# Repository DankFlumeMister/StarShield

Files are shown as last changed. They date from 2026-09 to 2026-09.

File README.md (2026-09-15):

# StarShield



**一个开源、全自定义、面向新手教程的无线机械键盘。**

目标是一把 **95 键紧凑全尺寸**单体键盘：键盘本体经 **BLE** 连接一个 USB Dongle，
Dongle 插在主机上，从而获得接近 2.4GHz 的无线体验。硬件设计、固件与教程全部开放。

> ⚠️ **项目仍在设计阶段，尚无硬件实物。** 本 README 如实标注每一项的完成度，
> 未验证的内容不会写成已完成。

---

## 目标

- **95 键紧凑全尺寸**单体键盘（含独立小键盘与导航键簇）
- **无线优先**：Body（键盘本体）作为 BLE peripheral，Dongle 作为 BLE central
- **USB-C 有线备用**：充电 + 有线模式
- **ZMK Studio** 浏览器实时改键
- **Per-key RGB**：95 颗独立发光，组合键控制开关/亮度/颜色/灯效
- **硬件开源**，新手可复刻
- 控制器模块同时兼容 **nice!nano v2** 与 **SuperMini nRF52840**（低成本路线）

## 系统架构

```text
┌─────────────────────────────┐        ┌──────────────────┐      ┌────────┐
│        键盘 Body             │        │      Dongle      │      │  主机   │
│                             │        │                  │      │        │
│  nice!nano v2 (peripheral)  │──BLE──▶│ XIAO nRF52840    │─USB─▶│  PC    │
│   ├─ 95 键矩阵 6 行 × 18 列   │        │   (central)      │      │        │
│   │    ├─ 6 行直连 MCU       │        └──────────────────┘      └────────┘
│   │    └─ 18 列由 2×74HC595  │
│   ├─ BQ24072 充电 + 电源路径管理 │
│   ├─ 3000mAh LiPo（无断电开关）  │
│   └─ 95 颗 SK6812MINI-E + 门控   │
└─────────────────────────────┘
```

**关键技术选择**（完整理由见 `docs/adr/`）：

| 主题 | 选择 |
| --- | --- |
| 固件 | ZMK（基于 Zephyr RTOS） |
| 无线方案 | BLE Dongle（**非**原生 2.4GHz，见 [ADR-0001](docs/adr/0001-zmk-ble-dongle-over-native-2.4ghz.md)） |
| 矩阵驱动 | **2 颗 74HC595 级联**驱动 18 列（见 [ADR-0008](docs/adr/0008-matrix-via-74hc595-shift-register.md)） |
| 充电 | BQ24072，线性充电 + 电源路径管理，做在主 PCB |
| RGB 供电 | **电池直供**，不加 5V 升压（见 [ADR-0007](docs/adr/0007-rgb-powered-directly-from-battery.md)） |
| 许可 | CERN-OHL-S-2.0 |

---

## 当前状态

| 模块 | 状态 | 说明 |
| --- | --- | --- |
| 产品与硬件设计决策 | ✅ 已完成 | 11 条 ADR + 完整决策日志 |
| 键位几何 | ✅ 已核验 | 95 键、19.50u × 6.25u（371.5 × 119.1 mm） |
| 95 键矩阵分配 | ✅ 已完成 | 6 行 × 18 列，18 列达数学下界 |
| PCB 原理图（矩阵部分） | ✅ 已完成 | **网表校验 10 项全通过、ERC 0 error** |
| PCB 原理图（电源/RGB/控制板） | 🔴 未完成 | 拓扑与元件取值已定，待画图 |
| 固件配置 | 🟡 已写出 | shield 全套 + 95 键映射，**静态校验通过** |
| 固件编译验证 | ✅ **已通过** | GitHub Actions 用 ZMK v0.3.0 实跑 `west build`，产出可烧录的 `.uf2` |
| PCB 布局 / 外壳 / BOM / 教程 | 🔴 未开始 | |

### 已产出的设计文档

| 文档 | 内容 |
| --- | --- |
| [`docs/decisions.md`](docs/decisions.md) | 完整决策日志 |
| [`docs/adr/`](docs/adr/) | 架构决策记录 0001–0011 |
| [`docs/hardware-geometry.md`](docs/hardware-geometry.md) | 键位几何基准（含一次错误测量的教训） |
| [`docs/matrix-assignment.md`](docs/matrix-assignment.md) | 95 键矩阵行列分配 + 网表校验 |
| [`docs/matrix-folding-analysis.md`](docs/matrix-folding-analysis.md) | 为什么必须用移位寄存器（含引脚预算推导） |
| [`docs/zmk-kscan-alternatives.md`](docs/zmk-kscan-alternatives.md) | ZMK 全部 6 个 keyscan 驱动排查 |
| [`docs/power-architecture.md`](docs/power-architecture.md) | 电源树、电流预算、选型 |
| [`docs/bq24072-pinout.md`](docs/bq24072-pinout.md) | 充电 IC 引脚与元件取值 |
| [`docs/controller-and-battery-facts.md`](docs/controller-and-battery-facts.md) | 控制器/电池/JST 已核实事实 |
| [`firmware/README.md`](firmware/README.md) | 固件引脚分配权威表 + 踩坑记录 |

---

## 仓库结构

```text
.
├── docs/                     设计文档、决策记录、生成/校验脚本
│   ├── adr/                  架构决策记录 0001–0011
│   ├── _tools/               可复现的生成与校验脚本
│   └── _generated/           脚本产物
├── firmware/                 ZMK 固件配置
│   ├── build.yaml            构建矩阵
│   └── boards/shields/starshield/
├── hardware/
│   ├── pcb/
│   │   ├── StarShield/       KiCad 工程（95 键矩阵原理图）
│   │   └── TEST1/            练习工程
│   └── case/                 3D 打印外壳（待开始）
├── research/                 调研报告（结论性，逐条带来源）
├── sketch/                   键盘布局图（KLE 格式，几何唯一权威）
└── tutorials/                新手教程（待开始）
```

---

## 自己跑一遍

本项目全部设计产物由脚本生成，且**可复现**（重跑不会产生差异）。

```bash
# 需要：Node.js、Python 3、KiCad（命令行工具 kicad-cli）
node docs/_tools/matrix-assign.mjs      # 矩阵分配
node docs/_tools/gen_transform.mjs      # 键盘映射表 + 物理布局
node docs/_tools/gen_keymap.mjs         # 键位映射
python docs/_tools/gen_matrix_sch.py    # 生成 KiCad 原理图

# 校验
python docs/_tools/verify_netlist.py    # 网表电气校验（10 项）
python docs/_tools/verify_firmware.py   # 固件静态校验
```

> 若 `kicad-cli` 不在 PATH 上，可用环境变量指定：
> `export KICAD_CLI=/path/to/kicad-cli`

KiCad 工程：用 KiCad 打开 `hardware/pcb/StarShield/Starshield.kicad_pro`。

### 构建固件

固件由 CI 自动构建（ZMK 版本钉在 `firmware/west.yml` 的 `v0.3.0`，上游变更新不会悄悄破坏构建）。
**已实测通过**，产物为两个可烧录的 UF2：

| 文件 | 用途 |
| --- | --- |
| `starshield-body.uf2` | 键盘本体固件 |
| `starshield-settings-reset.uf2` | 清空设置（刷完再刷本体固件，用于恢复出厂状态） |

获取方式：进入 [Actions](https://github.com/DankFlumeMister/StarShield/actions/workflows/build.yml)
→ 选最新一次成功的 run → 页面底部 **Artifacts** → 下载 `starshield-firmware`。

> ⚠️ 这些 UF2 **尚未在真实硬件上烧录验证过** —— 能编译不等于能用。
> 等 PCB 打样后会补上实测记录。

自己触发一次构建：Actions 页面 → **Run workflow**（工作流带 `workflow_dispatch`）。

---

## 已知限制（重要，请勿误读完成度）

- **没有任何硬件实物。** 所有结论均基于设计推导、厂商 datasheet 与仿真级校验。
- **固件已能编译出 `.uf2`，但从未烧进真板子跑过。** 编译通过只说明配置自洽，
  不代表按键定义、RGB 时序、电源门控在实物上正确 —— 这些都必须等 PCB 打样后实测。
- **原理图只画了矩阵部分**，电源与 RGB 子图尚未绘制。
- **引脚分配的机械尺寸未用实物核对。** nice!nano 排针的 pitch 与每边引脚数
  来自 ZMK 官方设备树定义与 Pro Micro 标准旁证，**投板前必须用实物卡尺复核**。
- 外壳必须分件打印：键区宽 **371.5 mm**，超过常见 256 mm 打印床。
- 以下三项**已有推荐方案但尚未确认**（详见 [ADR-0009](docs/adr/0009-three-position-mode-switch.md)、[ADR-0010](docs/adr/0010-battery-cutoff-strategy.md)）：
  - **连接模式开关**：三档拨片（2.4G / 蓝牙 / 有线），单刀 `SP3T`。
    方案用 ZMK 上游原生机制（`toggle-mode` + sideband behaviors），**键盘侧零自定义固件**；
    但 Dongle 必须是「BLE HID 主机」形态，**其固件不是 ZMK，是一块独立的开发量**。
  - **不设电池断电开关**：电池始终接通，「关机」= 拨到有线档 + 拔掉 USB 线，
    再由 ZMK 深睡接手；长期存放拔电池插头。
    这是跟随成熟三模产品（Keychron 等）的做法，也回避了「小开关要扛 2.4 A」的难题。
  - **RGB 门控关断拓扑**：电池满电时 3.3 V GPIO 无法保证关断源极在 4.2 V 轨的高边 PMOS，
    需加一级 NMOS 反相（`GPIO_ACTIVE_HIGH`）。⚠️ 该失效的量级未经实测，标记为未核实。

---

## 参与

项目仍在早期。如果你对以下方向感兴趣，欢迎开 issue 讨论：

- 95 键布局的定位板/外壳设计
- 电源子图（BQ24072 充电 + 电源路径）复核
- 实物打样后的固件实测（矩阵扫描、RGB、电源门控、休眠电流）

## 许可证

本项目采用 **CERN-OHL-S-2.0**（强互惠开源硬件许可证），全文见 [LICENSE](LICENSE)。

任何人可商业使用、修改和分发本设计，但**衍生产品必须同样以 CERN-OHL-S-2.0 开源，
并公开完整设计文件**。

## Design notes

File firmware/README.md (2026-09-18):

# StarShield 固件配置（ZMK）

状态：🟡 **设计稿 + 静态校验通过**（⚠️ **尚未实跑 `west build`** —— 本机缺 Zephyr SDK）

目标板：**nice!nano v2**
⚠️ **ZMK board id 随分支不同**（已核实）：
- `v0.3` release 分支 → **`nice_nano_v2`**（本仓库当前采用）
- `main` 分支 → **`nice_nano//zmk`**（main 上**没有** `nice_nano_v2`）

---

## 1. 目录结构

```text
firmware/
├── build.yaml                          构建矩阵
├── README.md                           本文件
└── boards/shields/starshield/
    ├── starshield.zmk.yml              shield 元数据（供 ZMK 识别）
    ├── Kconfig.shield                  SHIELD_STARSHIELD 注册
    ├── Kconfig.defconfig               键盘名等默认项
    ├── starshield.overlay              kscan / 595 / WS2812 / ext-power
    ├── starshield_transform.dtsi       ← 生成：物理布局 + 95 键映射表
    ├── starshield.keymap               ← 生成：Base / FN 两层，各 95 条绑定
    └── starshield.conf                 Kconfig
.github/workflows/build.yml             构建工作流（读取 firmware/build.yaml）
```

重新生成（幂等，重跑后 git 无差异）：

```powershell
cd <仓库根目录>
$env:PYTHONIOENCODING='utf-8'
node docs\_tools\matrix-assign.mjs     # 矩阵分配 -> docs/_generated/matrix.json
node docs\_tools\gen_transform.mjs     # -> starshield_transform.dtsi（物理布局 + 映射表）
node docs\_tools\gen_keymap.mjs        # -> starshield.keymap
python docs\_tools\verify_firmware.py  # 静态校验（本机可跑，替代实机构建）
```

---

## 2. 引脚分配（权威表）

依据：`docs/adr/0008-matrix-via-74hc595-shift-register.md`。
来源：ZMK 官方 `arduino_pro_micro_pins.dtsi` 与 `nice_nano-pinctrl.dtsi`。

| 用途 | Pro Micro 脚 | GPIO | 备注 |
| --- | --- | --- | --- |
| 矩阵行 R0 | D4/A6 | P0.22 | 直连 MCU（官方要求输入直连） |
| 矩阵行 R1 | D5 | P0.24 | |
| 矩阵行 R2 | D6/A7 | P1.00 | |
| 矩阵行 R3 | D7 | P0.11 | |
| 矩阵行 R4 | D9/A9 | P1.06 | |
| 矩阵行 R5 | D8/A8 | P1.04 | |
| 595 MOSI | D16 | P0.10 | `&spi1` |
| 595 SCK | D15 | P1.13 | `&spi1` |
| 595 片选（RCLK） | D19/A1 | P0.02 | `cs-gpios` |
| WS2812 数据 | D1 | P0.06 | `&spi3` MOSI |
| RGB 电源门控 | D10/A10 | P0.09 | `EXT_POWER` → NMOS 反相级 |
| 模式开关档 0（有线） | **D2** | **P0.17** | C1：`kscan_sp3t_toggle` MODE0（ADR-0009） |
| 模式开关档 1（蓝牙） | **D14** | **P1.11** | C1：MODE1 ⚠️ 已把 `&spi1` 的 MISO 覆盖掉（板级默认占 P1.11，595 只写不需要） |
| 模式开关档 2（2.4G） | **D18/A0** | **P1.15** | C1：MODE2 |
| **合计占用** | **14 / 18** | | **余量 4** |

**空闲引脚**：D0 (P0.8)、D3 (P0.20)、D20/A2 (P0.29)、D21/A3 (P0.31)

⚠️ 注意事项：
- **P0.13 是 nice!nano 的 VCC 门控脚**，本设计未占用（改用 P0.09 驱动外部门控电路）
- **P0.15 是蓝灯**，不要占用
- **595 与 WS2812 必须用不同的 SPI 外设**（两者都是 SPI 从设备）
- 原厂 UART 在 P0.08 / P0.06 —— **P0.06 已被 WS2812 占用**，故不启用串口日志
- 🔴 **`&spi1` 的 pinctrl 在本 shield 覆盖掉了 MISO**：nice!nano 板级 `spi1_default` 含
  `SPIM_MISO = P1.11`，而 C1 把 D14(P1.11) 定为模式开关 MODE1 ⇒ 冲突。595 是**只写**器件，
  MISO 不接，故 shield 里显式只保留 SCK + MOSI（`starshield.overlay` 的 `&pinctrl` 覆盖块）。
  换板（非 nice!nano）时需重新核对该覆盖。

---

## 3. 关键配置项与依据

| 项 | 值 | 依据 |
| --- | --- | --- |
| `ngpios` | **24** | 绑定限定只能 8/16/24/32；18 列需 **3 颗**级联（⚠️ 2026-09-18 修订：原「2 颗」电气不成立 —— 2 颗仅 16 输出位，bit16/17 会被推出链尾丢失；原理图见 `control/control.kicad_sch`） |
| `diode-direction` | **`col2row`** | 与 `docs/matrix-assignment.md` 的二极管方向一致 |
| `EXT_POWER` 节点名 | **必须叫 `EXT_POWER`** | 官方文档：否则用户已保存的设置会丢失 |
| `control-gpios` 极性 | **`GPIO_ACTIVE_HIGH`** | 经 NMOS 反相级后逻辑非反相（见 `power-architecture.md` §5.4） |
| `chain-length` | **95** | 95 颗 per-key LED |
| `color-mapping` | **GRB** | SK6812MINI-E 为 GRB 顺序 |
| `CONFIG_ZMK_RGB_UNDERGLOW_BRT_MAX` | **30** | ⚠️ 硬件电流护栏：30% × 95 颗 ≈ 1.0 A（见 `power-architecture.md` §5.2） |

⚠️ **ZMK 已迁移到 physical-layout 模型**（官方 `docs/hardware-integration/physical-layouts.md`）：
旧的 `chosen { zmk,matrix-transform = ... }` 已不再使用，改为
`chosen { zmk,physical-layout = &physical_layout0; }`，
由 `physical_layout0` 聚合 **kscan + matrix transform + 按键物理位置（`keys`）**。
本项目的 `keys` 属性由 KLE 坐标 ×100（centi-keyunit）自动生成，**同时为 ZMK Studio 铺路**。

---

## 4. 已完成 / 未完成

**已完成（静态校验通过，见 `docs/_tools/verify_firmware.py`）**
- ✅ shield 文件齐套（7 个）
- ✅ `.conf` 中每个 `CONFIG_` 符号均对照 ZMK 官方 Kconfig 核实存在
- ✅ Zephyr 侧「必须手写」的驱动开关无遗漏（3b 检查，防 Bug 5 复发）
- ✅ keymap 两层各 95 条绑定，位置号 0..94 连续
- ✅ transform 95 条、矩阵格唯一（无冲突）
- ✅ DTS 括号/注释配平
- ✅ overlay 引用的 phandle 全部有定义
- ✅ 595 与 WS2812 用不同 SPI 外设
- ✅ 未占用 P0.13 / P0.15

**已完成（真机外验证）**
- ✅ **GitHub Actions 实跑 `west build` 成功**（ZMK v0.3.0），产出
  `starshield-body.uf2`（379,392 B / 741 个 UF2 块）与
  `starshield-settings-reset.uf2`（92,672 B / 181 块），
  两块均已校验 UF2 魔数、familyID = `0xADA52840`（nRF52840）、
  写入地址落在 nRF52 应用区 `0x00026000` 起。
  工作流：`.github/workflows/build.yml`

**未完成**
| 编号 | 待办 |
| --- | --- |
| F1 | ✅ ~~实跑一次 `west build`~~ → **已完成，见上** |
| F2 | 🔴 投板前用实物核对 nice!nano 排针的 pitch 与每边脚数 |
| F3 | 🔴 USB Dongle（BLE central）的 shield 配置尚未设计（`build.yaml` 中已注释掉） |
| F4 | 🟡 决定 ZMK config 是否独立成仓库 |
| F5 | 🟡 是否启用 ZMK Studio（physical layout 已就绪，需再加 RPC 配置） |
| F6 | 🔴 **烧进真板子实测**（编译通过 ≠ 能用；按键映射、RGB、电源门控都要实测） |

---

## 5. 踩坑记录（生成脚本）

| # | 现象 | 根因 | 修复 |
| --- | --- | --- | --- |
| 1 | keymap 整张键位错位 | **DTS 里 bindings 的书写顺序就是位置号顺序**；我按「小键盘/主键区」分组输出，打乱了顺序 | 改为严格按位置号 0..94 顺序输出，另加断言校验连续性 |
| 2 | `starshield_transform.dtsi` DTS 语法崩坏 | 键帽标签 `*`（小键盘乘号）与 `/`（除号）在注释里拼成 **`*/`，提前闭合注释**，`8 \| (/9 */` 变成代码 | 生成器加注释消毒函数 `c()`：`*/`→`* /`、`/*`→`/ *` |
| 3 | transform 节点标签未生效 | 用了 `&default_transform { ... }` —— 那是 **fragment 覆写**，对**尚未定义的新标签无效** | 改为节点定义形式 `default_transform: keymap_transform_0 { ... }` |
| 4 | overlay 用了过时的 chosen 属性 | ZMK 已迁移到 **physical-layout** 模型 | 改为 `zmk,physical-layout = &physical_layout0` |
| 5 | Actions 链接期报 `undefined reference to '__device_dts_ord_129'`，指向 rgb_underglow.c | devicetree 完全正确，但 **Zephyr 的 `menuconfig WS2812_STRIP` 没有 `default y`、也不看 compatible**，必须手写 `CONFIG_WS2812_STRIP=y`。不开 → `ws2812_spi.c` 不参与编译 → `drivers__led_strip` 库没有源文件 → 设备结构体从未生成 | `.conf` 加 `CONFIG_WS2812_STRIP=y`；并把这类「Zephyr 侧必须手写」的开关做进 `verify_firmware.py` 的 3b 检查 |

> ⚠️ 第 2 条与之前 KiCad 生成器踩过的「键位标签以反斜杠结尾导致语法非法」是**同一类坑**：
> **把自由文本嵌进代码或注释时必须消毒。** 键盘键帽标签天然含 `*` `/` `\` `"` 等符号，
> 任何生成器都要处理。

> ⚠️ 第 5 条的教训是**别把「编译通过」当成「配置正确」**：
> 缺一个 Kconfig 开关不会在编译期报错，只在链接期以一个 `__device_dts_ord_N` 数字的形式爆出来。
> 对比 ZMK 自己的 595 驱动 —— `Kconfig.595` 写了 `default $(dt_compat_enabled,...)` 所以自动开；
> 而 Zephyr 的 WS2812 驱动不会自动开。**同仓同类的两个驱动，行为可以完全不同，必须逐个查源码。**

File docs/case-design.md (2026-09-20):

# 外壳建模（底壳）— 参数、脚本与运行方式

**日期**：2026-09-21
**工具**：Fusion 360（本机已装，用户级 webdeploy 安装）；脚本语言 = Fusion 内嵌 Python（`adsk.*`）

> **一句话状态**：**底壳 v1 几何跑通、朝向已核对**（2026-09-21 02:31，Fusion 2705.1.15）；
> 随后 §6 的 6 项待定值**改用对标调研定值**（`docs/case-benchmark.md`），参数已改到脚本与预检里（预检全绿）——
> ⚠️ 但 `hardware/case/out/` 里的 STEP/STL **还是旧参数（自攻柱 φ5.0）**，需要**再跑一次**才与本文一致。
> 剩余的是 v2 尚未建几何的件（倾角/脚垫/缝销/过线缺口/上盖）。

### 1.1 运行结果（实测，可复跑）

| 步骤 | 结果 |
| --- | --- |
| ① 外形实体 | 1393.5 cm³ |
| ② 挖内腔 | 192.4 cm³ |
| ③ 三处开孔 + **③b 方向自检** | ✅ 通过（开孔模型 Y 128.3–154.4、x −3.3–37.0；安装孔模型 Y 2.0–91.1） |
| ④ 8 个 M2 柱 + 底孔 | **+1.76 cm³**（自检区间 0.5–5.0 ✅） |
| ⑤ 两处电池压边（环形唇边） | **+12.80 cm³**（自检区间 5–25 ✅） |
| ⑥ 剖成两件 | 104.4 / 102.6 cm³；包围盒 **192.0 / 187.3 × 155.7 × 23.6 mm** |
| ⑦⑧ 导出 | `StarShield-case.step`（105 KB）、`-A.stl`（50 KB）、`-B.stl`（48 KB）、`preview-iso.png`（166 KB）、`preview-top.png`（36 KB） |

产物在 `hardware/case/out/`（**已 gitignore**：STEP 带时间戳、非确定性）。
发布给复刻者时把 STL/STEP 挂 Release 附件。

**朝向核对（02:31 那次，逐点比对通过）**：字符俯视图里 `O`（开孔）在上边与左端、
`H`（安装孔）在下边与左右两端、`b`（电池仓）左右各一、`|`（分件缝）居中；
俯视图断言与 §1.2 的坐标表**完全一致**。

> ⚠️ 02:13 那次运行**朝向是错的**（漏 y 取反、模型整体镜像，见 §1.2）：体积/包围盒/分件长度
> 全都正常但 STEP/STL 不可装配。**以 02:31 这版为准**，旧产物已被覆盖。

### 1.2 坐标系（板 → 模型）—— ⚠️ 少转一处就是整片镜像

| | 方向约定 |
| --- | --- |
| KiCad 板坐标 | x **向右**、y **向下**（所以板 y=0 那条边画在屏幕**上边**） |
| Fusion 模型 | x 向右、**+Y 向上**（本脚本约定 +Y = 键盘**后侧**、远离用户那一边） |

装配关系：PCB 就是上盖、**F.Cu 朝上**；而 **KiCad 的 F.Cu 视图 = 从上往下看装好的键盘**，
KiCad 屏幕「向下」这个方向在模型里就是 −Y ⇒ **板 y 必须取反、x 不动**：

```
X_model = x_board                     （板 x 小的一侧 = 键盘左侧；模块 USB-C 从板 x=0 那面壁伸出）
Y_model = (by0 + by1) − y_board       （by0/by1 = 板框 y 的最小/最大值 = 0 / 151.0625）
```

换算**只有这一处**：脚本里 `YF()` / `YR()` / `rectY()`（模块级）。
凡是用到「板的 y」的几何（板框外扩、安装孔、侧壁开孔、电池仓压边）都必须走它们，禁止直接写裸 y。

**数值自查（板布局事实，不是假设）**

| | 板坐标 | 模型坐标 | 应落在 |
| --- | --- | --- | --- |
| 三处开孔 | y = 0 / 17.8（x = 15 / 33 / 0） | Y = 151.1 / 128.3…138.3；x = −3.3…37.0 | **上边 + 左端** |
| 8 个安装孔 | y = 60 / 110 / 149.06（x = 2 / 124.9 / 249.8 / 372.7） | Y = 91.1 / 41.1 / 2.0 | 下边与左右两端 |

⇒ 判据：`min(开孔 Y) > max(安装孔 Y)` 且 `max(开孔 x) < 板宽/2`。脚本里做成 **③b 方向自检**，不满足直接抛错。

**❌ 首版错在哪**：漏了 y 取反 ⇒ 模型在 Y 上镜像，三处开孔跑到键盘「前下边」、螺丝柱跟着镜像，
与 PCB 布局左右上下全对不上（用户一眼看出「开口应该在左上角」）。

**为什么这类错必须靠数值判据**：镜像后的几何在 DRC、在等轴截图里**都看不出对错**
（图里只是一个浅盘换个角）。所以本项目加了**两道**朝向判据，且都不依赖看图：

1. **脚本内 ③b 自检**（上面两条不等式，几何画完立刻判）；
2. **日志里的「字符俯视图」**（`draw_plan()` 用真实坐标画 ASCII：上 = +Y、左 = −X，
   `H` 安装孔 / `O` 开口 / `b` 电池仓 / `|` 分件缝）—— 不用开图就能核对；
3. 另有**离线预检** `.workbuddy/scratch/check_plan.py`：给 `adsk` 打桩，**不开 Fusion**
   就能跑通换算并打印同一张字符图（改坐标转换前先跑它，省一次 Fusion 往返）。

运行后还会多出一张 **`preview-top.png`**：相机放正上方、up = +Y ⇒ **屏幕右 = +X、屏幕上 = +Y**，
可与 KiCad 的 F.Cu 视图逐点对照（等轴图做不到这点 —— 它没有明确的正方向）。

**✅ 2026-09-21 02:31 复跑：修好并核对通过** —— ③b 方向自检 ✅，日志字符俯视图里
开口在上边 + 左端、安装孔在下边与左右两端，与上表逐点一致；体积自检 +1.76 / +12.80 cm³ 不变
（印证「镜像不改变这些量、只能靠朝向判据发现」）。

**✅ 一个前提假设已由用户确认（2026-09-21）**：上表把「板 x=0 那面壁 = 键盘左侧」当作事实，依据是
`sketch/keyboard-layout.json`（KLE）里键位 x 向右递增、板坐标与 KLE 同向。
**用户明确：「开口就在键盘左侧就行」** ⇒ x 不取反，现方案成立。
（若哪天要「整板在壳内转 180°」，改动仍只有一处：`rectY` 里对 x 做 `bx0 + bx1 − x`。）

---

## 1. 设计输入（全部来自工程，不手抄数字）

| 输入 | 值 | 来源 |
| --- | --- | --- |
| 板框 | **374.7125 × 151.0625 mm**（纯矩形，4 段直线、无圆弧） | 板文件 Edge.Cuts（实测） |
| 板厚 | 1.6 mm | 板文件 |
| 安装孔 | **8 个 NPTH φ2.20**（H1–H8；x=2 / x=372.71 / y=149.06 三边分布，上方无孔） | 板文件（**按位号 H 开头**识别，不能按孔径筛 —— 轴体定位孔 φ1.70/3.05 有 313 个） |
| 定位板 | 374.7125 × 127.0625（y 24..151.06），95 个开孔（**以封装 P1..P95 形式存在**，不在 Edge.Cuts 上） | `Starshield-plate.kicad_pcb` |
| 三处开孔 | 充电口 前壁 x=15（11×4.5）· 模块口 左壁 y=17.8（10×5）· 开关 前壁 x=33（8×4） | `nice-nano-physical-verification.md` §6.7 |
| 电池仓 | 左右各 10.5 × 56 × 68 mm、机壳深 ≥11 mm | `power-architecture.md` §3.6（G5） |
| 分件 | 底壳约等分两件（缝落在键位列边界）；PCB 作为整块上盖跨越接缝 | `hardware-geometry.md` §3.1（G4） |
| 侧壁/柱 | 侧壁 2 mm、M2 自攻柱 φ4–5 | `decision-package-2026-09-18.md` §3 |

提取脚本：`docs/_tools/extract_case_inputs.py` → `hardware/case/case_inputs.json`（可重跑，确定性）。

## 2. 参数（脚本里叫 `P`，改这里即可）

> 2026-09-21：除尺寸链本身外，结构取值改由**对标调研**定（`docs/case-benchmark.md`，含来源等级与诚实边界）。

| 参数 | 取值 | 说明 / 依据 |
| --- | --- | --- |
| `wall` | 2.0 | 侧壁厚（G2 下限；0.4 喷嘴 = 5 条壁线） |
| `floor` | 2.5 | 底板厚 |
| `clearance` | 0.3 | 内腔相对板边单边间隙 |
| `depth` | **15.0** | 板下净空 = 插拔座 **1.8**（Kailh 图纸）+ 压边 2.0 + 电池 10.5 + 余量 0.7 ⇒ benchmark §3.1 |
| `lip` | 4.5 | 侧壁高出 PCB 上表面（低-profile：恰在板面下 0.5；高-profile 则 9.5–11.0） |
| `boss_od` / `boss_pilot` / `boss_pilot_depth` | **6.4 / 3.0 / 5.0** | M2 **热熔螺母**柱（2× 规则；旧「φ5.0 / 底孔 1.7 深 8」为自攻，不适于反复拆装）⇒ benchmark §2.3 |
| `bat_inset` | **8.5** | 电池仓相对内腔边的内缩（避开 φ6.4 柱，留 1.0 mm 净距） |
| `seam_x` | **189.70** | 分件缝 = 第 10 列键边界 `x = 4 + (10−0.25) × 19.05` |

**已定值、v2 才建几何的参数**（脚本里已声明，见 `P`）：倾角 `tilt_deg` = **5.5°**、脚垫 `foot_dia/foot_h` = **Ø8×3**、
缝销 `seam_pin_*` = **Ø4×8 / 单边 0.2**、压边过线缺口 `clip_notch_w` = **3.0**。

⇒ **外形 379.31 × 155.66 mm、总高 23.60 mm**；两件跨度 A 192.0 / B 187.3 mm（打印床 256 ✓）。
（加 5.5° 倾角后后缘 ≈ 38.6 mm，见 benchmark §2.4）

预检：`python docs/_tools/preflight_case.py` —— A 尺寸自洽 / B 板下净空（**含压边**）/ C 柱位 / D 电池仓与压边 /
E 开孔 / F 分件缝 / G **M2 热熔螺母合规（2× 规则 + 柱壁 + 孔深 + 与压边净距）**；另有 ③b 方向自检在建模脚本里。
**当前全绿。**

## 3. 脚本能建出什么（v1 范围）

底壳（两件）+ 内腔 + **三处侧壁开孔**（做成**顶部开口的槽**：打印机友好，且不必赌连接器精确高度）
+ **8 个 M2 自攻柱与底孔** + **左右两个电池仓压边**（每条边两条压臂，压边高出电池 2 mm）。
导出：`StarShield-case.step`（整件）、`StarShield-case-A/B.stl`（分件）、
`preview-iso.png`（等轴截图）、`preview-top.png`（**俯视截图**，屏幕右 = +X、屏幕上 = +Y）。

**v1 刻意不做**（都需要先定案，见 §6）：定位板的承托与压边、上盖/边框、脚垫与倾角、
电池引线走线槽、外壳与 PCB 的防呆。

## 4. 怎么运行（**手动一步**）

Fusion 没有进程外 API —— 脚本必须在 Fusion 进程内跑，因此**只能**通过它的入口触发。

**⚠️ 两个先决条件（2026-09-21 实测踩过）**
1. **「实用程序」标签只在打开了一个设计文档时才出现** —— 停在**主页（Home）**是找不到它的。
   ⇒ 先在主页点「新建... → 零件设计 → 新建」，进入工作区后工具栏最右侧就有「实用程序」。
2. **脚本必须放在 `%APPDATA%\Autodesk\Autodesk Fusion 360\API\Scripts\<名>\`**。
   放到同级的 `MyScripts\` 里，**「脚本和加载项」对话框里看不到它**（首版就放错了）。

**步骤**
1. 打开 Fusion 360，进入任一设计（或按上面第 1 条新建一个零件设计）。
2. 工具栏最右 **实用程序（Utilities）→ 脚本和加载项（Scripts and Add-Ins）**；
   快捷键 **`Shift+S`** 更快（实测有效）。
3. 对话框里：若「搜索」框有残留文字先清掉（点 ×）；在**脚本**列表里找到 **StarShieldCase**
   → 点它那一行的 **▶（运行）**。
4. 完成后看 `hardware/case/out/build.log`（逐步日志 + 每步体积自检）与 `out/` 下的 STEP/STL/预览图。

部署/更新脚本：`python docs/_tools/deploy_fusion_addin.py`（装到 `API\Scripts\` 与 `MyScripts\` 两处；
`--remove` 卸载）。

## 5. ⚠️ 踩过的坑（Fusion 自动化事实，供后续复用）

1. **Fusion 没有进程外 API**，也没有命令行执行脚本的开关 ⇒ 想自动化只能在启动时挂钩子，
   或者模拟输入点击。**不存在** headless/batch 模式。
2. **`runOnStartup: true` 的 add-in 机制是真的**（依据：安装目录里多个内置 add-in 清单都用它，
   路径 `%APPDATA%\Autodesk\Autodesk Fusion 360\API\AddIns\<名>\<名>.manifest`）。
   实测**确实自动跑起来了**（重启后 45 秒写出日志）。
   ❗ **但不要在启动阶段做重活**：Fusion 启动初始化尚未完成时建模，会把 Fusion 跑崩
   （崩溃报告落在 `%LOCALAPPDATA%\Autodesk\CER\`）。
3. **首版脚本自身也不稳**：每个小体都新建「构造平面 + 草图 + 拉伸」，8 柱 + 8 底孔 + 24 个压边
   ⇒ 40+ 特征；且沿用了特征重建后**已失效的 body 代理**（SWIG 代理问题）。
   ⇒ 现版本改为**一次草图装多个轮廓、一个特征干一批**（总特征 ~7）+ **每步重新获取 body**。
4. **别用 `taskkill /F` 强杀 Fusion**：本机两次强杀之后，Fusion 变成**每次启动 4 秒内崩溃**
   （`SafeModeCounter.json` 记到 1，即它已记录一次启动失败）⇒ 需要用户自己启动、按提示进安全模式/清缓存恢复。
5. 本机杂项（都有证据，不是猜）：Fusion 界面截图只能用 **Pillow**（`ImageGrab`）——
   PowerShell 的 `Add-Type` 被安全策略拦；`sleep` / `tee` 等 coreutils 在 Bash 工具里不可用；
   Windows 里的 `timeout.exe` 不是 GNU timeout。
6. 🔴 **拉伸「草图里所有轮廓」会把「环内区」一起填实 —— 环形件必须按 `profileLoops` 选轮廓。**
   而且**轮廓怎么画决定 loop 数**：
   - ✅ 每个环用**两个同心矩形** ⇒ 「环带」是一个**带孔轮廓（2 个 loop）**，
     内框区域是 1 个 loop ⇒ 传 `min_loops=2` 精确取到环带。
   - ❌ 用**4 个互相重叠的矩形**拼环 ⇒ 会被切成若干**单环区域**，连「环内区」也是 1 环
     ⇒ 按 loop 数无法区分，一起拉伸就把电池仓填成实心块
     （实测体积 +108 而非 +13 cm³，`min_loops=2` 时则一个轮廓都选不到）。
7. ⚠️ **Fusion 几个「不能做 / 已废弃但可用」**（省一轮试错，均在 `API/Python/packages/adsk/fusion.py`
   这份**本机 API 存根**里核对过）：`root.name = "..."` 会抛
   `RuntimeError: 3 : root component name cannot be changed`（根组件不能改名，首次运行就崩在这行）；
   `setDistanceExtent` 官方标注已废弃但**明确说明继续兼容**（换新 API 风险更大，保持不动）；
   `participantBodies` 要的是 **`list[BRepBody]`**。**不确定签名就直接读存根，比试错快。**
8. 💡 **每步都要有数值自检。** 上面第 6 条的缺陷 **DRC 查不到、等轴视图里也看不出对错**
   （就是两块方块），是脚本自己的体积增量自检抓到的 ⇒ 生成几何的脚本务必逐步输出可判读的量。
9. 🔴 **KiCad 板坐标 → 模型坐标必须做 y 取反**（`Y_model = (by0+by1) − y_board`），
   这是本项目最容易犯、也最难靠看图发现的错（首版就漏了，见 §1.2）。
   两条纪律：① 换算**只有一处**（`YF/YR/rectY`），不得散落；
   ② 加**朝向自检** + 日志里的**字符俯视图**——等轴截图判不出正方向。

## 6. 原「待定项」—— 2026-09-21 已按对标调研定值

**依据全文**：`docs/case-benchmark.md`（商业键盘规格书 + 社区方案 + 器件原厂图纸；含来源等级与诚实边界）。
下面每项都写「定值 / 依据 / 还剩什么要实测」。

| # | 定值 | 依据（等级） | 仍需实测/拍板 |
| --- | --- | --- | --- |
| H1 座占高 | **1.8 mm**（板下） | Kailh 图纸 `1.80±0.05` **[DOC]**；社区约 2 mm [REPORTED] | 实物复测一次（±0.1–0.2 已在余量内）；⇒ 列 **B6** |
| H2 定位板间距 | 板面 = PCB **+5.0**、板厚 **1.5**、开孔 **14×14** | Cherry MX 图纸 **[DOC]**；社区一致 [REPORTED] | 无（板的高度由轴体锁定，外壳只需让开） |
| H3 上盖/边框 | **不加边框**（低-profile，`lip`=4.5 ⇒ 板面下 0.5）；若要高-profile ⇒ `lip` 9.5–11.0 | 商业高-profile 围边在板面之上 4.5–6.0 [REPORTED] | 你的口味（一行参数） |
| H3b 紧固 | **M2 热熔螺母**（柱 φ6.4 / 孔 3.0×5.0，嵌件 OD3.2×L4） | 2× 规则 + 「反复拆装用螺母」[REPORTED] | 买件后按厂家图纸复核孔径 ⇒ **B6** |
| H4 电池引线 | 压边开 **3.0 宽全高缺口** + 底槽 **2.0 × 1.5** | JST-PH 壳体 4.5 宽、线 φ0.8–1.5 **[DOC]** | v2 建几何 |
| H5 脚垫/倾角 | **5.5°** + **Ø8×3 硅胶自粘脚垫** ×4 | Q1 官方 5.2° **[DOC]**；社区 5–7° [REPORTED] | 你的口味（后缘 ≈38.6 mm） |
| H6 接缝 | **Ø4×8 定位销 ×3，单边 0.2 mm**（沿 y 布置） | 缝 155.7 ≫ 80 mm 判据 [REPORTED] | v2 建几何 |

**另外两个「不顺延、必须处理」的项**（不在外壳里，但调研发现）：见 `docs/case-benchmark.md` §4 ——
① Kailh 官方推荐 PCB 布局的轴孔是 **φ3.00**，我们自画封装仍 1.27 PTH ⇒「直焊/热插拔二选一」在 1.27 孔上不成立；
② 电池座 JST-PH 额定 **2 A**，而 RGB 峰值 2.4 A。

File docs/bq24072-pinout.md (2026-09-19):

# BQ24072 引脚定义与元件取值（已核实）

本文件记录 BQ24072（VQFN-16，封装 RGT）的**确切引脚定义与外部元件取值**，作为电源子图原理图的依据。

**来源等级：高（双重核实）**
- **引脚表**：TI SLUS810N 表 7-1 **与** KiCad 10.0.6 官方符号库 `Battery_Management.kicad_sym`
  中的 `BQ24072RGT` 符号，两处独立一致。
- **元件取值与公式**：**TI SLUS810N 正文**（53 页）全文。
- 逐条来源 URL 见 `research/bq24072-power-path-verified-facts.md`。

状态：✅ **参数已全部核实，电源子图不再被阻塞**（原第 3 节的「硬阻塞」已解除）

> 💡 **取数方法（供后续核对者复用）**：TI 的 PDF 数据手册无法用普通网页抓取工具读取
> （`raw.githubusercontent.com` 与多家镜像站返回 403）。可行路径：
> **用 Node 的 `fetch()` 直接下载厂商 PDF，再用 `pdf-parse` 本地抽取文本**。
> 需要 datasheet 里的数据时不要凭记忆填数——走这条路拿到原文。

---

## 1. 引脚表（VQFN-16 + 散热焊盘）

| Pin | 名称 | 电气类型 | 符号库中的说明 | 本项目用途 |
| --- | --- | --- | --- | --- |
| **1** | `TS` | passive | 温度监测输入 | ⚠️ 见第 3 节（硬阻塞） |
| **2** | `BAT` | power_out | 电池连接 | 接电池（经 SPDT 开关与 JST 座） |
| **3** | `BAT` | passive | 电池连接（同电位） | 同 pin 2（双焊盘设计） |
| **4** | `~{CE}` | input | **芯片使能，低有效** | ⚠️ 接 VSS 以常开（见 §2.1） |
| **5** | `EN2` | input | 模式选择 | ⚠️ 见 §2.1 |
| **6** | `EN1` | input | 模式选择 | ⚠️ 见 §2.1 |
| **7** | `~{PGOOD}` | open_collector | 电源正常指示，**开漏** | 可悬空，或接 LED/上拉 |
| **8** | `VSS` | power_in | 地 | 接 GND |
| **9** | `~{CHG}` | open_collector | 充电状态指示，**开漏** | 接充电 LED + 限流电阻到 VIN |
| **10** | `OUT` | power_out | **系统输出** | ⭐ **接系统负载（主控、RGB 门控）** |
| **11** | `OUT` | passive | 系统输出（同电位） | 同 pin 10 |
| **12** | `ILIM` | passive | 输入电流限制设定 | 接电阻到 GND |
| **13** | `IN` | power_in | 输入电源 | 接 USB-C VBUS |
| **14** | `TMR` | input | 安全定时器设定 | 接电阻到 GND |
| **15** | `TD` | input | 温度检测使能/模式 | ⚠️ 与 TS 配合，见 §3 |
| **16** | `ISET` | passive | 快速充电电流设定 | 接电阻到 GND |
| **17** | `VSS` | passive | **散热焊盘（EP）**，同电位 | ⭐ **必须焊到接地铜皮**（见 §2.2） |

封装（符号库指定）：`Package_DFN_QFN:VQFN-16-1EP_3x3mm_P0.5mm_EP1.6x1.6mm`
→ 本体 3×3 mm、引脚间距 0.5 mm、**散热焊盘 1.6×1.6 mm**。

---

## 2. 需要特别小心的三点

### 2.1 ⚠️ 引脚 4/5/6 的含义与同族其它型号不同

BQ24072 属于 BQ24072/73/74/75 同一族。**同一引脚号在不同型号上功能不同**，这是最容易接错的地方：

- 本符号的 **pin 4 = `~{CE}`（低有效芯片使能）**，并有 pin 5 `EN2`、pin 6 `EN1` 两个模式选择脚。
- 而族内某些型号（如 BQ24074）**没有 `~{CE}`**，其 pin 4 等位置的功能不同，且另有 `SYSOFF` 等引脚。
- **BQ24072 的符号中不存在 `SYSOFF` 引脚。**

→ 必须按 `BQ24072RGT` 这一具体型号接线，不可参考 BQ24073/74 的典型电路。

**待核实的具体接法**（属第 3 节阻塞项）：
`~{CE}`、`EN1`、`EN2` 三脚的**正确电平组合**（尤其是「常开工作」与「仅充电/系统关断」两种状态如何设置），
以及 `EN1/EN2` 是否用于设定输入电流限制档位。**未取得 datasheet 前不得臆断。**

### 2.2 ⚠️ 散热焊盘（pin 17 / EP）必须焊接

BQ24072 是线性充电器，**1.5 A 时耗散约 (5 − 3.7) × 1.5 ≈ 2 W**（见 facts 2.3）。
这个热量几乎全靠 **1.6×1.6 mm 的散热焊盘**导出。

→ **PCB 布局时 EP 必须焊接到接地铜皮，并配足够的热过孔阵列。**
不允许「不焊 EP」或「EP 只靠阻焊下的铜皮」的做法。
→ 本项目实际充电电流建议降到 0.5–1.0 A 也正是为了减少发热（facts 2.3）。

### 2.3 负载必须接 `OUT`，不能接 `BAT`

> ⚠️ **2026-09-19 修订（方案①）**：本规则对**重载**（`VLED` 灯轨等）仍然成立；
> **唯一例外 = nice!nano 模块的 `B+/RAW` 改接 `VBAT`**（模块自带充电器要能给电池充电，
> 见 `power-architecture.md` §1 与 `nice-nano-physical-verification.md` §6.6）。
> 模块电流很小（20 µA 级休眠），不影响本节的结论。

这是 ADR-0002 电源路径管理的核心，重复强调：
- `BAT`（pin 2/3）**只接电池**；
- `OUT`（pin 10/11）**接系统负载**，由 IN 或 BAT 中较高者供电。

详细理由见 `docs/power-architecture.md` 第 1 节。

---

## 3. ✅ 元件取值（已从 TI SLUS810N 本体核实，硬阻塞已解除）

**来源**：TI `bq24072.pdf`（SLUS810N，53 页）正文，由该 PDF 本地抽取文本获得，
非网页二手转述。逐条来源见 `research/bq24072-power-path-verified-facts.md`。

### 3.1 典型应用电路取值（SLUS810N 图 10-1 + 引脚表）

| 位号 | 值 | 说明 |
| --- | --- | --- |
| `C_IN` | **1 µF**（允许 1–10 µF） | ⚠️ **硬上限 < 10 µF**（USB-IF 浪涌要求） |
| `C_OUT` | **4.7 µF**（4.7–47 µF） | |
| `C_BAT` | **4.7 µF**（4.7–47 µF） | |
| `R_ISET` | **1.13 kΩ 1%**（示例值） | 公式见 3.2 |
| `R_ILIM` | **1.18 kΩ**（示例） | 公式见 3.3 |
| `R_TMR` | **46.4 kΩ** | 对应约 6.25 h 安全定时 |
| `TS` | **10 kΩ NTC**（103AT-2）或 **10 kΩ 固定电阻** | 见 3.4 |
| `~{CHG}` 指示 | **1.5 kΩ + LED 接 OUT**，或 1 k–100 kΩ 上拉 | 开漏输出 |
| `~{PGOOD}` | 可悬空，或 1 k–100 kΩ 上拉 | 开漏输出 |
| 电感 | **无** | 线性充电器，无电感 |

⚠️ **`EN1` / `EN2` / `~{CE}` / `TD` 绝不可悬空**（内部约 285 kΩ 下拉，但设计上必须明确给定电平）。

### 3.2 `ISET` → 充电电流

```text
ICHG = K_ISET / R_ISET        K_ISET = 890 AΩ (典型, 范围 797–975)
R_ISET 允许范围: 590 Ω – 8.9 kΩ, 精度 1%
```

| 目标充电电流 | `R_ISET` |
| --- | --- |
| 0.5 A | **1.78 kΩ** |
| 1.0 A | **887 Ω**（E96）或 910 Ω |
| 1.5 A | **590 Ω** ← 这**正是 datasheet 允许的最小值**，实际得 1.508 A |

- 预充电流 `IPRECHG = K_PRECHG / R_ISET`，`K_PRECHG = 88 AΩ`（约为 `ICHG` 的 10%）。
  **不可编程** —— 这正是本芯片**没有 `PRETERM` 引脚**的原因。
- ⚠️ **`ISET` 悬空 = 关闭充电。**

### 3.3 `ILIM` → 输入电流限制

```text
I_IN-MAX = K_ILIM / R_ILIM
K_ILIM = 1610 AΩ (典型, 1500–1720)   适用于 0.5–1.5 A 档
       = 1525 AΩ (典型)              适用于 0.2–0.5 A 档
R_ILIM 允许范围: 1100 Ω – 8 kΩ
```

**`EN1` / `EN2` 模式表**（这两个脚设定输入电流限制档位）：

| EN2 | EN1 | 模式 | 说明 |
| --- | --- | --- | --- |
| 0 | 0 | **USB100** | 限制 100 mA |
| 0 | 1 | **USB500** | 限制 500 mA（USB 标准档） |
| 1 | 0 | **ILIM 电阻** | 由 `R_ILIM` 决定 |
| 1 | 1 | standby | 待机 |

⚠️ **重要**：datasheet 引脚表明确写着「**`ILIM` 悬空会关闭所有充电**」，
且启动时有 `ILIM`/`ISET` 短路检测 → **即使选 USB500 档也必须装一颗 `R_ILIM`**
（示例：1.6 kΩ ≈ 1 A，在 USB500 模式下同样可以留着）。

### 3.4 `TS` 温度监测 —— 两种接法都确定了

```text
TS 内部偏置电流 INTC = 75 µA (典型, 72–78)
阈值是【绝对电压】，不是 VIN 的百分比：
  V_HOT  = 300 mV (典型, 270–330, VTS 下降沿, 迟滞 30 mV)
  V_COLD = 2100 mV (典型, 2000–2200, VTS 上升沿, 迟滞 300 mV)
浮空视为「不使用温度监测」：V_DIS(TS) = VIN − 200 mV
```

| 方案 | 接法 | 代价 |
| --- | --- | --- |
| **A. 禁用温度监测（最简）** | **`TS` 到 `VSS` 接一颗 10 kΩ 电阻**（**不是分压器**） | 75 µA × 10 kΩ = 0.75 V，正好落在窗口内。datasheet 在三处明确写出此法 |
| **B. 正常温度监测** | `TS` 接 **10 kΩ NTC**（103AT-2）贴电池表面 | 更安全，但电池需带 NTC（Adafruit 大容量电池**不带**） |

- 可用 R_S / R_P 配分压**放宽**（只能放宽、不能收紧）温度窗口（SLUS810N 公式 8/9 与表 9-3 预设值）。
- ✅ **结论：`TS` 不是硬阻塞了，两条路都有明确接法。**
  第一版建议 **方案 A**（最简、对新手友好），但需在文档中说明「已放弃温度保护」这一取舍。
- ⚠️ **2026-09 补充：不要走「板上焊一颗 0603 NTC」这条看似折中的路** ——
  它测的是**板温**（= 环境温度 + 充电器自热，BQ24072 在 0.5 A 时就给板子加约 +29 °C），
  极易越过 50 °C 的「热」阈值造成**间歇性停充**。完整论证与四个方案对比见
  `docs/power-architecture.md` **§3.3**。

### 3.5 `TMR` 安全定时器

```text
t_PRECHG = K_TMR × R_TMR
t_MAXCHG = 10 × K_TMR × R_TMR        K_TMR = 48 s/kΩ (范围 36–60)
R_TMR 允许范围: 18 kΩ – 72 kΩ
```

| 接法 | 效果 |
| --- | --- |
| **`TMR` 悬空** | 用内部默认值：预充 **1800 s（30 min）**、快充 **18000 s（5 h）** |
| **`TMR` 接 `VSS`** | **禁用所有安全定时器** —— ✅ **本设计采用**（2026-09-17） |
| 46.4 kΩ | 约 6.25 h |
| 72 kΩ（**编程上限**） | **7.2 h(min) / 9.6 h(typ) / 12 h(max)** —— 设计应取最坏情况 **7.2 h** |
| **本设计建议** | 🔴 **`TMR` 直接接 `VSS`，禁用所有安全定时器。** 理由：容量 10000 mAh、ICHG **1.0 A**（2026-09-18 定稿）充满仍需约 **10 h**，而定时器**编程上限仅 7.2–12 h（typ 9.6 h）** ⇒ 恰好压在边缘、要赌芯片的个体差异；旧 0.5 A 档下更需 20.6 h，任何 `R_TMR` 都不够。论证见 `docs/power-architecture.md` **§3.5 / §3.7** |

- 定时器在 DPPM / 热调节期间会按比例变慢；超时后 `~{CHG}` 以约 2 Hz 闪烁。
- 上电时 CHG 引脚会闪一下，属正常（battery detection）。

### 3.6 终止电流：`BQ24072` 不可调

- **`BQ24072` 没有 `ITERM` 引脚**，终止电流内部固定为 **0.1 × ICHG（典型 0.09–0.11）**；
  USB100 模式下为 0.033 × ICHG。
- **要禁用终止**：把 **`TD`（pin 15）拉高**（仅启动时检测一次）→ 永远停在 CV 阶段，
  但同时**没有电池检测、安全定时器与温度监测也会被禁用**。⚠️ 不建议。
- 若将来需要可调终止电流 → 那是 **`BQ24074`**（`ITERM = 0.03 × R_ITERM / R_ISET`，`R_ITERM` 0–15 kΩ）。
  ⚠️ **注意 pin 15 在族内是三个不同功能**：`TD`（'72/'73）/ `ITERM`（'74）/ `SYSOFF`（'75/'79）。

### 3.7 电源路径与 DPPM（已确认）

- ✅ **`OUT` 给系统供电，`BAT` 同时充电** —— ADR-0002 的电源路径管理成立。
- DPPM：`V_DPPM = V_O(REG) − 100 mV`，低于此值开始**降低充电电流**；再低则进入**电池补充模式**。
- ⚠️ **`OUT` 稳压到 `VBAT + 225 mV`**，**不是固定 4.4 V**。设计 `OUT` 下游电路时须注意。
- ⚠️ **DPPM / 电池补充 / VIN-DPM / 热调节期间，终止功能被禁用。**
- ❌ **`BQ24072` 没有 `SYSOFF`，无法把电池从系统断开**（那是 `BQ24075/79`）。
  ⇒ **物理断电只能靠外部开关**，这提高了对开关额定电流的要求（见 `docs/power-architecture.md` §5）。

### 3.8 散热

- datasheet 称其为「thermally enhanced MLP package」；**SLUS810N 全文没有出现 "PowerPAD" 一词**。
- 散热焊盘**必须焊接**（原文：must be soldered to the printed circuit board for thermal and mechanical
  performance），且接到 `VSS` 电位，但**不应作为主要接地路径**。
- `RθJA = 44.5 °C/W`；`TJ(REG) = 125 °C`、`TJ(OFF) = 155 °C`。
- ⚠️ **1.5 A 时结温寿命降到 20,000 h @125 °C，且热环路会限流** ——
  散热设计不到位就**达不到编程的充电电流**。
  估算：5 V 输入 / 3.7 V 电池 / 1.5 A → 耗散 1.95 W → 温升约 +87 °C → 必然限流。
  **⇒ 印证 `docs/controller-and-battery-facts.md` 2.3 的建议：编程 0.5–1.0 A，不要跑满 1.5 A。**

### 3.9 仍存疑（明确标注 UNVERIFIED）

- datasheet 自身不一致：引脚图标注 `RGT0016B`，表 6-1 标注 `RGT0016C`。
- 图 10-1 的位号对应关系。
- `ILIM` 悬空行为的表述存在歧义（引脚表说会关闭充电）。
- HRO 原厂图纸不可读（403 / 纯图片 PDF）。
- `KH-TYPE-C-16P` 无官方 KiCad 封装。

---

## 4. 已可直接使用的部分

以下内容**已足够确定**，可以在原理图中定稿：

- 上述 17 个引脚的**编号与名称**
- 封装：`Package_DFN_QFN:VQFN-16-1EP_3x3mm_P0.5mm_EP1.6x1.6mm`
- `IN` 接 USB-C VBUS；`VSS` + EP 接地
- `BAT` 接电池（经开关）；**`OUT` 接系统负载**
- `~{CHG}`（开漏）→ 充电指示 LED + 限流电阻到 VIN
- `~{PGOOD}`（开漏）→ 可留测试点或悬空
- 充电电流目标区间 0.5–1.0 A（决定 ISET 后在原理图填具体值）

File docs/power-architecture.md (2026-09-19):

# 电源架构设计

本文件记录 StarShield 的**电源树与充电/供电拓扑**，作为电源子图原理图的依据。

状态：✅ **原理图已生成并通过校验**（2026-09）
- 产物：`hardware/pcb/StarShield/power/power.kicad_sch`（由 `docs/_tools/gen_power_sch.py` 生成，
  电路数据在 `docs/_tools/power_design.py`）
- 校验：`python docs/_tools/verify_power.py` ⇒ 网表逐节点断言全过、**ERC 0 error / 2 warning**
  （2 条 warning 均为跨子图全局标签 `VLED` / `RGB_PWR_EN` 只出现一次，B2 控制板子图落地后自动消失）
- 定稿取值与理由见 §3.1
- 🔋 **电池容量 = 2×5000 mAh 并联（10000 mAh，1S2P）**（用户 2026-09-17 决定）。
  由此 `TMR` 改为接 VSS **禁用安全定时器**、`R_TMR` 移除
- ⚡ **2026-09-18：充电档位切到 ILIM 档**（输入 ≈1.0 A / 充电 ≈1.0 A）—— 用户决策 P13。
  `EN2=OUT`、`EN1=GND`、`R_ILIM` **1.6 kΩ**、`R_ISET` **887 Ω**、
  **`F1` = 2 A hold 自恢复保险丝（1812，`MF-MSMF200`）**（P15 定案，见 §6）。
  **这是本项目唯一主动超出 USB-C 声明之处**，依据是商用同容量产品的实测充电区间，见 **§3.7**
  论证见 §3.5，采购要求见 §3.6

> ⚠️ **本文件不写未核实的引脚号与参数值。** BQ24072 的引脚分配与 TS/ISET/ILIM/TMR
> 取值均已核实（来源 TI SLUS810N 正文，见 `docs/bq24072-pinout.md` §3）。
> 其余一手事实见 `docs/controller-and-battery-facts.md` §2。

---

## 1. 关键设计决定：利用 BQ24072 的电源路径管理（Power Path）

ADR-0002 选择 BQ24072 而非 TP4056，核心理由就是**电源路径管理**。ADR 里写的是
「插 USB 时不消耗电池」——但这条特性还带来一个**未被记录的重要设计后果**：

> **负载（主控、RGB）必须接 `OUT`，不能接 `BAT`。**
>
> ⚠️ **2026-09-19 修订（方案①）**：这条规则对**重载**（VLED 灯轨、BQ24072 的其它负载）仍然成立，
> 但有**一处刻意例外**：**nice!nano 模块的 `B+/RAW` 改接 `VBAT`（电池节点）**。
> 理由：模块自带充电器（BQ24072 同族的 BQ24075，带电源路径）的输出就在 `B+/RAW` 上；
> 只有把这两孔接在电池侧，**插模块那个 USB-C（有线模式/刷固件）时才能同时给电池充电**
> （社区与官方标准接法）。模块自身电流很小（休眠 20 µA 级、工作几十 mA 级），
> 接在电池侧不影响电源路径对重载的意义。代价与边缘情况见
> `docs/nice-nano-physical-verification.md` §6.6。
> 电池只与 BQ24072 的 `BAT` 引脚相连。

原因：BQ24072 的内部结构是 `IN → OUT`（系统供电）与 `BAT`（充电）两条支路。
- 电池接 `BAT`，只负责充放电；
- 系统负载接 `OUT`，由 **IN 或 BAT 中电压较高者**供电，并受 DPPM（动态电源路径管理）调节。

如果错误地把负载也挂在 `BAT` 上，就等于绕过了电源路径管理，退化成 TP4056 那种
「边充边放」的行为——这正是 ADR-0002 要避免的。

### 1.1 由此得到的两个收益

| 收益 | 说明 |
| --- | --- |
| 插 USB 时由 USB 供电 | `OUT` 直接由 `IN` 供电，电池不放电（对应验收标准「插 USB 时由 USB 供电」） |
| 充电电流不被负载抢占 | 负载电流走 `OUT`，不占用 `BAT` 的充电电流，充电时间可预测 |

---

## 2. 电源树

```text
USB-C 母座 (J1)
  ├─ VBUS ──────────────► BQ24072 IN ──┬──► OUT ──► +3V3 稳压（控制器模块内部）
  │                                    │              └─► 主控 / RGB 门控 PMOS
  ├─ CC1 ──[5.1k]──┐                   │
  ├─ CC2 ──[5.1k]──┴──► GND            └──► BAT ──► J2 ──► 电池(含保护板)
  ├─ D+ / D- ──► （第一版仅充电，可不接；见 §4）
  └─ GND ──► GND

电池 (10000mAh = 2×5000mAh 并联，1S2P 一体化包，共用一块 PCM)
  └─ JST-PH 2.0 (J2) ──► BQ24072 BAT
                          ✅ 已决定：不设断电开关（ADR-0010）
```

### 2.1 ⚠️ 本节已作废：原计划在 BAT 与 J2 之间串一个断电开关

**决定：不设电池断电开关**（用户，走成熟路线；见 **ADR-0010**）。
下面保留原推导作为记录 —— 它解释了为什么「随便挑个小开关串进去」不可行。

- 电池自带保护板，其输出**始终带电**；若放开关，需放在保护板之后、充电器之前，
  才能真正切断整机电流（充电器与负载都在开关的另一侧）。
- ⚠️ **`BQ24072` 没有 `SYSOFF` 引脚，无法用芯片把电池从系统断开**（那是 `BQ24075/79`）。
  ⇒ **物理断电只能靠这颗外部开关，没有软件退路。**
- ⚠️ 因此**开关必须真的扛得住电流**。经核实，常见的微型贴片滑动开关
  （`MSK12C02` 仅 50 mA、`OS102011MS2QN1` 仅 0.1 A）**全部不达标**。
  详见 §5.3，这是一个尚未决策的阻塞项。

### 2.2 目标：单层板可走通

电源区域的布置目标是**不依赖过孔**（单层即可布线）：
- USB-C 与 BQ24072 相邻放置；
- 电池座与开关放在板边，靠近 BQ24072 的 `BAT` 引脚一侧；
- `OUT` 到控制器模块的走线尽量短且粗；
- ✅ **不装任何断电开关**（ADR-0010）⇒ 电源区域只需 USB-C、BQ24072、电池座三块，
  原先为 C&K `1101M2S3CQE2`（12.70×6.60×6.35 mm）预留的空间**不需要了**。

---

## 3. 元件清单（已核实取值，可直接用于原理图）

来源：`docs/bq24072-pinout.md` §3（TI SLUS810N 正文）、`research/usbc-receptacle-verified-facts.md`、
`research/pmos-ext-power-facts.md`。

| 位号 | 元件 / 值 | 作用 | 状态 |
| --- | --- | --- | --- |
| J1 | USB-C 母座 16P（`TYPE-C-31-M-12`，LCSC C165948） | 充电 + 数据 | ✅ 已定；**SMD 卧式正贴（非 mid-mount）**；KiCad 符号 `Connector:USB_C_Receptacle_USB2.0_16P`、封装 `Connector_USB:USB_C_Receptacle_HRO_TYPE-C-31-M-12` |
| R1, R2 | **5.1 kΩ**（CC1=A5、CC2=B5 各一颗到 GND） | 声明为 UFP 设备 | ✅ 已定；⚠️ **绝不可把 CC1 与 CC2 短接** |
| U1 | **BQ24072**（VQFN-16 RGT） | 线性充电 + 电源路径管理 | ✅ ADR-0002；引脚见 `docs/bq24072-pinout.md` |
| C_IN | **1 µF** | VBUS 去耦 | ✅ ⚠️ **硬上限 < 10 µF**（USB-IF 浪涌要求） |
| C_OUT | **4.7 µF** | `OUT` 稳定 | ✅ |
| C_BAT | **4.7 µF** | `BAT` 稳定 | ✅ |
| R_ILIM | **1.6 kΩ（⇒ 输入限流 ≈1.0 A）** | 输入限流 | 📌 **2026-09-18 由 1.5 kΩ 改为 1.6 kΩ**（进入 ILIM 档后它真正参与限流）。⚠️ 即使不用 ILIM 档也必须装（悬空会关闭充电，且数据手册措辞有冲突）；数据手册 §10.2 示例的 `1.18 kΩ` 是 1.3 A 场景 |
| R_ISET | **887 Ω（⇒ ICHG ≈ 1.0 A）** | 充电电流 | 📌 **2026-09-18 由 1.78 kΩ 改为 887 Ω**（P13 决策，论证见 §3.7）。范围 590 Ω–8.9 kΩ；`K_ISET = 890 AΩ` |
| R_TMR | **不装**：`TMR` 直接接 VSS | 安全定时器 | 🔴 **禁用**。定时器上限仅 **7.2–12 h**（typ 9.6 h），而 1.0 A 充满 10000 mAh 仍需约 **10 h** ⇒ 落在 9.6–12 h 之间、要赌芯片个体差异 ⇒ 干脆完全禁用。见 §3.1 与 §3.7 |
| 终止电流 | **不可编程**（无 `ITERM` 脚，内部固定 0.1×ICHG） | 充满判据 | ✅ 无需外围元件 |
| TS 网络 | **10 kΩ 到 VSS**（禁用温测）；或 10 kΩ NTC（103AT-2） | 温度监测 | ✅ 已解除阻塞；第一版建议**禁用**（见 `bq24072-pinout.md` §3.4） |
| `EN1`/`EN2` | 📌 **EN2=OUT, EN1=GND → ILIM 档**（输入限流由 R_ILIM 定，≈1.0 A） | 输入限流档 | **2026-09-18 切换**（P13）。⚠️ **超出 5.1 kΩ CC 声明 2 倍** —— 有意取舍，见 §3.7 |
| `~{CE}` | 接 VSS（常开） | 芯片使能（低有效） | 🟡 待与「仅充电」需求一起确认 |
| LED_CHG + R | **1.5 kΩ + LED 接 `OUT`** | 充电指示 | ✅ 开漏输出 |
| SW1 | 🟡 **待决策**，见 §5.3 | 物理断电 | ⚠️ **候选料号全部不达标**，见下 |
| J2 | JST-PH 2.0 针座 **`B2B-PH-K-S(LF)(SN)`** | 电池接口 | ✅ 见 facts 2.5；⚠️ 电池须为 **1S2P 单 PCM 包**（过流阈值 >2 A），见 §3.6 |
| Q1 | **AO3401A**（SOT-23） | RGB 供电门控 PMOS | 🟡 料号已定，但**关断电路需改**，见 §5.4 |

### 3.1 ✅ 定稿（2026-09，已落进原理图）

下表是**实际画进 `power/power.kicad_sch`** 的取值。凡与 §3 不同的地方都给了理由。

| 位号 | 定稿值 | 理由 |
| --- | --- | --- |
| U1 | `BQ24072RGT` | ADR-0002 |
| `R_ISET` = R4 | **887 Ω ⇒ ICHG ≈ 1.0 A（= 0.10C @10000mAh）** | 📌 **2026-09-18 由 1.78 kΩ（0.5 A）改为 887 Ω**（P13 决策）。理由：商用同容量（≥5000 mAh）键盘的充电区间是 **0.035–0.163C**，0.5 A 只有 0.049C（下三分之一）；**1.0 A = 0.10C 落在区间中部**，与 EPOMAKER TH87 一致。耗散 (5−3.7)×1.0 = **1.3 W** ⇒ `Tj` ≈ 83 °C < 125 °C 门限 ✅。**这是本项目唯一主动超出 USB 声明之处**，论证见 §3.7 |
| `R_ILIM` = R3 | **1.6 kΩ ⇒ 输入限流 = 1610 / 1600 ≈ 1.0 A** | 📌 **2026-09-18 由 1.5 kΩ 改为 1.6 kΩ**：现在 `EN2=1/EN1=0` **进入 ILIM 档，此电阻真正参与限流**。⚠️ 即使不用 ILIM 档也必须装 —— 数据手册明写「ILIM 悬空会关闭所有充电」，且启动时要过 ILIM 短路检测 |
| `EN2` / `EN1` | 📌 **EN2 = OUT、EN1 = GND** ⇒ **ILIM 档**（输入限流由 `R_ILIM` 定，当前 ≈1.0 A） | **2026-09-18 由 USB500 档切过来**（P13）。⚠️ **这是本项目唯一主动超出 USB-C 声明之处**：5.1 kΩ CC 下拉只声明 500 mA，取 1.0 A 超 2 倍 —— 但**商用同容量产品普遍如此**（AULA 1.3 A / Kzzi 1.4 A / EPOMAKER ≤1 A），代价是手册必须写「勿用快充充电器」。⚠️ EN2 接 `OUT` 而**不是** `VBUS`：EN2/EN1 绝对最大额定只有 **7 V**，而 `IN` 可耐 26 V ⇒ 接 VBUS 遇到超压适配器会被打坏。接 `OUT`（恒 3.0–4.5 V）时 `VIH(min) = 1.4 V` 始终满足 |
| `~{CE}`（pin 4） | **接 VSS（常开）** | SLUS810N 表 7-1 原文：CE 低 = 使能充电，CE 高 = 禁充；内部 285 kΩ 下拉，但**不可悬空**。**P9 由此关闭** |
| `TD`（pin 15） | **接 VSS** | 数据手册：TD 接 VSS = 使能充电终止；TD 拉高 = 关闭终止（同时会关掉电池检测／安全定时器／温测）。内部 285 kΩ 下拉，不可悬空 |
| `TMR`（pin 14） | 🔴 **直接接 VSS ⇒ 禁用所有安全定时器**（不装 `R_TMR`） | 定时器**最长**只能编到 `10 × R_TMR(72 kΩ 上限) × K_TMR` = **7.2 h(min) / 9.6 h(typ) / 12 h(max)**（`K_TMR` = 36/48/60 s/kΩ）。📌 **2026-09-18 充电电流升到 1.0 A 后**充满仍需约 **10 h** —— **仍落在 9.6–12 h 之间**（typ 口径会掐断、只有 max 口径才勉强够）⇒ **继续禁用**，不去赌芯片的个体差异。（若维持旧 0.5 A 则需 20.6 h，更不可能用单个定时器覆盖。）数据手册明确支持：*"Connect TMR to VSS to disable all safety timers."*<br>⚠️ 这**不是**「拆掉保护」：定时器是 TI 的额外特性，消费级充电 IC 普遍没有它 —— **已有拆解实证**（商用键盘用 `TP4056`、ZMK 官方推荐板 nRFMicro 用 `MCP73832`，两者均无定时器）。真正的保命线是**电芯自带保护板 + 4.2 V 恒压 + 终止电流检测**，三者本项目都有。<br>📌 本条**推翻了 2026-09 上旬「必须装 47 kΩ」的结论**。详见 §3.5 / §3.7 |
| `F1` | ✅ **2 A hold 自恢复保险丝（PTC，1812，`MF-MSMF200`），装在 VBUS 侧**：`VBUS` → `F1` → `VCHG_IN` → `U1.IN` | 位置照抄 **nightliner**（⚠️ **不能照抄 Conejo** —— 它那颗串在**电池路径**上，而 RGB 全部放电电流走那条路 ⇒ 必然误断）。📌 **取值变更史**：500 mA（配 USB500 档）→ 1.5 A（输入切 1.0 A 后 500 mA 必然熔断）→ **2 A（hold）**。⚠️ **1.5 A 档不可用**：Bourns MF-MSMF 系列降额表显示 `MF-MSMF150/24X` 在 **60 °C 环境下降额后 Ihold 仅 1.00 A**，恰好等于工作电流 ⇒ 零余量；70 °C 时 0.88 A ⇒ **会误断**。密闭 3D 打印壳 + BQ24072 1.3 W 自热 ⇒ 板内 50–60 °C 完全可能。`MF-MSMF200` 在 60 °C 降额后仍 **1.50 A**（余量 50%）、85 °C 时 1.25 A（余量 25%）。压降：Rmin 20 mΩ × 1.0 A = 20 mV，即便 R1max 80 mΩ 也仅 80 mV ⇒ 输入仍剩 ≥4.92 V >> VIN-DPM 上限 4.63 V ✅。<br>⚠️ **类型选 PTC 而非一次性熔断丝**：新手不会换件，故障后冷却自愈；它只挡输入硬故障，**限流由 BQ24072 的 ILIM 档负责**。⚠️ 封装 0603 → **1812**（KiCad `Fuse:Fuse_1812_4532Metric` 已核实存在）；体积更大但更好手焊，不违背「被动件统一 0603」的本意（那条针对 R/C）。<br>🟡 LCSC 料号待 BOM 阶段补；若要求 ≥16 V 额定电压则改用 2 A/16 V 的 1812 PTC（需另行确认料号） |
| `U1` 封装 | `Package_DFN_QFN:VQFN-16-1EP_3x3mm_P0.5mm_EP1.6x1.6mm_**ThermalVias**` | 用带热过孔的变体（nightliner 同做法），把 `docs/bq24072-pinout.md` §2.2 的「EP 必须焊 + 配热过孔阵列」直接落到封装上 |
| `TS`（pin 1） | **R5 = 10 kΩ 到 VSS** ⇒ 禁用温度监测 | 数据手册三处明确写出此做法；`V_TS = 75 µA × 10 kΩ = 0.75 V`，落在 `V_HOT(300 mV)`~`V_COLD(2100 mV)` 窗口内。**代价：放弃电池温度保护**（推荐电芯不带 NTC，见 facts 2.2） |
| 充电指示 | **R6 = 1.5 kΩ + D96（红光）接 `OUT`**，阴极接 `~{CHG}`（位号 D96：矩阵二极管占 D1..D95，顺延；⚠️ 原 D1 与矩阵二极管位号冲突，2026-09-18 改） | `~{CHG}` 开漏、充电时拉到 VSS。**选红光而不是绿/蓝**：电池低压端 3.0 V 时绿/蓝的正向压降已吃掉几乎全部余量；红光在整段电压区间都可见 |
| 电池 | **10000 mAh = 2×5000 mAh 并联（1S2P）**，共用**一块** PCM | 用户 2026-09-17 决定。单体 10000 mAh 软包厚度普遍 >10 mm、更难布置；两块可分置键盘左右两侧**平衡配重**（行业标准做法，AULA F87S 官方确认）。⚠️ **不可**用两块各自带保护板的电芯直接并联（互充 + 阈值失配）。采购要求见 §3.6、规格见 §3.5 |
| SW1（断电开关） | **不装** | ADR-0010（P7） |
| J1 | USB-C 16P；**D+/D-/SBU1/SBU2 全部 no_connect**；SHIELD 直接接 GND | P2/P10 未决；第一版 USB-C 仅充电（数据走 nice!nano 自带的 USB-C），见 §4 |
| Q1 / Q2 / R7 / R8 / R9 | `AO3401A` / `2N7002` / 10 kΩ / 100 Ω / 10 kΩ | ADR-0005 拓扑 C，照抄 Conejo。**Q1 的 S 接电源轨、D 接负载轨**；R7 把栅极上拉到源极；R9 在 MCU 未初始化时保证 LED 轨关断 |
| 被动件封装 | 统一 **0603（1608 metric）** | ✅ **已定（用户 2026-09-17）**。手焊友好（与矩阵二极管选 SOD-123 同一考虑）；0402 对新手不友好，0805 会挤占板上空间 |

#### ⚠️ 两条新发现的硬约束（已作为图面文字写进原理图）

1. **`VLED` 的真实来源是 `OUT`，不是裸电池。** `OUT` 稳压到 `VBAT + 225 mV`（满电约 4.4 V），
   仍属「电池直供」而非升压（ADR-0007 成立），且插 USB 时由 USB 供电。
   这也澄清了 §5.4 里「源极接电池轨」的措辞 —— 指的就是这条电池电平的**系统轨**
   （与参考实现 Conejo 的 `VDDH = BQ24075 OUT` 一致）。
2. 🔴 **`OUT` 的短路保护阈值 `VO(SC2) = 250 mV`（典型）**：`VBAT − VOUT` 超过该值并持续
   `tDGL(SC2) = 250 µs` ⇒ 切断 `OUT`，`60 ms` 后重试。也就是说 **RGB 的峰值电流必须让
   `VBAT − VOUT` 保持在 250 mV 以内**。数据手册**没有**给出内部 Q2 FET 的 `Rds(on)`；
   按 `IOUT` 推荐值 4.5 A 反推约 55 mΩ ⇒ 2.4 A 时约 130 mV，仍有余量 —— 但这**是推断**。
   ⇒ 与「固件把 RGB 峰值限到约 1 A」互为印证（§5.2 结论 4）。

#### 新增 UNVERIFIED（投板后必须实测）

| 项 | 说明 |
| --- | --- |
| 内部 Q2 FET 的 `Rds(on)`；`OUT` 在实际 RGB 峰值电流下的压降 | 数据手册无此参数。若压降超过 250 mV，会被当成短路而反复切断 `OUT` |
| `EN1` 接 `OUT` 时**无电池**台架测试的行为 | 无电池时 `OUT` 可能先从 0 起 ⇒ 启动瞬间可能被读成 USB100 档；数据手册称正常工作中会持续监测 EN1/EN2，故应自愈，但**未实测** |
| `AO3401A` 在 `Vgs ≈ −0.9 V` 的关断漏电 | §5.4 已记，仍未实测 |
| ~~`F1` 的额定值~~ | ✅ **已定案（2026-09-18，P15）**：**2 A hold 的 1812 自恢复保险丝**。复核结论：① 1.5 A 档在 60 °C 降额后 hold = 1.00 A（零余量）⇒ **否决**；2 A 档在 60 °C 仍 1.50 A（余量 50%）、85 °C 1.25 A（余量 25%）⇒ **通过**。② 压降最大 80 mV（R1max）⇒ 输入 ≥4.92 V，远高于 VIN-DPM 上限 4.63 V ⇒ **不影响充电**。⚠️ 保留说明：**hold ≠ trip** —— 2 A 额定在 1.0 A 下**永远不会动作**，它的作用是挡输入**短路/过流故障**，不是限流（限流由 BQ24072 的 ILIM 档负责） |

---

### 3.2 充电电流档位：四个可选方案（当前选方案 1）

**先澄清一个易混点**：数据手册里「1.5 A」是**芯片的编程上限**，不是本板能稳定拿到的电流。
真正决定充电快慢的是**输入限流档**，而 `ICHG` 只有在输入电流有余量时才起作用 ——
数据手册 §7 原文：*"The input current includes the system load and the battery charge current."*

**数据手册原文数字**（SLUS810N §8.3 / §8.5，均为 min/typ/max）：

| 参数 | 值 |
| --- | --- |
| `I_INmax`，EN1=LO 且 EN2=LO（USB100） | 90 / 95 / 100 mA |
| `I_INmax`，EN1=HI 且 EN2=LO（USB500） | 450 / 475 / **500** mA |
| `I_INmax`，EN2=HI 且 EN1=LO（ILIM 档） | `K_ILIM / R_ILIM` |
| `K_ILIM`（ILIM = 500 mA…1.5 A） | 1500 / **1610** / 1720 AΩ |
| 可编程输入限流范围 | `R_ILIM` = 8 kΩ…1.1 kΩ ⇒ **200…1500 mA** |
| `R_ISET` 范围 / `K_ISET` | 590 Ω…8.9 kΩ / 890 AΩ ⇒ 充电电流上限 **1.5 A** |
| `IN` 引脚推荐最大输入电流 | **1.5 A** |
| `RθJA` / 热调节门限 | 44.5 °C/W / `TJ(REG)` = 125 °C |
| 数据手册脚注 | 「1.5 A 且 125 °C 时芯片工作寿命降到 **20,000 h**；散热设计不到位就达不到编程电流」 |
| 数据手册 §10.2 **官方典型应用**取值 | `I_IN(MAX)` = **1.3 A**、`I_FASTCHG` = **800 mA**、TS 0–50 °C、6.25 h 定时器 |

**四个方案对比**（**10000 mAh** 电芯；充电时间按 ICHG 估算，未计 CV 段。
⚠️ 最后一列「定时器」是容量改成 10000 mAh 后新增的**决定性判据**）

| # | EN2/EN1 | `R_ILIM` | `R_ISET` | 输入上限 | 实际充电 | 充满约 | 定时器（min 7.2 / typ 9.6 / max 12 h） | 判定 |
| --- | --- | --- | --- | --- | --- | --- | --- | --- |
| 1 | 0 / 1 | 1.5 kΩ | 1.78 kΩ | 500 mA | ≈485 mA | ≈20.6 h | ❌ 远超 | 唯一完全符合 USB-C 声明的档位（**已于 2026-09-18 弃用**） |
| **2（✅ 2026-09-18 采用）** | 1 / 0 | **1.6 kΩ** | **887 Ω** | 1.0 A | ≈1.0 A | ≈10 h | ⚠️ 落在 9.6–12 h 之间 ⇒ **仍禁用定时器** | ✅ **已采用**：0.10C 落在商用区间中部，对标 EPOMAKER TH87；发热 1.3 W（+58 °C，`Tj`≈83 °C）。代价：超 USB 声明 2 倍（§3.7） |
| 3 | 1 / 0 | 1.24 kΩ | 1.11 kΩ | 1.3 A | ≈0.8 A | ≈12.5 h | ❌ 连 max 12 h 都不够 | 🟡 数据手册 §10.2 官方取值（但官方典型应用针对的是**更小**的电芯） |
| 4 | 1 / 0 | 1.1 kΩ | 590 Ω | 1.46 A | ≈1.5 A（标称） | ≈6.7 h | ✅ 唯一能在**最坏 7.2 h** 内完成 | ⚠️ 满功率：耗散 ≈2 W ⇒ **+87 °C，必然触发热调节而自动降流**，实际拿不到 1.5 A ⇒ **仍可能超时** |

**为什么当前选方案 1**（不是「1.5 A 做不到」，而是「按规范不该盲目设 1.5 A」）：

1. **USB-C 规范**：本板用 5.1 kΩ `Rd` 只声明「默认 USB 供电」（≤500 mA）。
   端口实际能给多少写在 CC 的电压上（Rp 档位），而 **BQ24072 没有 CC 检测能力**。
   直接设 ILIM 档 = 假设所有端口都能给 1.5 A。
2. **兜底机制确实有**：`VIN-DPM` 阈值 4.35 / 4.5 / 4.63 V —— 输入电压掉下来就自动降流，
   所以**不会烧东西**。但带过流保护的 USB HUB 可能直接断电/报过流，表现为「插上不充电」，
   对新手教程是灾难性的不确定性。
3. **热**：0.5 A → 0.65 W（+29 °C）；1.0 A → 1.3 W（+58 °C）；1.5 A → 1.95 W（+87 °C）。
   3×3 mm 的 QFN 在密闭 3D 打印壳里，1.5 A 基本等于「标称 1.5 A、实际被热调节压回来」。
4. 电芯侧 1.5 A = 0.15C（对 10000 mAh）远在标称区间下边界之内，对电芯完全不超限
   —— 卡点在 USB 声明、散热与**定时器**，都不在电芯。
5. ★ **容量改到 10000 mAh 后多出一条决定性判据：安全定时器。**
   看上表最后一列 —— 方案 1（20.6 h）与方案 3（12.5 h）都**超出**定时器上限；
   **方案 2（10 h）刚好落在 9.6–12 h 之间**（要赌芯片的个体差异）；只有方案 4 能确定覆盖，
   但它又因过热不可靠。⇒ 本版**仍把 `TMR` 接 VSS 禁用定时器**（§3.5），把这个问题彻底消除。
   📌 **2026-09-18 更新：用户采用方案 2（1.0 A）**，理由与代价见 §3.7。

**数据手册自己给出的正解（方案 5，本项目不采用）**：*"The BQ2407x is configurable to be
host controlled for selecting different input current limits based on the input source connected."*
即 **用 MCU 读 CC 电压再动态切 EN1/EN2**。代价：要给 CC1/CC2 加 ADC/比较器 + 2 个 GPIO，
而本项目 GPIO 余量只剩 4 个（ADR-0009 的引脚预算表）⇒ 不划算。

#### ⚠️ 社区对照带来的关键修正：`R_ISET` 要按 **C 倍率**换算，不能照抄绝对电流

社区里能拿到的最成熟样本（osprey / designguide / nightliner）**统一用 `R_ISET` = 3.9 kΩ
⇒ ICHG ≈ 0.23 A**。看起来比我们保守，**但那是假象** —— 它们的电池小得多：

| 项目 | ICHG | 电池容量 | **C 倍率** |
| --- | --- | --- | --- |
| osprey | 0.23 A | **250 mAh** | **0.91C**（几乎 1C 快充） |
| designguide | 0.23 A | readme 以 **500 mAh** 举例 | 0.46C |
| Conejo | 未填值 | **300 mAh** | — |
| **本项目** | 0.50 A | **10000 mAh** | **0.05C** |

⇒ **社区根本不保守，它们按 0.5–1C 在充**；
**我们的 0.5 A 是这套样本里 C 倍率最低的，而且容量翻到 10000 mAh 后差距进一步拉大。**

⇒ 所以「按社区方案来」在 `R_ISET` 上的正确写法**不是抄 3.9 kΩ**，而是按 C 倍率换算：

- 社区意图 **0.5–1C** ⇒ 10000 mAh 需要 **5–10 A**
- 三堵墙挡住：芯片充电上限 **1.5 A** + USB 输入能力 + 定时器
- 📌 **2026-09-18 更新**：最终取 **`R_ISET` = 887 Ω（1.0 A = 0.10C）** —— 即「超出 USB 规范、
  但落在商用同容量产品区间中部」的值。完整论证见 **§3.7**。
  本节此前写的「维持 1.78 kΩ / 0.5 A」**已被该决策取代**。

> **改法（若决定提速）**：只改 `docs/_tools/power_design.py` 四处 ——
> `"U1.5": "GND"` → `"OUT"`（EN2=1）、`"U1.6": "OUT"` → `"GND"`（EN1=0），
> 以及 R3 / R4 的 `value`；再跑 `gen_power_sch.py` 与 `verify_power.py`（后者的具名断言会跟着提示改）。

### 3.3 TS 温度监测：四个方案，以及「板上 NTC」这个坑

| 方案 | 接法 | 能测到什么 | 代价 / 风险 |
| --- | --- | --- | --- |
| **A（当前）禁用温测** | `TS` → 10 kΩ 固定电阻 → VSS | 无温度保护 | 零成本。数据手册三处认可此法 |
| **B 真·电芯温测** | `TS` → 10 kΩ NTC（**粘/贴在电芯表面**）→ VSS | 电芯温度，实现数据手册的 **0–50 °C** 充电窗口 | 需自购带引线 NTC + 一道装配工序；推荐电芯**不带** NTC 引线 |
| C 板上 NTC | `TS` → 0603 NTC（焊在 PCB 上）→ VSS | **板温**，不是电芯温度 | ⚠️ **不推荐**，理由见下 |
| D 靠电芯保护板 | — | ❌ **不等价**：保护板只做**过充 / 过放 / 过流**，电芯 45 °C 它不会停充 | 不能当作温度保护 |
| E 固件兜底 | — | ❌ 拿不到电芯温度（nRF52840 内部温感测的是芯片自身，ZMK 也不把它交给电池逻辑） | — |

**⚠️ 为什么「板上 NTC」是个坑（本会话新发现）**

- `TS` 的判据是绝对电压：`V_HOT ≈ 300 mV`、`V_COLD ≈ 2100 mV`（内部 75 µA 偏置），
  配 10 kΩ NTC 恰好对应 **0–50 °C**。
- 但 **BQ24072 自己就是热源**：0.5 A 时耗散 0.65 W，`RθJA = 44.5 °C/W` ⇒ 芯片附近板温升约 **+29 °C**；
  若按 §3.2 提速到 1.0 A 则约 **+58 °C**。
- 板上 NTC 读到的是「环境温度 + 充电器自热」。室温 25 °C + 0.5 A 自热 ≈ 54 °C
  ⇒ **已经越过 50 °C 的「热」阈值，充电会被暂停**；密闭 3D 打印壳里更早触发。
- ⇒ 结论：**要么按数据手册做真正的电芯温测（B），要么明说没有温度保护（A）。
  折中的「板上 NTC」会得到一个会误报的高温保护 —— 比没有更糟**，因为故障表现为
  「有时充、有时不充」，极难排查（这类「静默/间歇故障」正是本项目最想避免的）。
- 若坚持要板上 NTC：必须**远离 U1** 且远离电芯自热路径，并在文档里写明它测的不是电芯温度。

> ✅ **第一版维持方案 A（禁用温测）** —— **用户 2026-09-17 决定**。
> `R5` = 10 kΩ 到 VSS；`R5` 与一个 0603 NTC 同封装，所以若日后改走 B，
> 硬件上无需改板，但**必须把 NTC 从板上移到电芯表面** —— 这属于装配问题，不是原理图问题。
>
> **旁证（2026-09-17 补）**：ZMK 官方推荐的开源板 **nRFMicro 也不用温度监测**
> —— 它的电池座 `J3` 就是 2 脚（无 NTC 引脚），其充电 IC `MCP73832` 的官方规格亦明列
> `Temperature Monitor: No`。⇒ **本项目的选择与生态主流一致**，见
> `research/zmk-ecosystem-charging-precedent.md`。

### 3.4 社区对照：已按社区成熟方案落地五处改动

完整对照见 **`research/battery-charging-community-precedent.md`**
（对本机 31 个克隆仓库做两级扫描，用 `research/kicadnet.py` 做引脚级网表还原）。

**先说样本边界**：31 个仓库里只有 **5 个**画了独立充电 IC（4 个是 BQ2407x）——
**社区主流是「不画充电电路」，直接用控制器模块自带的充电器**
（nice!nano 自带 BQ24075）。所以本项目把 `BQ24072` 做在主 PCB 上**本身是少数派做法**
（理由见 ADR-0002）—— 这也意味着可比的样本天然有限。

| 项 | 社区做法 | 本项目 | 判定 |
| --- | --- | --- | --- |
| 输入限流档 | **4/4 全部 USB500**，无一例走 ILIM 档换速度 | USB500 | ✅ 一致 |
| `EN1` 接哪条轨 | **4/4 全部接 `OUT` 轨，无一例接 `VBUS`** | 接 `OUT` | ✅ 一致（§3.1 的安全理由被印证） |
| `R_ILIM` | osprey / designguide 用 **1.5 kΩ** | **已改为 1.5 kΩ** | ✅ 已对齐 |
| `R_TMR` | osprey / designguide 装 **47 kΩ（≈6.25 h）** —— 因为它们的电芯只有 250–500 mAh，0.23 A 也要充 2–4 h | **不装：`TMR` 接 VSS 禁用定时器** | ❌ **已反向**：10000 mAh 需 20.6 h，超出定时器 7.2–12 h 上限，见 §3.5 |
| USB 输入保险丝 | nightliner 在 **VBUS 侧**装 500 mA（照抄其**位置**）；Conejo 那颗在**电池路径**上（不可照抄） | **已加 `F1`（VBUS 侧）**，额定值 **2 A hold**（输入档已切 1.0 A，500 mA 会熔断；1.5 A 档降额后零余量） | ✅ 位置已对齐；**额定值不照抄**（社区那颗是配 USB500 档的） |
| `U1` 封装 | nightliner 用带**热过孔**的 EP 变体 | **已改为 ThermalVias 变体** | ✅ 已对齐 |
| `R_ISET` | 三家统一 3.9 kΩ ⇒ 0.23 A，**但其电池只有 200–500 mAh** | **保持 1.78 kΩ ⇒ 0.5 A** | ⚠️ **不照抄**，理由见 §3.2 |
| 温度监测 | **3/4 禁用**（10 kΩ 到 GND）；1 个（nightliner）用 **3 脚电池座中间脚接 `TS`** 做真·电芯温测 | 禁用 | ✅ 一致；且**无任何样本**用「板上 NTC」 |

**结论要点：**

1. **被印证的（输入侧与温度）**：USB500 档 **4/4**、`EN1` 接 `OUT` 轨 **4/4**、禁用温测 **3/4**。
   这三条本项目的独立推导与社区实践一致，不再需要额外论证。
2. **本次实际改掉的五处**：VBUS 侧 500 mA 保险丝、`R_ILIM` → 1.5 kΩ、`U1` 改 ThermalVias 封装、
   （`R_ISET` 保持不动）、`R_TMR` 47 kΩ。
   ⚠️ 其中 **`R_TMR` 一条已被随后的容量变更推翻**：容量改为 10000 mAh 后，
   定时器**上限 7.2–12 h** 远小于充满所需的 20.6 h ⇒ 改为 `TMR` 接 VSS 禁用定时器，见 §3.5。
3. **两处不能照抄的**：
   - **`R_ISET` 要按 C 倍率换算，不能抄绝对电流** —— 社区 0.23 A 对它们相当于 0.46–0.91C，
     照抄到 10000 mAh 会变成 0.023C（约 43 h）。详见 §3.2。
   - **Conejo 的 `F1` 位置不能照抄** —— 它串在**电池路径**上，而 RGB 的全部放电电流都走那条路
     （本项目峰值可达 A 级）⇒ 必然误断。要照抄就照 nightliner 的 **VBUS 侧**位置。

**社区做了、我们还没做的候选（备查，未决）**：

| 候选 | 证据 | 备注 |
| --- | --- | --- |
| 铁氧体磁珠 `FB1`（USB 输入） | nightliner `FB1`（串在 `F1` 之后） | 需先选型阻抗 / 额定电流 |
| 输入 **TVS** | nightliner `U2 = TVS2200DRV`（22 V 档器件） | 用于 5 V 输入需重新选型 |
| **电量计 `MAX17048`** | Conejo `U2`、osprey `U3`、designguide `U9` 三家不约而同 | 比 nice!nano 的 ADC 估电量准；代价是 I²C + 1 器件，且需先核实 ZMK 侧驱动 |
| 电池分压到 MCU ADC | nightliner `R6=806k` / `R7=2M` → MCU `P0.31` | nice!nano 已有内部方案 |
| **固件控制充电开关** | nightliner 把 `R_ISET` 下端接 MCU `P1.13`（网络 `CHARGE_CTRL_2`） | ⭐ §3.2 没列到的第三条杠杆；但会让 ISET 的「实际电流监测」失效，且 `[DS]` 要求上电做 ISET 短路检测 ⇒ 有未知风险 |
| 物理电源开关 | nightliner `SW21 = ON_OFF` | 与 ADR-0010（不设断电开关）相反 —— 它是分体，不改我们的决策 |

---

### 3.5 容量变更为 10000 mAh：商用键盘对标与三条路线

**决定（用户，2026-09-17）：电池改为 2×5000 mAh 并联 = 10000 mAh。**

#### 3.5.1 先说一条电气硬约束：只能并联，不能串联

- 数据手册 §8.1 绝对最大额定：`BAT (with respect to VSS) = −0.3 … 5 V`。
- BQ24072 是**单节（1S）**充电器，`VBAT(REG) = 4.2 V`（器件对照表）。
- 2S 串联满电 8.4 V ⇒ 使 BAT 脚超限 **68%**，会永久损坏芯片。
  ⇒ **串联方案不可行，并联是唯一解（1S2P）。**

#### 3.5.2 商用键盘怎么做（调研结论）

完整数据与来源等级见 **`research/keyboard-battery-capacity-precedent.md`**。

| 产品 | 电池 | 充电电流 | 充满约 | 来源等级 |
| --- | --- | --- | --- | --- |
| **AULA F87S** | **10000 mAh = 2×5000 并联** | 未列 | — | [REPORTED] 官方承认，TechPowerUp 报道 |
| **Kzzi Leop K98PRO** | 10000 mAh | **DC 5V / 1.4 A** | ≈7.1 h | [DOC] 官方手册产品参数页 |
| **Hola87** | 10000 mAh | **DC 5V / 350 mA** | **≈28.6 h** | [DOC] 商品页规格表 |
| **Keychron K10 v2** | 4000 mAh | 5V / 1 A | ≈5 h（手册口径） | [DOC] 官方手册 |
| Keychron K8（老版） | 4000 mAh | 5V / **2 A** | ≈3 h | [DOC] 官方手册 |
| AULA F87 / Ajazz AK870 / EPOMAKER F65 | 4000 mAh | — | — | [REPORTED] |

**读出来的四件事：**

1. **「2×5000 并联」是行业标准做法，理由与我们一致。**
   AULA 官方承认 F87S **不是**单体 10000 mAh，因为单体「厚度通常 10 mm 以上，很难塞进键盘扁平的机身」。
   ⇒ 我们的推理被印证。**额外收益**：两块可分置键盘**左右两侧** —— AULA 明确说这样做
   「可以更灵活地在有限空间里布局…更好地平衡整把键盘的重量分布，不会一边重一边轻」。
   这是「一块 200 g」做不到的；本项目 95 键、外宽 379 mm，左右分置空间充足。

2. ★ **消费级充电 IC 普遍没有「最长充电时间」这种限制** —— 本轮最重要的发现。
   ✅ **证据已从「推断」升级为「直接读取」**（2026-09-17 二轮调研）：
   - **ZMK 官方推荐的开源板 nRFMicro**（nice!nano 官方 FAQ 亦推荐它）的**完整 KiCad 原理图**
     （本机 `research/repos/joric__nrfmicro/hardware/nrfmicro.kicad_sch`）用的是
     **`MCP73832` 符号 / 实贴 `TP4054`**（两者 pin-to-pin 兼容）；
   - **Microchip 官方规格页对 MCP73832 明列**：`Charge Safety Timers: **No**`、
     `Temperature Monitor: **No**`；
   - **`TP4054` / `LTC4054` 同族同样无定时器**，其终止机制是 **C/10 电流判据**（不是时间上限）。
   ⇒ 另有旁证：商用 Hola87 用 **350 mA** 充 **10000 mAh**（理论 **28.6 h**），
   若其 IC 有 9.6 h 硬定时器则只能充到 1/3。
   ⇒ 完整调研见 **`research/zmk-ecosystem-charging-precedent.md`**。
   **结论**：BQ24072 的 `tMAXCHG` 是 TI 的**额外高级特性**，不是行业必需项 ——
   nRFMicro 与商用产品**都没有它**，而本项目把 `TMR` 接 VSS 与它们的做法**一致**。
   **真正的保命线**是：电芯自带保护板（过充/过放/过流）+ 4.2 V 恒压限制 + 终止电流检测 ——
   这三层商用键盘有，本项目**也都有**。
   ⇒ 因此 §3.1 把 `TMR` 接 VSS（禁用定时器）**是退回到全行业常规水平，不是拆掉防线**。

3. **充电电流没有统一答案**（350 mA … 2 A），但**普遍大于按 USB 规范可得的电流**。
   Kzzi 10000 mAh 用 1.4 A，Keychron 甚至写「支持最高 5V 2A」。
   ⚠️ **措辞更正**：它们**并非「不做 CC 声明」** —— 用 Type-C 从充电器取电必须做 CC 下拉，
   否则端口不会给电。准确说法是：它们**按超出 5.1 kΩ 下拉所声明的 500 mA 的电流去设计**
   （即超出规范；实际能否取到取决于充电器是否严格限流）。
   代价就是手册里必须写「请勿使用快充充电器」「勿用劣质适配器」这类免责声明 ——
   这正是「依赖充电器行为、而非规范保证」的证据。
   ⇒ 本项目**继续选择 USB 合规路线**（5.1 kΩ 下拉 + USB500 档），代价是 0.5 A。

4. **续航量级参考**：Kzzi K98PRO（97 键）10000 mAh ⇒ 默认灯效 55 h、关背光 666 h
   （其额定电流 ≤180 mA / ≤15 mA，与容量自洽）。本项目 95 键 + ZMK 的读数见 §5.2。

#### 3.5.3 三条路线与最终选择

| 路线 | 做法 | 优点 | 代价 |
| --- | --- | --- | --- |
| A（2026-09-17 曾采用，**已被 B′ 取代**） | `TMR` 接 VSS **禁用定时器**，保持 USB500 档 0.5 A | USB 规范合规；发热最低 | 充满需 **20.6 h** |
| **B′（✅ 2026-09-18 采用）** | `TMR` 接 VSS（**仍禁用定时器**）+ **切 ILIM 档到 1.0 A** | 充电 **≈10 h**（0.10C，落在商用区间中部） | 超 USB 声明 2 倍；发热 1.3 W（`Tj` ≈ 83 °C，**安全**） |
| C | 保持 0.5 A + 保留 47 kΩ 定时器 | 不动硬件 | ❌ **不可接受**：9.6 h 掐断 ⇒ 永远只用到 4800/10000 mAh，且 `~CHG` 2 Hz 闪烁 |

**⇒ 2026-09-18 最终采用 B′**（用户决策）：定时器**仍禁用**（因为 1.0 A 的 10 h 也压在
9.6–12 h 的边缘，要赌芯片个体差异），同时把充电电流提到 1.0 A。
完整论证（含商用同容量产品的实测区间）见 **§3.7**。

> **日常使用实际感受**：键盘是「插一夜」的使用模式。**1.0 A 下插一夜（约 8 h）可充入约 8000 mAh**，
> 按 §5.2 的关灯电流估算可用**数月**（而 0.5 A 档下同样的夜晚只能充 4000 mAh）
> ⇒ **这是选 1.0 A 的实际收益**。

> **改法（若日后决定提速）**：改 `docs/_tools/power_design.py` 四处 ——
> `"U1.5": "GND"` → `"OUT"`、`"U1.6": "OUT"` → `"GND"`，以及 R3 / R4 的 `value`
> （方案 4 = R3 1.1 kΩ / R4 590 Ω）。同时**应把 `TMR` 改回装 72 kΩ 并重新评估热调节风险**。
> `verify_power.py` 的具名断言会跟着提示改。

### 3.6 电池采购要求（10000 mAh 1S2P）

⚠️ **必须按本节下单**，否则会买到不能用的电池。

| # | 要求 | 原因 |
| --- | --- | --- |
| 1 | **必须是一体化 1S2P 电池包**（两块 5000 mAh 电芯**共用一块** PCM） | ❌ 两块「各自带保护板」的电芯**不可直接并联**：① 电压差会造成大电流互充；② 两块 PCM 的过流/过压阈值失配 ⇒ 一块先切断、另一块独自承担全部负载 |
| 2 | **PCM 过流保护阈值 > 2 A** | RGB 全亮峰值约 1.9 A（§5.2）；若 PCM 限流设在 2 A 附近会**触发保护断电** |
| 3 | 引出线**指定 AWG #24**，接头 **JST-PH 2.0（`PHR-2`）** | 与 `J2`（`B2B-PH-K-S`）匹配；JST-PH 的 2 A 额定条件是 AWG #24（facts §2.5） |
| 4 | 容量 2×5000 mAh，**标称 3.7 V、满充 4.2 V** | 与 BQ24072 的 `VBAT(REG) = 4.2 V` 匹配。**不可买 3.8 V / 4.35 V 高压电芯**（会充不满） |
| 5 | 电芯厚度 ≤ **10 mm**，单块占位约 **9.5 × 54 × 66 mm** | 参考电芯 `LP955465`（9.5×54×66 mm，100 g，18.5 Wh）。⚠️ **它是 1S1P 单节、自带 PCM** ⇒ 属**电芯级**参考规格，**不是可直购的成品包**；要买的是厂商按 **1S2P 配置**（两块该电芯 + **一块** PCM、单一 JST-PHR2 出线）做出的包 |
| 6 | 🔴 **电芯持续放电能力：单块 ≥ 1.5 A（两块并联后 ≥ 3 A）** | ⚠️ **这条与「PCM 过流阈值」是两件事，都要满足。** 不同来源对 5000 mAh 电芯的持续放电标称**差异极大**：同为 `LP955465`，三个来源分别标 **1.0–3.0 A** / **2–3 A** / **1C = 5 A**。若买到只标 1.0 A 的版本，两块并联上限仅 2 A，而 RGB 全亮峰值 **2.4 A** ⇒ **会掉电或触发保护**。必须按具体料号书面确认 |
| 7 | 温度保护：**不要求**带 NTC | 本项目 `TS` 已用 10 kΩ 禁用温测（§3.3）。若日后改走真·电芯温测（方案 B），需换成 **3 脚座**并单独要求 NTC 引线 |
| 8 | 必须有 **UN38.3 + IEC62133** 认证 | 软包电芯的安全底线；`LP955465` 等常见型号均具备 |

> ⚠️ **JST-PH 的 2 A 额定与固件限流是配套约束**：整个放电路径（电池包引出线 → `J2` → PCB 走线）
> 的能力上限是 **2 A**，而 RGB 未限流时峰值 **2.4 A**（§5.2）。
> ⇒ **必须与第一版的固件限流（约 1 A）配套使用**；若日后放开固件限流，连接器要一起换。

**对机壳的影响（设计输入，交 G5）：**

✅ **已决策（用户 2026-09-17）：采用 B —— 两块分置键盘左右两侧。**

| 布置 | 占位 | 机壳深度 | 判定 |
| --- | --- | --- | --- |
| A. 相邻并排（两块贴在一起） | 单处仓约 **10.5 × 110 × 68 mm** | ≥11 mm | 未采用（重量集中在一侧） |
| **B. 分置左右两侧（已定）** | **两处**各约 **10.5 × 56 × 68 mm** | **≥11 mm** | ✅ 配重更均衡（AULA 同做法）；本项目 95 键、外宽 379 mm，空间充足 |

- **10.5 mm** = 电芯 9.5 mm + 公差；**≥11 mm 机壳深度** = 电芯 9.5 + 上下间隙 + 走线空间
- 原设计（6 mm 电芯）的「电池仓 6.5 × 51 × 84 mm、机壳深 ≥8.5–9 mm」**已作废**
- ⚠️ 两处内腔都需避开定位板 / PCB 与螺丝柱（G3 未定）；**两条引出线需汇合到 `J2`**
  （或分别在两处就近并入，需在 B4 布局时定走线路径）
- 具体分区在 **G5「电池仓尺寸」**一并定

### 3.7 充电电流的行业对标（2026-09-18）—— ✅ **已决策：采用方案 2（1.0 A）**

**决策（用户 2026-09-18）：充电档位切到 ILIM 档 —— `EN2=OUT` / `EN1=GND`、
`R_ILIM` = 1.6 kΩ、`R_ISET` = 887 Ω、`F1` = 2 A hold ⇒ 输入 ≈1.0 A、充电 ≈1.0 A（0.10C），
充满约 10 h。**

⚠️ **代价必须写明：这是本项目唯一主动超出 USB-C 声明之处** —— 5.1 kΩ CC 下拉只声明
500 mA，取 1.0 A 等于超 2 倍。**依据是商用同容量产品的实测区间**，见下。

⚠️ **本节同时修正了 §3.5 里「建议维持 0.5 A」的结论** —— 那个结论有**样本偏差**：
当时引用的 ZMK 开源板
（nRFMicro / mikoto 等）全是 **90–500 mAh 的小电池设备**，它们的 350 mA 相当于 **0.7–1C**，
**不能用来论证 10000 mAh 该用多大电流**。补齐**同容量段（≥5000 mAh）**证据后的图景如下
（完整数据、来源等级与诚实边界见 **`research/large-battery-keyboard-charging-current.md`**）：

| 产品 | 电池 | 充电电流 | ⇒ C 率 | 来源 |
| --- | --- | --- | --- | --- |
| AULA L99 | 8000 mAh | **1300 mA** | 0.163C | [DOC] 官方手册 |
| Kzzi K98PRO | 10000 mAh | **1400 mA** | 0.140C | [DOC] 官方手册 |
| EPOMAKER TH87 | 10000 mAh | **≤1000 mA** | ≤0.10C | [DOC] 商品页 |
| **本项目（当前）** | 10000 mAh | 485 mA | **0.049C** | — |
| Hola87 | 10000 mAh | 350 mA | 0.035C | [DOC] 商品页 |

**⇒ 行业区间 0.035–0.163C，本项目在**下三分之一**。**

**另有两条来自整机拆解的直接证据：**

1. 商用无线键盘用的是 **`TP4056`（线性充电，最大 1 A）**；
2. ⭐ **即使 TP4056 第 1 脚本身就支持 TEMP 温测，厂商仍用 2 线电池包** ⇒
   **「不用电池温度监测」确属商用常态**，与本项目 §3.3 的选择同向。

⚠️ **它们普遍超出 USB 规范**：AULA / Kzzi / EPOMAKER 三家都必须在手册里写
「仅使用电脑 USB 口充电」「请勿使用快充手机充电器」—— 因为实际取 1–1.4 A，
远超 5.1 kΩ CC 下拉所声明的 500 mA。**合规不是行业惯例，「免责声明」才是。**

**⇒ 因此 P13 是一次明确的取舍，两条路都有依据：**

| 路线 | 配置 | 充满 | 对标 | 代价 |
| --- | --- | --- | --- | --- |
| **维持 0.5 A** | 现状（`EN2=0/EN1=1`、R_ILIM 1.5 kΩ、R_ISET 1.78 kΩ） | 20.6 h | Hola87 | 无；**唯一完全合规** |
| **切 1.0 A** | `EN2=1/EN1=0`、R_ILIM **1.6 kΩ**、R_ISET **887 Ω** | ≈10 h | **EPOMAKER TH87** | 超 USB 声明 2 倍；耗散 1.3 W ⇒ `Tj` ≈ 83 °C，**低于 125 °C 热调节门限 ✅** |

⚠️ **不建议 1.3 A 及以上**：输入侧 1.3 A 只增大**系统负载余量**，
**充电电流仍由 `R_ISET` 决定**，不会更快 —— 却要付出更大的合规代价。
另注：本表温升按数据手册 `RθJA = 44.5 °C/W`（JEDEC 标准板）估算是**保守上界**；
键盘 PCB 铺铜面积大，实际会更低（但未实测，见 §3.1 UNVERIFIED 列表）。

---

## 4. USB-C 数据线（D+/D-）如何处理

### ✅ 技术定论（2026-09-17 核实）：键盘的 USB-C 只能充电

原表格里的「做法 A（D+/D- 接到主控）」**电气上不可行**，原因是硬件的：

- nRF52840 的 **USB D+/D- 是独立专用引脚**（Nordic 官方引脚表：`AD4 = D-`、`AD6 = D+`），
  **不属于 GPIO 编号体系**。`P0.18` / `P0.19` 是普通 GPIO（P0.18 还可配成 `nRESET`），**与 USB 无关**。
- ⇒ **nice!nano 的 2×12 排针上不存在 USB 数据脚** —— 它板载 USB-C 已直接占用这两根专用引脚。
- ⇒ 键盘的 `J1`（我们自己的 USB-C）**没有任何地方可接 D+/D-**。

**因此：**

- `J1` = **纯充电口**（`VBUS` / `GND` / `CC1` / `CC2`），D+ / D- / SBU1 / SBU2 保持 NC
  —— 这在 B1 里已经就是这样画的 ✅
- **「有线模式」与「刷固件」只能走 nice!nano 自带的 USB-C**

| 做法 | 判定 |
| --- | --- |
| A. D+/D- 接到主控 USB 引脚 | ❌ **不可行**（排针无 USB 数据脚，见上） |
| B. 只接 VBUS/GND/CC，D+/D- 悬空 | ✅ **唯一可行**，B1 已落地 |

### ✅ 已决策（用户 2026-09-17）：**底壳侧壁开孔**

**外壳必须为 nice!nano 板载的 USB-C 留出可访问方式**，否则**无法刷固件**
（ZMK 的 UF2 bootloader 也必须先插 USB 才能写入）。

**决定：在底壳侧壁对准 nice!nano USB-C 的位置开孔。** 理由：插线即用，刷固件最方便。

⚠️ **开孔位置依赖一个尚待量测的尺寸**：nice!nano 插在插座上时，其 USB-C 座相对 PCB 边缘的
**位置与朝向** ⇒ **并入 B6 采购实物核对时一并量测**（拿到实物前无法定孔位）。

> 备选方案（已考虑未采用）：底壳做可拆盖（外观更完整，但每次刷固件要拆壳）、
> 后沿开槽（开孔更大）、不开孔走 SWD 飞线（对新手不友好）。
> ⚠️ ADR-0003 已定「第一版按 nice!nano v2 设计并保证」，所以本条是**确定约束**，不是可选项。

---

## 5. 电流预算（用于选开关与走线宽度）

### 5.1 LED 供电电压：一个必须正视的边界问题

参考基线 Apollo87H 的实测拓扑（解析其 `.kicad_pcb` 得到）：

| 实测事实 | 值 |
| --- | --- |
| RGB LED 数量 | 87 颗 `SK6812MINI` |
| LED 供电引脚（pad 3）所接网络 | **`5V`**（87/87 全部接 5V） |
| `5V` 网络上的焊盘总数 | 99 个 |
| 5V 的来源 | USB-C VBUS（该板为**纯 USB 供电**，不是电池供电） |
| 其他相关网络 | `RGB_5V`、`RGB_OUT`（数据）、`5V` 上有 1812 保险丝 |

⚠️ **这不能直接照搬**：Apollo87H 是 USB 供电，5V 唾手可得；**StarShield 是电池供电（3.0–4.2V）**。

**本设计选用的 LED（`SK6812MINI-E`，LCSC C5149201）实测规格**（来源：立创商城商品参数表）：

| 参数 | 值 |
| --- | --- |
| **工作电压** | **3.7 V ~ 5.5 V** ⭐ 关键 |
| 静态电流 | 0.6 mA（**单颗**，×95 ≈ 57 mA —— 印证 ADR-0005 的待机漏电判断） |
| 单通道电流 | **12 mA**（该 SKU 为 12mA 版本） |
| 尺寸 | 3.2 × 1.78 × 2.8 mm |
| 数据传输 | 800 kbit/s，单线级联 |
| 厂家使用注意 | 12mA 版本：单色可 100% 灰阶；**三色同时点亮请用 70% 灰阶** |

✅ **结论一**：**工作电压下限恰好是 3.7 V**，因此 **电池直供（3.7–4.2 V）在范围内，第一版不需要 5V 升压电路。**
这避免了为无线键盘增加一颗升压 IC（其静态电流会直接吃掉续航）。

⚠️ **结论二（风险）**：下限 3.7 V 意味着**电池放电到 3.7 V 以下时，LED 已低于标称工作电压**，
会出现亮度下降/偏色。LiPo 放电曲线在 3.7 V 以下仍有可观容量（约 3.4–3.7 V 区间），
所以**电量较低时 RGB 会变暗或颜色偏移，属于预期内的取舍**。
替代方案（均未决策）：
- A. 接受亮度衰减（最简，推荐第一版）；
- B. 固件在低电量时降低 RGB 亮度上限（无额外硬件成本，推荐配合 A）；
- C. 加 5V 升压 IC（全电压区间亮度稳定，但增成本 + 静态电流，**与无线续航目标冲突**）。

⚠️ 数据来源说明：以上来自分销商（立创商城）参数表，**非原厂 datasheet PDF**（本环境不可抓取 PDF）。
关键设计若依赖此值，建议后续用原厂 datasheet 复核。

### 5.2 电流预算

| 负载 | 估算电流 | 依据 |
| --- | --- | --- |
| 主控（nice!nano v2，无线工作） | 约 5–15 mA | 连接待机 0.05–0.48 mA；峰值发射更高 |
| 95 颗 SK6812MINI，**每颗 12 mA × 3 通道** | **95 × 36 mA ≈ 3.4 A** | ⚠️ 理论最大值（全白 100% 灰阶） |
| 95 颗 SK6812MINI，按厂家建议 70% 灰阶 | **约 2.4 A** | 厂家明确要求三色同亮用 70% 灰阶 |
| 静态（RGB 门控关闭，LED 仅静态电流） | 95 × 0.6 mA ≈ **57 mA** → 门控后 ≈0 | ✅ 印证 ADR-0005 必须做门控 |
| 待机（整机，RGB 供电切断） | 约 20 µA | nice!nano v2 18 µA + 漏电 |
| 充电 | **≈1.0 A**（ILIM 档：`R_ILIM` 1.6 kΩ ⇒ 输入限流 1.0 A；`R_ISET` 887 Ω ⇒ ICHG 1.0 A） | 见 §3.7。⚠️ 超出 5.1 kΩ CC 声明的 500 mA，是**有意取舍** |

**容量与续航（10000 mAh，2026-09-17 起）**

| 场景 | 电流 | 续航（10000 mAh） |
| --- | --- | --- |
| 深睡待机 | 约 20 µA | 数十年（实际由自放电与保护板漏电支配） |
| 无线打字、RGB 关闭 | 约 5–15 mA | **约 660–2000 h（27–83 天）** |
| RGB 限到 1 A（第一版目标） | 约 1 A | 约 10 h |
| RGB 70% 灰阶全亮 | 约 2.4 A | 约 4.2 h |

对照商用机型：Kzzi K98PRO（97 键，同为 10000 mAh）官方口径为默认灯效 55 h、关背光 666 h
—— 本表的关灯估算（27–83 天）与之同量级，数据自洽（§3.5）。

**结论与约束：**
1. **RGB 峰值电流（约 2.4 A @70% 灰阶）超过了 JST-PH 2.0 的 2 A 额定**
   （原厂额定条件还是 AWG #24）。→ ⚠️ **不能靠接插件承载全亮电流**，需在 PCB 阶段复核：
   限制固件最大亮度、或改用更大电流的连接器/直接焊线。
2. **RGB 供电路径（VLED）走线需按 2–3 A 设计**（宽度待 PCB 阶段按铜厚计算）。
3. ⚠️ **实测静态电流 0.6 mA/颗 × 95 ≈ 57 mA** 是 ADR-0005 中「约 95 mA 待机漏电」的
   真实依据来源；实测值比 ADR 里的估计值略低，但结论（必须门控）不变。
   **建议后续据此修正 ADR-0005 中的数字。**
4. ⚠️ **第一版必须限制 RGB 最大亮度。** 理由见 §5.3 / §5.4 两条：全亮电流会同时
   打穿开关与 PMOS 的选型空间。建议固件把整机峰值电流限制在 **约 1 A 以内**。

### 5.3 🔴 物理断电开关：候选料号**全部不达标**（重大发现）

原计划用 `MSK12C02` 这类常见微型贴片滑动开关做物理断电。**经原厂 datasheet 与真实键盘网表双重核实，全部不可用：**

| 候选料号 | 实际额定 | 来源 | 结论 |
| --- | --- | --- | --- |
| **`MSK12C02`**（SHOU HAN） | **DC 12 V, 50 mA** | 原厂规格书 §2.5 原文「DC 12V，50mA（有效值）」 | ❌ **比需求小 48 倍**（2.4 A 时） |
| `OS102011MS2QN1`（C&K） | **0.1 A @ 12 V DC** | C&K 原厂 | ❌ 小 24 倍 |
| `SS12D00G3` | 声称 3 A @ 28 VDC | 仅单个小厂商页面，**低可信** | 🟡 不可用（无官方封装） |
| **`1101M2S3CQE2`（C&K）** | **6 A @ 28 V DC**，THT，12.70×6.60×6.35 mm | C&K 原厂 | ✅ 达标，但**无官方 KiCad 封装**（需自制，端子间距 4.70 mm） |

⚠️ **`BQ24072` 没有 `SYSOFF`，无法用芯片断开电池**（那是 `BQ24075/79`）。
⇒ **物理断电只能靠外部开关，因此开关必须真的扛得住电流，没有软件退路。**

⚠️ **「限制 RGB 亮度」也救不活小开关**：50 mA 与 1 A 差 20 倍、与 2.4 A 差 48 倍。

#### ✅ 真实工程的两条可行路线（均有实证）

**路线 A：换成 `BQ24075` + 小开关切 `SYSOFF`（推荐）**

真实先例：ZMK 官方社区设计指南（[`ebastler/zmk-designguide`](https://github.com/ebastler/zmk-designguide)，网表已核验）——
`MSK12C02` 公共端接 `BQ24075` 的 `SYSOFF`，一端经 100 kΩ 上拉到 `+BATT`（关断），另一端接 GND（开机）；
另有 `2N7002` 在插入 USB 时把 `SYSOFF` 拉低，保证插电仍能充电。
作者原话：*"can be used to switch the battery off **without the whole battery current passing through
the microswitch** … this switch does not have any significant current flowing through it"*。

| 项 | 值 |
| --- | --- |
| 开关实际电流 | ≈ 4.2 V / 100 kΩ ≈ **42 µA** → 对 50 mA 额定有 **约 1000 倍余量** |
| 料号 | 仍可用 `MSK12C02`（便宜、SMD、有官方 KiCad 封装） |
| **关键可行性** | ✅ 已核验：**`BQ24075RGT` 与 `BQ24072RGT` 封装完全相同**（`VQFN-16-1EP_3x3mm_P0.5mm_EP1.6x1.6mm`），pin 15 即 `SYSOFF` → **可视为 drop-in 替换** |
| **先例数量** | ✅ **3 个独立实现**（不只设计指南）：**ZMK 硬件设计指南**、**kurtis-lew/Conejo**、**ebastler/osprey**，接线一致，均网表级核实 |
| ⚠️ **残留漏电** | **`IBAT(PDWN)` = 4.3 µA 典型 / 6.5 µA 最大**（TI SLUS810N）。**数据手册中不存在「SYSOFF 断开后 BAT 漏电」的专门指标**；§9.4.1 的「10 µA」是举例叙述，**不是规格**。⇒ **这是低漏电态，不是电气隔离**（实用上 10000 mAh ÷ 4.3 µA ≈ 26 万年，对存放目的等同于断开） |
| ⚠️ **反向发现** | **nice!nano v2 用 BQ24075，却把 SYSOFF 硬接 GND**，断电改走门控 LDO 的 `CE` —— 旗舰商业 ZMK 控制器主动放弃了 SYSOFF 路线 |
| 副作用 | `SYSOFF` 拉高会同时禁用充电（串联接法固有），需一颗 `2N7002` 在插 USB 时拉低 |
| 待复核 | `BQ24075` 的 `EN1/EN2` 输入限流取值需与本项目一致 |

**路线 B：保留 `BQ24072` + 大电流机械开关**

用 C&K `1101M2S3CQE2`（6 A @ 28 VDC）。真断电、余量充足，但需自制封装且体积大。

**路线 C：自建 P-FET 负载开关串电池路径（有实证但无键盘先例）**

P-FET `S = 电池+`、`D = 系统`，栅极 100 kΩ 上拉到 S（默认 `Vgs=0` 可靠关断），
`MSK12C02` 公共端接栅极、一档接 GND（导通）、另一档接 S（关断），开关只走约 42 µA。
⚠️ 调研结论：**没有任何键盘项目这么做**（电池侧 FET 只用于 power path 或保护）。
可行但缺乏先例。

> 📌 **决定（用户）：不设电池断电开关 —— 本节的三条路线全部不采用。**
> 见 **ADR-0010**。理由：电池在**有线档也保持接通**（与 Keychron 等成熟三模产品一致），
> 「关机」= 拨到有线档 + 拔线，再由 ZMK 深睡接手（约 20 µA）；
> 存放则拔 JST。**充电 IC 保持 `BQ24072` 不变**，也不需要那颗 `2N7002`。
> 本节内容保留作为决策依据（它解释了为什么「随便挑个小开关串电池」不可行）。
>
> ⚠️ **另有一条「不加电池开关」的选项**：ZMK 官方把 `&soft_off` 定义为
> *"an alternative to using a hardware switch to physically cut power"*，
> 但同一份文档也说明 *"Power is **not** technically removed from the entire system"*。
> 若第一版想省掉这颗开关，这是零硬件的替代（长期存放仍需拔 JST 插头）。
> 取舍见 **ADR-0010** 方案甲。

### 5.4 🔴 RGB 门控 PMOS：**关断在满电时不可靠**（同样重大）

选定的 `AO3401A`（Vgs(th) 最大 −1.3 V，最小 −0.5 V）在**电池满电 4.2 V** 时：

```text
PMOS 源极接电池（4.2 V），栅极由 3.3 V GPIO 驱动：
  导通：Vgs = 3.3 − 4.2 = −0.9 V   → 部分导通 ✅（但 Rds(on) 要按 85 mΩ 算，不是 60 mΩ）
  关断：Vgs = 0 − 4.2  = −4.2 V    → 完全关断 ✅

⚠️ 真正的问题在「栅极拉高到 3.3 V 想关断」这个动作本身不成立：
   GPIO 只能输出 3.3 V，而源极是 4.2 V ⇒ Vgs = −0.9 V，
   这已经【超过】AO3401A 的最小阈值 0.5 V（绝对值）⇒ 低阈值批次会持续导通。
```

**关键**：**加一颗栅源上拉电阻并不能解决**——上拉只能把栅极拉到源极电位，
但 GPIO 输出高电平时会把栅极钳在 3.3 V，上拉无法把栅极拉到 4.2 V。

**必须改为以下之一：**

| 方案 | 做法 | 评价 |
| --- | --- | --- |
| **A. 加 NMOS 反相级** ✅ **推荐** | `2N7002`（S=GND，G 经 100 Ω 接 GPIO + 10 k 下拉）+ `AO3401A`（**S=电池轨、D=LED 轨**，栅极经 10 k 上拉到 S） | ✅ **有真实先例**；4.2 V 下 `Vgs(off) = 0`（保证关断）、`Vgs(on) ≈ −4.2 V`（充分导通）；ZMK 侧用 `GPIO_ACTIVE_HIGH` |
| B. 门控 LDO 使能脚 | 不去切 LED 电源，改切 3.3V LDO 的 `EN` | ✅ nice!nano v2 官方做法；但 **3.3 V 低于 LED 标称下限 3.7 V**，与 ADR-0007 冲突 |
| C. PMOS 源极改接 3.3 V 轨 | 源极 3.3 V，`Vgs` 干净（0 / −3.3 V） | ❌ 同上，本项目的 LED 需要电池轨电压 |

> ⚠️ **诚实性说明（勿把推断当结论）**：上面「`Vgs = −0.9 V` 会导致关不断」的**阈值侧有数据手册支撑**
> （`AO3401A` 的 `VGS(th)` 为 −0.5 ~ −1.3 V，而 `RDS(ON)` **仅在 `VGS ≤ −2.5 V` 下规定**），
> 但**功能性失效的量级未经实测，也没有任何项目如此记载** ⇒ 标记 `❓ UNVERIFIED`。
> 更准确的表述是：**−0.9 V 落在亚阈值区，数据手册未规定该点行为，因此不能保证关断。**
> 投板后**必须实测**该引脚的关断漏电。

> ✅ **照抄哪一个：选 `kurtis-lew/Conejo`，不要照抄 ZMK 硬件设计指南。**
> ⚠️ **归属更正**：该指南原作者是 **`ebastler`**（[`ebastler/zmk-designguide`](https://github.com/ebastler/zmk-designguide)，★494）；
> 本项目早期网表还原用的是它一份 **2022 年 fork 快照**（`Croktopus/...`，★2），
> 两者原理图内容不同。该指南**没有模式开关**，不是「一开关管模式+电源」的先例。
> 体二极管分析见下一节；Conejo 是**同拓扑但方向正确**的实现（`S=VDDH` 电源、`D=EXT_PWR` 负载）。
> ⚠️ **30+ 仓库核实结论：没有任何键盘项目把 P-FET 源极放在 4.2 V 电池轨、栅极直接由 3.3 V GPIO 驱动。**
> 凡是 GPIO 直驱 P-FET 的项目（nRFMicro、nice!nano v1）**全部**把源极放在 **3.3 V 稳压轨** ——
> 这正是它们规避 `Vgs(off) = −0.9 V` 的方式。

⚠️ **照抄设计指南时必须翻正 S/D**：该参考设计把 P-FET 的 **S/D 画反了**
（S 在负载侧、D 在电源侧）——P-MOSFET 体二极管 anode = drain，
接反后**关断时体二极管正偏**，LED 轨仍被抬到 `VSW − 0.7 V`，门控失效。
**正确接法：`S` 接电源轨（电池）、`D` 接负载轨（LED）**，
与 nice!nano v1 的 Q1、nRFMicro 的 Q2 一致。

### 5.5 ✅ 数据线电平：**不需要 level shifter**（核实后推翻了一条警告）

调研曾提示「3.3 V GPIO 驱动 LED 数据线电平不足，可能需 TXB0108」。
下载 **`SK6812MINI-E` 原厂规格书**核实后，结论是**本设计不需要**：

```text
VDD = +3.7 ~ +5.5 V
VIH = 0.65 × VDD      ← 是比例，不是固定的 3.4 V
VIL = 0.30 × VDD
```

设计指南说的「3.4 V」是按 **VDD = 5 V** 反推的（0.65 × 5 = 3.25），**不适用于电池直供的本设计**。

| VDD（电池电压） | `VIH = 0.65 × VDD` | 3.3 V GPIO 余量 | 结论 |
| --- | --- | --- | --- |
| 5.0 V | 3.250 V | +0.050 V | ⚠️ 边缘（这正是指南针对的情形） |
| 4.2 V（满电） | 2.730 V | **+0.570 V** | ✅ |
| 3.7 V（标称最低） | 2.405 V | **+0.895 V** | ✅ |

⇒ **电池直供反而让电平问题消失。** 但 ⚠️ **不能给 LED 加 5 V 升压**，
否则余量掉到 50 mV（这与 ADR-0007 的结论一致，是又一重理由）。

**✅ 参考已验证的现成解（来自 nice!nano 官方原理图，见 `research/pmos-ext-power-facts.md` §S14/S15）**

| 板 | 做法 | 关键点 |
| --- | --- | --- |
| **nice!nano v1** | PMOS 源极接 `VBAT`、漏极接 LDO 输入；**栅极由 `VBUS`（5 V）驱动** | 因为栅极是 5 V，`Vgs(off) = +0.8 V`（硬关断）、`Vgs(on) = −VBAT`（完全导通）—— **它根本不面对「3.3 V GPIO vs 4.2 V 电池」这个问题** |
| **nice!nano v2** | **省掉串联 PMOS，改为门控 LDO 的使能脚** | 得到真正的**高阻关断态** |

⚠️ **兼容性提醒**：ZMK 的 `ext-power` 极性可配置，且**同一个 GPIO 在两代 nice!nano 上极性相反**：
**v1 用 `GPIO_ACTIVE_LOW`（PMOS/开关），v2 用 `GPIO_ACTIVE_HIGH`（LDO 使能脚）**。
本项目若加反相级 → 用 `GPIO_ACTIVE_HIGH`；若直接驱动 PMOS/LDO 使能（带上拉）→ 用 `GPIO_ACTIVE_LOW`。
**双控制器兼容设计必须注意这一点**（与 ADR-0003 相关）。

⚠️ **另外必须注意体二极管方向**：`AO3401A` 体二极管为 **`VBAT` → 源极，负载 → 漏极**。
若把负载接在源极，**电源会经体二极管永久直通**，门控彻底失效。
**接线：源极接电池，漏极接 LED 供电。**

---

## 6. 待办

| 编号 | 待办 | 阻塞原因 |
| --- | --- | --- |
| ~~P1~~ | ~~核实 BQ24072 引脚表与 TS/ISET/ILIM/TMR 取值~~ | ✅ **已完成**，全部取值见 `docs/bq24072-pinout.md` §3 |
| ~~P2~~ | ~~外壳如何让 nice!nano 的板载 USB-C 可访问~~ | ✅ **已定（用户 2026-09-17）：底壳侧壁开孔**。⚠️ 孔位需先量测 nice!nano 的 USB-C 座位置与朝向（并入 B6），见 §4 |
| ~~P3~~ | ~~核实 SK6812MINI 单颗最大电流~~ | ✅ **已完成**：工作电压 3.7–5.5V、12mA/通道、静态 0.6mA（见 §5.1） |
| ~~P4~~ | ~~选 USB-C 母座、SPDT 开关、PMOS 料号~~ | ✅ **已完成**（USB-C 与 PMOS 料号已定；开关见 P7） |
| ~~P5~~ | ~~生成电源子图原理图并通过 ERC~~ | ✅ **已完成（2026-09）**：`hardware/pcb/StarShield/power/power.kicad_sch`，ERC **0 error / 2 warning**（warning 为待 B2 接线的跨图标签）；定稿见 §3.1 |
| P6 | 决定 RGB 峰值电流的处置（限亮度 / 换连接方式） | 🔴 已升格为**硬约束**：`OUT` 的短路保护阈值 250 mV，见 §3.1 第 2 条；结论仍是「固件把峰值限到约 1 A」+「pigtail 指定 AWG #24」 |
| **P7** | ✅ **已决定：不设电池断电开关**（用户，走成熟路线）。电池在**有线档也接通**；「关机」= 有线档 + 拔线 + ZMK 深睡；存放拔 JST。充电 IC 保持 `BQ24072` | 见 **ADR-0010** |
| ~~P8~~ | ~~决定 RGB 门控关断方案~~ | ✅ **已定并落地**：拓扑 C（`2N7002` + `AO3401A` 反相级，`GPIO_ACTIVE_HIGH`），实现在 Q1/Q2/R7/R8/R9，见 §3.1 与 ADR-0005 |
| ~~P11~~ | ~~判断是否需要 LED 数据线 level shifter~~ | ✅ **已核实：不需要**（VIH = 0.65×VDD，电池直供余量 ≥0.57 V），见 §5.5 |
| ~~P9~~ | ~~确认 `~{CE}` 接法~~ | ✅ **已按数据手册定**：`~{CE}` 接 VSS（常开）；同时定了 `EN1/EN2` = USB500 档与 `TD` 接 VSS，见 §3.1 |
| ~~P10~~ | ~~确认 USB-C 的 D+/D- 是否接入~~ | ✅ **已定（2026-09-17 核实）**：**不接入**。nRF52840 的 USB D+/D- 是独立专用引脚（`AD4`/`AD6`），不在 GPIO 编号体系内，排针上不存在 ⇒ 键盘 `J1` 只能充电。见 §4 |
| P12 | 决定 `ZMK_RGB_UNDERGLOW_EXT_POWER` 是否开启 | ZMK 提供该 Kconfig（RGB 开关联动 ext-power），建议开启 |
| ~~P13~~ | ~~充电电流档位~~ | ✅ **已定（用户 2026-09-18）：采用方案 2 —— ILIM 档、输入 ≈1.0 A、充电 ≈1.0 A（0.10C）、充满约 10 h**。`EN2=OUT` / `EN1=GND`、`R_ILIM` 1.6 kΩ、`R_ISET` 887 Ω、`F1` **2 A hold**（⚠️ 初稿的 1.5 A 已被 P15 降额复核否决，见 §6）。⚠️ **唯一主动超出 USB-C 声明之处**，论证见 §3.7 |
| ~~P14~~ | ~~是否启用电池温度保护~~ | ✅ **已定（用户 2026-09-17）：维持方案 A 禁用**（`R5` = 10 kΩ）。旁证：nRFMicro 的电池座也是 2 脚、其 IC 官方规格亦 `Temperature Monitor: No`，见 §3.3 |
| ~~**P15**~~ | ✅ **已定案（2026-09-18）：`F1` = 2 A hold 的 1812 自恢复保险丝（`MF-MSMF200`）**，原理图与封装已改（0603 → 1812）。复核判据两条均通过：① **hold 电流**——1.5 A 档在 60 °C 降额后仅 1.00 A（= 工作电流，零余量）⇒ 否决；2 A 档 60 °C 仍 1.50 A（余量 50%）、85 °C 1.25 A（余量 25%）⇒ 通过；② **压降**——R1max 80 mΩ ⇒ 最大 80 mV，输入仍 ≥4.92 V，远高于 VIN-DPM 上限 4.63 V ⇒ 通过。<br>🟡 **残留**：LCSC 料号待 BOM 阶段补；若要求 ≥16 V 额定电压（现选型为 8 V）需另选 2 A/16 V 的 1812 PTC | 仅剩 BOM 料号 |
| ~~P16~~ | ✅ **电池容量定为 2×5000 mAh 并联（10000 mAh）**；`TMR` 接 VSS 禁用安全定时器，`R_TMR` 已移除 | **已完成（2026-09-17，用户决策）**；论证见 §3.5 |
| **P17** | 🔴 **电池包采购落地**：必须买**一体化 1S2P 单 PCM 包**；PCM 过流阈值 **>2 A**，**且**电芯持续放电能力 **单块 ≥1.5 A**（两块 ≥3 A）；引出线 AWG #24、接头 JST-PH（详见 §3.6） | 需采购；⚠️ 买两块独立带保护板的电芯直接并联**会出问题** |
| **P18** | 🟡 **电池仓尺寸重定**：**已定分置左右两侧** ⇒ **两处各约 10.5 × 56 × 68 mm**；机壳深度 ≥ **11 mm**（原 6.5×51×84 / ≥8.5–9 mm 作废） | ✅ 布置已定（用户 2026-09-17）；待更新 `docs/hardware-geometry.md` 的 G5 与 `docs/decisions.md` |

## 7. 相关决策记录

- **ADR-0007**：RGB LED 由电池直供，不加 5V 升压电路（本文件 §5.1 的结论）
- **ADR-0002**：BQ24072 充电做在主 PCB（本文件 §1 的电源路径管理依据）
- **ADR-0005**：Per-key RGB + PMOS 电源门控（⚠️ §5.4 发现其关断电路需要修正，见 P8）

**待新增 ADR**：✅ 两项均已落地，无遗留
- ~~物理断电方案（P7）~~ ⇒ **ADR-0010**
- ~~RGB 门控关断拓扑（P8）~~ ⇒ **ADR-0005**（拓扑 C），实现见 §3.1

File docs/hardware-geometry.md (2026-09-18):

# 键盘几何基准（已核验）

本文件记录 StarShield 的**物理几何事实**，作为 PCB 板框、定位板与 3D 打印外壳的共同基准。
所有数字均来自本仓库内文件的实际测量，标注了来源与核验方法。**未核验的内容写「❓ 待确认」，不猜测。**

状态：🟡 部分完成（布局几何已核验；PCB 板框、定位板与外框尺寸待定稿）

> ⚠️ **数据来源优先级**：以 `sketch/keyboard-layout.json`（KLE 源文件）为**唯一权威**。
> 渲染出的 `keyboard-layout.svg` / `.png` 仅用于视觉参考，**其像素尺寸不可用于反推键位宽度**
> （见第 1.5 节「一次错误测量的记录」）。

---

## 1. 键位布局（来自 `sketch/keyboard-layout.json`，KLE 格式）

- 键数：**95**（正确实现 KLE 坐标累积规则后解析得出；渲染 SVG 中 keycap 组亦为 95，两法一致）
- 键帽单位：**19.05 mm = 1u**（MX 标准，与 Apollo87H 参考板实测行距交叉验证一致）
- 旋转键位：**无**
- 键宽分布：1u ×83、1.25u ×3、1.5u ×4、1.75u ×2、2u ×1、2.25u ×1、**6.25u ×1（空格）**

### 1.1 总尺寸（键区）

| 项目 | 数值 |
| --- | --- |
| 总宽 | **19.25u = 366.71 mm**（KLE x 跨度 0.25 – 19.50）<br>⚠️ **2026-09-18 修正**：本表旧值「19.50u = 371.5 mm」是**错的** —— 把 x 起点 0.25u 当成了 0，虚增 **4.76 mm**。B4 按 `matrix.json` 实测重算并已用于 PCB/定位板 |
| 总深 | **6.25u = 119.1 mm** |
| 纵向特征 | F 行与第二行之间有 **0.25u 间隙**（对应参考板实测 23.81 mm = 1.25u 行距） |
| PCB 板框 | **374.71 × 151.06 mm** = 键区四周各 4 mm 边 + 顶部 **24 mm 控制肩**（放 nice!nano / 595 / 充电 IC，键区铺满放不下，见 §4 G2） |

### 1.2 逐行构成（x 坐标单位 u，KLE 原始坐标）

| 行 (Y) | 内容 | 键数 | x 范围 | 跨度 |
| --- | --- | --- | --- | --- |
| 0 | Esc, FN, NumLock, F1–F12, Delete | 16 | 0.25 – 19.50 | 19.25u |
| 1.25 | 小键盘 `/ * - +`, 主键区数字行（`` ` ``–`=`）, Backspace(2u) | 18 | 0.25 – 19.50 | 19.25u |
| 2.25 | 小键盘 `7 8 9`＋Delete(2u高), Tab(1.5u), QWERTY 行, Enter(1.5u×2u) | 18 | 0.25 – 19.50 | 19.25u |
| 3.25 | 小键盘 `4 5 6`, CapsLock(1.75u), ASDF 行 | 15 | 1.25 – 17.25 | 16.00u |
| 4.25 | 小键盘 Enter(2u高) `1 2 3`, Shift(2.25u), ZXCV 行, ↑, Shift(1.75u) | 17 | 0.25 – 19.50 | 19.25u |
| 5.25 | 小键盘 `0`(1.5u) `.`(1.5u), Ctrl/Win/Alt(各1.25u), **空格(6.25u)**, `\`, ←↓→, Ctrl | 11 | 1.25 – 19.50 | 18.25u |

⚠️ 第 3.25 行与第 5.25 行**左端起点不是 0.25u**（分别为 1.25u、1.25u），
即这两行在小键盘区域**没有键位**。这是小键盘 2u 高键造成的正常结果，规划 PCB 时须注意。

### 1.3 分区统计

| 分区 | 键数 | 组成 |
| --- | --- | --- |
| 主键区 | 52 | 数字行 13 + QWERTY 13 + ASDF 11 + ZXCV 10 + 底行（不含小键盘）5 ❓ |
| F 行 | 8 | Esc, FN, NumLock, Delete（F1–F12 属"功能区"，非主键区） |
| 小键盘 + 导航簇 | 35 | 见下 |
| **合计** | **95** | |

> 说明：本布局是「主键区 60 + 小键盘/导航 35」的组合，**不是**经典 104 键全尺寸
> （后者主键区为 61 键、小键盘为 17 键）。规划矩阵时须按本布局实际键数，不可套用 104 键方案。

### 1.4 大键位尺寸（KLE 权威值）

| 键 | 宽度 | 备注 |
| --- | --- | --- |
| 空格 | **6.25u** | ✅ 标准尺寸，市售键帽与标准卫星轴通用 |
| Backspace | 2u | |
| 左 Shift / 右 Shift | 2.25u / 1.75u | |
| Caps Lock | 1.75u | |
| Tab | 1.5u | |
| Enter（主键区） | **异形阶梯键**：上半 1.5u，下半 **2.25u** | ⚠️ **不是完整矩形**，见 §1.4.1 |
| 小键盘 `0` / `.` | 各 **1.5u** | |
| 小键盘 `/` `*` `-` `+` | 各 **1u** | ⚠️ **修正**：`+` 不是 2u —— KLE 里这四颗都**没有 `w` 属性**，均为 1u × 1u |
| 小键盘 Enter | **1u 宽 × 2u 高** | 竖跨 y=4.25–5.25，位于 x=0.25（小键盘**最左列**）|
| 小键盘 Delete | **1u 宽 × 2u 高** | 竖跨 y=2.25–4.25，位于 x=0.25 |
| 底行 Ctrl / Win / Alt | 各 1.25u | |

> 📌 **修正记录（2026-09-18）**：本表此前写了**两行**「小键盘 Enter」（1.5u × 2u 与 1u × 2u）。
> 已对照 KLE 权威源核实：**小键盘里只有一个 Enter，尺寸是 1u × 2u**
> （KLE 写法 `{"x":0.25,"h":2}`，无 `w` ⇒ 宽度取默认 1u）。
> 「1.5u 宽」那行是把主键区 Enter 的**上半段宽度**误套到了小键盘 Enter 上；
> 「Enter(左侧)」则是对同一个键的重复计数（小键盘本来就在板的左侧）。
> 同批修正：小键盘 `+` 由 2u 改为 1u。
> 交叉印证：`docs/matrix-assignment.md` §「2u 高键」一直写的就是
> 「小键盘 `Delete`、小键盘 `Enter`、主键区 `Enter`」三颗，与本表旧版不一致。

**结论：除主键区 Enter 外，全部键位均为标准矩形尺寸，无定制键帽需求。**

### 1.4.1 主键区 Enter 是异形阶梯键（定位板必须按此开孔）

KLE 源文件中该键带第二轮廓，写法为 `{"w":1.5,"h":2,"h2":1,"x2":-0.75,"y2":1}`：

| 部位 | x 范围 | 宽度 | y 范围 |
| --- | --- | --- | --- |
| 上半（第 2.25 行） | 18.00 – 19.50 | **1.5u** | 2.25 – 3.25 |
| 下半（第 3.25 行） | **17.25** – 19.50 | **2.25u** | 3.25 – 4.25 |

- 即第 3.25 行末键 `"` 右沿（x=17.25）到 x=18.00 之间那块 **0.75u 的空缺属于 Enter 本体**，不是空白区。
- 轴体/卫星轴铆点与开关**位于主矩形中心 x=18.75u**（未取合并区中心，理由见 `docs/_tools/matrix-assign.mjs` 注释：列分配按此中心排序，改动会重排整条矩阵）。
- ⚠️ **定位板开孔必须用合并后的轮廓**，不能按 `w_u=1.5` 画矩形——否则左侧 0.75u 实体会被当成废料挖掉。
- 机器可读值：`docs/_generated/matrix.json` 中 `index=52` 的 `stepped` / `x2_u` / `y2_u` / `w2_u` / `h2_u` / `unionX_u` / `unionW_u` 字段。
  ⚠️ **编号口径不同，别混用**：`matrix.json` 的 `index` 是 **1 起**（Enter = 52，共 95 个），
  而 keymap / transform 里的**位置号是 0 起**（Enter = 51）——
  两条链一致，但混用会差一位。核对时用「标签 + 行列」对，不要只对编号。

> 📌 教训（2）：生成器一度**静默丢弃** KLE 的 `x2/y2/w2/h2`，导致派生数据把它当成完整矩形。
> 现已修正并在遇到阶梯键时必须显式报出。异形轮廓属于 KLE 权威信息，下游不可假设「键都是矩形」。

**其余 5 个非标准键均为规则矩形**：Backspace 2u、左 Shift 2.25u、右 Shift 1.75u、Caps Lock 1.75u、空格 6.25u；
三颗「2u 高」的键是：**主键区 Enter（异形阶梯）**、**小键盘 Delete（1u × 2u）**、**小键盘 Enter（1u × 2u）**
—— 后两颗是**规则矩形**，非阶梯。
（⚠️ 本句旧版把「小键盘 Enter」数成了两颗 —— 「底行左侧 Enter」与「小键盘 Enter」是同一个键，见上表修正记录。）

### 1.5 一次错误测量的记录（教训，务必保留）

本文件初版曾记录「空格 = 6.33u，属非常规尺寸，需定制」。**该结论是错的**，成因有两处叠加：

1. **错误一**：用 SVF 渲染图的像素尺寸除以「键距」反推键宽。
   渲染图中 1u 键帽外框为 52px、键距为 53px。用 53px 作除数，得到 335.5/53 = 6.33u。
   正确做法：键帽宽度应除以**键帽宽 52px**，且渲染图本身存在非整数像素舍入，**根本不宜用于反推**。
2. **错误二（更严重）**：解析 KLE JSON 时未实现 KLE 的坐标累积规则。
   KLE 中 `x` / `y` 是**相对偏移，作用于其后的键位并持续累加**；错误实现导致
   总宽度算出 17.01u 而非 19.50u，并连带得出错误的分区与行结构。

**正确值（以 KLE 源文件解析为准）**：空格 = **6.25u**，键区 = **19.50u × 6.25u**。

> 📌 教训：**KLE JSON 是唯一权威，渲染图不可用于定量测量。** 解析 KLE 必须正确实现坐标累积。

---

## 2. 与 Apollo87H 参考基线的对比

参考工程：`hardware/pcb/reference/Apollo87H/`（无许可证，已在 `.gitignore` 中排除，仅本地学习）

### 2.1 参考板实测事实

核验方法：解析 `kicad_files/apollo87h.kicad_pcb` 中全部 501 个 footprint 的坐标。

| 项目 | 实测值 |
| --- | --- |
| 全部 footprint 外接矩形 | **341.30 mm × 114.05 mm** |
| 轴体 footprint 数（MX 系列） | **87** |
| 开关行 Y 坐标 | 79.02 / 102.83 / 121.88 / 140.93 / 159.98 / 179.03 mm |
| 行间距 | F 行→数字行 **23.81 mm**，其余各行为 **19.05 mm** |
| 安装孔 | 8 个，footprint `acheron_Hardware:9774035243R`（❓ 具体规格待查） |
| 安装孔坐标 (X, Y) | (31.598, 150.456) (38.598, 90.924) (164.948, 85.018) (180.729, 178.396) (250.673, 85.018) (294.805, 178.396) (343.548, 84.911) (363.211, 130.831) |
| 二极管 | 89 个 `D_SOD-123` |
| RGB LED | **87 个 `SK6812MINI_3535_6028_3.2x2.8mm_Round`**（per-key） |
| 热插拔座 | `MX100H` ×72、`MX125H` ×7、`MX150H` ×2、`MX200H` ×1、`MX225H` ×1、`MX275H` ×1 |
| USB 接口 | `TYPE-C-31-M-12` ×1 |
| 板载排针 | `PinHeader_1x16_P2.54mm_Vertical` ×1（控制器模块位） |

**关键交叉验证 ✅**：参考板 F 行→数字行间距 = 23.81 mm = 19.05 × 1.25，
与 StarShield KLE 中 F 行与第二行的 0.25u 间隙偏移**完全吻合**。
这独立确认了 1u = 19.05 mm 以及本布局的纵向几何模型。

### 2.2 差异

| | StarShield 95 键 | Apollo87H（87 键 TKL） | 差异 |
| --- | --- | --- | --- |
| 键区宽 | **366.71 mm**（19.25u） | — | — |
| PCB footprint 宽 | **374.71 mm** ✅ B4 定稿 | 341.30 mm | StarShield 约 **+33 mm** |
| PCB footprint 深 | **151.06 mm**（含顶部 24 mm 控制肩）✅ B4 定稿 | 114.05 mm | StarShield 约 **+37 mm** |
| 灯珠数 | 95 | 87 | +8 |
| 小键盘 | 有 | 无 | 需自行设计矩阵与走线 |

### 2.3 可借鉴 / 不可直接套用的部分

- ✅ 可借鉴：轴体与热插拔座 footprint、二极管 + SOD-123 的 1u 单元布局、SK6812MINI 灯珠摆位、安装孔规格与间距思路、Type-C 连接器选型。
- ❌ 不可直接套用：整体板框（宽约差 30 mm）、矩阵行列分配（参考板无小键盘）、控制器模块位置。
- ⚠️ 参考工程有 7 个 git submodule（第三方库）**未拉取**，因 SSH URL 未配置密钥。
  本项目几何研究因此改为**直接解析 `.kicad_pcb` 内嵌的 footprint 定义**取数（即本文所有数据的来源）。

---

## 3. 打印床约束

| 项目 | 数值 |
| --- | --- |
| 打印床 | 256 mm × 256 mm |
| 键盘键区 | **366.71 mm × 119.1 mm**（2026-09-18 修正，原记 371.5 mm 有误，见 §1.1） |
| PCB 外廓 | **374.71 × 151.06 mm**（含顶部 24 mm 控制肩） |
| 结论 | 🔴 **超出打印床长度，必须分件打印** |

### 3.1 🔴 修正：原倾向的「主键区一体 + 小键盘一体」两件式**几何上不成立**

本节此前倾向的方案是「主键区一体 + 小键盘一体」两件式。**该方案不可行**：

| 部件 | 跨度 | 毫米 | 加上两边留边（各 4 mm） | 能否放进 256 mm 床 |
| --- | --- | --- | --- | --- |
| 小键盘 + 导航簇（在**左侧**，x ≈ 0.25–4.25u） | 约 4u | 76.2 mm | 约 84 mm | ✅ |
| **主键区（x ≈ 4.5–19.5u）** | **15u** | **285.75 mm** | **约 294 mm** | ❌ **超床 38 mm** |
| 整体键区 | 19.25u | 371.5 mm | 约 379 mm | ❌ |

- ⚠️ **旋转摆放也救不回来**：294 × 130 mm 的件旋转 45° 后外接盒约
  `(294 + 130) / √2 ≈ 300 mm`，仍大于 256 mm ⇒ **必须再切一刀**。
- ⇒ 任何两件式方案都会把主键区拦腰截断一次；**想让主键区不被切断就必须三件以上**。

**⇒ 修正后的结论**：既然主键区无论如何都躲不过一道缝，就不必为它多切一刀 ——
**底壳按约等分两件（各约 190 × 127 mm）**，缝落在键位列边界上，
整体刚度由**整块 PCB** 桥接（PCB 是上盖，本身一整块，天然跨越接缝）。
这正好化解了本节原先「避免拦腰截断」的顾虑 —— 那个顾虑建立在「没有整块刚性件」的前提上。

> 📌 教训（3）：**分件方案要先算「每件的实际跨度」，不能只看总长。**
> 「主键区 + 小键盘」听起来是天然的分割，但主轴区本身（15u = 285.75 mm）就已超过打印床。
> 本修正已并入待定项 **G4**，完整取舍见 `docs/decision-package-2026-09-18.md`。

---

## 4. 待确定项（影响 PCB 板框与外壳）

| 编号 | 待定项 | 影响 | 状态 |
| --- | --- | --- | --- |
| G1 | ~~空格键最终宽度~~ | — | ✅ **已定：6.25u 标准尺寸** |
| G2 | PCB 板框相对键区的外扩量（每边留边） | 外壳内腔、螺丝柱位置 | ✅ **已定（用户 2026-09-18）：4 mm/边**；**2026-09-18 B4 定稿板框 = 374.71 × 151.06 mm**（键区 366.71 × 119.06 + 每边 4 mm + **顶部 24 mm 控制肩**）<br>⚠️ 控制肩的由来：键区**铺满无空位**，而 nice!nano 两条 1×12 排针需 31.5 × 18.8 mm 净空；放 PCB 背面也不可行（行距 19.05 mm 扣掉热插拔座后净空仅约 11 mm）。详见 `docs/_tools/pcb_design.py` |
| G3 | 安装孔数量与位置 | 定位板、外壳柱位 | ✅ **已定（2026-09-18 B4）：8 个 / M2 自攻 / NPTH 2.2 mm**，坐标在 `docs/_tools/pcb_design.py` 的 `HOLES` —— 全部落在键区块四周 2 mm 处（孔边离键区 ≥0.9 mm），且**都在定位板轮廓内 ⇒ PCB 与定位板共用同一组孔位** |
| G4 | 外壳分件方案（左右等分 / 主键区 + 小键盘） | 打印与组装 | 🟡 **用户 2026-09-18 定调：外壳分件 / 打印由用户自理，本项目只产出 3D 模型文件**。但几何事实仍需他知道：**主键区 15u = 285.75 mm > 打印床 256 mm** ⇒ 无论怎么分件，主键区至少要被切一刀（见 §3.1） |
| G5 | 电池仓尺寸 | 由电池型号决定 | ✅ **布置已定（用户 2026-09-17）：两块分置键盘左右两侧** ⇒ **两处各约 10.5 × 56 × 68 mm**、**机壳深 ≥11 mm**（原 6.5×51×84 / ≥8.5–9 mm 作废）；见 `docs/power-architecture.md` §3.6 |
| G6 | 定位板（plate）是否纳入第一版 | 成本、手感、加工方式 | ✅ **已定（用户 2026-09-18）：纳入第一版**。依据：已决定用热插拔座，热插拔座的常规用法配套定位板（插拔力与侧向力由定位板承担）；且能保证键帽高低一致。⚠️ 定位板开孔必须与 PCB 同源生成，异形 Enter 用 `unionX_u / unionW_u` |
| **G7** | **外壳为 nice!nano 板载 USB-C 开孔**（**刷固件的唯一通道**） | 底壳侧壁开孔位置 | ✅ **已定开孔（用户 2026-09-17）**；⚠️ **孔位待量测** —— nice!nano 插在插座上时其 USB-C 座相对 PCB 边缘的位置与朝向，**并入 B6 采购实物核对**（拿到实物前无法定孔位）。见 `docs/power-architecture.md` §4 |

---

## 5. 核验记录

| 日期 | 核验内容 | 方法 | 结果 |
| --- | --- | --- | --- |
| 2026-09-15 | 键数 = 95 | KLE JSON 解析 + 渲染 SVG keycap 组计数 | ✅ 两法均为 95 |
| 2026-09-15 | 总尺寸 19.50u × 6.25u | 正确实现 KLE 坐标累积规则后解析 | ✅ 右端 19.50u、底端 6.25u 自洽 |
| 2026-09-15 | 空格 = 6.25u | KLE 权威值；与「底行 Win 键右沿 +1.25u = 空格左沿」几何自洽校验 | ✅ 标准尺寸 |
| 2026-09-15 | 1u = 19.05 mm | 与 Apollo87H 实测行距 19.05 mm 交叉验证 | ✅ |
| 2026-09-15 | F 行 0.25u 间隙模型正确 | 参考板 F 行→数字行 = 23.81 mm = 1.25u | ✅ |
| 2026-09-15 | ~~空格 = 6.33u~~ | ~~SVG 像素 ÷ 53px~~ | ❌ **已推翻**，见第 1.5 节 |
| 2026-09-15 | ~~总尺寸 19.21u × 6.33u~~ | ~~SVG 像素测量~~ | ❌ **已推翻**，见第 1.5 节 |
| 2026-09-17 | 主键区 Enter 为异形阶梯键 | 读 KLE 的第二轮廓 `x2/y2/w2/h2`；对比第 3.25 行末键右沿 | ✅ 上半 1.5u@x=18、下半 2.25u@x=17.25；已同步进生成器与 `matrix.json` |
| 2026-09-18 | 键区 = **366.71 × 119.06 mm**（不是 371.5 mm） | `matrix.json` 的 x_u/y_u 极值 × 19.05 | ✅ B4 已按此生成 PCB 与定位板 |
| 2026-09-18 | 灯珠偏移 = 轴心 + (0, +5.08)；二极管 = 轴心 + (−8.33, +1.19) 旋 90° | 解析参考板 `apollo87h.kicad_pcb`，87 颗灯珠偏移 100% 一致 | ✅ 已用于 B4（二极管 x 取 −8.50 以加大余量） |
| 2026-09-18 | 自画 MX 封装原点 = 轴心 + (2.54, −5.08) | 8 档封装的 bbox 中心相对原点，8/8 一致 | ✅ 与官方 `SW_Cherry_MX_*_PCB` 的 pad1 位置交叉验证一致 |
| 2026-09-15 | 参考板尺寸 341.30 × 114.05 mm | 解析 501 个 footprint 坐标求外接矩形 | ✅ |
| 2026-09-15 | 参考板 8 个安装孔坐标 | 解析 `9774035243R` footprint 坐标 | ✅ |

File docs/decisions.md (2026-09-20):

# 设计决策日志

记录项目设计过程中所有已敲定的决策。格式为「主题 → 决策」。

## 产品定位

- **自定义维度**：布局 + 固件 + 硬件 + 开放平台（愿景）。第一版聚焦布局与固件。
- **受众**：开源给同好复刻，面向新手教程，未来可小批量售卖。
- **形态**：95 键紧凑全尺寸单体键盘（含独立小键盘与导航键簇）。（演变：分体 34 键 → 87 键 TKL → 95 键，见 ADR-0006。）
- **连接**：无线优先（BLE），USB-C 有线备用。

## 无线架构

- **固件**：ZMK。
- **无线方式**：第一版走 BLE Dongle 路线——Body 作为 BLE peripheral，经独立 Dongle 连接主机。
  **Dongle 形态已收紧为「BLE HID 主机」**（不是 ZMK 官方的分体 central）——后者会让键盘
  离开 Dongle 即变砖，且失去蓝牙/有线两个模式。见 **ADR-0001 修订**。
  ✅ 该架构**已有先例**（`roba-ble-hid-bridge` 等，键盘侧保持原版 ZMK），
  且已验证其低延迟机制（central 把连接间隔钉在 7.5 ms + 2M PHY）。
  ⚠️ **但这些项目的代码一律不可抄**：roBa 的 bridge 固件是
  `LicenseRef-Nordic-5-Clause`（且该许可**限制芯片**），其余项目**未声明许可证**。
  ⇒ **Dongle 固件必须自研**；倾向 **ESP32-S3 + ESP-IDF `esp_hidh`**（Apache-2.0）
  以避开 Nordic 许可证，代价是工作量。
  ⚠️ 通用「蓝牙转 USB」适配器**不存在** BLE HOGP 键盘版，无捷径可走。
  配对走 Just Works + LESC，**不要开启** `CONFIG_ZMK_BLE_PASSKEY_ENTRY`。
- **放弃真三模**：ZMK 不支持原生 2.4GHz 专有射频。⚠️ 本轮调研**加强了**这个决定：
  Keychron 的 2.4G 实现依赖**闭源二进制**（Nordic ESB 标注 `LicenseRef-Nordic-5-Clause`、
  Realtek 预编译库），ZMK 官方 FAQ 亦以**许可证**理由明确拒绝。
  ⇒ **障碍是法律而非技术**，本项目不应为此 fork ZMK。真 2.4GHz 推迟到后续版本。
  ⚠️ **末句已两次修正（2026-09-18）**：① 用户指出「键盘本来就是 nRF52840，Dongle 若也用 nRF52840，
  两端同芯片」⇒ **Nordic-5-Clause 允许用于 Nordic 芯片，法律障碍对本组合不成立**；
  ② **「ZMK 做不了 ESB / 零先例」也是错的** —— **Keychron 的官方 ZMK fork（`keychron_bpro` 分支）
  已商用化实现了第三条 ESB 输出**（nRF52840 自身射频、Zephyr 开源控制器 + RADIO 分时复用、
  扩展 outputs 行为、`&out OUT_24G`，单镜像免重刷；详见 `zmk-tri-mode-community-precedent.md` §4c
  与 **ADR-0001 修订段末的复核小节**）。
  ⇒ **结论不变**（第一版不做原生 2.4G），但理由改为「代价结构」而非「做不到/违法」：
  需 fork ZMK + 改 Zephyr + 自写传输/配对/跳频/省电 + 自写 Dongle 端（Keychron 的接收器疑似 Realtek），
  打破「新手用原版 ZMK 构建」的教程前提；触发条件 = v1 实测延迟不达标
- **「2.4G」的含义**：本项目所说的「2.4G」= **经 BLE Dongle 连接**（BLE 本身工作在 2.4GHz），
  **不是**原生 2.4GHz 专有射频。

## 硬件

- **控制器模块**：Body 用 nice!nano v2（SMT 版或通孔版均可）。
  **Dongle 用 ESP32-S3**（ESP-IDF 官方示例 `esp_hid_host` + `tusb_hid` 拼装，见 **ADR-0011**）。
  ⚠️ 本行旧值「Dongle 用 Seeed XIAO nRF52840」是 ADR-0011 之前的旧方案，**已废弃**
  —— 旧方案走 ZMK 分体 central 路线，会让键盘离开 Dongle 变砖且失去蓝牙/有线两档。
- **兼容性**：PCB footprint 同时兼容 nice!nano v2 与 SuperMini nRF52840。
- **焊接**：PCB 设计通孔焊盘 + Mill-Max 插座，模块可插拔。
- **轴体**：MX 轴 + 热插拔座。
- **充电**：BQ24072 做在主 PCB 上（线性充电 + 电源路径管理），不使用控制器模块板载充电。
  ⚠️ 本行旧值「1.5A 充电」指的是**芯片编程上限**；**实际已定 ≈1.0 A（ICHG）**，见下「充电电流」。
- **电池**：**10000mAh（2×5000mAh 并联，1S2P）** 3.7V LiPo，一体化包共用**一块**保护板。接口 JST-PH 2.0。
- **连接模式开关**：三档拨片开关（SP3T）选择 **2.4G（Dongle）/ 蓝牙 / 有线**。
  用 ZMK 上游原生机制读取（`zmk,kscan-gpio-direct` + `toggle-mode` + `zmk,kscan-sideband-behaviors`），
  键盘侧零自定义固件。见 **ADR-0009**（🟡 提议，待确认）。
- **电源开关**：⚠️ 原计划「SPDT 滑动开关物理切断电池」**已被推翻**。
  **用户决定：走成熟路线，不设任何电池断电开关。**
  - 电池在**有线档也保持接通**（与 Keychron K8 Max 等成熟三模产品一致）
  - **「关机」= 拨到有线档 + 拔掉 USB 线**，再由 ZMK 电源管理接手
    （空闲 30 s → idle；15 min → 深睡，深睡时尽可能关闭 external power）
  - 长期存放：**拔 JST 插头**
  - ⇒ 充电 IC **保持 `BQ24072` 不变**（不需要 `SYSOFF`，也不需要 `2N7002`）
  - ⇒ 模式开关**回到单刀 `SP3T`**（不需要双刀 `DP3T`）
  - 依据：P7 的全部难点来自「开关要扛 2.4 A」，**不设开关则问题不存在**；
    深睡待机约 20 µA，断电开关对续航无实质贡献
  - 记录见 **ADR-0010**（已决定；曾考虑的「模式档兼作断电」作为研究记录保留）
- **矩阵**：Apollo87H 仅覆盖主键区（其为 87 键 TKL，无小键盘）；95 键矩阵含小键盘与导航区，需自行规划。

## RGB 灯效

- **类型**：Per-key RGB（每键独立发光），95 颗可寻址 LED（选用 SK6812MINI-E，LCSC C5149201）。
- **供电**：**由电池直接供电，不加 5V 升压电路**（见 ADR-0007）。所选灯珠工作电压 3.7–5.5V，
  电池区间 3.7–4.2V 落在范围内；代价是电池低于 3.7V 后亮度/颜色略衰减。
- **控制方式**：组合键控制开关/亮度/色相/饱和度/灯效/速度，对齐商业键盘体验。
- **省电设计（必须）**：RGB 供电回路上串联 PMOS 晶体管，由主控 GPIO 控制（ZMK 外部电源控制 / ext-power）。
  RGB 关闭或深度睡眠时物理切断供电。⚠️ 实测灯珠**静态电流 0.6mA/颗 × 95 ≈ 57mA**
  （原估「约 95mA」偏高，但结论不变：必须门控）。
- **峰值电流**：12mA/通道 × 3 × 95 ≈ **3.4A**（100% 灰阶）；按厂家建议 70% 灰阶约 **2.4A**。
  ⚠️ 这**超过 JST-PH 2.0 的 2A 额定**，需在 PCB 阶段处置（限亮度或改连接方式）。
- **固件**：ZMK RGB underglow + per-key 扩展；启用闲置自动关闭；建议低电量时下调亮度上限。
- **功耗权衡**：RGB 全开时续航以小时计；关闭时以月计。大容量电池（**10000mAh**）缓解但不可消除。

## 电源

- **充电器**：BQ24072（TI），线性充电 + **电源路径管理**。见 ADR-0002。
- **拓扑要点**：电池只接 `BAT` 引脚；**系统负载必须接 `OUT`**，由 IN/BAT 中较高者供电。
  若把负载挂到 `BAT` 上会绕过电源路径管理，退化回 ADR-0002 要避免的「边充边放」。
  详见 `docs/power-architecture.md`。
  - ⚠️ **2026-09-19 修正（方案①）**：**唯一例外 = nice!nano 模块的 `B+/RAW` 改接 `VBAT`**。
    原因是「有线模式下要能充电」：模块自带充电器的输出在 `B+/RAW`，接 `OUT` 时其电流进不了电池。
    模块电流极小（休眠 20 µA 级），不违背本节对**重载**的限制（VLED 等仍接 `OUT`）。
    代价：「不装电池、只插充电口」时模块不上电（须插模块口）。
    依据：`docs/nice-nano-physical-verification.md` §6.6。
- **充电电流**：⚠️ 本节旧值「1.5A ÷ 3.0Ah = 0.5C」建立在 **3000 mAh** 电池上，**已被推翻**。
  现况：电池 **10000 mAh（2×5000 并联）** ⇒ **ICHG ≈ 1.0 A = 0.10C**（`R_ISET` = **887 Ω**，
  输入走 ILIM 档 ≈1.0 A），充满约 **10 h**；**1.5 A 只是芯片编程上限**，不是本板能拿到的电流
  （线性充电 1.0 A 时耗散约 1.3 W，`Tj` ≈ 83 °C）。
  论证与商用对标见 `docs/power-architecture.md` §3.1 / §3.7。
- **物理断电**：⚠️ 原「SPDT 串在电池→BAT 之间，额定 ≥2A」的方案**已推翻**。
  **现方案：不设电池断电开关**（用户决定，走成熟路线）。充电 IC 保持 `BQ24072`，
  电池始终接通；关机 = 有线档 + 拔线 + ZMK 深睡；存放 = 拔 JST。见 **ADR-0010**（已决定）。
- **USB-C**：5.1k CC1/CC2 下拉（UFP 设备）。D+/D- 是否接入待定（见 `docs/power-architecture.md` §4）。

## 结构件

- **外壳**：纯 3D 打印。PCB 当上盖，3D 打印底壳容纳电池与电路。
- **打印床**：256mm × 256mm，外壳需分件。
- **Dongle 外壳**：极简 3D 打印，预留复位按钮开孔。
- **屏幕**：第一版不装。
- **RGB**：第一版包含 per-key RGB（见「RGB 灯效」）。
- **外壳结构取值（2026-09-21，改为「对标调研」定值，依据 `docs/case-benchmark.md`）**：
  - **开口朝向**：三处开孔在**键盘左侧（后上）**——用户 2026-09-21 明确「开口就在键盘左侧就行」；
    模型坐标因此 = `X=x_board`、`Y=(by0+by1)−y_board`（**y 取反、x 不取反**）。
  - **板下净空 15.0** = 插拔座 **1.8**（Kailh 原厂图纸 1.80±0.05，非假设）+ 压边 2.0 + 电池 10.5 + 余量 0.7。
  - **定位板**：板面 = PCB **+5.0**、板厚 **1.5**、开孔 **14×14**（Cherry MX 图纸）；板的高度由轴体锁定，外壳只需让开。
  - **紧固**：**M2 热熔螺母**（柱 φ6.4 / 孔 3.0×5.0 / 嵌件 OD3.2×L4）——判据是「反复拆装用螺母」，本项目要反复开壳。
  - **倾角 5.5°**（商业/社区 5–7°，Keychron Q1 官方 5.2°）；**脚垫 Ø8×3 硅胶自粘**。
  - **分件缝**：加 **Ø4×8 定位销 ×3、单边 0.2 mm**（缝长 155.7 mm ≫ 手工对齐判据 80 mm）。
  - **不上边框**（低-profile；`lip`=4.5 ⇒ 恰在板面下 0.5）；若要高-profile 则 `lip` 9.5–11.0。

## 工具与流程

- **PCB 设计**：KiCad。
- **外壳设计**：Fusion 360（参数化建模，便于与 PCB 安装孔/开孔精确对齐）。
- **参考基线**：Apollo87H（主键区物理布局）；VoidPointer / Keeb68（电气与矩阵参考）。小键盘区无现成参考，需自行设计。
- **固件构建**：GitHub Actions build matrix，分别编译 Body 与 Dongle。

## 许可

- **开源许可证**：CERN-OHL-S-2.0（强互惠开源硬件许可证）。衍生产品必须同样开源并公开完整设计文件。

## 固件

- **三档模式开关读取**：用 ZMK 上游原生机制 —— `zmk,kscan-gpio-direct` 的 `toggle-mode`
  + `zmk,kscan-sideband-behaviors`（`auto-enable`），**键盘侧零自定义固件**。见 ADR-0009。
- **`CONFIG_ZMK_USB_BOOT=y` 开启**：让有线模式支持 BIOS/Boot Protocol。零成本，
  顺带消除「必须靠 Dongle 才能进 BIOS」这一伪需求。
- **加 `&soft_off` 绑定**：提供「立刻关机」而不必等 15 分钟空闲深睡。ZMK 原生、零硬件成本。
- **Dongle 固件**：**ESP32-S3 + ESP-IDF 官方示例**（`esp_hid_host` + `tusb_hid`，均 Apache-2.0）。
  ⚠️ **不移植任何第三方 Dongle 工程** —— 小尺寸的几个实现全部无许可证或 Nordic-5-Clause 限制，
  抄了会破坏 CERN-OHL-S 许可链。见 **ADR-0011**。
- **Dongle 侧注意事项**：`CONFIG_BT_GATTC_NOTIF_REG_MAX` 必须调大（默认 5 会静默丢弃
  键盘的 INPUT report 订阅）；配对走 Just Works，**不要开** `CONFIG_ZMK_BLE_PASSKEY_ENTRY`。

## 已决定的其他事项（2026-09）

- **RGB 门控拓扑**：`2N7002` + `AO3401A` 反相级、`GPIO_ACTIVE_HIGH`，**照抄 `kurtis-lew/Conejo`**
  （不要照抄 ZMK 硬件设计指南的 Q3，它 S/D 画反了）。见 ADR-0005。
- **模式开关料号**：**`C&K PCM13`**（KiCad 官方封装 `SW_SP3T_PCM13` 现成）。
  ⚠️ 禁用 E-Switch `EG1312AR`（第三档是瞬时的）。见 ADR-0009。
- **充电 IC 保持 `BQ24072`**（不换 `BQ24075`，不需要 `2N7002`）。见 ADR-0002 修订。
- **SuperMini 降级为「焊盘兼容、不保证」**：电池 ADC 脚冲突且不被 ZMK 官方支持，
  第一版只保证 nice!nano v2。见 ADR-0003 修订。

## 待定

### 🔴 仍需用户决策

- 🆕 **B6a：热插拔座封装与轴孔直径（2026-09-21 调研发现，影响投板，优先级最高）**：
  Kailh 官方规格书第 9 节「Recommended PCB Layout」给的是 **φ3.00 孔 @ 6.35 间距 + 4 个 2.55×2.5 侧焊盘**，
  社区文档亦明说「轴引脚原本的孔**要更大**，座体填满两个大孔」；
  而我们的自画封装（`docs/_tools/gen_footprints.py`）保留 **1.27 PTH 轴孔** + B.Cu 侧焊盘，并标了 UNVERIFIED。
  ⇒ **「直焊 PTH / 热插拔 SMD 二选一」在 1.27 mm 孔上不成立**。三条路（需拍板，建议 ③）：
  ① 只做热插拔（φ3.0 孔，放弃直焊兜底）；② 改 **Mill-Max 直插座**（保留 1.27 孔，但需另买件、且要手焊）；
  ③ **先买一粒座 + 一小块测试板实测**再定（最省事、风险最低）。依据见 `docs/case-benchmark.md` §4.1
- 🆕 **电池座额定电流 2 A vs RGB 峰值 2.4 A**：JST PH 官方额定 **2 A (AWG#24)**
  （`docs/power-architecture.md` 记的 RGB 全亮峰值 2.4 A）。属「惯例允许但需自担」的边界：
  接受（峰值瞬时、非持续满载）／换 XH 2.5 等更大连接器／给 RGB 限亮。依据见 `docs/case-benchmark.md` §4.2
- ~~**P15 `F1` 保险丝额定值**~~ ⇒ ✅ **已定案（2026-09-18）：2 A hold 的 1812 自恢复保险丝（`MF-MSMF200`）**。
  取值史 500 mA → 1.5 A → **2 A**。⚠️ **1.5 A 被否决**：Bourns MF-MSMF 降额表显示 `MF-MSMF150/24X`
  在 **60 °C 环境下降额后 Ihold 仅 1.00 A**，恰好等于工作电流 ⇒ 零余量；70 °C 时 0.88 A ⇒ 会误断。
  2 A 档 60 °C 仍 1.50 A（余量 50%）、85 °C 1.25 A（余量 25%）。压降最大 80 mV ⇒ 输入 ≥4.92 V，
  远高于 VIN-DPM 上限 4.63 V。封装 0603 → **1812**（`Fuse:Fuse_1812_4532Metric` 已核实存在）。
  🟡 残留：LCSC 料号待 BOM 补；若要求 ≥16 V 需另选 2 A/16 V 的 1812 PTC
- **几何项**：🟡 **G2 / G6 已定（2026-09-18）**（见下「已决策」）；**G3** 只定数量与规格
  （8 个 / M2），坐标留 B4；**G4** 改为「用户自理分件 / 打印，本项目只产出 3D 模型文件」。
  逐项分析（含 **G4 原倾向「主键区 + 小键盘」在几何上不成立** 的论证）见
  **`docs/decision-package-2026-09-18.md`**
- **固件侧**：~~`C6` 是否并行用树莓派 MIT 方案先验证 Dongle 链路~~ ⇒ **已定（2026-09-18）：不做**
  （用户：树莓派成本太高）。该风险改由「C5 实现后直接实测」承接 —— 详见下「已决策」
- **Dongle 架构（方案 A：ESP32-S3 BLE vs 方案 B：nRF52 ESB）** ⇒ 🟡 **已定（2026-09-18）：先验证再定**
  —— 用户拍板按 **C7** 验证 `efogdev/zmk-esb-endpoint` 的 nRF52840 移植
  （计划见 `docs/esb-endpoint-validation.md`），通过走 B、失败走 A；B2 不受影响

### ✅ 已决策（已关闭，勿再当待定）

- 🆕 ~~外壳开口朝向（x 是否取反）~~ ⇒ ✅ **已定（用户 2026-09-21）：「开口就在键盘左侧就行」**
  ⇒ 模型 = `X=x_board`、`Y=(by0+by1)−y_board`（y 取反、x 不取反），与 02:31 那次修好的朝向一致。
- 🆕 ~~外壳结构 6 项待定值（座高/板距/边框/引线/脚垫/接缝）~~ ⇒ ✅ **已定（2026-09-21）：按对标调研定值** ——
  全部依据与来源等级见 **`docs/case-benchmark.md`**，参数落表见其 §7；要点：
  座占高 **1.8**（Kailh 图纸）、板面 **+5.0**/板厚 **1.5**/孔 **14×14**（Cherry 图纸）、**M2 热熔螺母**柱、
  倾角 **5.5°** + 脚垫 **Ø8×3**、缝销 **Ø4×8 @0.2 单边**、压边过线缺口 **3.0**、**不上边框**（低-profile）。
  ⚠️ 遗留两项待实测（已在 `docs/case-benchmark.md` §6 写明）：**实物座高**复核、**USB-C 线缆外壳宽度**。

- ~~`C6` 是否并行用树莓派 MIT 方案先验证 Dongle 链路~~ ⇒ ✅ **已定（用户 2026-09-18）：不做**
  —— 树莓派 Zero 2 W + 配件成本太高，不值得为一项「架构验证」专门采购。
  ⚠️ 代价要记清：ADR-0011 最大的未验证项（`esp_hidh` 能否正确解析 **真实 ZMK 键盘** 的
  HID 报告描述符）**失去了一个低成本提前验证的机会**，只能等 C5 写完 Dongle 固件后直接实测。
  ⇒ 若届时实测失败，备选仍回到 ADR-0011 附录 B 盘点的几条路线（nRF52840 / ESP32-C3+CH9329，
  均有许可证障碍）⇒ **建议 C5 一开始就买一颗 ESP32-S3 最小系统板**，把验证提前到「能用 devkit 跑通」
  的最早时刻，而不是等到 B2/B4 全部完成之后
- **Dongle 芯片盘点（2026-09-18 调研，佐证 ADR-0011）**：量产键盘的 2.4G 接收器几乎全是
  **专有协议 + 同厂商配套 SoC**（Telink TLSR8208/8355/8373/8666 为主、Nordic nRF52 次之、
  TI CC254x/CC264x 较老）；**「BLE HID 主机式 Dongle」在量产界没有先例** —— 我们走这条路
  是 ZMK 生态约束（ADR-0001）下的必然，与「大电池无开源先例」同类。
  Telink 官方 Dongle 模式电流 **27 mA**，佐证 USB 供电 dongle 耗 20–30 mA 属行业常态
  （我们 ESP32-S3 估 15–25 mA 不异常）。完整盘点见 **`docs/adr/0011` 附录 B**

- ~~`C4` 是否引入 ZMK Studio~~ ⇒ ✅ **已定（用户 2026-09-18）：暂不启用**。
  理由：① 启用机制在 ZMK v0.3.0 与 main 之间不一致（文档写 `studio-rpc-usb-uart` snippet，
  本地 main 克隆里无该目录，而是 Kconfig `ZMK_STUDIO_TRANSPORT_UART`）⇒ 需先按 v0.3.0 实测；
  ② Studio 构建强制 `ZMK_BEHAVIORS_KEEP_ALL` ⇒ 固件变大；③ 走 USB，而 USB 通道依赖
  **未量测**的 G7 开孔。**前提已备好**：95 键 physical layout（`physical_layout0` 的 `keys` 属性）
  已由 `gen_transform.mjs` 派生 ⇒ 将来启用只差两行配置，届时单独评估。
  改键位不受影响：改 `starshield.keymap` → 推 CI → 下载新固件

- ~~`G2` PCB 板框外扩量~~ ⇒ ✅ **已定（2026-09-18）：4 mm/边** ⇒ PCB 约 **379 × 127 mm**。
  ⚠️ 仍可能与 G7（nice!nano USB-C 开孔）联动微调
- ~~`G6` 定位板是否纳入第一版~~ ⇒ ✅ **已定（2026-09-18）：纳入**。
  依据：已决定用热插拔座，其常规用法配套定位板（插拔力/侧向力由定位板承担），
  且能保证键帽高低一致。开孔必须与 PCB 同源生成，异形 Enter 用 `unionX_u / unionW_u`
- ~~`ZMK config` 是否独立仓库~~ ⇒ ✅ **已定（2026-09-18）：不拆**，维持单仓库。
  理由：CI 已跑通不动不冒风险；新手教程只需一次 `git clone`；许可证链与「一块板一个仓库」直觉一致。
  ⚠️ 「补 `zephyr/module.yml` 支持以 module 方式被别人引入」存在结构冲突未解决
  （module 根目前是 `firmware/`，而 `west.yml` 写的是 `self: path: config`），暂不做
- **`G4` 外壳分件 / 打印** ⇒ **用户 2026-09-18 定调：由用户自理，本项目只产出 3D 模型文件**。
  需要他知道的事实：**主键区 15u = 285.75 mm > 打印床 256 mm** ⇒ 主键区至少要被切一刀
  （论证见 `docs/hardware-geometry.md` §3.1）

- ~~`P12` 是否开启 `ZMK_RGB_UNDERGLOW_EXT_POWER`~~ ⇒ ✅ **已开启且早已落地**
  （`firmware/boards/shields/starshield/starshield.conf` 第 31 行
  `CONFIG_ZMK_RGB_UNDERGLOW_EXT_POWER=y`）。**此前挂在待定清单里是文档滞后，不是没做。**
  语义：RGB 开关联动 `ext-power`，关灯时物理切断 LED 供电（ADR-0005）。
  ⚠️ 前置依赖 `CONFIG_ZMK_EXT_POWER=y` 亦已开启。

- ~~充电电流档位（P13）~~ ⇒ **已定（2026-09-18）：切到 ILIM 档 —— 输入 ≈1.0 A、充电 ≈1.0 A
  （0.10C）、充满约 10 h**。`EN2=OUT`/`EN1=GND`、`R_ILIM` 1.6 kΩ、`R_ISET` 887 Ω、
  `F1` **2 A hold**（P13 定案时的 1.5 A 已被 P15 降额复核否决，见下）。
  ⚠️ **这是本项目唯一主动超出 USB-C 声明之处**（5.1 kΩ 只声明 500 mA）—— 依据是商用同容量
  产品的实测充电区间 **0.035–0.163C**，而 0.5 A 只有 0.049C（下三分之一）。
  见 `docs/power-architecture.md` §3.7 与 `research/large-battery-keyboard-charging-current.md`
- ~~外壳如何让 nice!nano 的 USB-C 可访问~~ ⇒ **已定（2026-09-17）：底壳侧壁开孔**。
  刷固件的唯一通道；孔位待量测 nice!nano 实物（并入 B6）。见 `docs/power-architecture.md` §4
- ~~是否启用电池温度保护~~ ⇒ **已定（2026-09-17）：维持禁用**（`R5` = 10 kΩ）。
  旁证：ZMK 参考板 nRFMicro 亦无温测（2 脚电池座 + 官方规格 `Temperature Monitor: No`）。见 §3.3
- ~~电池仓布置方式~~ ⇒ **已定（2026-09-17）：分置键盘左右两侧**，两处各约 10.5×56×68mm、
  机壳深 ≥11mm（配重更均衡，AULA 同做法）。见 §3.6
- ~~是否保留 SuperMini 兼容路线~~ ⇒ **已决（ADR-0003 修订 + 决策章节）**：
  第一版按 nice!nano v2 设计并保证；SuperMini 仅「焊盘兼容、不保证」，其电池 ADC 脚不布线
- ~~USB-C 的 D+/D- 是否接入~~ ⇒ **已决（2026-09-17 核实）**：**不接入**，`J1` 只做充电
  （nRF52840 的 USB D+/D- 是独立专用引脚，排针上不存在）
- ~~BQ24072 的 TS 引脚处置~~ ⇒ **已决**：`R5` = 10 kΩ 到 VSS 禁用温测（数据手册认可），见 §3.3
- ~~电池型号与尺寸（容量部分）~~ ⇒ **已决（2026-09-17）**：2×5000 mAh 并联 = 10000 mAh；
  采购要求见 `docs/power-architecture.md` §3.6（⚠️ **采购落地仍待做**，见 P17）

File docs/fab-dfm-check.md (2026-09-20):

# 投板前工艺核对（DFM）+ 下单规格

**日期**：2026-09-20
**触发**：DRC 里 4 条 `drill_out_of_range` 的豁免理由写着「投板前按厂家最小孔径确认」——
本文就是那次确认。**DRC 查的是「我们的设计规则」，DFM 查的是「厂家能不能做」，两回事。**

**判据来源（一手）**

| 来源 | 用途 | 等级 |
| --- | --- | --- |
| 《嘉立创制造工艺要求》`https://www.jlc.com/portal/1/serviceGuide`（2026-09-20 取用） | 孔径 / 线路 / 阻焊 / 字符 / 外形全部限值 | **[DOC]** 厂家官方 |
| 嘉立创官方博客《PCB Design Verification Guide》《PCB Layout Process Guide 2026》 | 交叉印证：4 层最小线宽线隙 0.09、最小过孔外径 0.45、丝印自动裁剪口径 | **[DOC]** |
| 本板实测（`docs/_tools/dfm_check.py`，可重跑） | 我们的实际值 | **[SRC]** |

---

## 1. 结论速览

1. ✅ **无「不通过」项，可以投板。** 10 项量测里 6 项直接通过、3 项需确认、1 项非阻塞。
2. ⚠️ **需确认项 1+2 是同一个根因**：`U1`（BQ24072，VQFN 带散热焊盘）用的是 KiCad 官方
   `VQFN-16-1EP_..._ThermalVias` 封装，它把散热焊盘里的 **4 个散热过孔建模为 PTH 焊盘**
   （0.20 钻孔 / 0.50 焊盘），于是撞上「**除过孔外的插件孔最小 0.5 mm**」与「**插件孔焊环极限 0.18**」。
   就几何而言它们是散热过孔（周围全是同网络铜，没有元件引脚穿过）⇒ **按过孔判全部达标**
   （内径 0.20 = 下限、外径 0.50 ≥ 0.45、焊环 0.15 ≥ 0.0762）。
   - **答复话术（若下单被 EQ 询问）**：*「U1 的 4 个 0.2 mm 孔是散热焊盘内的散热过孔（thermal via），
     不是元件引脚孔；该封装为 KiCad 官方库标准封装，请按过孔工艺处理。」*
   - ⛔ **不建议**把它改成 0.3 mm 钻孔：该封装刻意用 0.20 小孔**抑制焊接时锡膏从孔下漏**，
     改大会让新手手焊更难（EP 是必须焊的散热焊盘）。
3. ⚠️ **需确认项 3：内层过孔到铜面间隙。** 厂家要求「内层过孔边到线路铜面/导线间隙 0.3 mm 以上」。
   本板按**过孔环边**量有 **499 处落在 0.201–0.283 mm**（主要来自键区灯珠焊盘 ↔ 平面过孔的密集处：
   GND 238 / VLED 209，配对类型 457 处为「焊盘↔过孔」）。
   但若厂家指的是**钻孔边**，则实际是 0.30 + 0.15(环宽) = **0.35–0.43 mm ⇒ 达标**。
   两种解读结论相反 ⇒ 下单时如被询问，按上一条同样口径答复；**不建议为此重布**（见 §4）。
4. ℹ️ **非阻塞项：丝印最小字符高 0.800 mm**（厂家 ≥1.0）。厂家口径是「字粗不够的加宽、
   压在焊盘上的掏掉，其它不特别处理」⇒ 偏小的字可能印不清。**键盘丝印被定位板与键帽遮挡**，
   收益极低，不改。
5. ℹ️ **丝印压焊盘 111 处 / 丝印重叠 199 处**：厂家 CAM **会自动掏空压在焊盘上的字符** ⇒
   不影响投板（这也是我们 DRC 里把 `silk_*` 整类豁免的理由，现由厂家官方口径佐证）。
6. ℹ️ **阻焊开窗**：本板 `pad_to_mask_clearance = 0`（KiCad 惯例），厂家**自动单边扩 0.05 mm** ⇒
   不需要我们改；`pad_to_mask_clearance` 保持 0 是对的。

---

## 2. 核对表（本板 vs 厂家限值）

| 项目 | 本板 | 厂家限值 | 判定 |
| --- | --- | --- | --- |
| 最小线宽 | **0.150** | 0.09（4/6 层） | ✅ |
| 最小线隙 | （DRC clearance 0.2，无违规） | 0.09 | ✅ |
| 过孔内径 | **0.300**（散热过孔 0.20） | 0.20 | ✅ |
| 过孔外径 | 0.600（散热过孔 0.50） | 0.45（极限 0.40） | ✅ |
| 过孔焊环 | **0.150** | 0.0762 | ✅ |
| 插件孔最小孔径 | 0.200（= U1 散热过孔） | 0.50（元件引脚孔） | ⚠️ 需确认（归类） |
| 插件孔最小焊环 | 0.150（= U1 散热过孔） | 建议 0.25 / 极限 0.18 | ⚠️ 需确认（归类） |
| NPTH 最小孔径 | 0.650 | 0.50 | ✅ |
| 焊盘到板边 | **1.120** | 0.30 | ✅ |
| 孔到孔 | DRC `hole_to_hole` 0 违规 | 0.254（过孔）/0.45（插件孔） | ✅ |
| 丝印最小线宽 | 0.150 | 0.15 | ✅ |
| 丝印最小字符高 | 0.800 | 1.0 | ℹ️ 非阻塞 |
| 内层过孔到铜面 | 0.201–0.283（环边）/ 0.35–0.43（钻孔边） | 0.30 | ⚠️ 需确认（解读） |
| 板尺寸 | 374.81 × 151.16 mm | ≥5 mm | ✅ |

复跑：`cd /d/Kicad/bin && ./python.exe D:/StarShield/docs/_tools/dfm_check.py`

---

## 3. 下单规格（建议，依据 = 板文件里的 `(stackup)` 与既有设计决定）

| 项 | 取值 | 依据 |
| --- | --- | --- |
| 层数 / 板厚 | **4 层 / 1.6 mm** | `(general (thickness 1.6))` + `(stackup)` |
| 铜厚 | **外层 1 oz（0.035）、内层 0.5 oz（0.0152）** | 板文件 `(stackup)`；内层 0.5 oz 经瓶颈分析证明足够（见 `research/power-trace-width-precedent.md` §0.5） |
| 过孔 | 盖油（`(tenting front back)`）；主用 0.60/0.30 | 板文件 |
| 阻焊开窗 | 由厂家自动单边扩 0.05 | 厂家口径 |
| 阻抗控制 | **不需要**（无高速差分对） | 设计内无 USB 差分（USB 只在模块与外壳口之间，且模块自带座） |
| 拼板 | 单板交货（374.8 × 151.2 mm） | 板尺寸；如需拼板由厂家工程处理 |
| 表面处理 | **未在板文件固化**（`copper_finish "None"`）⇒ 建议**沉金（ENIG）**：细间距 QFN 与手焊润湿性更好；预算紧可用喷锡 | 建议项，非实测结论 |

---

## 4. 投板文件包：已可一键生成 ✅

```bash
python docs/_tools/export_fab.py          # 输出到 hardware/pcb/StarShield/fab/
```

产物（实测，2026-09-20）：

| 文件 | 说明 |
| --- | --- |
| `gerbers/Starshield-*.gbr` ×11 | 4 铜层 + 2 阻焊 + 2 丝印 + 2 钢网 + 外形（厂家要求 ≥7 个） |
| `gerbers/Starshield-PTH.drl` / `-NPTH.drl` | Excellon，**PTH / NPTH 分开**、mm、小数点格式 |
| `gerbers/Starshield-job.gbrjob` | Gerber Job 元数据（层叠/材料，X2 规范） |
| `StarShield-gerbers.zip` | **可直接上传代工厂**（1.75 MB，含上述 14 个文件） |
| `BOM-Starshield.csv` | 313 个元件的分组 BOM（`kicad-cli sch export bom`，从根图导出含全部子图） |
| `CPL-Starshield.csv` | 贴片坐标（手焊不需要，留给日后 PCBA；按社区惯例命名） |
| `ORDER_SPEC.md` | 下单规格 + 被 EQ 询问时的答复话术（即本文 §3 与 §1 的摘录） |

### ⚠️ 为什么不把投板产物入库

**实测：同一块板连导两次，14/14 个文件逐字节都不同** —— gerber 头部（X2 属性）与 `.gbrjob`
里带创建时间戳。入库会让本项目的硬判据「重跑生成器后 `git status` 对 tracked 文件无差异」
永远失败。因此 `.gitignore` 里忽略了 `hardware/pcb/StarShield/fab/`。

> 社区常见做法是把 gerber 一并提交（本机样本里有 235 个 zip/仓库），那是**拿确定性换便利**；
> 本仓库选确定性。要把成品给复刻者时，**把 zip 挂到 GitHub Release 附件**（不占仓库历史）。

### 复核与踩坑

- **第三方 gerber 复核**（成熟做法）：用独立查看器（KiCad Gerber Viewer / `gerbv` / 在线）
  确认外形层、槽孔、自定义焊盘渲染无误，再提交订单。
- ⚠️ **kicad-cli 用 Windows 版时不要喂 MSYS 风格路径**（`/d/StarShield/...`）——
  会报「原理图文件不存在或无法访问 / 加载原理图失败」，看着像文件坏了，其实是路径方言问题。
  脚本内部已统一用绝对 Windows 路径。
- ⚠️ 导 BOM 时 kicad-cli 会提示「原理图存在批注错误」。已逐项排查：**全工程 0 个未批注位号**
  （`Reference` 无 `?`）、BOM 共 313 件与 321 个封装（含 8 个安装孔）自洽 ⇒ **属提示误报**。

### 顺带修掉的一个可复刻性缺口

本工程原先**没有 `fp-lib-table`** ⇒ 任何人克隆后打开工程，ERC 都会报 95 条
`footprint_link_issues`（「当前配置中不包含封装库 'StarShield'」），因为自画的
MX 热插拔座封装库没有被映射。已按社区成熟写法（参考 Apollo87H 的同名文件）补上
`hardware/pcb/StarShield/fp-lib-table`，指向 `${KIPRJMOD}/footprints/StarShield.pretty`。
**复核结果：ER-C 里 `footprint_link_issues` 95 → 0。**
（符号侧用的是 KiCad 官方库 —— 74xx / Battery_Management / Connector / Device / LED /
Switch / Transistor_FET / power ⇒ 不需要 `sym-lib-table`。）

**为什么不为「内层过孔 0.3 mm」重布**（成本对照）：

| 方案 | 代价 | 收益 |
| --- | --- | --- |
| 接受现状（推荐） | 0 | 若厂家按钻孔边判 ⇒ 已达标；若按环边判 ⇒ 属其**建议值**而非绝对能力（其绝对下限 0.09），仍有 2.2× 余量 |
| 把内层 clearance 提到 0.3 并重布 | 全板重布 + 再验证（键区高密度处可能无法收敛）；此前 B4/B6-2 两轮布线成果大部分作废 | 消除该「需确认」项 |
| 只有确实被厂家退回时才做 | — | — |

---

## 5. 诚实边界

- 本文的厂家限值取自**嘉立创官网单一页面**（另有其官方博客交叉印证），**换厂家必须重新取值**；
  多数限值同时给出了「标准值」与「极限值」，本文对**需确认项**给出了两种解读而不是挑一个报。
- 「丝印自动掏空」「阻焊自动扩 0.05」是厂家**书面口径**，不是我们在本厂的实测；
  首次投板后应以实际成品核对。
- 「社区此封装大量投产未见退回」属**[INFERENCE]**（基于封装来源与其通用性），非统计结论。
- 表面处理建议（沉金）是**性价比判断**，不是实测数据；板文件目前未固化该项。
- 内层过孔间隙的 499 处是**用自定义 DRC 规则量出来的**（规则语法见
  `hardware/pcb/StarShield/Starshield.kicad_dru` 与 handoff §10.2 第 48 条），
  量的是过孔**环边**到其它网络铜面的距离；这是 KiCad 的 clearance 口径。

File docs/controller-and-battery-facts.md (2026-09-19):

# 控制器与电池事实（已核实）

本文件汇总影响硬件决策的**已核实事实**，来源为一手资料（厂商官方页、官方仓库、JST/TI 文档）。
**未核实项一律标注 `❓ UNVERIFIED`，不得当作数据使用。**

状态：🟡 部分完成（关键项已核实；TS 引脚参数等硬阻塞项待人工查 TI 文档）

> 完整调研过程与逐条来源见 `research/starshield-hardware-facts.md` 与
> `research/lipo-3000mah-dimensions-report.md`（含全部候选清单与 UNVERIFIED 清单）。

---

## 1. 控制器 GPIO 预算 —— 本项目的硬约束

### 1.1 实测/官方数据

| 项目 | nice!nano v2 | SuperMini nRF52840 |
| --- | --- | --- |
| **GPIO 总数** | **21 个** ✅ 官方措辞：「3 extra GPIO pins offering a total of 21 GPIO pins」（另 3 个不占 2×12 主排针） | ❓ UNVERIFIED（无官方 datasheet） |
| 主排针布局 | **2×13 @ 2.54mm（26 孔）**——✅ 官方 pinout 图 + 实物清点双重确认（2026-09-19，B6 到货量测）；比 Pro Micro（2×12）每排多 1 孔、多在 USB 端（左排多 GND、右排多 B+）；主板长度 34.0 mm。早期「2×12」记载系旁证误导，已证伪；逐孔映射见 `nice-nano-physical-verification.md` §6.2 | 同为 2×13 的是 SuperMini 逆向件旁证（1×13 两条）；仍以实物为准 |
| 板厚 | **3.2 mm**（mid-mount USB-C） | ❓ UNVERIFIED |
| 电池电压 ADC | **P0.04 (AIN2)**，官方明确「不能作其他用途」 | **P0.24**（原理图错标为 P0.04） |
| VCC 门控 | **P0.13 置高可切断 VCC**（官方说明用于省掉 LED 静态功耗） | 存在 NPQ2/NBD1/NPR7 电源路径电路 |
| 休眠电流 | **18 µA**（quiescent 15 µA + 3 µA，ZMK 官方用 Nordic Power Profiler Kit 实测） | 批次差异极大：好板 **4 µA**，差板 **60 µA** |
| 板载充电 | 有，两档：约 100 mA / 约 500 mA（焊 boost 跳线）。官方建议电池 ≤2000mAh | 有，充电电流 ❓ UNVERIFIED |
| ZMK 官方支持 | ✅ 支持。**board id 随分支不同**：`main` 用 `nice_nano//zmk`；`v0.3` 用 `nice_nano_v2` | ❌ **ZMK 官方零支持**（穷举 `app/boards/` 无 ebyte/supermini/e73） |

### 1.2 ⚠️ 结论：矩阵无法直连，且**折叠矩阵也救不回来**

矩阵需要 **24 个 GPIO**（见 `docs/matrix-assignment.md`）。

**关键修正**：nice!nano v2 官方口径的 21 GPIO 里，**实际引出到 2×12 排针的只有 18 个**。
从 **ZMK 官方 v0.3 分支** `app/boards/arm/nice_nano/arduino_pro_micro_pins.dtsi`
解析 `pro_micro` 连接器的 gpio-map 并去重，得到排针引脚（Pro Micro 标号 → GPIO）：

`D0→P0.8  D1→P0.6  D2→P0.17  D3→P0.20  D4→P0.22  D5→P0.24  D6→P1.0  D7→P0.11
 D8→P1.4  D9→P1.6  D10→P0.9  D14→P1.11  D15→P1.13  D16→P0.10  D18→P1.15  D19→P0.2
 D20→P0.29  D21→P0.31`
（编号 D11/D12/D13/D17 空缺）

**⇒ 排针 18 个 GPIO**；扣掉 RGB 数据线与 RGB 电源门控后，**可用于矩阵的约 16 个**。

**并且已专门验证「折叠矩阵」这条退路**（完整分析见 `docs/matrix-folding-analysis.md`）：

| 方案 | 引脚 | 结果 |
| --- | --- | --- |
| 当前 6 行 × 18 列 | 24 | 已实现、网表已校验 |
| 折叠到 8 行 × 12 列（数学最优） | **20** | ✅ 电气可行，但 |
| 可用引脚（18 排针 − RGB 2 个） | 约 16 | ❌ **20 > 16，仍不足** |

**⇒ 移位寄存器（74HC595 等）是本项目的必要方案，不是过度设计。**

### 1.3 SuperMini 的双重问题（不只是引脚）

1. **ZMK 官方不支持** → 需自行维护 board 定义（`zmk keyboard new` 或 zmk module），
   与「新手可复刻」「上游 ZMK」的目标冲突。
2. **ZMK 官方支持的 nRFMicro（joric/nrfmicro）是正规替代品** —— 它在 ZMK 官方仓库内有第一方
   board 定义（`app/boards/joric/nrfmicro/`），nice!nano 官方 FAQ 亦推荐它。
   ⚠️ 「能刷 nice!nano 固件」≠「被 ZMK 支持」：克隆板实测待机 1.40–1.90 mA。
3. **共享 footprint 的三个真实差异**：
   - ① 引脚数 21 vs 18，额外脚不占主排针；
   - ② **电池 ADC 脚不同**（P0.04 vs P0.24）→ 同一根走线无法同时正确读取两者电量，需 **0Ω 跳线**二选一；
   - ③ 板厚/外形差异未验证，共享插座有机械干涉风险。
   （此差异需更新 ADR-0003。）

---

## 2. 电池

### 2.1 关键结论：3000mAh 的厚度与占位面积可互换

> 🔴 **2026-09-17 更新：容量已改为 2×5000 mAh 并联（10000 mAh）。**
> 本节关于「3000 mAh」的厚度谱**保留作历史记录**；下方「推荐 605080 路线 / 电池仓
> 6.5 × 51 × 84 mm / 机壳深度 ≥8.5–9 mm」**已作废**。新规格与采购要求见
> `docs/power-architecture.md` **§3.5 / §3.6**，要点：
> - 单块 5000 mAh 参考规格 **`LP955465` = 9.5 × 54 × 66 mm、100 g、18.5 Wh**，自带 PCM + JST PHR-2
> - 两块**并排**总占位约 **10.5 × 110 × 68 mm** ⇒ **机壳深度由 ≥8.5–9 mm 改为 ≥11 mm**
> - ⚠️ 必须买**一体化 1S2P 单 PCM 包**；两块各自带保护板的电芯直接并联会出问题（互充 + 阈值失配）
> - ⚠️ nice!nano 官方「建议电池 ≤2000mAh」**不适用于本设计** —— 那是针对它**板载**充电器
>   （100 / 500 mA）的建议；本项目用自画的 BQ24072，该限制不成立

任务假设「3000mAh 有一个典型厚度」是**不成立**的。实测/官方数据显示：

| 厚度路线 | 占位面积 | 实例 |
| --- | --- | --- |
| **6.0 mm** | 约 4100 mm²（50.5 × 82.5） | VCELL `VP605080`（含保护板，6.2 × 50.5 × 82.5） |
| **8.5–9.8 mm** | 2400–3900 mm² | Blumoti `BMP` 系列约 15 个型号；**9 mm 是紧凑外形下的众数** |
| **10 mm** | 约 2340 mm²（36 × 65） | Tcbest / AFTERTECH `103665` |
| 13 mm ❌ | — | 2 × 1500mAh 叠层，不建议 |

- **任何路线都做不到 5 mm。**
- **推荐 605080 路线**（键盘横向空间比深度好找）：电池仓开槽约 **6.5 × 51 × 84 mm**，
  **机壳深度 ≥ 8.5–9 mm**。若用 40 × 65 紧凑电芯则深度需 ≥ 11 mm。
- ⚠️ **型号数字是标称最小值，实物更大**：Jauch `LP103450JH` 型号写 10、实测 **10.8 mm**；
  保护板使总长 **+1~2 mm**。**所有厚度均为厂商标称，无第三方实测 → 必须实物卡尺复测。**

### 2.2 采购现实

- **Adafruit 不卖 3000mAh 单节软包**，上限 2500 mAh（#328，50 × 60 × 7.3 mm，$14.95，JST-PH，含保护）。
- **SparkFun 上限 2 Ah**（PRT-13855，60 × 54 × 5.8 mm，$19.41，JST-PH）。
- **要 3000mAh 只能走中国原厂或 BatterySpace**；且中国 3000mAh 软包**普遍不预装 JST-PH**
  → 采购需指定压接，或自购 `PHR-2` + `SPH-002T-P0.5S`。

### 2.3 BQ24072 充电电流核算（ADR-0002 相关）

- 容量 **10 Ah** 下，芯片可编程上限 **1.5 A ÷ 10 Ah = 0.15C**，远在 LiPo 理想区间
  （厂商标称标准充电 0.5C–1C）之内 ⇒ **电芯侧完全不构成限制**。
- ✅ **2026-09-18 定稿：`R_ISET` = 887 Ω ⇒ ICHG ≈ 1.0 A（0.10C）**。
  依据是**商用同容量（≥5000 mAh）键盘的实测充电区间 0.035–0.163C**（见
  `research/large-battery-keyboard-charging-current.md` 与 `power-architecture.md` §3.7）。
  耗散 (5−3.7)×1.0 = **1.3 W**；按 JEDEC 板 `RθJA` = 44.5 °C/W 估 `Tj` ≈ 83 °C，低于 125 °C 门限。
- `K_ISET = 890`（TI SLUA947A）→ R_ISET：1.5 A = 593 Ω / 1.0 A = **887 Ω** / 0.5 A = 1.78 kΩ。
- 🔴 **安全定时器仍是硬约束**：`tMAXCHG` 最长 = **7.2 / 9.6 / 12 h**（min/typ/max），
  而 1.0 A 充满 10 Ah 仍需约 **10 h** ⇒ 落在 9.6–12 h 边缘 ⇒ **`TMR` 接 VSS 禁用定时器**。
  详见 `docs/power-architecture.md` §3.5 / §3.7。

### 2.4 TS 温度检测引脚 —— ✅ 已解决（2026-09-17）

> **下方内容为当时的阻塞记录。** 现已解除：TS 阈值与「禁用温测」的合法接法都从
> TI SLUS810N 正文取得了（`V_HOT` ≈ 300 mV / `V_COLD` ≈ 2100 mV，内部 75 µA 偏置，
> 配 10 kΩ 恰对应 0–50 °C）。本项目取 **`R5` = 10 kΩ 到 VSS 禁用温测**。
> 四个方案的完整对比见 `docs/bq24072-pinout.md` §3.4 与 `docs/power-architecture.md` §3.3。

- ✅ 已确认：BQ24072 有 **NTC thermistor input**，特性为「BAT temp thermistor monitoring
  (hot/cold profile)」；TI 有应用笔记 **SPVA059**；**10k NTC 可用**（需配 R_S / R_P）。
- ❌ **未取得**：TS 的 `V_HOT`/`V_COLD` 阈值、`I_BIAS`、以及「用固定电阻禁用温度监测的具体阻值」。
- **根因**：PDF 无法通过网页抓取读取，命令行网络访问受限，各 datasheet 站点 403。
- **必须人工做**：浏览器打开 TI `SPVA059` 与 `bq24072.pdf` (SLUS810N) §7 `TS` 行 + §9.3.6。
- **保守做法**：按 SPVA059 配一颗真 10k NTC 贴电池表面。
  ⚠️ Adafruit 大容量电池**明确不带 NTC**，热敏必须自己加。
- 另：TI 官方措辞是「hot/cold profile」，**未使用「JEITA」一词** —— 文档中应改写。

### 2.5 JST-PH 2.0 连接器（✅ JST 原厂页确认）

| 项目 | JST 官方值 |
| --- | --- |
| Pitch | **2 mm** |
| 额定电流 | **2 A AC/DC（AWG #24 条件）** |
| 额定电压 | 100 V AC/DC |
| 温度范围 | **−40 ℃ ~ +105 ℃**（⚠️ 与分销商冲突，见下） |
| 适用线规 | **AWG #32–#24**（0.032–0.22 mm²），绝缘外径 φ0.5–1.5 mm |
| 认证 / 锁扣 | **TÜV、UL** / friction lock |
| 插合总高 | **8.0 mm**（原厂原文 mounting height of 8 mm；top-entry 宽 4.5 mm） |

**料号（均已从 JST 原厂数据表确认）：**

| 用途 | 料号 | 分销商号 |
| --- | --- | --- |
| 板端针座（直插立式） | **`B2B-PH-K-S(LF)(SN)`** | LCSC `C131337` |
| 板端针座（**侧插/直角**，省高度） | **`S2B-PH-K-S(LF)(SN)`** | LCSC `C173752`（2A Right Angle, THT, 5.9×7.6mm, 高 4.8mm） |
| 板端针座（**SMT 立式**） | **`B2B-PH-SM4-TB(LF)(SN)`** | LCSC `C160352`（SMD Vertical, 7.95×5.0mm, 高 6.6mm） |
| 线端胶壳 | **`PHR-2`** | LCSC `C157955`；Digi-Key `455-1165-ND` |
| 压接端子（**推荐**） | **`SPH-002T-P0.5S`** | LCSC `C111515` — **AWG #30–#24** |
| 压接端子（窄线规） | `SPH-002T-P0.5L` | LCSC `C265456` — AWG #28–#24 |

- ✅ **`B2B-PH-K-S` 与 `B2B-PH-K-S(LF)(SN)` 是同一颗料**（原厂备注：*This product displays "(LF)(SN)" on the label.*），两种写法都能订。
- ✅ **`(LF)(SN)` 后缀 = 符合 RoHS**（JST 官方环境调查页原文：「indicate RoHS-compliant products」）。
  原厂**未**展开字母含义；「无铅/纯锡」的解释来自第三方转述，仅有立创「Contact Plating: Tin」佐证 → 定性为**良好佐证，非原厂原文**。
- ⚠️ **2 A 额定条件是 AWG #24** → pigtail 请指定 **AWG #24**；用 #26/#28 会降低实际载流。
- ⚠️ **温度范围存在未解决矛盾**：JST 原厂 **−40~+105 ℃** vs **所有**分销商一致 **−25~+85 ℃**。
  推测分销商为带载/UL 式额定，**未证实**。引用时写原厂值并注明差异。
- ⚠️ **高度 8 mm vs 6.00 mm**：原厂写 8 mm，分销商写裸针座 6.00 mm。
  推断 8 mm = **插合总高**（针座 + PHR-2 就位），**无页面如此说明**。
  → **机壳按 8 mm 保守留高，并以 JST 官方 STEP 模型确认。**
- ❌ **插拔寿命（mating cycles）：任何来源均未给出 → 文档中不得出现此数字。**

**PCB 焊盘/孔径/针脚尺寸 = ❓ UNVERIFIED**，只存在于 JST 的 PDF 图纸里。
⚠️ **踩坑记录**：JST 的 datasheet PDF（`ePH.pdf` / `ePH-H.pdf`）**内容流是纯图像矢量图、无文字绘制算子**，
任何 PDF 文本抽取都取不到尺寸；且 PDF 无法通过网页抓取读取。
→ **正确做法：导入 JST 官方 STEP 模型到 CAD 量测**
`https://www.jst-mfg.com/product/index.php?type=10&series=199&doc=2&filename=B2B-PH-K-S.zip`

**采购动作**：① pigtail 指定 **AWG #24**；② **直接买预压接好的 `PHR-2` + `SPH-002T-P0.5S` 成品**，不要手工压接。

---

## 3. 对既有决策的影响（需要更新 ADR）

| ADR | 影响 | 处置 |
| --- | --- | --- |
| ADR-0002（BQ24072） | 充电电流建议与 `R_ISET` 取值；TS 引脚方案 | ✅ **已补充**（ADR-0002 已加勘误；取值见 `docs/power-architecture.md` §3.1） |
| ADR-0003（双控制器兼容 footprint） | nice!nano v2 = 21 GPIO；SuperMini **ZMK 官方不支持**；电池 ADC 脚冲突需 0Ω 跳线 | ✅ **已修订并决策**：第一版按 nice!nano v2 设计并保证；SuperMini 降级为「焊盘兼容、不保证」 |
| ADR-0005（RGB 门控） | ✅ 得到强支撑：nice!nano 官方说明 **P0.13 置高可切断 VCC**，正是为省 LED 静态功耗 | ✅ 已印证 |
| ~~新增 ADR（待写）~~ | ~~矩阵引脚方案：直连 vs 74HC595 移位寄存器~~ | ✅ **已落地：ADR-0008（74HC595）** |

---

## 4. 待办

| 编号 | 待办 | 性质 |
| --- | --- | --- |
| C1 | 人工查 TI SPVA059 + SLUS810N 补 TS 引脚参数 | 需人工（PDF 不可达） |
| C2 | ~~决策矩阵引脚方案~~ ✅ **已定**：74HC595 移位寄存器，见 **ADR-0008** | 已完成 |
| ~~C3~~ | ~~修订 ADR-0003（SuperMini 不支持 ZMK / ADC 脚冲突）~~ | ✅ **已完成**（ADR-0003 已加「修订」+「决策」两节） |
| C4 | 采购实物：1× nice!nano v2 + 2–3 个不同货源 SuperMini + 1× Adafruit #328 作对照，卡尺 + 万用表实测 | 需采购 |
| C5 | 索要 605080 完整规格书与实物卡尺厚度，确认能否出厂压接 JST-PH 2.0 | 需与供应商沟通 |
| C6 | 定稿电池型号与电池仓尺寸（解除外壳阻塞） | 🟡 **容量已定（2×5000 mAh 并联，2026-09-17）**；剩采购落地与电池仓尺寸重定 ⇒ `power-architecture.md` P17 / P18 |

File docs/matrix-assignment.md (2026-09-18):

# 95 键矩阵行列分配

本文件记录 StarShield 的**矩阵电气设计**：行/列划分、引脚预算、二极管方向，以及与 KiCad 工程的一致性。
几何基准见 `docs/hardware-geometry.md`；本文件的表格由脚本生成，不手工维护。

状态：🟡 部分完成（矩阵已定稿并通过网表校验；控制板引脚分配待定，见第 5 节）

> **数据来源**：`sketch/keyboard-layout.json`（KLE，唯一权威）
> **生成脚本**：`docs/_tools/matrix-assign.mjs` → `docs/_generated/matrix.json`
> **校验脚本**：`docs/_tools/verify_netlist.py`（对 KiCad 导出的网表做 10 项电气检查）

---

## 1. 矩阵规格

| 项目 | 数值 |
| --- | --- |
| 键数 | **95** |
| 矩阵行数 | **6**（R0–R5，对应 6 个物理行） |
| 矩阵列数 | **18**（C0–C17） |
| 所需 GPIO | **24**（6 行 + 18 列） |
| 二极管 | **95** 颗（每键一颗，`1N4148W` / `SOD-123` 贴片） |
| 矩阵格利用率 | 95 / (6 × 18) = **88.0%** |

### 1.1 为什么是 18 列（下界证明）

单行最多键数出现在 R1（数字行）与 R2（Q 行），均为 **18 键**。
同一行内的 18 个键**必然分属 18 个不同的矩阵列**（同一列在同一行只能有一个键，否则短路）。
因此 **列数 ≥ 18**，这是理论下界。

本设计的 18 列分配**恰好达到该下界**，即在"6 行"前提下列数已不可能更少。

### 1.2 为什么是 6 行（能否减到 5 行？）

曾评估把行数压到 5 以省引脚。结论：**做不到**。

- 主键区（不含 F 行与小键盘）本身占 5 个物理行（数字行 / Q / A / Z / 底行）。
- 2u 高键（小键盘 `Delete`、小键盘 `Enter`、主键区 `Enter`）跨越两个物理行，
  其开关中心落在两行之间；若强行压行会与同列其他键冲突。
- 因此 6 行是满足「不合并物理行」的最小行数。

### 1.3 二极管方向

- **扫描方式**：ROW2COL（ZMK 的 `matrix-transform` 常规接法）。
- **电流路径**：`列驱动 → 二极管 → 开关 → 行`。
- **接法**：开关的 `pin1` 接行网络；开关 `pin2` 接二极管**阳极**；二极管**阴极**接列网络。
- KiCad 的 `Device:D` 符号中 **pin1 = K（阴极）、pin2 = A（阳极）**，切勿接反。
- 二极管作用：防止同一行多个按键同时按下时产生**鬼影（ghosting）**，并允许全键无冲（NKRO）。

---

## 2. 完整分配表

（由 `docs/_tools/gen_matrix_doc.py` 生成，见文末附录）

<!-- BEGIN GENERATED TABLES -->
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

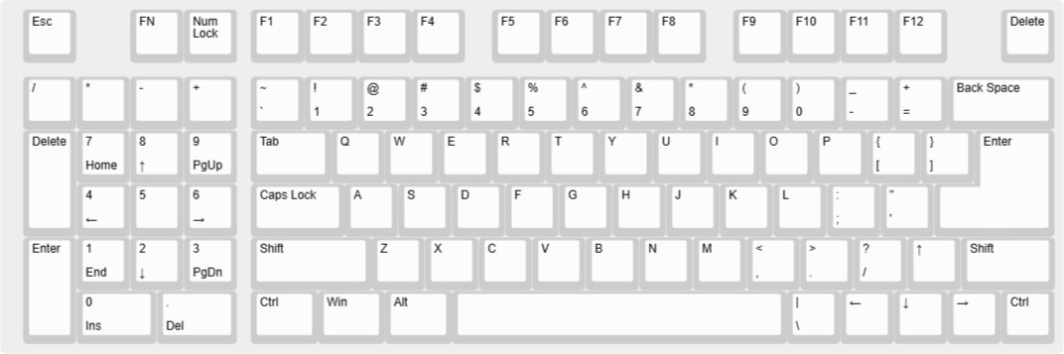
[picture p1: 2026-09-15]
sketch/keyboard-layout.jpg

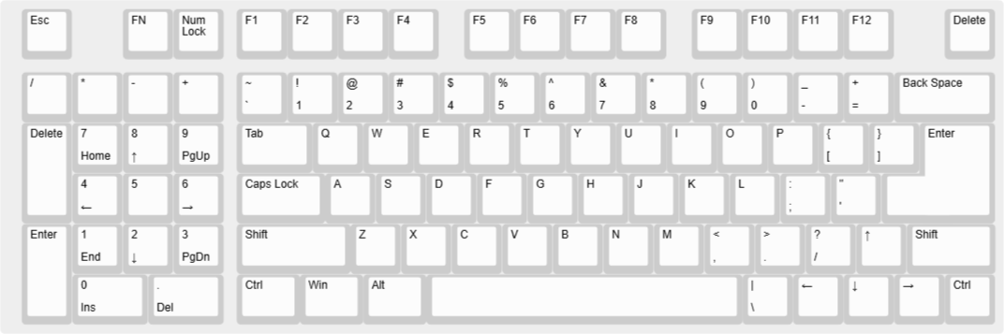
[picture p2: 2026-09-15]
sketch/keyboard-layout.png

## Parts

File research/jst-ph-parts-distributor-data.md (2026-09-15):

# JST PH-series 2.0 mm parts — verbatim distributor attributes

Research date: 2026-09 (StarShield PCB component fact-gathering).
Rule followed: every value below was read off a page actually fetched; values are quoted verbatim.
PDFs are cited by URL only (the PDFs themselves were fetched and text-extracted locally).

## Source keys

| Key | Source | URL |
|---|---|---|
| **JST-PH** | JST official PH connector series page (product profile + specification + product list) | https://www.jst-mfg.com/product/detail_e.php?series=199 → resolves to https://www.jst-mfg.com/product/index.php?series=199&lang=2 |
| **JST-PDF** | JST official PH catalogue (PDF, not machine-readable here) | https://www.jst-mfg.com/product/pdf/eng/ePH.pdf |
| **JST-ENV** | JST official Environmental Survey page (part-number identification symbols) | https://www.jst-mfg.com/env/?lang=2 |
| **HQ** | HQ Online (NextPCB) product page — full attribute table | see per-part rows |
| **LCSC** | LCSC product data (JSON service that backs the LCSC product page) | see per-part rows |
| **DKF** | DigiKey TechForum — **NOT PRIMARY** (distributor forum, statement attributed to JST) | https://forum.digikey.com/t/jst-suffixes-lf-sn-au-s-n-m-prefixes-g-w-c-q-d/605 |
| **DKF2** | DigiKey TechForum, 2nd thread — **NOT PRIMARY** | https://forum.digikey.com/t/why-does-my-part-have-an-lf-sn-suffix-but-it-does-not-show-this-as-the-ordering-part/60889 |
| **ICZ** | ICZOOM product page for the **base** PN `B2B-PH-K-S` (legacy, stale data — see caveat) | https://en.iczoom.com/product/k07-23573041-B2B-PH-K-S.html |

LCSC page ⇄ JSON pairs used (the JSON is the data behind the page; the rendered LCSC HTML body returns
mostly site navigation, so values were taken from the JSON service and cross-checked against the parent's
cached LCSC HTML JSON-LD):

| Part | LCSC page | JSON used |
|---|---|---|
| B2B-PH-K-S(LF)(SN) | https://www.lcsc.com/product-detail/C131337.html | https://wmsc.lcsc.com/ftps/wm/product/detail?productCode=C131337 |
| PHR-2 | https://www.lcsc.com/product-detail/C157955.html | https://wmsc.lcsc.com/ftps/wm/product/detail?productCode=C157955 |
| SPH-002T-P0.5S | https://www.lcsc.com/product-detail/C111515.html | https://wmsc.lcsc.com/ftps/wm/product/detail?productCode=C111515 |
| SPH-002T-P0.5L | https://www.lcsc.com/product-detail/C265456.html | https://wmsc.lcsc.com/ftps/wm/product/detail?productCode=C265456 |
| S2B-PH-K-S(LF)(SN) | https://www.lcsc.com/product-detail/C173752.html | https://wmsc.lcsc.com/ftps/wm/product/detail?productCode=C173752 |
| B2B-PH-SM4-TB(LF)(SN) | https://www.lcsc.com/product-detail/C160352.html | https://wmsc.lcsc.com/ftps/wm/product/detail?productCode=C160352 |

---

## 1. B2B-PH-K-S(LF)(SN) — top-entry through-hole header, 2 circuits

### 1a. Series-level specification stated by JST (JST-PH)
Applies to the PH series; JST's own note on that page says to use the representative specification
for the same circuit count with a different part-number suffix.

| Attribute | Verbatim value | Source |
|---|---|---|
| Series | `PH connector` | JST-PH |
| Category | `Crimp Style Connectors (Wire-to-Board type)` | JST-PH |
| PC board mounting | `Through-hole, SMT` | JST-PH |
| Mating direction | `Side entry, Top entry` | JST-PH |
| Array (Insertion part) | `Single-row` | JST-PH |
| Lock | `Friction lock` | JST-PH |
| Standard | `TÜV, UL` | JST-PH |
| Intro text | `With a mounting height of 8 mm and a width of only 4.5 mm in the top-entry version, this low-profile wire-to board connector features a pitch of 2.0 mm.` | JST-PH |
| Pitch | `2 mm` | JST-PH |
| Circuit | `2, 3, 4, 5, 6, 7, 8, 9, 10, 11, 12, 13, 14, 15, 16` | JST-PH |
| Current rating | `2 A AC/DC (AWG #24)` | JST-PH |
| Voltage rating | `100 V AC/DC` | JST-PH |
| Temperature range | `-40 ℃ to +105 ℃` | JST-PH |
| Insulation resistance | `1,000 MΩ min.` | JST-PH |
| Withstanding voltage | `There shall be no breakdown or flashover while applying 800 VAC for one minute.` | JST-PH |
| Conductor size | `AWG # 32 , # 30 , # 28 , # 26 , # 24  0.032 mm2 to 0.22 mm2` | JST-PH |
| Insulation O.D. | `φ 0.5 mm to φ 1.5 mm` | JST-PH |
| Product list entry | item 19 = `B2B-PH-K-S` (representative PN; 2D-PDF `B2B-PH-K-S.pdf`) | JST-PH |

### 1b. Distributor attribute table (HQ)
Source: https://www.hqonline.com/product-detail/wire-to-board-connectors-jst-b2b-ph-k-s-lf--sn--2500219066

| Attribute | Verbatim value |
|---|---|
| Mfr Part # | `B2B-PH-K-S(LF)(SN)` |
| Description | `Wire to Board Connectors 1x2P Direct Insertion P:2mm` |
| Product Type | `Connectors / Wire to Board Connectors` |
| Insulation Height | `0.236"（6.00mm）` |
| Height | `6.00mm` |
| Size | `5.90 x 4.50mm` |
| Spacing | `2.00mm` |
| Rated Voltage | `100V` |
| Rated Current | `2A` |
| Contact Material | `Brass` |
| Contact Coating | `Tin` |
| Operating Temperature | `-25℃~+85℃` |
| Storage Temperature | `-25~+85℃` |
| Flammability Grade Of Materials | `UL94V-0` |
| Number of Positions | `2Pin` |
| Number of Rows | `Single row` |
| Number Of Pins Per Row | `2` |
| Pin Structure | `1x2P` |
| Male And Female | `Male` |
| Connector Type | `Joint` |
| Fastening Type | `Latch Lock` |
| Installation Type | `Direct Insertion` |
| Package / Case | `DIP,P=2mm` |
| Series | `PH` |
| Colour | `White` |
| Moisture Sensitivity Level (MSL) | `1 (Unlimited)` |
| Application Level | `Consumer` |

### 1c. Distributor attribute table (LCSC, C131337)
Source: https://www.lcsc.com/product-detail/C131337.html (data: `.../productCode=C131337`)

| Attribute | Verbatim value |
|---|---|
| Title / MPN | `JST B2B-PH-K-S(LF)(SN)` |
| productNameEn | `CONN HEADER TH 2POS 2mm` |
| Description / Intro | `Connector Header 2 position 2mm Pitch 2A Through Hole -25℃~+85℃` |
| Connector Type | `Through Hole` |
| Package standard | `Through Hole,P=2mm` |
| Reference Series | `PH` |
| Pitch | `2mm` |
| Number of PINs | `2P` |
| Number of PINs Per Row | `2` |
| Number of Rows | `1` |
| Pin Structure | `1x2P` |
| Voltage Rating (Max) | `100V` |
| Current Rating | `2A` |
| Contact Material | `Brass` |
| Contact Plating | `Tin` |
| Plastic Material | `PA66` |
| Flame Retardant Rating | `UL94V-0` |
| Colour | `White` |
| Operating Temperature | `-25℃~+85℃` |
| Supplementary Features | `K Pin` |
| X-Length of Bottom Edge on Board (Spacing Line) | `5.9mm` |
| RoHS fields (`authenticationList` / `isRohsCert`) | `null` — this SKU carries no RoHS badge on LCSC |

### 1d. Legacy/stale third-party table for the base PN (ICZ) — use with care
The ICZOOM page is for `B2B-PH-K-S` (no suffix) and its own data says `Part Status: Obsolete` and
`Lead Free Status / RoHS Status: Contains lead / RoHS non-compliant`, `Contact Finish: Tin-Lead`.
It is useful **only** for the geometry rows, and it does **not** describe the `(LF)(SN)` ordering PN:

| Attribute | Verbatim value | Source |
|---|---|---|
| Insulation Height | `0.236 (6.00mm)` | ICZ |
| Contact Length - Post | `0.134 (3.40mm)` | ICZ |
| Overall Contact Length | `0.333 (8.45mm)` | ICZ |
| Contact Mating Length | `0.130" (3.30mm)` | ICZ |
| Mated Stacking Heights | `8mm` | ICZ |
| Insulation Material | `Polyamide (PA66), Nylon 6/6` | ICZ |
| Contact Finish / Material | `Tin-Lead` / `Brass` | ICZ |
| Mounting Type / Termination | `Through Hole` / `Press-Fit, Solder` | ICZ |
| Pitch - Mating | `0.079 (2.00mm)` | ICZ |
| Shrouding | `Shrouded - 4 Wall` | ICZ |
| Fastening Type | `Detent Lock` | ICZ |
| Current Rating (Amps) / Voltage Rating | `2A` / `100V` | ICZ |
| Operating Temperature | `-25°C ~ 85°C` | ICZ |
| Material Flammability Rating | `UL94 V-0` | ICZ |
| Part Status | `Obsolete` | ICZ |

### 1e. Direct answers for part 1
| Asked | Answer | Source |
|---|---|---|
| (a) description/title | HQ: `Wire to Board Connectors 1x2P Direct Insertion P:2mm`; LCSC: `CONN HEADER TH 2POS 2mm` / `Connector Header 2 position 2mm Pitch 2A Through Hole -25℃~+85℃` | HQ, LCSC |
| (b) positions | `2Pin` / `2P` / JST series `Circuit 2…16` | HQ, LCSC, JST-PH |
| (c) pitch | `2.00mm` / `2mm` / JST `2 mm` | HQ, LCSC, JST-PH |
| (d) mounting type | `Direct Insertion`, `DIP,P=2mm` / `Through Hole`, `Through Hole,P=2mm` | HQ, LCSC |
| (e) contact material | `Brass` | HQ, LCSC |
| (f) contact finish | `Tin` | HQ, LCSC |
| (g) dimensions | HQ `Size 5.90 x 4.50mm`, `Height 6.00mm`, `Insulation Height 0.236"（6.00mm）`; LCSC `X-Length of Bottom Edge on Board (Spacing Line) 5.9mm`; JST `mounting height of 8 mm … width of only 4.5 mm in the top-entry version` | HQ, LCSC, JST-PH |
| (h) current / voltage | `2A` / `100V` (distributors); JST `2 A AC/DC (AWG #24)` / `100 V AC/DC` | HQ, LCSC, JST-PH |
| (i) operating temperature | `-25℃~+85℃` (both distributors) **vs** JST series `-40 ℃ to +105 ℃` — CONFLICT | HQ, LCSC, JST-PH |
| (j) lead free / RoHS / tin | `Contact Coating: Tin` (HQ), `Contact Plating: Tin` (LCSC); **no fetched page spells out "lead free" or "RoHS" for this PN**; LCSC RoHS fields are `null` | HQ, LCSC |

---

## 2. PHR-2 — 2-circuit wire housing (mates the header)

| Attribute | Verbatim value | Source |
|---|---|---|
| Mfr Part # | `PHR-2` | HQ, LCSC |
| Description (HQ) | `Rubber shell spacing P=2.00mm 2Pin (1x2)` | https://www.hqonline.com/product-detail/rubber-shells-and-accessories-jst-phr-2-2500219074 |
| Description (LCSC) | `CONN HOUSING 2POS 2mm SINGLE ROW PH` / `Connector Housing 2 Position 2mm Pitch Single Row PH Series PA66 -25℃~+85℃` | https://www.lcsc.com/product-detail/C157955.html |
| Spacing / Pitch | `2.00mm` / `2mm` | HQ, LCSC |
| Number of Positions | `2Pin` (`Number of PINs Per Row: 2`, `Holes Structure: 1x2P`, `Pin Structure: 1x2P`) | HQ, LCSC |
| Number of Rows | `Single row` / `1` | HQ, LCSC |
| Connector Type | `Socket` | HQ |
| Installation Type | `Free Hanging` | HQ |
| Housing / Plastic Material | `PA66` | HQ, LCSC |
| Rated Voltage | `100V` | HQ |
| Rated Current | `2A` | HQ |
| Operating Temperature | `-25℃~+85℃` | HQ, LCSC |
| Storage Temperature | `-25~+85℃` | HQ |
| Size | `5.80 x 4.50mm` | HQ |
| Height | `6.40mm` | HQ |
| Colour | `White` | HQ, LCSC |
| Certification | `RoHS` | HQ |
| Lead Free Or Not | `Yes` | HQ |
| Country of Origin | `Japan` | HQ |
| Part Status | `Active` | HQ |
| With Locker / With Wings / Row Spacing (LCSC) | `Non-Latching` / `Without Fins` / `-` | LCSC |
| Flammability (LCSC) | `UL94V-0` | LCSC |
| LCSC certification | `ROHS3 认证` (`isRohsCert: true`, `rohsCertType: ROHS3`) | LCSC |
| JST official listing | `PHR-2` is product #4 of the PH series 3D/2D data list | JST-PH |

---

## 3. SPH-002T-P0.5S — crimp contact

| Attribute | Verbatim value | Source |
|---|---|---|
| Mfr Part # | `SPH-002T-P0.5S` | HQ, LCSC |
| Description (HQ) | `Rubber shell terminal 24-30AWG` | https://www.hqonline.com/product-detail/housing-contact-jst-sph-002t-p0-5s-2500219104 |
| Description (LCSC) | `CONN TERM 24~30AWG CRIMP TIN` / `Connector Terminal PH Tin 24~30 AWG Crimp` | https://www.lcsc.com/product-detail/C111515.html |
| Wire Gauge - AWG | `24-30AWG` / `24~30` | HQ, LCSC |
| Wire Gauge - mm² | `0.05~0.22mm²` / `0.05~0.22` | HQ, LCSC |
| Insulation OD | `0.8mm~1.5mm` (LCSC only) | LCSC |
| Contact Material | `Phosphor Bronze` / `Phosphor bronze` | HQ, LCSC |
| Contact Coating / Plating | `Tin` | HQ, LCSC |
| Rated Voltage / Current | `100V` / `2A` | HQ |
| Operating Temperature | `-25℃~+85℃` | HQ |
| Installation Type | `Free Hanging` | HQ |
| Size / Height | `5.70 x 1.50mm` / `2.08mm` | HQ |
| Series | `PH` | HQ, LCSC |
| Packaging (LCSC) | `Tape & Reel (TR)`, min. packet 8000 | LCSC |
| LCSC certification | `ROHS3 认证` | LCSC |
| JST official listing | `SPH-002T-P0.5S` is product #2 of the PH series list (2D-PDF drawing available) | JST-PH |
| JST series-level wire data | `AWG # 32 , # 30 , # 28 , # 26 , # 24  0.032 mm2 to 0.22 mm2`; `Insulation O.D. φ 0.5 mm to φ 1.5 mm` | JST-PH |
| Farnell page (body NOT retrieved, 403) | slug states `contact-socket-30-24awg-crimp` — UNVERIFIED | https://uk.farnell.com/jst-japan-solderless-terminals/sph-002t-p0-5s/contact-socket-30-24awg-crimp/dp/2524012 |

---

## 4. SPH-002T-P0.5L — crimp contact (other variant)

| Attribute | Verbatim value | Source |
|---|---|---|
| Mfr Part # | `SPH-002T-P0.5L` | HQ, LCSC |
| Description (HQ) | `Rubber shell terminal 24-28AWG` | https://www.hqonline.com/product-detail/housing-contact-jst-sph-002t-p0-5l-2500269116 |
| Description (LCSC) | `CONN TERM 24~28AWG CRIMP TIN` / `Connector Terminal PH PAD Tin 24~28 AWG Crimp` | https://www.lcsc.com/product-detail/C265456.html |
| Wire Gauge - AWG | `24-28AWG` / `24~28` | HQ, LCSC |
| Wire Gauge - mm² | `0.08~0.22mm²` / `0.08~0.22` | HQ, LCSC |
| Insulation OD | `0.8mm~1.5mm` (LCSC only) | LCSC |
| Contact Material | `Phosphor Bronze` / `Phosphor bronze` | HQ, LCSC |
| Contact Coating / Plating | `Tin` | HQ, LCSC |
| Rated Voltage / Current | `100V` / `2A` | HQ |
| Operating Temperature | `-25℃~+85℃` | HQ |
| Size / Height | `5.70 x 1.50mm` / `2.08mm` | HQ |
| Series | `PH` (LCSC Reference Series field: `PH;PAD`) | HQ, LCSC |
| LCSC certification | `ROHS3 认证` | LCSC |
| JST official listing | `SPH-002T-P0.5L` is product #3 of the PH series list | JST-PH |
| Farnell page (body NOT retrieved, 403) | slug states `contact-socket-28-24awg-crimp` — UNVERIFIED | https://uk.farnell.com/jst-japan-solderless-terminals/sph-002t-p0-5l/contact-socket-28-24awg-crimp/dp/2399572 |

### What makes .5L different from .5S — as stated on fetched pages
The **only** difference any fetched page states is the applicable wire range:

| | SPH-002T-P0.5S | SPH-002T-P0.5L |
|---|---|---|
| HQ Online description | `Rubber shell terminal 24-30AWG` | `Rubber shell terminal 24-28AWG` |
| HQ wire range | `24-30AWG`, `0.05~0.22mm²` | `24-28AWG`, `0.08~0.22mm²` |
| LCSC wire range | `24~30`, `0.05~0.22` | `24~28`, `0.08~0.22` |
| LCSC Reference Series | `PH` | `PH;PAD` |

Everything else that both pages list (contact material `Phosphor Bronze`, coating `Tin`, `100V`, `2A`,
`-25℃~+85℃`, size `5.70 x 1.50mm`, height `2.08mm`, series `PH`, MSL 1) is **identical**.
No fetched page states a plating, geometry, insulation-OD, or packaging difference →
any other claimed difference is **UNVERIFIED**.

---

## 5. S2B-PH-K-S(LF)(SN) — side-entry (right-angle) through-hole header

Exists: confirmed on JST's own PH series product list (item 34, `S2B-PH-K-S`) and on two distributors.

| Attribute | Verbatim value | Source |
|---|---|---|
| Mfr Part # | `S2B-PH-K-S(LF)(SN)` | HQ, LCSC |
| Description (HQ) | `Wire to Board Connectors 1x2P Bending Insert P:2mm` | https://www.hqonline.com/product-detail/wire-to-board-connectors-jst-s2b-ph-k-s-lf--sn--2500219095 |
| Description (LCSC) | `CONN HEADER TH R/A 2POS 2mm` / `Connector Header 2 position 2mm Pitch 2A Right Angle -25℃~+85℃` | https://www.lcsc.com/product-detail/C173752.html |
| Connector Type | `Bending Insert` / `Right Angle`; package `Through Hole,Right Angle,P=2mm` | HQ, LCSC |
| Insulation Height | `0.189"（4.80mm）` | HQ |
| Height | `4.80mm` | HQ |
| Size | `5.90 x 7.60mm` | HQ |
| Spacing / Pitch | `2.00mm` / `2mm` | HQ, LCSC |
| Rated Voltage / Current | `100V` / `2A` | HQ, LCSC |
| Contact Material | `Brass` | HQ, LCSC |
| Contact Coating / Plating | `Tin` | HQ, LCSC |
| Operating Temperature | `-25℃~+85℃` | HQ, LCSC |
| Flammability | `UL94V-0` | HQ, LCSC |
| Positions / Rows / Pin Structure | `2Pin` / `Single row` / `1x2P` | HQ, LCSC |
| Fastening Type | `Latch Lock` | HQ |
| Colour | `White`; LCSC plastic `PA66` | HQ, LCSC |
| LCSC extras | `Supplementary Features: K Pin`; `X-Length of Bottom Edge on Board (Spacing Line): 5.9mm`; `ROHS3 认证` | LCSC |
| JST official listing | item 34 = `S2B-PH-K-S` | JST-PH |

---

## 6. B2B-PH-SM4-TB(LF)(SN) — surface-mount header

Exists: confirmed on JST's own PH series product list (item 49, `B2B-PH-SM4-TB`) and on two distributors.

| Attribute | Verbatim value | Source |
|---|---|---|
| Mfr Part # | `B2B-PH-SM4-TB(LF)(SN)` | HQ, LCSC |
| Description (HQ) | `Wire to Board Connectors 1x2P Stand Mounting P:2mm` | https://www.hqonline.com/product-detail/wire-to-board-connectors-jst-b2b-ph-sm4-tb-lf--sn--2500219068 |
| Description (LCSC) | `CONN HEADER SMD 2POS 2mm` / `Connector Header 2 position 2mm Pitch 2A Surface Mount,Vertical -25℃~+85℃` | https://www.lcsc.com/product-detail/C160352.html |
| Installation Type / Package | `Stand Mounting`, `SMD,P=2mm` / `Surface Mount,Vertical` | HQ, LCSC |
| Insulation Height | `0.260"（6.60mm）` | HQ |
| Height | `6.60mm` | HQ |
| Size | `7.95 x 5.00mm` | HQ |
| Spacing / Pitch | `2.00mm` / `2mm` | HQ, LCSC |
| Rated Voltage / Current | `100V` / `2A` | HQ, LCSC |
| Contact Material | `Copper Alloy` / `Copper alloy` | HQ, LCSC |
| Contact Coating / Plating | `Tin` | HQ, LCSC |
| Operating Temperature | `-25℃~+85℃` | HQ, LCSC |
| Flammability | `UL94V-0` | HQ, LCSC |
| Positions / Rows / Pin Structure | `2Pin` / `Single row` / `1x2P` | HQ, LCSC |
| Fastening Type | `Latch Lock` | HQ |
| Characteristic (HQ) | `Fixed welding tail`; LCSC: `Supplementary Features: Auxiliary Solder Pin` | HQ, LCSC |
| Colour | `Ivory` / LCSC `Color: Beige`, plastic `PA` | HQ, LCSC |
| LCSC extras | `X-Length of Bottom Edge on Board (Spacing Line): 7.95mm`; `ROHS 认证` | LCSC |
| JST official listing | item 49 = `B2B-PH-SM4-TB` | JST-PH |

---

## 7. What "(LF)(SN)" means on a JST part number

**Primary source (JST itself), verbatim — JST-ENV (https://www.jst-mfg.com/env/?lang=2):**
> `2. Product Part Numbers`
> `The identification symbols at the end of the part numbers below indicate RoHS-compliant products.`
> `Examples of identification symbols include (LF), (SN), (LF)(SN), (LF)(SN)A, (LF)(SN)B, (LF)(AU), K, (LF)K, (PF), (PF)(CLEAR), etc.`

⇒ Officially confirmed by JST: a trailing `(LF)(SN)` marks a **RoHS-compliant product**.
⇒ That JST page does **not** expand `LF` = lead-free or `SN` = tin. No other JST page I could fetch does.

**Distributor forum statement attributed to JST — NOT PRIMARY (DKF):**
Source: https://forum.digikey.com/t/jst-suffixes-lf-sn-au-s-n-m-prefixes-g-w-c-q-d/605
> `JST has offered the following information regarding these suffixes.`
> `Prefixed characters indicate the factory of origin while suffixed characters may indicate RoHS compliance and/or internal JST changes …`
> `(LF) = Lead-free. The finish would be 98% tin and 2% copper.`
> `(LF)(SN) = Lead-free with a 100% pure tin finish [SN is the Periodic Table of Elements symbol for tin]. This was an orderable part number, but as of this document … all versions are RoHs compliant and it is no longer needed, the base part number is sufficient.`
> `(LF)(AU) = Lead-free with a 100% gold finish [AU is the Periodic Table of Elements symbol for gold]. The gold finish would have a nickel underplate.`
> `(G) = Shanghai, China   (W) = Indonesia   (C) = Waukegan, Illinois, USA   (Q) = Korea   (D) = Malaysia` … `If there is no character prefixed to the part number, the country of origin is Japan`

**Second, more recent DigiKey forum thread — NOT PRIMARY (DKF2):**
Source: https://forum.digikey.com/t/why-does-my-part-have-an-lf-sn-suffix-but-it-does-not-show-this-as-the-ordering-part/60889
> `(LF)(SN) = Lead-free with a 100% pure tin finish [SN is the Periodic Table of Elements symbol for tin]. This was an orderable part number, but as of this document all versions are RoHs compliant and it is no longer needed, the base part number is sufficient to order but the (LF)(Sn) will still show on the label.`
> `See also the datasheet, page 3, note 1 which states: Note: 1. This product displays (LF)(SN) on a label.`

⚠️ That quoted "page 3, note 1" is on the JST datasheet **JST-PDF**
(https://www.jst-mfg.com/product/pdf/eng/ePH.pdf), which is the primary source for the note — but
I could **not** open the PDF to read it myself (PDFs are not readable by ordinary page fetching), so the note text
is a distributor's quotation, not a value I verified first-hand.

---

## COULD NOT VERIFY

1. **Digi-Key product pages — never retrieved.** `digikey.com` (product 926701) returned HTTP 403
   `Just a moment...` (Cloudflare) on three separate attempts; `digikey.in` also 403.
   No Digi-Key attribute value is quoted anywhere above.
2. **Mouser — never retrieved.** `mouser.com`, `mouser.in`, `mouser.de`, `eu.mouser.com` all failed
   (fetch error / `Access Denied` page).
3. **Farnell / element14 / Newark / CPC — never retrieved.** HTTP 403 Akamai `Access Denied` on
   `uk.`, `fi.`, `ch.`, `at.`, `in.element14.com`, `cpc.farnell.com`; `newark.com` fetch failed.
   Only URL **slugs** were observed (e.g. `header-top-entry-2way-2mm` for B2B-PH-K-S(LF)(SN),
   `connector-header-tht-r-a-2mm-2way` for S2B, `connector-header-smt-2mm-2way` for B2B-PH-SM4-TB);
   these are search-result URL text, **not** verified page content.
4. **RS Online / Distrelec / Elfa / TME / Arrow / TTI / OnlineComponents / trustedparts — all blocked**
   (403 or cross-origin redirect to rs-online.com).
5. **A single manufacturer-stated 3-axis body envelope (L × W × D)** was not found on any fetched HTML
   page. What is available is a composite: distributors give footprint+height (`5.90 x 4.50mm`,
   `Height 6.00mm` for the top-entry header), while JST's page gives `mounting height of 8 mm and a
   width of only 4.5 mm`. **The 8 mm figure conflicts with the distributors' 6.00 mm**; 8 mm matches
   ICZOOM's `Mated Stacking Heights: 8mm`, i.e. it is probably the mated height, not the bare header
   height — but no fetched page states this explicitly. UNRESOLVED.
6. **PCB hole / pin dimensions (drill diameter, pin cross-section).** Not stated on any fetched HTML
   page; they live only in JST drawings (PDFs, e.g. `B2B-PH-K-S.pdf`) which I cannot read.
7. **Contact finish thickness** (µin/µm): ICZOOM lists `Contact Finish Thickness: -` and no other fetched
   page states a value. UNVERIFIED.
8. **Per-contact insulation O.D. for SPH-002T-P0.5S / .5L.** LCSC states `0.8mm~1.5mm`; JST's page states
   the series-level `φ 0.5 mm to φ 1.5 mm`. Which range applies to the `-002T-` contact specifically is
   UNVERIFIED.
9. **"Lead free" / "RoHS" in words for the header part numbers.** HQ Online prints `Certification: RoHS`
   and `Lead Free Or Not: Yes` only on its **PHR-2** page; its header pages (B2B-PH-K-S(LF)(SN),
   S2B, B2B-PH-SM4-TB) carry no such row. LCSC marks PHR-2/SPH-002T-P0.5S/SPH-002T-P0.5L/S2B-PH-K-S(LF)(SN)
   as ROHS3 and B2B-PH-SM4-TB(LF)(SN) as ROHS, but the **B2B-PH-K-S(LF)(SN)** SKU's RoHS fields are `null`.
   The only authoritative "RoHS" statement for these suffixes is JST-ENV, which identifies the suffix
   symbols as RoHS-compliant markers (§7).
10. **SPH-002T-P0.5S vs SPH-002T-P0.5L differences other than wire range** — see §4. UNVERIFIED.
11. **The JST `ePH.pdf` note text** quoted in §7 — PDF not readable; quoted from a distributor forum.

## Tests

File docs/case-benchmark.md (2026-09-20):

# 外壳参数对标调研（商业键盘 + 社区方案）

**日期**：2026-09-21
**目的**：`docs/case-design.md` §6 那 6 个待定项（座高 / 定位板间距 / 上盖边框 / 电池引线 / 脚垫倾角 / 接缝）
不再靠假设，改用**商业键盘规格书 + 社区方案 + 器件原厂图纸**定值。
**方法**：先定「可比指标」，再查样本是否同构，再定值（守则见 `comparative-research-rigor`）。

---

## 0. 先定可比指标（否则会得出方向相反的结论）

| 待定项 | ❌ 不能直接抄的绝对值 | ✅ 归一化后的可比指标 | 样本必须满足 |
| --- | --- | --- | --- |
| 热插拔座占高 | 「某个键盘的板下净空 5 mm」 | **座体在 PCB 下方的单件尺寸**（mm） | **同一器件族**：Kailh MX 座（Mill-Max/Choc 的几何完全不同，不可混用） |
| 定位板间距 | 「某外壳总高」 | **板面相对 PCB 顶面**的高度（mm） | 同轴体系：MX（Choc 是 3.0–3.5 mm，不可比） |
| 螺丝柱 | 「柱粗 5 mm」 | **柱外径 ÷ 孔径**（倍数） | 同工艺：FDM 打印件（注塑/CNC 的壁厚规则不同） |
| 倾角 | 「脚垫高 2.4 mm」 | **角度（°）** + 样本深度量级 | 深度同量级（我们 155.7 mm ≈ Keychron Q1 的 145 mm；笔记本键盘不可比） |
| 接缝 | 「用几个销」 | **缝长 vs 能否手工对齐**（mm 判据） | 同为 FDM 分件 |
| 电池引线 | 「开 5 mm 孔」 | **通道尺寸 ÷ 线径** | 同一连接器族（JST-PH 2.0） |

---

## 1. 结论速览

1. **热插拔座在 PCB 下方只占 1.8 mm**（Kailh 原厂图纸明写 `1.80±0.05`）。我们此前假设的 **3.5 mm 高估了 1.7 mm**，
   而且与已有 15 mm 净空的构成**自相矛盾**：若真是 3.5 mm，电池压边顶面（z=15.0）会撞上座底面（z=15.5⁻）。
   ⇒ **`depth` 仍取 15.0，但理由必须改成**：座 1.8 + 压边 2.0 + 电池 10.5 + 余量 0.7 = 15.0。
2. **定位板三项参数可以定死，不必再等实物**：板面 = **PCB 顶面 + 5.0 mm**、板厚 **1.52 mm**、开孔 **14.0 × 14.0**（R ≤ 0.3）。
   三处都来自 Cherry MX 原厂图纸，且与社区惯例（5 mm / 1.5 mm / 14 mm）**一致**。定位板的高度由**轴体自身**锁定，
   外壳只需要「让开」而不是「托住」。
3. **M2 自攻柱要换成 M2 热熔螺母**：数据判据是「要反复拆装就用螺母、只装一次才用自攻」，
   而我们的壳**必须反复打开**（换电池、刷固件、调三档开关）。M2 螺母 → 孔径 3.0–3.2、柱外径 ≥ 5.5–6.0（**2× 规则**）。
4. **倾角取 5.5°**：商业/社区集中在 **5–7°**（Keychron Q1 官方 5.2°、社区共识「多数板 6–7°」）；
   脚垫用 **Ø8 × 3 mm 硅胶自粘**（社区与 3M Bumpon 主流规格 Ø8/Ø10 × 3–4 mm）。
5. **分件缝必须加定位结构**：我们缝长 **155.7 mm**，远超「纯对接手工能对齐」的 ~80 mm 判据
   ⇒ 加 **Ø4 × 8 mm 定位销 ×3，单边间隙 0.2 mm**（社区 FDM 分件标准做法）。

> ⚠️ 调研顺带查出**两个不属于外壳、但必须先处理的问题**（见 §4）：Kailh 官方推荐布局的轴孔是 **φ3.00**，
> 而我们自画封装仍是 1.27 PTH；电池座 JST-PH 额定 **2 A**，而 RGB 全亮峰值 2.4 A。

---

## 2. 样本表（含归一化列与来源等级）

**来源等级**：[DOC] 一手原厂规格书 / 官方规格页；[SRC] 源文件、源码；[REPORTED] 二手转述；[INFERENCE] 我的推断。

### 2.1 热插拔座占高（板下）

| 样本 | 原始值 | 归一化（板下占高） | 等级 | 来源 |
| --- | --- | --- | --- | --- |
| **Kailh CPG151101S11 原厂规格书**（KH-PS1607-10 Rev.B，2016-11）第 5 节外形尺寸 | **1.80 ± 0.05**（总高 3.05 ± 0.05） | **1.80 mm** | **[DOC]** | `datasheets/Kailh/CPG151101S11_MX_Socket.pdf`（本机已存 `.workbuddy/scratch/ds/`） |
| PCB 厂工艺指南（同一张规格表，EN/CN 两版同源） | 「1.8 mm Height Below PCB」 | 1.8 mm | [REPORTED] | hilpcb.com keyboard-pcb-layout |
| 社区 DIY 笔记（作者称读的是 Kailh 规格书） | 「sockets are 2 mm thick」 | ≈2 mm | [REPORTED] | dotat.at/cgi/git/kbd.git README |
| 二手教程 | 「高度约 2 mm；座体部分嵌在 PCB 里」 | ≈2 mm | [REPORTED] | splitkb.com 商品页、keeb.supply 文档 |
| MX 轴体塑料定位脚（反证） | 脚长 3.3 mm（Cherry 图）⇒ 穿过 1.6 mm 板后**露出 1.7 mm** | 1.7 mm | **[DOC]** | Cherry MX 规格书 p.1 |

⇒ **定值 1.8 mm（取原厂图纸，不用二手 2 mm；两者差 0.2 mm 已在余量里）**。

### 2.2 定位板 / 轴体高度

| 样本 | 原始值 | 归一化 | 等级 | 来源 |
| --- | --- | --- | --- | --- |
| **Cherry MX 原厂图纸** | 板面 = PCB 顶面 **+5.0**；板厚 **1.52**（0.06″）；开孔 **14.0 × 14.0**，R0.3 max | 板面 +5.0 / 板 1.52 | **[DOC]** | Cherry `mx_series.pdf` p.1/p.3 |
| 板厂（有 61 个键盘订单的生产数据） | 板厚「约 1.5 mm」；开孔标准 14 × 14；更厚轴卡不进、更薄轴会晃 | 1.5 / 14 | [REPORTED] | formulor.de 键盘板知识页 |
| 社区板测试件仓库（含 MX 实测公差表） | MX：标准 14×14、厚 1.5；公差窗 13.65–14.05 | 1.5 / 14 | [SRC] | github.com/krikun98/plate_testers |
| 社区 DIY 笔记 | 「板顶必须比 PCB 高 5 mm；板须 1.5 mm 厚」 | 5.0 / 1.5 | [REPORTED] | dotat.at 同上 |
| 高-profile 外壳围边高度 | 「围边应在板面之上 4.5 mm 或 6 mm（对齐键帽下沿）」 | +4.5~6.0 | [REPORTED]（引用 Cherry 规格书） | dotat.at 同上 |

⇒ **板面 +5.0、板厚 1.5（我们已有 374.71 × 127.06 定位板）、开孔 14×14** ✓

### 2.3 螺丝柱 / 紧固（FDM）

| 样本 | 归一化指标 | 值 | 等级 | 来源 |
| --- | --- | --- | --- | --- |
| 螺纹嵌件设计计算器（含环向应力推导） | **柱外径 ÷ 嵌件外径** | **2.0×**（膝点，低于 1.5× 应力涨 56%） | [REPORTED] | absurdtools.com 计算器 |
| 同上（M2 行） | 孔径 / 最小柱径 | M2 嵌件 OD≈3.2–3.6 → **孔 3.0–3.2、柱 ≥ 5.5** | [REPORTED] | printforgehq.com、meshra.ai |
| 电子外壳设计指南 | 自攻螺纹区壁厚 | **≥ 3 mm**；自攻孔 = 名义 **85%**（M2 → 1.7） | [REPORTED] | zbotic.in 外壳设计指南 |
| 同一指南（立柱反面） | 「高径比大的柱像棒棒糖」 | 需**加强筋 / 与墙相融** | [REPORTED] | absurdtools |
| 选型判据 | 拆装次数 | **要反复拆 ⇒ 热熔螺母**；只装一次 ⇒ 自攻即可 | [REPORTED] | meshra.ai、x3dstudios |

⇒ **改热熔螺母**：孔径 3.1、柱外径 6.0、孔深 = 螺母长 4 + 1 余量 = 5.0；
 **现有自攻参数（φ5.0 / 1.7 底孔）本身没错，但不符合「反复拆装」这条判据。**

### 2.4 倾角 / 脚垫

| 样本 | 原始值 | 归一化（角度 / 深度） | 等级 | 来源 |
| --- | --- | --- | --- | --- |
| **Keychron Q1 官方规格页** | 前高 21.6、后高 34.8、脚垫 2.4、**角 5.2°**（深 145） | 5.2° | **[DOC]** | keychron.com Q1 规格 |
| 社区综述（引 r/mk） | 「0–10°，**5–7° 是最常见出货角**」 | 5–7° | [REPORTED] | 0ldmate.com 外壳综述 |
| GeekHack 讨论 | 「多数板在 **6–7°**」 | 6–7° | [REPORTED] | geekhack.org 114324 |
| 高/低-profile 对比（2026） | 高-profile 铝壳 6–8°；低-profile 塑料 0–3° | 6–8 / 0–3 | [REPORTED] | attackshark.kr 知识页 |
| 脚垫（社区/电商主流） | Ø8 或 Ø10、厚 3–4 mm、3M 自粘 | Ø8–10 × 3–4 | [REPORTED] | keyhub、Adafruit 等 |

⇒ **取 5.5°**（落在 5–7° 簇内、贴近 Q1 的 5.2°）；脚垫 **Ø8 × 3 mm ×4**。
 几何后果 [INFERENCE]：155.66 × tan5.5° = **+15.0 mm** 后缘抬升 ⇒ 后高 ≈ 38.6 mm（Q1 为 34.8，量级一致 ✓）。

### 2.5 分件接缝

| 样本 | 归一化指标 | 值 | 等级 | 来源 |
| --- | --- | --- | --- | --- |
| FDM 分件指南 | **缝长 vs 能否手工对齐** | > **80 mm** 手工对不齐（0.5 mm 错位肉眼可见）⇒ 加定位销 | [REPORTED] | x3dstudios.com 分件指南 |
| 同上 | 销规格 / 间隙 | 销 **Ø4–6 × 8–10 mm**、**盲孔**、**单边 0.20 mm** | [REPORTED] | x3dstudios |
| 其他接合形式 | 单边间隙 | 燕尾 0.15、企口 0.20、滑配 0.20–0.30 | [REPORTED] | x3dstudios、rigidprints |
| FDM 尺寸能力 | 特征公差 | ±0.2 mm（小特征）；孔会**偏小 0.1–0.4** | [REPORTED] | rigidprints、km-studio |

⇒ **Ø4 × 8 mm 定位销 ×3，单边 0.2 mm**（销长 8 ≤ 壁厚允许？见 §3.4 —— 需要注意销落在**有肉的地方**）。

### 2.6 电池引线 / 连接器

| 样本 | 原始值 | 归一化 | 等级 | 来源 |
| --- | --- | --- | --- | --- |
| **JST PH 官方产品页 / 目录** | 间距 2.0、**额定 2 A (AWG24)**、100 V、适用线 AWG32–24、绝缘外径 **φ0.8–1.5** | 连接器高度 8.0（装好后）、座宽 4.5 | **[DOC]** | jst-mfg.com PH 系列 |
| 电池厂给的 PHR-2 尺寸（据厂商 CAD） | 壳体 **5.8 × 4.5 × 6.85 mm** | — | [REPORTED] | ydlbattery PH2.0 指南 |
| 社区键盘外壳线槽做法 | 通道 vs 线径 | 槽宽 ≥ 线径 + 0.3；线用**卡扣/扎带/热熔胶**做应力释放 | [INFERENCE]/惯例 | 见 §6 边界 |

⇒ 电池**在壳内**、接头在板上 ⇒ 不需要穿壁孔；需要的是：压边环上开一个 **宽 3.0 × 全高** 的过线缺口
 + 沿内腔底的**过线槽 2.0 宽 × 1.5 深**（够 AWG24 φ1.4 走线，留 0.6 余量）。

---

## 3. 推算与依据（[INFERENCE]，写清推断链）

### 3.1 板下 15 mm 的重新推导（结论：# 数值不变，理由变）

```
电池 10.5（已选电池厚）
+ 压边 2.0（现有 clip 参数：高出电池 2 mm）
+ 座体 1.8（Kailh 图纸，[DOC]）
+ 余量 0.7
= 15.0  ← 与现参数 depth=15.0 吻合
```
反证旧假设：座取 3.5 ⇒ 座底面 z = 17.5 − 3.5 = **14.0**，而压边顶面 z = **15.0** ⇒ **压边与座重叠 1.0 mm**，
即**旧参数在几何上自相矛盾**（预检 B 之前只算 `电池 + 座`、漏了压边，所以没报错 —— 本次一并修掉，见 §5）。

### 3.2 定位板为什么「不用外壳托」

MX 轴的工作方式是：轴体卡榫夹住定位板、同一次插入把引脚送进 PCB/座。板面高度因此由**轴体几何**唯一确定（+5.0），
外壳只要不顶到板、并且（可选）给板边留出**承台/限位**。⇒ §6 的 H2 从「待实测」降为「已定」。
**仍建议实测一项**：手上插座的**真实**板下高度（1.8 是图纸值，实物可差 0.1–0.2 mm）—— 但它已不卡设计。

### 3.3 柱径从 5.0 → 6.0 的连带影响

φ6 柱圆心在板边内 2 mm ⇒ 柱边伸到板外 1 mm，**必与 2 mm 侧壁相融**（预检 C 允许）。
副作用是好的：8 个柱全部落在墙线上（H3/H4 在左墙、H6/H7 在下墙、H1/H2 在右墙、H5/H8 在角上），
**「细长棒棒糖」问题自动消失**，不需要再加筋。⚠️ 与电池压边的净距从 2.2 → **1.7 mm**（仍 > 0.4 mm 喷嘴可打印 ✓），须由预检 D 复核。

### 3.4 定位销必须落在「有肉的地方」

销 Ø4 × 8 mm 需要两侧各有 ≥ 2 mm 实体。缝位于 `x = 189.70`，穿过的实体是 **2.5 mm 底板 + 两块侧壁**；
两块侧壁沿 y 方向长 155.66 mm —— 销必须**沿 y 方向布置**（穿壁的横截面），不能在薄底板里打横孔。
⇒ 实际做法 [INFERENCE]：在两件各自的**端壁上**做「半圆槽 + 销孔」，销沿 y 插入（即缝面法向），共 3 个位置（y ≈ 10 / 78 / 146）。

---

## 4. ⚠️ 调研顺带查出的两个问题（不属于外壳）

### 4.1 Kailh 官方推荐 PCB 布局的轴孔是 **φ3.00**，我们仍用 1.27 PTH

| 证据 | 内容 | 等级 |
| --- | --- | --- |
| Kailh 规格书第 9 节「Recommended PCB Layout」 | 两个 **φ3.00** 孔 @ **6.35** 间距 + 4 个 2.55×2.5 侧焊盘 + 2.54 偏移 | **[DOC]** |
| 社区文档（keeb.supply） | 「Kailh 座需要**专用封装**：**轴引脚原本的孔要更大**……座体填满两个大孔」 | [REPORTED] |
| 我们的自画封装 `docs/_tools/gen_footprints.py` | 保留官方 PTH **1.27** 轴孔 + B.Cu 侧焊盘，**标注 UNVERIFIED、列入 B6** | [SRC] |

⇒ **「直焊 PTH / 热插拔 SMD 二选一」在 1.27 mm 孔上不成立**（1.27 的孔无法同时容纳座的金属叶片）。
必须在**投板前**（不是装配前）定：① 只做热插拔（φ3.0 孔，放弃直焊兜底）；② 或改 Mill-Max 直插座（保留 1.27，但要另买件）；
③ 或先买一粒座+一块测试板实测。**这条建议在 B6 之前插一个 B6a（实物核对）**。

### 4.2 电池座额定 2 A，而 RGB 峰值 2.4 A

JST PH 官方：**2 A (AWG #24)** [DOC]。而 `docs/power-architecture.md` 记的 RGB 全亮峰值是 **2.4 A**。
按守则「改一个档位要把受影响的额定值过一遍」：这是**惯例 vs 合规**的分界（短时峰值超额定在消费电子里常见，
但代价要自己承担）。⇒ 列为待决策：接受（峰值仅瞬时、且发光非持续满载）／换更大连接器（如 XH 2.5）/ 降亮上限。

---

## 5. 对当前决策的意义（哪些变了、哪些没变）

| 项 | 原状 | 结论 |
| --- | --- | --- |
| 外形 379.31 × 155.66 × 23.60 | — | **不变** |
| 分件缝 x=189.70、8 孔位、三处开孔位置 | — | **不变** |
| `depth` 15.0 | 理由「座 3.5 + 电池 10.5 + 余量 1.0」（**与压边矛盾**） | **数值不变，理由改为**「座 1.8 + 压边 2.0 + 电池 10.5 + 余量 0.7」 |
| 预检 B 判据 | 只算 `电池 + 座` | **改**：加进压边（`电池 + 压边 + 座 + 余量`） |
| `boss_od` / 底孔 / 孔深 | 5.0 / 1.7 / 8.0（自攻） | **改** 6.0 / **3.1** / **5.0**（✅ **已改**，见 §7） |
| 定位板 5.0 / 1.5 / 14×14 | 「待实测」 | **已定**（原厂图纸） |
| 倾角 / 脚垫 | 未定 | **5.5°** + Ø8×3 硅胶脚垫（v2 实现：外底平、内腔与支撑面倾斜，避免打印悬空） |
| 上盖/边框 | 未定 | **保留低-profile**（现 `lip`=4.5 ⇒ 恰好比板面低 0.5 mm，不做围边）；若要高-profile 则 `lip` → 9.5–11.0（板面之上 4.5–6.0）[REPORTED] |
| 接缝 | 纯平面剖开 | **加定位销 3 处**（Ø4×8、单边 0.2、沿 y 布置） |
| 电池引线 | 无缺口 | 压边开 **3.0 宽全高缺口** + 底槽 **2.0 × 1.5** |
| 开孔宽度 11.0 / 10.0 | 按连接器体 | ⚠️ **待实测线缆**：USB-C 插头外壳常见 9–11 mm，按「连接器 + 0.3/边」的口径只覆盖到座体；插头是否够走位需量一根目标线（[INFERENCE]） |

---

## 6. 诚实边界

- **样本量**：全部是**便利样本**（能找到的规格书与社区文档），不是普查。商业键盘里**大厂不开源外壳 STEP**，
  也没有厂商公布「板下净空」「柱径」这类结构尺寸 ⇒ 结构性拿不到，只能用器件级图纸 + 社区惯例替代。
- **标称 vs 实测**：§2.1 的 1.8 是**图纸标称**（±0.05），实物可能有 0.1–0.2 偏差；我们**没有**实测过手上的座。
  §2.2 的 5.0/1.52 同样是图纸值（社区实测一致，可信度高）。
- **惯例 vs 合规**：§4.2（2 A 额定 vs 2.4 A 峰值）属「惯例允许、但要自己承担」；不要当成合规结论。
- **推断部分**：§3.3/§3.4/§2.6 的过线槽尺寸、§2.4 的后缘抬升计算均为 [INFERENCE]，**未经验证**。
- **找不到的**：「商业键盘外壳边框宽度」没有定量样本（只能从 FDM 壁厚规则反推 1.5–2 mm）；
  「USB-C 线缆外壳宽度」也无可靠公开统计 ⇒ 两处都标为待实测。

---

## 7. 参数落表（本次已落到代码/预检的值）

| 参数 | 旧值 | 新值 | 依据 |
| --- | --- | --- | --- |
| `boss_od` | 5.0 | **6.0** | M2 热熔螺母 2× 规则（≥5.5） |
| `boss_pilot` | 1.7 | **3.1** | M2 螺母孔径 3.0–3.2（PETG 取中值） |
| `boss_pilot_depth` | 8.0 | **5.0** | 螺母长 4 + 1（熔料让位） |
| `depth` | 15.0 | 15.0（**理由改**） | §3.1 |
| 座高（预检 `SOC`） | 3.5（假设） | **1.8** | Kailh 图纸 [DOC] |
| 倾角 `tilt_deg` | — | **5.5**（v2 实现） | Q1 5.2° / 社区 5–7° |
| 脚垫 `foot_dia` / `foot_h` | — | **8.0 / 3.0** | 社区 Ø8–10 × 3–4 |
| 缝销 `seam_pin_dia/len/clear` | — | **4.0 / 8.0 / 0.2** | FDM 分件指南 |
| 过线缺口 `clip_notch_w` | — | **3.0** | JST-PH 壳体 4.5 宽、线 φ1.4 |

**待你拍板的两项**（都能一行改）：① 倾角 5.5° 是否接受（后缘高 ≈38.6 mm）；② 低-profile（现状）还是高-profile（`lip` 9.5–11）。

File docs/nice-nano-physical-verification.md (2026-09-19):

# B6：nice!nano v2 采购与实物核对清单

> 目标：**投板前**用真实模块核对两个决定性尺寸 —— ① 排针（pitch / 每边脚数），
> ② 板载 USB-C 座相对板边的位置与朝向（决定外壳开孔）。
> 本文件分两部分：**拿货前的桌面预研基准值**（分来源与可信级）+ **拿到实物后的逐项量测清单**
> （每项给出量法、预判值、偏差处置）。
> ⚠️ 所有「预判值」均来自旁证（社区封装库 / 第三方模型 / 零售商页面），
> **在 §3 打勾之前不得当作事实写进外壳图纸**（handoff §10.2 第 9 条：实测与旁证必须分开记）。

状态：🟡 **实物已到货，量测已完成大半（2026-09-19）**——§6 是量测结论，
**发现 J3A/J3B 孔数设计错误（12 → 应为 13），详见 §6.1，修复方案见 §6.3**。

---

## 1. 采购清单

| 物料 | 数量 | 用途 | 备注 |
| --- | --- | --- | --- |
| **nice!nano v2** | **2 块** | 1 块装机 + 1 块做 C7 ESB 端点验证 | 官方渠道 nicekeyboards.com（约 $25）；国内电商有售时注意甄别**兼容板**——SuperMini 等克隆板已被 ADR-0003 降级为「焊盘兼容、不保证」，**克隆板待机电流批次差异极大**（好板 4 µA / 差板 60 µA，见 `controller-and-battery-facts.md` §1.1） |
| **XIAO nRF52840** | 1 块 | C7 ESB 验证（决定 Dongle 方案 A/B） | 物料与判据见 `docs/esb-endpoint-validation.md` |
| **12-pin 排针** | 随模块附 2 条 | 插到我们 PCB 的 J3A/J3B 母座上 | nice!nano v2 包装内含 2× 12-pin + 1× 3-pin 排针；**收货时清点** |
| USB-C **数据线** | 1 条 | 刷固件 | ⚠️ 必须是数据线，纯充电线刷不了 UF2 |
| 游标卡尺（0–150 mm） | 1 把 | 本清单全部量测 | 精度 0.02 mm 足够；没有卡尺用直尺只能做 §3 的 A2（11 个间隔合计 27.94 mm，误差会被摊薄到可判读） |

我们 PCB 这边的配套件（已在设计内，仅提醒采购主板物料时别漏）：J3A/J3B = `PinSocket_1x12_P2.54mm` 立式母座 ×2。

---

## 2. 桌面预研基准值（拿货前的旁证汇总）

### 2.1 排针（决定我们 J3A/J3B 是否插得进去）

| 项 | 预判值 | 来源与可信级 |
| --- | --- | --- |
| 每边脚数 | ~~12~~ → **13**（❌ **预判已被实物证伪**，见 §6.1） | marbastlib 封装只画了「Pro Micro 兼容 12 孔」子集、零售商只写「2x 12-pin headers」——**两处旁证都数漏了 USB 端多出的电源孔**；官方 pinout 图（nicekeyboards.com）+ 实物清点均 = 13 |
| pitch | **2.54 mm** | 同上 + Pro Micro 标准 ⇒ **可信** |
| 两列间距 | **15.24 mm** | marbastlib 封装 pad x = ±7.62；**我们 PCB 的 J3A(y=4.38)/J3B(y=19.62) 正是按 15.24 布的** ⇒ 互相印证 |
| 排针针位跨度 | **27.94 mm**（11 × 2.54） | marbastlib pad y = −13.97…+13.97 |

### 2.2 板外形（三处来源**互相矛盾** ⇒ 必须实物定案）

| 来源 | 板长 | 板宽 | 厚 |
| --- | --- | --- | --- |
| marbastlib 封装轮廓（Pro Micro 标准） | **33.02** | 17.78 | — |
| 零售商页面（mechboards） | **34.1**（疑含 USB 座凸出） | 18.3 | 3.3（总高）/ PCB 1.6 |
| 第三方 STEP 模型（marathon-os） | **34.00** | 17.80 | 3.16（总高） |

⇒ 长度 33.02 vs 34.1 差 **1.1 mm**：直接影响「USB 座口到键盘板边的距离」与外壳开孔 ⇒ **以卡尺实测定案**。

### 2.3 板载 USB-C 座（决定外壳开孔的一切）

| 项 | 预判值 | 来源 |
| --- | --- | --- |
| 形态 | **mid-mount**（座子嵌在板边内），官方口径 3.2 mm 总高 | 零售商 / openhardware.directory，一致 ⇒ 可信 |
| 座子 X 向位置 | **板宽方向居中** | marbastlib（USB 注释块 −3.55…+3.55）+ nRF52840-promicro 逆向件（X 居中）⇒ 双旁证 |
| 座子口面伸出板边 | **约 1.52 mm**（座体宽约 7.1 mm） | marbastlib Cmts.User 矩形（−19.3…−14.2 vs 板边 −17.78），**单旁证** |
| 座子在板长方向的位置 | 距 pin 1 端约 **2.8 mm**（座中心）、口面距 pin1 端约 5.3 mm | 同上 |

### 2.4 天线（顺手核对，不阻塞投板）

marbastlib 在封装里画了一块 `ANT` keepout：**天线在 USB 的对侧（pin 12/24 端）**，
沿板长方向伸出板边约 5 mm、横向超出板宽约 ±5 mm。
⇒ 插到我们板上后，天线区大致覆盖键盘板 **x ≈ 50–60 mm、y ≈ 0–26 mm**（模块中线 y=12）。
该区域下方是我们 In1（GND 平面）/ In2（VLED 平面）/ B.Cu（GND 铺铜）——
「是否给天线挖空铺铜」属旁证级建议、无强规范 ⇒ 记为 **B6 之后的决策项**，量测时顺手记下天线实际位置即可。

---

## 3. 拿到实物后的量测清单（逐项打勾）

> 量法约定：pitch 不要单个量（2.54 mm 手抖就废），**量首尾两个针的总长再除以间隔数**。

### A. 排针（插不进 = 全盘返工，最先量）

| # | 项 | 量法 | 预判 | 判据 / 偏差处置 |
| --- | --- | --- | --- | --- |
| A1 | 每边脚数 | 数 | 12 + 12 | ≠12 ⇒ 停：J3A/J3B 封装与外壳全要改，回报再议 |
| A2 | pitch | 量 pin1→pin12 总长 ÷ 11 | 27.94 mm | ±0.2 mm 内 ⇒ 合格；超差 ⇒ 量 pin1→pin2 单距复核，回报 |
| A3 | 两列间距 | 量两条排针中心距 | 15.24 mm | ±0.2 mm；超差 ⇒ J3A/J3B 坐标要改（`pcb_design.py`） |
| A4 | 插入验证 | 把模块（焊好排针）**真的插进样板或母座** | 顺滑到位 | 歪斜/过松 ⇒ 换母座型号；此步最晚在投板前用面包板母座即可做 |

### B. USB-C 座（决定外壳开孔）

| # | 项 | 量法 | 预判 | 判据 / 偏差处置 |
| --- | --- | --- | --- | --- |
| B1 | **USB 在哪一端** | 目视：USB 端是 pin1（TX0/标号 D1 侧）还是 pin24（RAW） | **pin 1 端**（Pro Micro 惯例 + marbastlib） | 若在 pin24 端 ⇒ §4 预判落点整体镜像到 x≈73 mm，外壳开孔重新算 |
| B2 | 座子中心距 pin1 端板边 | 卡尺 | 板边在 pin1 外 3.81 mm，座中心再进 2.8 mm | 记实测值，代入 §4 公式 |
| B3 | 口面伸出量 | 卡尺量座口到板边 | 伸出约 1.5 mm（mid-mount） | 缩进板内则开孔要贴紧板边、余量更小 |
| B4 | 座子口宽 | 卡尺 | 约 7.1 mm | 开孔按「口宽 + 2 mm」起步 |

### C. 板外形（定外壳）

| # | 项 | 预判 | 处置 |
| --- | --- | --- | --- |
| C1 | 板长 × 板宽 × PCB 厚 | 见 §2.2 三来源矛盾，**实测定案** | 取代 §2.2 全部旁证 |
| C2 | 总高（含元件、USB 座） | 约 3.2–3.3 mm | 进外壳底壳净空与电池仓深度核算 |

### D. 顺手记录

| # | 项 | 预判 | 用途 |
| --- | --- | --- | --- |
| D1 | 天线实际位置（哪一端、距板边） | USB 对侧 | §2.4 的铺铜决策 |
| D2 | 板载充电档跳线位置 | 100/500 mA 焊接选择 | 我们电池 10 Ah，**确认置于 500 mA 档**（虽由 BQ24072 主充，模块档位影响 USB 直插调试时的安全） |
| D3 | 蓝灯（P0.15）/ VCC 门控（P0.13）引脚与丝印 | 官方口径 | 与固件假设复核（`verify_firmware.py` 已按此两脚留空） |

---

## 4. USB 落点：预判 → 实测修正后的最终值（B6-1 改版后）

我们板上 J3A / J3B（改造后 `PinSocket_1x13`，rot=90）几何（解析 `Starshield.kicad_pcb`）：

- J3A：孔1 世界坐标 **(37.46, 4.38)**，孔13 **(67.94, 4.38)** —— 针位沿 X 向，pitch 2.54
- J3B：孔1 **(37.46, 19.62)**，孔13 **(67.94, 19.62)** —— 两列间距 15.24 ✅
- 模块中线 **y = 12.0 mm**（距键盘板上边缘 12 mm）
- ⚠️ 改造前是 1×12、首孔在 x=40；**2026-09-19 B6-1 起首孔移到 x=37.46**
  （新增的正是 USB 端那第 13 孔，见 §6.2/§6.3）

按**实测**（孔1 → USB 口面 = 5.3 mm，实物卡尺）：

| 量 | 值（键盘板坐标系，原点 = 板左上角） |
| --- | --- |
| **USB 座口面** | **x ≈ 32.2 mm，y ≈ 12 ± 3.6 mm，朝 −X（键盘左侧）** |
| 模块板边（USB 端） | x ≈ 37.46 − lip A（lip A = 孔1 到板边距离，待补量测） |

⚠️ **实测结论（2026-09-19 晚，插头已量：d1 = 7、d2 = 28、w = 13×7）**：
座口距键盘板左边缘 **32.2 mm** ⇒ 插到位时**握持部落在壳内**（后端距板边 4.2 mm），
而插入过程中握持部必须穿过开口 ⇒
**「底壳侧壁开孔」不能只开线径小孔，至少需要 ≈14 × 8 mm 的圆角孔**；
且拔插只能捏线（握持部在壳内 4–16 mm 处）。
⇒ 详见 §6.4 的分叉表：**A 维持现布局 + 大孔** / **B 下代板把 J3A/J3B 转 90°（USB 朝上边沿，开孔缩到 ≈10 × 5）**。
**本项待用户拍板后才写进 `power-architecture.md` §4 与外壳模型。**

---

## 5. 完成后要回写的地方（防旧值残留）

- [ ] 本文件 §3 全部打勾 + 实测值表
- [ ] `controller-and-battery-facts.md` §1.1「主排针布局」行（去掉 ❓）
- [ ] `power-architecture.md` §4 开孔段（定孔位坐标）
- [ ] `PROJECT_HANDOFF.md` §8 表「nice!nano 排针」行 + §9.1 B6 条目
- [ ] 外壳建模（G4）启动前，把 §4 落点换算成壳体开孔坐标

---

## 6. 量测结论（2026-09-19，实物到货当日）

### 6.1 已确认的实测值

| 项 | 实测 | 与预判对比 |
| --- | --- | --- |
| 板长 | **34.0 mm** | 取 34.0/34.1 一侧 ✅（marbastlib 的 33.02 系 Pro Micro 兼容子集，偏小） |
| 板宽 | **18.0 mm** | 取 18.3/17.8 之间 ✅ |
| pin1 → USB 口面 | **5.3 mm** | 与 marbastlib 预判 5.3 **完全一致** ✅ |
| USB 座口宽 | **7.1 mm，板宽居中** | 与预判一致 ✅ |
| 总高 | **3.3 mm** | 预判 3.2–3.3 ✅ |
| **每边孔数** | **13** | ❌ **预判 12 错误**（旁证双重误导：marbastlib 封装与零售商都按 Pro Micro 2×12 抄） |

**补充实测（2026-09-19 晚，用户复量）**：lip A / lip B（首末孔到板边）与
**两排孔距 15.24**、**孔1→孔13 = 30.48** 均**与预判一致** ✅
（⇒ 孔距确认为 2.54，J3A/J3B 相对位置无需改）。
插头三尺寸：**d1 = 7、d2 = 28、w = 13 × 7 mm**（判据见 §6.4）。

### 6.2 🔴 发现的设计错误：J3A/J3B 必须从 1×12 改为 1×13

官方 pinout（nicekeyboards.com 原图，本机留档 `.workbuddy/scratch/pinout-v2-a6d36.png`）
确认 nice!nano v2 = **2×13 = 26 孔**，比 Pro Micro 每排多 1 孔——**多在 USB 端**：
左排顶端多 1 个 GND、右排顶端多 1 个 B+（故右排 B+ 有两个孔）。
这也解释了板长 34.0 ≠ Pro Micro 33.02。
（21 GPIO 口径不变：主排针 18 个 D 脚 + 背面 3 个焊盘 P1.01/P1.02/P1.07。）

**对现设计的影响**（`control_design.py` 的映射逐孔对照官方顺序）：

- 左排：我们的 J3A.1（LED_DIN = D1/P0.06）会插到实物的 **GND 孔**上 —— **整排错位一孔**；
- 右排：J3B.1（OUT→RAW/B+）恰好对上 B+ #1（侥幸），但 J3B.4（VCC）会插到实物的
  **RESET 孔**上 —— **VCC 短接复位，致命**；
- **固件 overlay 无需改动**：所有 D 编号（D2/D14/D18 模式、D19/D15/D16 五95、D4–D9 行、
  D1 RGB 数据、D10 门控）与 ZMK gpio-map 的对应关系不变，变的只是物理孔位。

**修正后的插座映射**（新 J3A/J3B = 1×13，编号 = 实物孔位序号，自 USB 端起）：

| J3A（左排） | 网 | | J3B（右排） | 网 |
| --- | --- | --- | --- | --- |
| 1 | GND | | 1 | OUT（B+ #1） |
| 2 | LED_DIN（D1/P0.06） | | 2 | OUT（B+ #2，同网冗余） |
| 3 | NC（D0/P0.08） | | 3 | GND |
| 4 | GND | | 4 | NC（RESET） |
| 5 | GND | | 5 | VCC（3.3V） |
| 6 | MODE0（D2/P0.17） | | 6 | NC（D21，ADC 保留） |
| 7 | NC（D3/P0.20） | | 7 | NC（D20，ADC 保留） |
| 8 | ROW0（D4/P0.22） | | 8 | 595_RCLK（D19/P0.02） |
| 9 | ROW1（D5/P0.24） | | 9 | MODE2（D18/P1.15） |
| 10 | ROW2（D6/P1.00） | | 10 | 595_SCK（D15/P1.13） |
| 11 | ROW3（D7/P0.11） | | 11 | MODE1（D14/P1.11） |
| 12 | ROW5（D8/P1.04） | | 12 | 595_MOSI（D16/P0.10） |
| 13 | ROW4（D9/P1.06） | | 13 | RGB_PWR_EN（D10/P0.09） |

### 6.3 修复方案与执行结果（✅ 2026-09-19 已完成）

**关键洞察（决定了整个修法的简单程度）**：官方孔序去掉第 1 孔后，与我们现有 12 个焊盘的网
**逐孔完全一致**（已用脚本逐项核对）：

```
J3A  official[1:] == 现有 [LED_DIN, NC, GND, GND, MODE0, NC, ROW0..ROW3, ROW5, ROW4]  ✓
J3B  official[1:] == 现有 [OUT, GND, NC, VCC, NC, NC, 595_RCLK, MODE2, 595_SCK,
                          MODE1, 595_MOSI, RGB_PWR_EN]                                ✓
```

⇒ **只需在 USB 端左侧（x = 37.46）加一个孔**（J3A 加 GND、J3B 加 OUT），
再把 Pad 号整体后移一位 —— **走线一根都不用动**：

| 步骤 | 内容 | 结果 |
| --- | --- | --- |
| 1 | 符号缓存加 `Conn_01x13`（`extract_power_symbols.py` 的 WANTED 表） | ✅ |
| 2 | `control_design.py`：J3A/J3B 改 `Conn_01x13`、CONN 表按官方孔序重排、页脚注更新 | ✅ |
| 3 | `gen_control_sch.py` 重生成控制子图（版式自检通过） | ✅ |
| 4 | 校验器断言同步（`verify_control` / `verify_rgb`，孔号 + LED_DIN 落孔） | ✅ |
| 5 | PCB：加第 13 孔 + 重排 Pad 号 + J3B 孔1-孔2 的 OUT 同网桥 + 重填铺铜 | ✅ |
| 6 | DRC + 七项校验器全绿；生成链确定性复核（重跑后 git status 无变化） | ✅ |

**❌ 已否决的做法（勿重试）**：把「网络整体后移一孔」、只移动走线端点 ——
实测撞出 **8 处 `shorting_items` + 2 处 `tracks_crossing` + 1 处 `clearance`**
（走线变成斜线后穿过邻孔、且要连带搬过孔）。**加一孔方案才是唯一正解。**

⚠️ **本次执行中发生过一次严重事故（已修复）**：迁移脚本用了
`open(P,"wb").write(open(P,"rb").read()...)` 的单行写法 —— `"wb"` 先把文件截断成 0 字节，
读回来自然是空的 ⇒ **6.5 MB 板文件被写成 0 字节**。靠落盘前的备份救回，
正确写法必须先读进变量再写（见 handoff §10.2 新增条目）。

### 6.4 仍待补的量测（不阻塞原理图修复）

| 项 | 用途 |
| --- | --- |
| 第 1 孔中心 → USB 侧板边（lip A）、第 13 孔中心 → 远端板边（lip B） | 校验 A + 30.48 + B = 34.0；推导 USB 口伸出量（= 5.3 − lip A，预判 1.5，但 13 孔下 lip 总和只有 ~3.5，**伸出量可能明显大于 1.5，直接影响开孔深度**） |
| 两排孔中心距（预判 15.24） | 确认 J3A/J3B 相对位置无需改 |
| pin1 → pin13 实距（预判 30.48） | 确认孔距确为 2.54 |
| 数据线插头（三尺寸，判据见下） | 判定 §4 的 **≈32.2 mm 插线临界问题**——决定外壳开孔尺寸与方案 |

**④ 插头怎么量、怎么判**（口面距壳体左壁内表面 ≈ 32.2 mm + 壳壁厚）：

卡尺量三个值（用**真正打算用的那条线**，换线要重测）：

| 记 | 量什么 | 典型值 | **实测（2026-09-19）** |
| --- | --- | --- | --- |
| `d1` | 插头金属尖端 → 插入段（金属壳）末端 | 7–9 mm | **7 mm** ✅ |
| **`d2`** | 插头金属尖端 → **握持部（塑料壳）后端面** | **25–45 mm** | **28 mm** |
| `w` | 握持部截面（宽 × 厚） | 约 13 × 8 mm | **13 × 7 mm** |

**判据（⚠️ 2026-09-19 修正：早先「d2 ≤ 30 ⇒ 线径级开孔」的结论是错的）**

错在哪：当时只看了「插到位后握持部在哪」，**漏了「插入过程中握持部必须从外面穿过开口」** ——
只要握持部最终落在壳内，它就一定要能通过开口，开孔尺寸因此由 **`w`（13 × 7）** 决定，
与 `d2` 大小无关。正确的判据只有一条：

> 握持部是否会落在壳内？——会 ⇒ 开口至少要把 **13 × 7** 放过去（+0.5–1 mm 余量）。
> 只有当口面距壳壁 **< `d2` − 握持部长（≈16 mm）** 时，握持部才整体留在壳外、开口才能缩小。

**本项目实算**（口面距壳壁 ≈ 32.2 mm，`d2` = 28）：

| 项 | 值 |
| --- | --- |
| 插到位时插头占据范围 | x ∈ **[4.2 mm, 32.2 mm]**（握持部后端距板边 4.2 mm） |
| 握持部是否在壳内 | **是**（且插入全程必须穿过开口） |
| ⇒ 左壁开孔需求 | **≈ 14 × 8 mm 圆角孔**（不是线径小孔） |
| 操作影响 | 握持部在壳内 4–16 mm 处，拔插只能捏线 ⇒ 有拉线风险 |
| 要让开口缩到 ≈10 × 5 mm 的条件 | 口面距壳壁 **< 16 mm**（即 J3A 孔1 距板边 ≤ 21 mm） |

**因此外壳方案在 B6 结束后出现一个必须拍板的分叉**。
**用户已明确目标：口面与壳面齐平（对齐商业键盘的外观）。**
✅ **2026-09-19 晚：用户拍板走方案①，并已实施**（新坐标见下）。

| 方案 | 做法 | 结果与代价 |
| --- | --- | --- |
| ✅ **① 模块移到肩部最左 + `J1` 让位**（**已采纳**） | J3A/J3B 左移 **30.46 mm** ⇒ 孔1 x = **7.00**、**口面 x = 1.70**；`J1`/`R1`/`R2`/`F1` 让出左上角，移到 595 链与电源段之间的空档（x = 155–168） | **口面距板边 1.7 mm ⇒ 与壳内壁几乎同平面** = 商业键盘观感；左壁开孔缩到 **≈10 × 5 mm** 且与口面严丝合缝；握持部留在壳外、拔插正常（1.7 ≪ 16 mm 判据）✅。代价：肩部该区走线重布（其余布线不动）；⚠️ 模块天线端随之移到 x ≈ 37–44（keepout 区，勿在该处放铜/件） |
| ② 壳内装 USB-C 面板延长线 | 公头插模块（装配时预先插好），母口固定在壳壁 | 外观同样齐平、**零改板**；代价：多一个零件 + 一条内部走线，新手装配多一步；❓ 模块上/下净空仅 2–4 mm，弯头走向需实物验证 |
| ③ 维持现布局 + 左壁大孔 | 开 ≈14 × 8 mm 圆角孔 | 零返工，但**达不到齐平**；握持部在壳内、拔插只能捏线（见上表） |
| ④ 模块转 90°、USB 朝前壁 | 与 `J1` 并排两个前壁口 | 最像商业键盘的「双口并排」，但模块长 34 mm > 现肩深 24 mm ⇒ **控制肩要加深到 ≈38 mm**，板框 / 全部键位 / 定位板 / 外壳一起动 —— 改动最大 |

**① 带来的连带变更（需同步到外壳与文档）**：

| 项 | 变化 |
| --- | --- |
| 模块 USB 口 | 左壁开孔，位置 = 口面 x 1.70、y = 12.0（模块中线）；**孔 ≈10 × 5 mm** |
| 我们自己的 `J1`（充电口） | **从左上角移到前壁 x ≈ 160**（仍是前壁开口，只是位置右移） ⇒ 外壳前壁该口的开孔坐标要跟着改 |
| 键区 / 定位板 / 板框 / 肩高 | **一律未动**（只动了肩内的 6 个元件） |
| 天线 | keepout 区移到 x ≈ 37–44、y ≈ −2…26 ⇒ 该处不放铜/件（原先已被标为待评估项） |

> 📌 参考：我们自己的 `J1` **本来就是齐平的**（焊盘在 y = 1.46、本体 y ∈ [−1.0, 11.4]，
> 即口从板的上边沿伸出）⇒ 方案① 做完后，两个 USB-C 口都齐平。

### 6.5 为什么我们有两个 USB-C 口？——与商业键盘的对标（2026-09-19）

**用户质疑（成立）**：商业键盘都是一个口搞定充电 + 有线 + 刷固件，哪有分两个的。
**结论：这不是设计疏忽，而是「插座式模块 + 大电池」这一架构的必然结果。**

| 样本 | 架构 | USB 口 | 来源等级 |
| --- | --- | --- | --- |
| NuPhy 无线键盘 | **集成 MCU** | **1 个口**：有线模式同时充电、同一口刷固件 | [DOC] 官方使用指南 / 固件页 |
| nice!nano 官方 getting-started | **插座式模块** | 电池接 B+/B−，**充电走模块自带充电器**，刷固件走**模块那个 USB-C** ⇒ 天然 1 个口 | [DOC] 官方文档 |
| nice!nano 官方电池规格页 | 同上 | ⚠️ **「电池最大建议 2000 mAh，超过可能损坏电池和/或 nice!nano」**：理由是理想充电率 0.25–0.5C，模块只有 100/500 mA；过小电流属 trickle，长期会让电芯内阻升高、**最终充不进去或把充电器烧掉** | [DOC] 官方文档（原文） |
| nice!nano v2 官方原理图 | 同上 | 模块充电块标题 = **「Charging and Power Path」**，引脚 EN1/EN2/ILIM/ISET/TS/TMR/PGOOD/OUT/BAT ⇒ **就是 BQ2407x 家族（与我们自选的 BQ24072 同款架构、同样带电源路径）**，只是电流档为 100/500 mA | [SRC] 官方原理图（本机留档 `.workbuddy/scratch/nn_charge2.png`） |
| ebastler ZMK 设计指南 | 自绘无线板 | 1 个 USB-C 同时做数据与充电（并指出 TP4056 一类**无电源路径**的充电器不能边充边用） | [DOC] 开源设计指南 |
| **本项目** | **插座式模块 + 10 Ah 电池 + 自研 1 A 充电** | **2 个口**：模块口（数据/刷固件/有线）+ 自建充电口 | — |

**推理链 [INFERENCE]**：
1. 模块唯一的 USB 数据通路在它自己的 USB-C 上（nRF52840 的 D+/D− 是专用引脚、不在排针上）
   ⇒ **刷固件与「有线模式」必须用模块那个口**，这是硬约束。
2. 若把模块口当唯一对外口 ⇒ 充电也只能走模块的 100/500 mA 充电器
   ⇒ 对 10 Ah 是 **0.05C（trickle）**，正是官方明确警告的用法；充满需 **≈20 h**。
3. 所以「单口 + 10 Ah」在官方口径下不成立；而「单口 + 我们自研 1 A 充电」也不可能 ——
   方案① 把模块口贴到左壁之后，**壳内已没有空间往模块口里插内部跳线**（口面距壁仅 1.7 mm）。

**⇒ 只有三条路**：

| 路线 | 做法 | 代价 |
| --- | --- | --- |
| **甲：真正的单口**（最像商业键盘） | 只保留模块口；**删掉 J1 + 自研充电（U1/F1/R1/R2/R3..R5/C1..C3/D96 ≈12 件）**；充电走模块 | ⚠️ **电池必须降到 ≤2000 mAh**（官方上限）⇒ 续航从「数月」降到「约一周」；自研充电的全部取值工作（ADR-0002 / P13 / ILIM·ISET·TMR）作废；换来 USB 合规（500 mA 不超声明）+ 元件大幅减少 |
| **乙：两口（现状）** | 模块口（左壁 y=12）+ 自建充电口（前壁 x=160） | 外观是两个孔；技术上最稳（1 A ≈10 h、电源路径齐全、充电归自家电路好排查） |
| **丙：两口但做得像一体** | 保留两口，把两个孔做成同样规格的圆角紧凑造型、同色面板，教程里明确「左=数据/固件，前=快充」 | 仍需用户理解两个口的用途；但零电气代价 |

⚠️ **诚实边界**：① 商业样本只逐台核实了 NuPhy（其余 Keychron 类为二手描述）；
② 模块充电器的 `TMR` 具体接法因官方原理图分辨率不足**未能读出** ⇒ 是否装了安全定时器
（若装了，10 Ah @500 mA 会在定时器到点后停充）标 ❓ UNVERIFIED；
③ 我们**没有实测**模块对 10 Ah 包的充电行为，上表第 2 条的推理基于官方书面警告。

### 6.6 「有线模式下能不能充电」——商业与社区做法 + 我们的一处接线偏差

**用户质疑（成立）**：保留两口的话，插模块口跑有线模式时充不了电，得再插一根线到充电口。

**(1) 商业键盘：一口，插线即「数据 + 充电」**（一手/官方口径）：

| 机型 | 原文 | 等级 |
| --- | --- | --- |
| Kisnt KN85 | 「透過 USB-C 連接線連接時，它會在有線模式下運行，**並同時為內建 4000mAh 電池充電**」 | [DOC] 商品页 |
| 雷柏 V700-8A | 「这个 Type-C 接口**兼具连接电脑作为外设和充电**的作用」 | [DOC] 评测/官方宣传 |
| CHERRY KW 9200 MINI | 「Removable USB-A to USB-C cable for **data transfer and charging** the lithium battery」 | [DOC] 官方规格页 |
| Keychron 无线 | USB-C 既是充电口也是有线数据口 | [REPORTED] |

**(2) 社区（nice!nano 生态）：同样是有线即充，因为它把电池挂在模块自己的充电器上。**
官方 getting-started 的接法是「电池 → `B+/B−`（即 RAW/GND）」，模块自带 BQ24075
（带电源路径）**直接对电池充电** ⇒ 插进模块口的任何一根线都在给电池充电（100/500 mA）✓
⇒ 社区方案**只有一个口，且有线模式天然充电**。

**(3) 我们的偏差（问题根源）**：我们把电池接在**自研 BQ24072 的 `BAT`**，而把模块接在
**BQ24072 的 `OUT`**（系统轨）。于是插模块口时，模块的 BQ24075 只能把电流灌进我们的 `OUT`
轨 —— 而 `OUT→BAT` 这条回灌路径**不是设计的充电路径**，能否导通取决于芯片内部
`BAT↔OUT` 通路的方向与状态，**属未验证项 ❓，不应依赖** ⇒ **有线模式下充不上电** ✅ 用户判断正确。

**(4) 最小修法（一行网络改动，推荐）**：**把模块的 `B+/RAW`（J3B 孔1/孔2）从 `OUT` 改接电池节点 `VBAT`**
= 回到社区/官方标准接法。✅ **2026-09-19 用户拍板采纳，已实施**（`control_design.py` / `power_design.py`
把 `VBAT` 升为跨子图全局网、两处子图重生成、`verify_control` 断言改为 VBAT、板文件 J3B 孔1/2 改网）。
改完后：

| 场景 | 改前 | 改后 |
| --- | --- | --- |
| 插模块口（有线模式） | 能打字、**不充电** | ✅ 能打字 + **模块充电器给电池充 500 mA** |
| 插充电口 | 1 A 快充 ✅ | 1 A 快充 ✅（不变） |
| 两支线同时插 | — | 两个充电器并联给电池（1.5 A = 0.15C，安全）；**建议模块保持默认 100 mA 档** ⇒ 合计 1.1 A |
| 模块供电 | 来自 `OUT`（插充电口时也有电） | 来自**裸电池**（社区标准）；⚠️ 电池极低（<3.5 V）时 VCC 3.3 V 可能不足，且**「不装电池、只插充电口」时模块不上电**（须插模块口） |
| `VLED` 灯轨 | 由 `OUT` 门控供电（不变） | 不变 ✅（BQ24072 的电源路径仍服务于灯轨） |

⚠️ 连带改动面：`power/control` 两个子图 + `ADR-0002` 的接线说明 + `verify_power` / `verify_control`
的断言（现断言为「B+ 接 OUT」）+ `power-architecture.md` §1（"负载必须接 OUT" 的对象变成
"灯轨与其它负载"，主控改为接电池节点）。

**(5) 顺带核实（重要）**：nice!nano v2 右列孔序经官方 pinout 超级放大确认为
**B+ / RAW / GND / RST / VCC / P0.31(D21) / P0.29(D20) / P0.02(D19) / P1.15(D18) /
P1.13(D15) / P1.11(D14) / P0.10(D16) / P0.09(D10)** —— 与我们 B6-1 改完的 J3B 映射**逐孔一致** ✅
（孔1/孔2 都是电池正极等效端：`B+` 与 `RAW`，官方文档明确「RAW 与 GND 分别是 B+ 与 B− 的等效」）。
左列同样确认为 GND / D1 / D0 / GND / GND / D2…D9 ✅ 与 J3A 映射一致。
证据留档：`.workbuddy/scratch/nn_edge_zoom.png`（模块自身丝印）与 `nn_right_col.png`（官方图例）。

### 6.7 外壳开孔清单（✅ 2026-09-19 深夜定稿：三个口集中在**左侧**）

**用户定稿的排布**：**模块口在左侧壁；充电口在左上角；开关紧挨充电口旁边**（都在前壁左端）。
为此把 **nice!nano 插座整体下移 5.78 mm**（两排 4.38/19.62 → **10.16/25.40**），
让出左上角 y 0–8 那一条给「充电口 + 开关」——**无需加高额头，板框仍是 374.71 × 151.06**。

坐标系：**板坐标系，原点 = 板左上角，mm**。「前壁」= 板上边沿（y = 0）所对的壳壁；
「左壁」= 板左边缘（x = 0）所对的壳壁。

| # | 开孔 | 所在壳壁 | 中心坐标 | 建议开孔尺寸 | 实测依据 |
| --- | --- | --- | --- | --- | --- |
| **①** | **充电 USB-C**（`J1`） | **前壁（左上角）** | **x = 15.0**，跨 y = 0 | **11 × 4.5 mm** | `J1` 壳宽 8.64 mm（焊盘 10.68–19.32），口面 y ≈ −1.0（探出板边约 1 mm） |
| **②** | **模块 USB-C**（刷固件 + 有线模式） | **左壁** | **y = 17.8**，跨 x = 0 | **10 × 5 mm** | 模块口面 x = 1.70（首孔 x=7.00 − 5.30）；模块中线 y = 17.78（两排 10.16/25.40 的中线） |
| **③** | **三档模式开关**（`SW96`） | **前壁（紧挨 ① 右侧）** | **x = 33.0**，跨 y = 0 | **滑槽 8 × 4 mm** | `SW96` 本体 x 27.1–38.9；柄尖 y = −0.9（探出板边 0.9 mm） |

⚠️ 上表是**板侧几何**；壳体壁面通常比板边再外移 0.5–3 mm ⇒ 开孔沿法线方向穿过壁厚，**中心线不变**。
⚠️ ② 的 10 × 5 是「插头颈部 + 余量」：口面距壳壁仅 1.7 mm，握持部（28 mm）完全留在壳外 ⇒
与商业键盘同样的插拔手感。① 与 ③ 相邻（中心相距 18 mm），外壳上会形成一个「左侧接口簇」。

> 空间核算（为什么必须把模块下移）：左侧壁在键区（轴体从 y ≈ 30.5 起）之前只有 ≈30 mm 可用；
> 模块自身占 18 mm（板宽 17.78，两排相距 15.24），J1 本体后缘 ≈ y 7.5、SW96 占 y 0–6.5
> ⇒ 三者挤在 y 0–8 会与 J3A 插座冲突 ⇒ **模块下移 5.78 mm** 是最省的做法（模块后端 y≈26.7，
> 距键区 30.5 仍有 3.8 mm 余量；天线禁布区随之移到 x 37–42 / y ≈ 4–32）。

⚠️ 另有一项待 CAD 复核：插头要跨越板面 x 4–32 mm、y 8.5–15.5 mm 的**开放空间**，
该处是否有元件与插头/线冲突（我们的 `J1` 在 (15, 5.5)、高约 3 mm；
模块坐在插座上约 5–6 mm 高 ⇒ 理论上有净空，但**必须在 3D 装配里确认**）。

**比卡尺更直接的一步（建议同时做）**：拿一块硬纸板剪出「距板边 3 mm」的挡板，
立在板边模拟壳壁，把模块摆在板上的位置（孔1 在 x = 37.46、USB 朝左），
用目标线实际插一次 —— 能一次插到底、线不被顶住 ⇒ 方案成立。

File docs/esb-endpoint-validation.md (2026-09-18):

# ESB 端点验证计划（`efogdev/zmk-esb-endpoint` → nRF52840）

> **目的**：在投入 Dongle 硬件/固件之前，用最小成本回答一个问题——
> **`zmk-esb-endpoint` 模块能否在我们的硬件组合上跑通端到端按键？**
> 结论直接决定 Dongle 架构走方案 A（ESP32-S3 BLE HID 主机）还是方案 B（nRF52 ESB）。
> 背景与两条路线对比见 `docs/adr/0011` 附录 E；本决策由用户 2026-09-18 拍板「先验证再定」。

## 0. 为什么验证点是这个

`efogdev/zmk-esb-endpoint` 是目前唯一「单体键盘 + 第三条 ESB 输出 + MIT + 按 ZMK v0.3.0 测试」
的方案，但有**一个未验证的硬风险**：作者只按 **nRF52833** 调优，nRF52840 自述「应该能工作但
不确定」。我们键盘是 nice!nano v2（nRF52840）⇒ **移植是否成立 = 本验证的核心问题**。

具体要核对的移植点（作者按 52833 假设的地方）：
1. **PPI 通道掩码**——52833 与 52840 的 PPI 均为固定分配，但被 TE/其他外设占用的通道不同；
2. **VTOR / 向量表补丁**——模块假定 `NVIC_NUM_VECTORS = 64`；52840 的向量数不同；
3. **TIMER2 占用**——确认 Zephyr/ZMK 侧没有把 TIMER2 派给别的用途；
4. **HFXO 常开**——模块在 ESB 激活期保持高频晶振，核对 52840 的功耗与实现路径；
5. `RADIO_IRQn` 接管与 BLE 控制器共存（v0.3.0 的 Zephyr BLE 控制器）。

## 1. 物料

| 物料 | 数量 | 用途 |
| --- | --- | --- |
| **nice!nano v2** | 1 | **键盘端**：跑 ZMK v0.3.0 + 模块 —— 这就是成品的键盘主控，验证完直接进成品，不浪费 |
| **Seeed XIAO nRF52840** | 1 | **Dongle 端**：跑 ESB PRX + USB HID —— 与用户既定配置一致（dongle = XIAO） |
| USB-C **数据**线 | 2 | 烧录 + dongle 接主机 |
| 面包板 / 杜邦线 / 一个按钮（可选） | 少量 | 触发测试按键；也可用 mock kscan 免硬件 |
| 一台电脑（Windows/Linux/macOS 均可） | 1 | 构建与验证 |

> 📌 **为什么不是两块 XIAO**（2026-09-18 修正）：最初按「同款板子、单价最低」默认写了 2× XIAO。
> 用户指出真实配置是「键盘 = nice!nano v2、dongle = XIAO nRF52840」——
> 验证应尽量贴近量产组合：键盘端用 **nice!nano v2**（它本来就是键盘要买的主控，
> 验证时先征用、验证后继续进成品，不产生额外浪费），dongle 端用 **XIAO nRF52840**。
> 两块板同为 **nRF52840**，对「52833 → 52840 移植」这个核心验证问题是等价的。
>
> 不需要键盘 PCB、不需要 95 键矩阵 —— 验证的是**无线链路**，不是键位。
> 键盘端的「按键」用 mock kscan 或一个接 GPIO 的按钮即可。
>
> ⚠️ 唯一的实操差异：nice!nano v2 验证期间会被**反复刷机**（移植调试要走好几轮）。
> 它和 XIAO 都有 UF2 bootloader（双击 RESET 进位拖 uf2），刷坏可救；如果手上的
> nice!nano v2 是准备直接焊进成品的，介意反复刷就另备一块，介意成本就用它。

## 2. 步骤

1. **克隆与模块接入**：`git clone -b v0.3.0 https://github.com/zmkfirmware/zmk`；
   把 `zmk-esb-endpoint` 作为 ZMK_EXTRA_MODULES / west module 接入（按其 README）。
2. **键盘端构建**：board 用 `nice_nano_v2`（ZMK v0.3.0 的 board id，与 build.yaml 一致）；
   kscan 用 mock（或一个 GPIO 按钮）；打开模块的 Kconfig，确认 `zmk,esb-endpoint` 节点生成。
   ⚠️ **这一步预计就要动移植点 1–5**（编译错误/链接警告会先暴露一部分，
   运行期问题靠第 3 步暴露）。
3. **Dongle 端构建**：board 用 `seeeduino_xiao_ble`；先用作者的参考实现
   `efogtech/endgame-trackball-firmware/dongle-1k-firmware`（按 protocol.h 适配到 XIAO）。
4. **端到端**：键盘板触发一次按键 → 电脑上应出现该键。
5. **切换行为**：把 BLE profile 切走（`&bt BT_SEL 0` 等）→ USB/BLE 输出恢复；
   切回最后 profile → ESB 恢复。确认无死机、无键盘失效。
6. **（加分）量一次延迟**：能测就测，测不了记录「未测」——不作为通过与否的判据。

## 3. 通过判据

| # | 判据 | 结果 |
| --- | --- | --- |
| 1 | 键盘端：ZMK v0.3.0 + 模块在 **nRF52840** 上编译、烧录、启动成功 | ⬜ |
| 2 | Dongle 端：PRX 固件在 nRF52840 上运行并枚举为 USB HID | ⬜ |
| 3 | **端到端**：键盘板触发按键 → 主机收到该键 | ⬜ |
| 4 | 切换：ESB ↔ BLE/USB 双向切换正常，无死机 | ⬜ |
| 5 | 移植改动清单（PPI/VTOR/TIMER2/HFXO）已记录成文 | ⬜ |

**判定**：3 项全过 + 4 无致命问题 ⇒ **方案 B**；核心不通或移植代价远超预期 ⇒ **方案 A**。
中间态（过了但要改动过多）⇒ 把改动量报给用户再定。

## 4. 构建环境（本机现状与两条路）

- **本机没有 Zephyr SDK**（handoff §11）。两条路：
  - **A. 本地工具链（推荐）**：装 west + Zephyr SDK（下载约 1–2 GB，HTTPS 直连可用）；
    低层级移植（PPI/VTOR/链接器）迭代快。⚠️ 磁盘写入慢（~2,400 文件/分钟），
    ZMK+Zephyr 检出是数万文件，首次 west update 要有耐心。
  - **B. GitHub Actions**：fork 一个带模块的仓，push 触发构建、下载 artifact。
    零本地安装，但每轮迭代要等 CI（数分钟）——对低层级调试太慢，只适合最后验证。
- 注意 `research/_clones/zmk` 是 **main** 分支克隆，**不能**直接当 v0.3.0 构建树用
  （v0.3.0 板级在 `app/boards/arm/`，main 在 `app/module/`）。

## 5. 风险与回退

- **验证失败** ⇒ 回方案 A（ESP32-S3 BLE HID 主机），损失 = 一块 XIAO 开发板 + 若干天；
  **nice!nano v2 不受影响**——它本来就是键盘主控，直接继续当键盘用。
  键盘端无任何残留（模块不进正式固件）。
- **验证通过** ⇒ Dongle 硬件定为 **XIAO nRF52840**（与用户既定配置一致；自制小板亦可），
  固件 = ESB PRX + USB HID；键盘端在 B2/C1 里加入该 module（ZMK module 是正规扩展机制，教程可写），
  nice!nano v2 继续当键盘主控。
- **许可**：模块 MIT；vendored Nordic ESB 为 LicenseRef-Nordic-5-Clause（限 Nordic 芯片，
  本组合两端均为 Nordic，满足）——与方案 A 的全链 Apache-2.0 相比，许可清洁度略降，需在
  仓库第三方声明中写明。
- ⚠️ 无论结果如何，**B2（键盘控制板子图）不受影响**，可并行推进；
  Dongle 部分在验证出结果前不定型。

## 6. 与待办的衔接

- 本验证挂在 **C7**（新增，见 PROJECT_HANDOFF.md §9），可与 B2 并行；
- 验证通过 ⇒ C5（Dongle 固件）改为「ESB PRX + USB HID」实现路线；
- 验证失败 ⇒ C5 维持「ESP32-S3 + `esp_hid_host` + `tusb_hid`」。

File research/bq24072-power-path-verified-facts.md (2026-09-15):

# BQ24072 (RGT/VQFN-16) 充电 + 电源路径电路 — 已核实事实报告

> 面向 KiCad 原理图设计。所有结论均标注来源 URL。凡不能从一手来源核实的，一律标 `UNVERIFIED`。
> 拿不到 PDF 的环境限制已绕过：本报告中的 TI 数据来自**直接从 ti.com 下载的原始 PDF 并在本地做文本提取**（Node.js + pdf-parse），不是二手转述。

---

## 0. 核实方法与来源（可复现）

| 用途 | 一手来源 | 说明 |
|---|---|---|
| 主数据源 | **TI SLUS810N**（2008-09 首发，2021-10 修订）https://www.ti.com/lit/ds/symlink/bq24072.pdf | 3731441 bytes，53 页，提取出 103879 字符纯文本；本报告所有「表 x-y / 第 N 节」编号均指该文档 |
| 引脚表交叉核对（HTML 版，页级定位） | https://www.datasheetbank.com/en/datasheet-html/140846/Teccor-Electronics/7page/BQ24072.html （SLUS810L 镜像，PDF 第 7 页 = Pin Functions） | 与 SLUS810N 引脚表逐行一致 |
| 引脚号/引脚名/引脚类型交叉核对（独立第二来源） | KiCad 官方符号 `Battery_Management:BQ24072RGT` https://gitlab.com/kicad/libraries/kicad-symbols/-/blob/master/Battery_Management.kicad_symdir/BQ24072RGT.kicad_sym | 与 TI 引脚表 100% 一致（含 thermal pad 编号 17） |
| USB-C | **USB Type-C Cable and Connector Specification Release 2.5 (March 2026)** https://usb.org/document-library/usb-type-cr-cable-and-connector-specification-release-25 | 下载官方 ZIP → 解出 `USB Type-C Spec R2.5 - March 2026.pdf` → 本地提取 442 页 / 940596 字符 |

> 方法备注：常规网页抓取工具读不了 PDF；改用 Node 的 `fetch()` 直接下载文件到本地、用 `pdf-parse` 提取文本，再检索。KiCad 官方库现为 GitLab 上「一个符号/封装一个文件」的结构（旧 `kicad.github.io` HTML 文档页与 GitLab master **不同步**，见 §12 警告）。

---

## 1. BQ24072 完整引脚表（RGT, VQFN-16）

来源：SLUS810N **Table 7-1. Pin Functions**（PDF 第 7–9 页）https://www.ti.com/lit/ds/symlink/bq24072.pdf
引脚图来源：SLUS810N **Figure 7-1**（PDF 第 7 页）；交叉核对：KiCad `Battery_Management:BQ24072RGT`。

| Pin | Name | datasheet I/O | 功能类型 | 功能（一句话） | 家族差异（重要） |
|---|---|---|---|---|---|
| **1** | `TS` | I | Analog Input | 外部 NTC 热敏电阻输入；内部 `INTC` 电流源（75 µA typ）流过外部电阻形成 VTS，用于电池包温度监测 | 全家族一致（pin 1） |
| **2** | `BAT` | I/O | Power | 充电功率级输出 + 电池电压检测输入，接电池正极；对 VSS 并 4.7–47 µF 陶瓷电容 | 全家族一致 |
| **3** | `BAT` | I/O | Power | 同上（与 pin 2 内部同节点，双焊盘走流） | 全家族一致 |
| **4** | `CE` | I | Digital Input | 充电使能，**低有效**；拉高关断充电（此时 OUT 仍有效、支持 battery supplement）；内部 ~285 kΩ 下拉 | 全家族一致 |
| **5** | `EN2` | I | Digital Input | 输入限流配置（配合 EN1，见表 7-2）；内部 ≈285 kΩ 下拉，**不可悬空** | 全家族一致 |
| **6** | `EN1` | I | Digital Input | 输入限流配置；内部 ≈285 kΩ 下拉，**不可悬空** | 全家族一致 |
| **7** | `PGOOD` | O | Digital Output (open-drain) | 电源正常指示；有效输入源时拉低到 VSS，否则高阻 | 全家族一致 |
| **8** | `VSS` | – | Power (GND) | 地；必须与 thermal pad 及系统地相连 | 全家族一致 |
| **9** | `CHG` | O | Digital Output (open-drain) | 充电状态指示；充电中拉低，充满/充电禁用时高阻；故障时约 2 Hz 闪烁 | 全家族一致 |
| **10** | `OUT` | O | Power | 系统供电输出（power-path 输出）；对 VSS 并 4.7–47 µF | 全家族一致（但**调压点不同**，见 §2） |
| **11** | `OUT` | O | Power | 同上（与 pin 10 同节点） | 全家族一致 |
| **12** | `ILIM` | I | Analog Input | 输入限流编程：ILIM 到 VSS 接 1100 Ω–8 kΩ | 全家族一致 |
| **13** | `IN` | I | Power | 输入电源（AC adapter / USB 口）；对 VSS 并 1–10 µF | 全家族一致（**最高工作输入电压不同**，见 §2） |
| **14** | `TMR` | I | Analog Input | 预充/快充安全定时器编程（18–72 kΩ），接 VSS 关闭全部定时器，悬空用默认值 | 全家族一致 |
| **15** | `TD` | I | Digital Input | **仅 BQ24072/BQ24073**：拉高关闭充电终止；内部 ~285 kΩ 下拉 | ⚠️ **同一 pin 15 在 '74 是 `ITERM`、在 '75/'79 是 `SYSOFF`** |
| **16** | `ISET` | I/O | Analog Input/Output | 快充电流编程（590 Ω–8.9 kΩ）；充电时该脚电压正比于实际充电电流，可作电流监测 | 全家族一致 |
| **EP/17** | `Thermal Pad` | – | Power (GND) | 裸露热焊盘，**与 VSS 引脚内部电气相连**；PCB 上必须接到与 VSS 相同电位（KiCad 官方符号把它编号为 17 并映射为 VSS） | 全家族一致 |

**NC 引脚：没有。** 16 个引脚全部有定义，无 NC。封装只有这 16 pin + 裸露热焊盘。
来源：SLUS810N Table 7-1（引脚表无任何 NC 项）；KiCad 符号 `BQ24072RGT` 只定义 pin 1–16 + pin 17（pad，隐藏，passive，名为 VSS）。

**⚠️ 你在需求里列的几个名字在本器件上不存在：**
- `PRETERM` / `PRE-TERM`：**不存在**。预充电流不可编程，由内部系数决定（`IPRECHG = KPRECHG/RISET`，见 §4）。
- `TERM`：**不存在**。BQ24072 用 `TD`（pin 15）关闭终止；可调终止电流是 **BQ24074** 的 `ITERM`（也是 pin 15）。
- `OUTP`：**不存在**。系统输出就叫 `OUT`，占 pin 10 与 11 两个焊盘。
- `SYSOFF`：**BQ24072 上没有**（它是 BQ24075/BQ24079 的 pin 15）。
来源：SLUS810N Table 7-1、Table 6-1（Device Comparison Table）。

**引脚图（Top View，RGT0016B，16 Pins）** —— 来源 SLUS810N Figure 7-1：
```
       16     15     14     13
      ISET   TD    TMR    IN
  1 TS ┌──────────────────────┐ 12 ILIM
  2 BAT│                      │ 11 OUT
  3 BAT│      Thermal Pad     │ 10 OUT
  4 CE └──────────────────────┘  9 CHG
        5      6      7      8
       EN2    EN1   PGOOD   VSS
```
（BQ24075/BQ24079 的 Figure 7-3 位置相同，只是 pin 15 丝印为 `SYSOFF`。）

---

## 1b. 原理图接线清单（可直接照着画）

| Pin | 网络 | 元件/接法 | 依据 |
|---|---|---|---|
| 1 `TS` | `TS` | 正常：10 kΩ NTC（103AT-2）到 GND；**停用温度检测：单个 10 kΩ 1% 电阻到 GND** | §3 |
| 2, 3 `BAT` | `VBAT` | 接电池正极 + **4.7 µF**（范围 4.7–47 µF）到 GND；两脚短接 | §9 |
| 4 `CE` | `CE` | 低 = 充电使能；**不可悬空**（内部 285 kΩ 下拉）。不需要 MCU 控制时直接接 GND | Table 7-1 |
| 5 `EN2` | `EN2` | 见 §5 真值表；**不可悬空** | Table 7-2 |
| 6 `EN1` | `EN1` | 见 §5 真值表；**不可悬空** | Table 7-2 |
| 7 `PGOOD` | `PGOOD` | 开漏：1 k–100 kΩ 上拉到逻辑电源，或 1.5 kΩ + LED 到 `OUT`；不用可悬空 | Table 7-1 |
| 8 `VSS` | `GND` | 必须接地（与 thermal pad 同电位） | Table 7-1 |
| 9 `CHG` | `CHG` | 同 PGOOD，开漏 | Table 7-1 |
| 10, 11 `OUT` | `VSYS` | 系统供电轨 + **4.7 µF**（范围 4.7–47 µF）到 GND；两脚短接 | §9 |
| 12 `ILIM` | `ILIM` | **总要放电阻到 GND**（USB500 场景可放 1.6 kΩ；ILIM 模式按 §5 算） | §5 |
| 13 `IN` | `VBUS_USB` | USB-C VBUS（A4/A9/B4/B9 并联）+ **1 µF**（1–10 µF，**必须 < 10 µF**）到 GND | §5/§9/§11 |
| 14 `TMR` | `TMR` | 46.4 kΩ 到 GND（6.25 h）；悬空 = 默认 5 h/30 min；接 GND = 关闭定时器 | §6 |
| 15 `TD` | `TD` | 低 = 启用终止（默认，可接 GND）；**高 = 关闭终止**（注意同时会关闭安全定时器，并可能关闭 TS）；**不可悬空** | §7 |
| 16 `ISET` | `ISET` | 按 §4 选 1% 电阻到 GND（0.5 A→1.78 kΩ，1 A→887 Ω，1.5 A→590 Ω）；**悬空 = 禁止充电** | §4 |
| EP/17 | `GND` | 热焊盘，**必须焊接**并接到 GND 平面（多过孔、大铜面） | §10 |
| USB-C `A5`/`B5` | `CC1`/`CC2` | 各接 **5.1 kΩ（±10%）到 GND**，**不得短接** | §11.2 |
| USB-C `SH`×4 | `GND` | 外壳直接接 PCB 地平面 | §11.3 |

---

## 2. 家族差异（BQ24072 / 73 / 74 / 75 / 79）— 最容易画错的地方

来源：SLUS810N **Table 6-1 Device Comparison Table**（PDF 第 6 页）https://www.ti.com/lit/ds/symlink/bq24072.pdf

| 器件 | VOVP | VBAT(REG) | VOUT(REG)（OUT 调压点） | VDPPM | 特有功能脚 | 数据手册标注封装 |
|---|---|---|---|---|---|---|
| **BQ24072** | 6.6 V | 4.2 V | **VBAT + 225 mV**（文本第 9.3.4.1 节写作 "200 mV above BAT"；电气表给 150/225/270 mV min/typ/max） | VO(REG) − 100 mV | `TD` | RGT0016C |
| BQ24073 | 6.6 V | 4.2 V | 4.4 V | VO(REG) − 100 mV | `TD` | — |
| BQ24074 | **10.5 V** | 4.2 V | 4.4 V | VO(REG) − 100 mV | `ITERM` | — |
| BQ24075 | 6.6 V | 4.2 V | 5.5 V | 4.3 V | `SYSOFF` | RGT0016C |
| BQ24079 | 6.6 V | **4.1 V** | 5.5 V | 4.3 V | `SYSOFF` | RGT0016B |

**关键结论（画原理图前必读）：**
1. **pin 15 是三种不同功能**：`TD`('72/'73) / `ITERM`('74) / `SYSOFF`('75,'79)。原理图符号若用通用 16 脚符号，务必确认 pin 15 的网络名。
2. **`IN` 最高工作电压**：'72/'73/'75/'79 = 4.35–6.4 V；'74 = 4.35–10.2 V（绝对最大 26 V，超过 OVP 只是暂停工作）。用 5 V USB 供电时 '72 完全够用。
3. **OUT 调压点**：'72 的 OUT 跟随电池（VBAT + 225 mV typ，VBAT < 3.2 V 时钳在 3.4 V），**不是**固定 4.4 V。若你的系统需要 4.4 V 固定轨，那是 '73/'74；若需要 5.5 V，那是 '75/'79。
4. **封装后缀在文档内自相矛盾**：Figure 7-1/7-2 标注 "BQ24072, BQ24073 RGT0016B Package"，而 Table 6-1 写 BQ24072 → RGT0016C；Figure 7-3 写 "BQ24075 RGT0016C / BQ24079 RGT0016B"。订货信息（Orderable Addendum）只写 `VQFN (RGT) | 16`。**结论：物理上是同一个 3×3 mm VQFN-16（RGT），KiCad 官方符号关联的封装是 `Package_DFN_QFN:VQFN-16-1EP_3x3mm_P0.5mm_EP1.6x1.6mm`**（来源：KiCad 符号属性 `Footprint`，见 §0 链接）。RGT0016B/C 的差异未在数据手册中说明 → 标 `UNVERIFIED`。

---

## 3. `TS` 引脚（温度检测）— 全部数值

来源：SLUS810N **8.5 Electrical Characteristics → BATTERY-PACK NTC MONITOR**（PDF 第 13 页）、**9.3.6 Battery Pack Temperature Monitoring**（PDF 第 29–30 页）、**Table 7-1 TS 行**。

| 参数 | 数值（min / typ / max） | 单位 | 条件 |
|---|---|---|---|
| `INTC` NTC 偏置电流（TS 输出电流） | **72 / 75 / 78** | µA | VIN > UVLO 且 VIN > VBAT + VIN(DT) |
| `VHOT` 高温跳变点 | **270 / 300 / 330** | **mV**（不是 %VIN！） | Battery charging，VTS **falling** |
| `VHYS(HOT)` 高温迟滞 | 30 | mV | VTS 从 VHOT 回升 |
| `VCOLD` 低温跳变点 | **2000 / 2100 / 2200** | **mV** | Battery charging，VTS **rising** |
| `VHYS(COLD)` 低温迟滞 | 300 | mV | VTS 从 VCOLD 回落 |
| `tDGL(TS)` 温度故障去抖 | 50 | ms | 检测到故障 → 关断充电 |
| `VDIS(TS)` 判定"未使用温度检测"的阈值（'72/'73） | **VIN − 200** | mV | TS 悬空 → 被内部电流源顶到接近 VIN，超过该阈值即判定 TS 未使用（关闭 TS 功能） |

**→ 直接回答你的问题：阈值是绝对电压（mV），不是 VIN 的百分比。** 工作窗口 = 2.1 V（冷端）到 0.3 V（热端），中间是允许充电区间。

**→ 关闭温度检测（不用 NTC）的官方做法：单个 10 kΩ 电阻，从 TS 接到 VSS。不是分压器。**
原文（Table 7-1 TS 行）："For applications that do not use the TS function, connect a **10-kΩ fixed resistor from TS to VSS** to maintain a valid voltage level on TS."
原文（9.3.6 节）："For applications that do not require the TS monitoring function, connect a **10-kΩ resistor from TS to VSS** to set the TS voltage at a valid level and maintain charging."
原文（10.2.2.3 TS Function，设计示例）："Use a 10-kΩ NTC thermistor in the battery pack (103AT-2). For applications that do not require the TS monitoring function, connect a **10-kΩ resistor from TS to VSS**…"
数学上也自洽：75 µA × 10 kΩ = **0.75 V**，落在 0.3 V…2.1 V 窗口内。
（**注意**：并不是"TS 必须永远接 10 kΩ NTC"。NTC 是正常用法，固定 10 kΩ 是官方给出的停用方法。）

**扩展温度窗口（可选）**：加 `Rs`（与 NTC 串联到 TS）和 `Rp`（TS 到 VSS 并联），公式见 SLUS810N 式 (8)(9)，其中 `VH` = 0.3 V nom、`VC` = 2.1 V nom、`ITS` = 75 µA nom，NTC 型号 Semitec 103AT-4。Table 9-3 给出 6 组 1% 标准值，例如 `RCOLD = 33890 Ω(−5 °C)`、`RHOT = 3021 Ω(60 °C)` → `Rs = 1100 Ω`、`Rp = 140 kΩ`。原文明确："The temperature window cannot be tightened more than using only the thermistor connected to TS, it can only be **extended**."

**⚠️ 与 `TD` 的交互（BQ24072 特有）**：9.3.5.3 节 —— "Battery pack temperature sensing (TS pin functionality) is **disabled if the TD pin is high and the TS pin is unconnected or pulled up to VIN**." 即 TD 拉高（关闭终止）且 TS 悬空/上拉到 VIN 时，温度检测也一起失效。

---
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

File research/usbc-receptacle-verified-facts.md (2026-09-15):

# USB-C receptacle — verified facts (device-side / UFP, charging + USB 2.0 data, 5.1 kΩ CC pulldowns)

All spec quotes below are from **USB Type-C® Cable and Connector Specification, Release 2.4 (October 2024), 439 pp.**
I downloaded the PDF and extracted its text locally (PDF text extraction, printed page numbers given). Copy read:
`https://community.infineon.com/gfawx74859/attachments/gfawx74859/USBEZPDTypeC/10790/1/USB%20Type-C%20Spec%20R2.4%20-%20October%202024.pdf`
Official landing page (points to the USB-IF Document Library): `https://www.usb.org/usb-type-cr-cable-and-connector-specification`
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

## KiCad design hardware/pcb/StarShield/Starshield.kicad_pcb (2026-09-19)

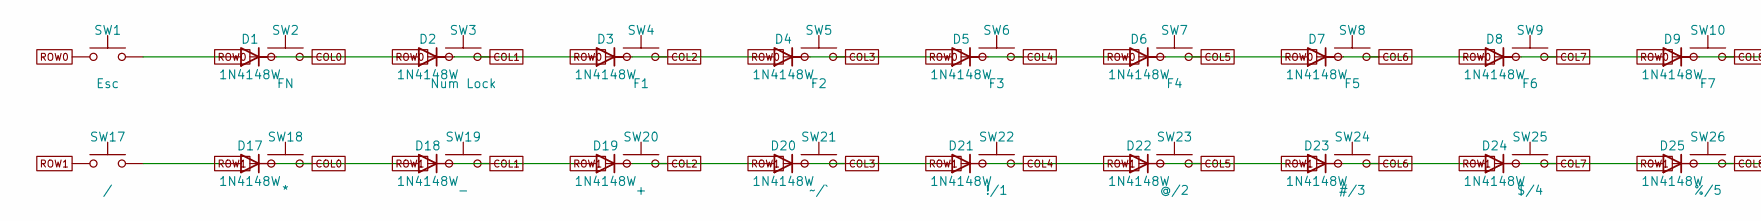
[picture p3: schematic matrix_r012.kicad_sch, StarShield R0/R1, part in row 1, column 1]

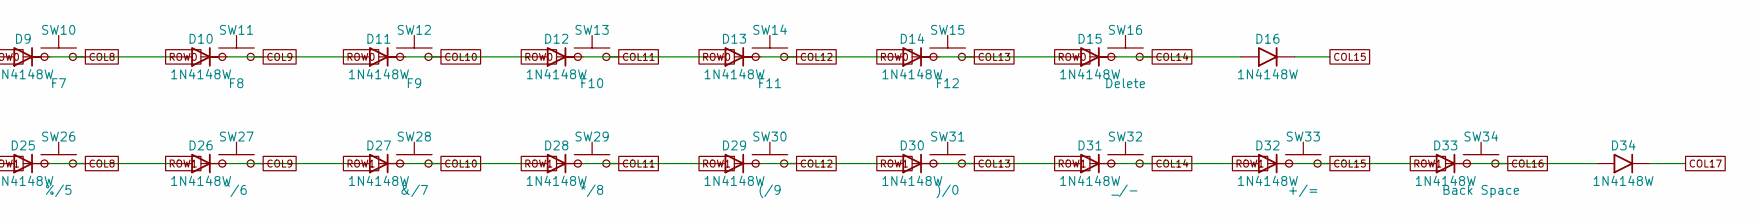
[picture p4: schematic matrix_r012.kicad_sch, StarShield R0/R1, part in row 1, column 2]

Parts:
D1, D2, D3, D4, D5, D6, D7, D8, D9, D10, D11, D12, D13, D14, D15, D16, D17, D18, D19, D20, D21, D22, D23, D24, D25, D26, D27, D28, D29, D30, D31, D32, D33, D34: 1N4148W; D_SOD-123
SW1: Esc; SW_MX_Hotswap_Optional_1.00u
SW2: FN; SW_MX_Hotswap_Optional_1.00u
SW3: Num Lock; SW_MX_Hotswap_Optional_1.00u
SW4: F1; SW_MX_Hotswap_Optional_1.00u
SW5: F2; SW_MX_Hotswap_Optional_1.00u
SW6: F3; SW_MX_Hotswap_Optional_1.00u
SW7: F4; SW_MX_Hotswap_Optional_1.00u
SW8: F5; SW_MX_Hotswap_Optional_1.00u
SW9: F6; SW_MX_Hotswap_Optional_1.00u
SW10: F7; SW_MX_Hotswap_Optional_1.00u
SW11: F8; SW_MX_Hotswap_Optional_1.00u
SW12: F9; SW_MX_Hotswap_Optional_1.00u
SW13: F10; SW_MX_Hotswap_Optional_1.00u
SW14: F11; SW_MX_Hotswap_Optional_1.00u
SW15: F12; SW_MX_Hotswap_Optional_1.00u
SW16: Delete; SW_MX_Hotswap_Optional_1.00u
SW17: /; SW_MX_Hotswap_Optional_1.00u
SW18: *; SW_MX_Hotswap_Optional_1.00u
SW19: -; SW_MX_Hotswap_Optional_1.00u
SW20: +; SW_MX_Hotswap_Optional_1.00u
SW21: ~/`; SW_MX_Hotswap_Optional_1.00u
SW22: !/1; SW_MX_Hotswap_Optional_1.00u
SW23: @/2; SW_MX_Hotswap_Optional_1.00u
SW24: #/3; SW_MX_Hotswap_Optional_1.00u
SW25: $/4; SW_MX_Hotswap_Optional_1.00u
SW26: %/5; SW_MX_Hotswap_Optional_1.00u
SW27: ^/6; SW_MX_Hotswap_Optional_1.00u
SW28: &/7; SW_MX_Hotswap_Optional_1.00u
SW29: */8; SW_MX_Hotswap_Optional_1.00u
SW30: (/9; SW_MX_Hotswap_Optional_1.00u
SW31: )/0; SW_MX_Hotswap_Optional_1.00u
SW32: _/-; SW_MX_Hotswap_Optional_1.00u
SW33: +/=; SW_MX_Hotswap_Optional_1.00u
SW34: Back Space; SW_MX_Hotswap_Optional_2.00u

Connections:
COL0: D1.1 (K), D17.1 (K); also elsewhere on the board
COL1: D2.1 (K), D18.1 (K); also elsewhere on the board
COL2: D3.1 (K), D19.1 (K); also elsewhere on the board
COL3: D4.1 (K), D20.1 (K); also elsewhere on the board
COL4: D5.1 (K), D21.1 (K); also elsewhere on the board
COL5: D6.1 (K), D22.1 (K); also elsewhere on the board
COL6: D7.1 (K), D23.1 (K); also elsewhere on the board
COL7: D8.1 (K), D24.1 (K); also elsewhere on the board
COL8: D9.1 (K), D25.1 (K); also elsewhere on the board
COL9: D10.1 (K), D26.1 (K); also elsewhere on the board
COL10: D11.1 (K), D27.1 (K); also elsewhere on the board
COL11: D12.1 (K), D28.1 (K); also elsewhere on the board
COL12: D13.1 (K), D29.1 (K); also elsewhere on the board
COL13: D14.1 (K), D30.1 (K); also elsewhere on the board
COL14: D15.1 (K), D31.1 (K); also elsewhere on the board
COL15: D16.1 (K), D32.1 (K); also elsewhere on the board
COL16: D33.1 (K); also elsewhere on the board
COL17: D34.1 (K); also elsewhere on the board
unnamed: D1.2 (A), SW1.2
unnamed: D2.2 (A), SW2.2
unnamed: D3.2 (A), SW3.2
unnamed: D4.2 (A), SW4.2
unnamed: D5.2 (A), SW5.2
unnamed: D6.2 (A), SW6.2
unnamed: D7.2 (A), SW7.2
unnamed: D8.2 (A), SW8.2
unnamed: D9.2 (A), SW9.2
unnamed: D10.2 (A), SW10.2
unnamed: D11.2 (A), SW11.2
unnamed: D12.2 (A), SW12.2
unnamed: D13.2 (A), SW13.2
unnamed: D14.2 (A), SW14.2
unnamed: D15.2 (A), SW15.2
unnamed: D16.2 (A), SW16.2
unnamed: D17.2 (A), SW17.2
unnamed: D18.2 (A), SW18.2
unnamed: D19.2 (A), SW19.2
unnamed: D20.2 (A), SW20.2
unnamed: D21.2 (A), SW21.2
unnamed: D22.2 (A), SW22.2
unnamed: D23.2 (A), SW23.2
unnamed: D24.2 (A), SW24.2
unnamed: D25.2 (A), SW25.2
unnamed: D26.2 (A), SW26.2
unnamed: D27.2 (A), SW27.2
unnamed: D28.2 (A), SW28.2
unnamed: D29.2 (A), SW29.2
unnamed: D30.2 (A), SW30.2
unnamed: D31.2 (A), SW31.2
unnamed: D32.2 (A), SW32.2
unnamed: D33.2 (A), SW33.2
unnamed: D34.2 (A), SW34.2
ROW0: SW1.1, SW2.1, SW3.1, SW4.1, SW5.1, SW6.1, SW7.1, SW8.1, SW9.1, SW10.1, SW11.1, SW12.1, SW13.1, SW14.1, SW15.1, SW16.1; also elsewhere on the board
ROW1: SW17.1, SW18.1, SW19.1, SW20.1, SW21.1, SW22.1, SW23.1, SW24.1, SW25.1, SW26.1, SW27.1, SW28.1, SW29.1, SW30.1, SW31.1, SW32.1, SW33.1, SW34.1; also elsewhere on the board

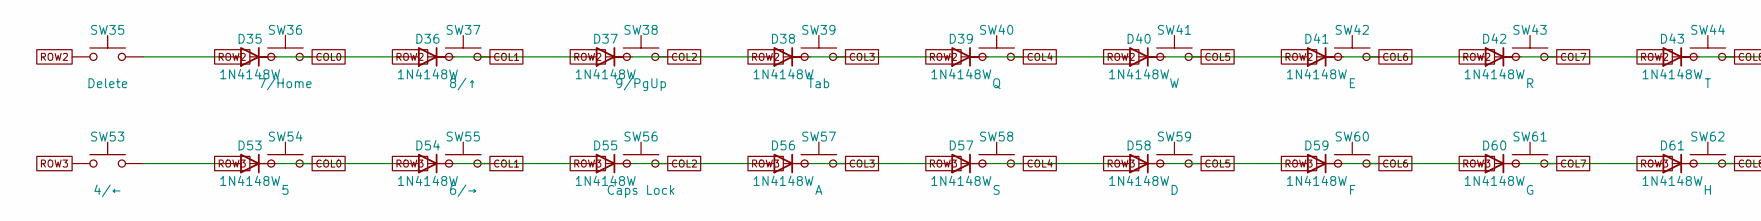
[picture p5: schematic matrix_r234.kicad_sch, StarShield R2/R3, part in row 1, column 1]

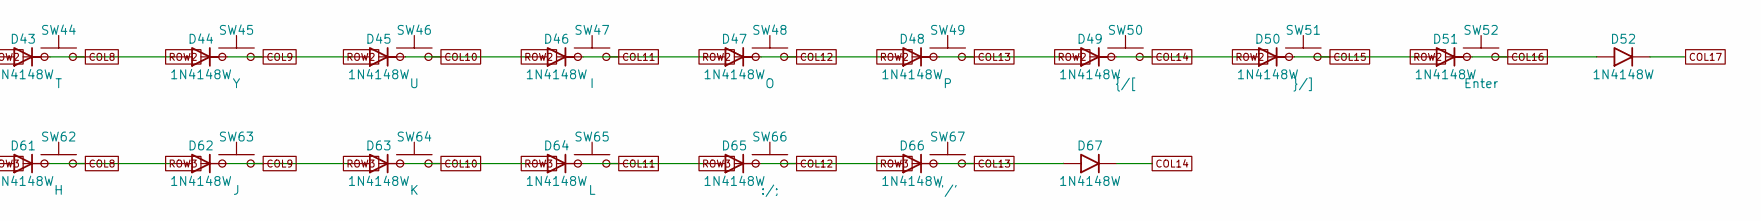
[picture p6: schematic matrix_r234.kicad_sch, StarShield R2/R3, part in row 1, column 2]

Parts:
D35, D36, D37, D38, D39, D40, D41, D42, D43, D44, D45, D46, D47, D48, D49, D50, D51, D52, D53, D54, D55, D56, D57, D58, D59, D60, D61, D62, D63, D64, D65, D66, D67: 1N4148W; D_SOD-123
SW35: Delete; SW_MX_Hotswap_Optional_2.00u_Vertical
SW36: 7/Home; SW_MX_Hotswap_Optional_1.00u
SW37: 8/↑; SW_MX_Hotswap_Optional_1.00u
SW38: 9/PgUp; SW_MX_Hotswap_Optional_1.00u
SW39: Tab; SW_MX_Hotswap_Optional_1.50u
SW40: Q; SW_MX_Hotswap_Optional_1.00u
SW41: W; SW_MX_Hotswap_Optional_1.00u
SW42: E; SW_MX_Hotswap_Optional_1.00u
SW43: R; SW_MX_Hotswap_Optional_1.00u
SW44: T; SW_MX_Hotswap_Optional_1.00u
SW45: Y; SW_MX_Hotswap_Optional_1.00u
SW46: U; SW_MX_Hotswap_Optional_1.00u
SW47: I; SW_MX_Hotswap_Optional_1.00u
SW48: O; SW_MX_Hotswap_Optional_1.00u
SW49: P; SW_MX_Hotswap_Optional_1.00u
SW50: {/[; SW_MX_Hotswap_Optional_1.00u
SW51: }/]; SW_MX_Hotswap_Optional_1.00u
SW52: Enter; SW_MX_Hotswap_Optional_2.25u
SW53: 4/←; SW_MX_Hotswap_Optional_1.00u
SW54: 5; SW_MX_Hotswap_Optional_1.00u
SW55: 6/→; SW_MX_Hotswap_Optional_1.00u
SW56: Caps Lock; SW_MX_Hotswap_Optional_1.75u
SW57: A; SW_MX_Hotswap_Optional_1.00u
SW58: S; SW_MX_Hotswap_Optional_1.00u
SW59: D; SW_MX_Hotswap_Optional_1.00u
SW60: F; SW_MX_Hotswap_Optional_1.00u
SW61: G; SW_MX_Hotswap_Optional_1.00u
SW62: H; SW_MX_Hotswap_Optional_1.00u
SW63: J; SW_MX_Hotswap_Optional_1.00u
SW64: K; SW_MX_Hotswap_Optional_1.00u
SW65: L; SW_MX_Hotswap_Optional_1.00u
SW66: :/;; SW_MX_Hotswap_Optional_1.00u
SW67: "/'; SW_MX_Hotswap_Optional_1.00u

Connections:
COL0: D35.1 (K), D53.1 (K); also elsewhere on the board
COL1: D36.1 (K), D54.1 (K); also elsewhere on the board
COL2: D37.1 (K), D55.1 (K); also elsewhere on the board
COL3: D38.1 (K), D56.1 (K); also elsewhere on the board
COL4: D39.1 (K), D57.1 (K); also elsewhere on the board
COL5: D40.1 (K), D58.1 (K); also elsewhere on the board
COL6: D41.1 (K), D59.1 (K); also elsewhere on the board
COL7: D42.1 (K), D60.1 (K); also elsewhere on the board
COL8: D43.1 (K), D61.1 (K); also elsewhere on the board
COL9: D44.1 (K), D62.1 (K); also elsewhere on the board
COL10: D45.1 (K), D63.1 (K); also elsewhere on the board
COL11: D46.1 (K), D64.1 (K); also elsewhere on the board
COL12: D47.1 (K), D65.1 (K); also elsewhere on the board
COL13: D48.1 (K), D66.1 (K); also elsewhere on the board
COL14: D49.1 (K), D67.1 (K); also elsewhere on the board
COL15: D50.1 (K); also elsewhere on the board
COL16: D51.1 (K); also elsewhere on the board
COL17: D52.1 (K); also elsewhere on the board
unnamed: D35.2 (A), SW35.2
unnamed: D36.2 (A), SW36.2
unnamed: D37.2 (A), SW37.2
unnamed: D38.2 (A), SW38.2
unnamed: D39.2 (A), SW39.2
unnamed: D40.2 (A), SW40.2
unnamed: D41.2 (A), SW41.2
unnamed: D42.2 (A), SW42.2
unnamed: D43.2 (A), SW43.2
unnamed: D44.2 (A), SW44.2
unnamed: D45.2 (A), SW45.2
unnamed: D46.2 (A), SW46.2
unnamed: D47.2 (A), SW47.2
unnamed: D48.2 (A), SW48.2
unnamed: D49.2 (A), SW49.2
unnamed: D50.2 (A), SW50.2
unnamed: D51.2 (A), SW51.2
unnamed: D52.2 (A), SW52.2
unnamed: D53.2 (A), SW53.2
unnamed: D54.2 (A), SW54.2
unnamed: D55.2 (A), SW55.2
unnamed: D56.2 (A), SW56.2
unnamed: D57.2 (A), SW57.2
unnamed: D58.2 (A), SW58.2
unnamed: D59.2 (A), SW59.2
unnamed: D60.2 (A), SW60.2
unnamed: D61.2 (A), SW61.2
unnamed: D62.2 (A), SW62.2
unnamed: D63.2 (A), SW63.2
unnamed: D64.2 (A), SW64.2
unnamed: D65.2 (A), SW65.2
unnamed: D66.2 (A), SW66.2
unnamed: D67.2 (A), SW67.2
ROW2: SW35.1, SW36.1, SW37.1, SW38.1, SW39.1, SW40.1, SW41.1, SW42.1, SW43.1, SW44.1, SW45.1, SW46.1, SW47.1, SW48.1, SW49.1, SW50.1, SW51.1, SW52.1; also elsewhere on the board
ROW3: SW53.1, SW54.1, SW55.1, SW56.1, SW57.1, SW58.1, SW59.1, SW60.1, SW61.1, SW62.1, SW63.1, SW64.1, SW65.1, SW66.1, SW67.1; also elsewhere on the board

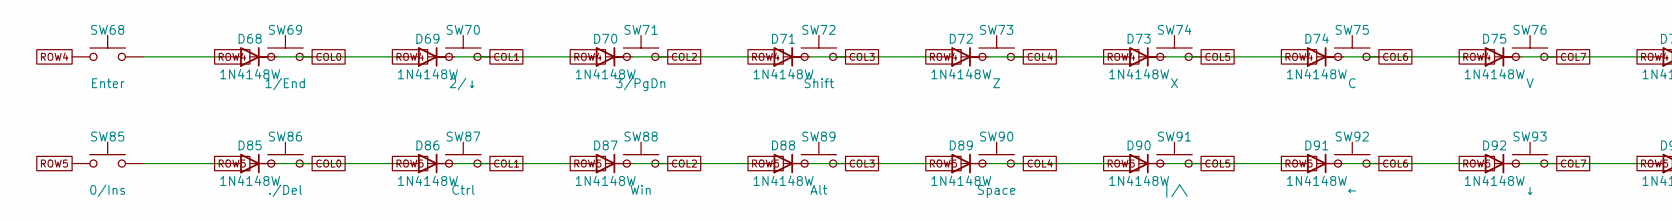
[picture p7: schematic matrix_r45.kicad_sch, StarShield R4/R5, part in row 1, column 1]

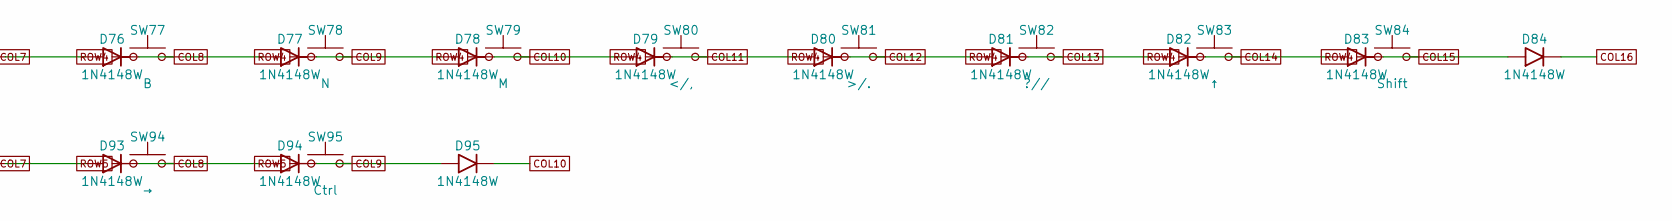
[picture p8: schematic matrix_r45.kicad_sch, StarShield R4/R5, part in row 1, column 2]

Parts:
D68, D69, D70, D71, D72, D73, D74, D75, D76, D77, D78, D79, D80, D81, D82, D83, D84, D85, D86, D87, D88, D89, D90, D91, D92, D93, D94, D95: 1N4148W; D_SOD-123
SW68: Enter; SW_MX_Hotswap_Optional_2.00u_Vertical
SW69: 1/End; SW_MX_Hotswap_Optional_1.00u
SW70: 2/↓; SW_MX_Hotswap_Optional_1.00u
SW71: 3/PgDn; SW_MX_Hotswap_Optional_1.00u
SW72: Shift; SW_MX_Hotswap_Optional_2.25u
SW73: Z; SW_MX_Hotswap_Optional_1.00u
SW74: X; SW_MX_Hotswap_Optional_1.00u
SW75: C; SW_MX_Hotswap_Optional_1.00u
SW76: V; SW_MX_Hotswap_Optional_1.00u
SW77: B; SW_MX_Hotswap_Optional_1.00u
SW78: N; SW_MX_Hotswap_Optional_1.00u
SW79: M; SW_MX_Hotswap_Optional_1.00u
SW80: </,; SW_MX_Hotswap_Optional_1.00u
SW81: >/.; SW_MX_Hotswap_Optional_1.00u
SW82: ?//; SW_MX_Hotswap_Optional_1.00u
SW83: ↑; SW_MX_Hotswap_Optional_1.00u
SW84: Shift; SW_MX_Hotswap_Optional_1.75u
SW85: 0/Ins; SW_MX_Hotswap_Optional_1.50u
SW86: ./Del; SW_MX_Hotswap_Optional_1.50u
SW87: Ctrl; SW_MX_Hotswap_Optional_1.25u
SW88: Win; SW_MX_Hotswap_Optional_1.25u
SW89: Alt; SW_MX_Hotswap_Optional_1.25u
SW90: Space; SW_MX_Hotswap_Optional_6.25u
SW91: |/\; SW_MX_Hotswap_Optional_1.00u
SW92: ←; SW_MX_Hotswap_Optional_1.00u
SW93: ↓; SW_MX_Hotswap_Optional_1.00u
SW94: →; SW_MX_Hotswap_Optional_1.00u
SW95: Ctrl; SW_MX_Hotswap_Optional_1.00u

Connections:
COL0: D68.1 (K), D85.1 (K); also elsewhere on the board
COL1: D69.1 (K), D86.1 (K); also elsewhere on the board
COL2: D70.1 (K), D87.1 (K); also elsewhere on the board
COL3: D71.1 (K), D88.1 (K); also elsewhere on the board
COL4: D72.1 (K), D89.1 (K); also elsewhere on the board
COL5: D73.1 (K), D90.1 (K); also elsewhere on the board
COL6: D74.1 (K), D91.1 (K); also elsewhere on the board
COL7: D75.1 (K), D92.1 (K); also elsewhere on the board
COL8: D76.1 (K), D93.1 (K); also elsewhere on the board
COL9: D77.1 (K), D94.1 (K); also elsewhere on the board
COL10: D78.1 (K), D95.1 (K); also elsewhere on the board
COL11: D79.1 (K); also elsewhere on the board
COL12: D80.1 (K); also elsewhere on the board
COL13: D81.1 (K); also elsewhere on the board
COL14: D82.1 (K); also elsewhere on the board
COL15: D83.1 (K); also elsewhere on the board
COL16: D84.1 (K); also elsewhere on the board
unnamed: D68.2 (A), SW68.2
unnamed: D69.2 (A), SW69.2
unnamed: D70.2 (A), SW70.2
unnamed: D71.2 (A), SW71.2
unnamed: D72.2 (A), SW72.2
unnamed: D73.2 (A), SW73.2
unnamed: D74.2 (A), SW74.2
unnamed: D75.2 (A), SW75.2
unnamed: D76.2 (A), SW76.2
unnamed: D77.2 (A), SW77.2
unnamed: D78.2 (A), SW78.2
unnamed: D79.2 (A), SW79.2
unnamed: D80.2 (A), SW80.2
unnamed: D81.2 (A), SW81.2
unnamed: D82.2 (A), SW82.2
unnamed: D83.2 (A), SW83.2
unnamed: D84.2 (A), SW84.2
unnamed: D85.2 (A), SW85.2
unnamed: D86.2 (A), SW86.2
unnamed: D87.2 (A), SW87.2
unnamed: D88.2 (A), SW88.2
unnamed: D89.2 (A), SW89.2
unnamed: D90.2 (A), SW90.2
unnamed: D91.2 (A), SW91.2
unnamed: D92.2 (A), SW92.2
unnamed: D93.2 (A), SW93.2
unnamed: D94.2 (A), SW94.2
unnamed: D95.2 (A), SW95.2
ROW4: SW68.1, SW69.1, SW70.1, SW71.1, SW72.1, SW73.1, SW74.1, SW75.1, SW76.1, SW77.1, SW78.1, SW79.1, SW80.1, SW81.1, SW82.1, SW83.1, SW84.1; also elsewhere on the board
ROW5: SW85.1, SW86.1, SW87.1, SW88.1, SW89.1, SW90.1, SW91.1, SW92.1, SW93.1, SW94.1, SW95.1; also elsewhere on the board

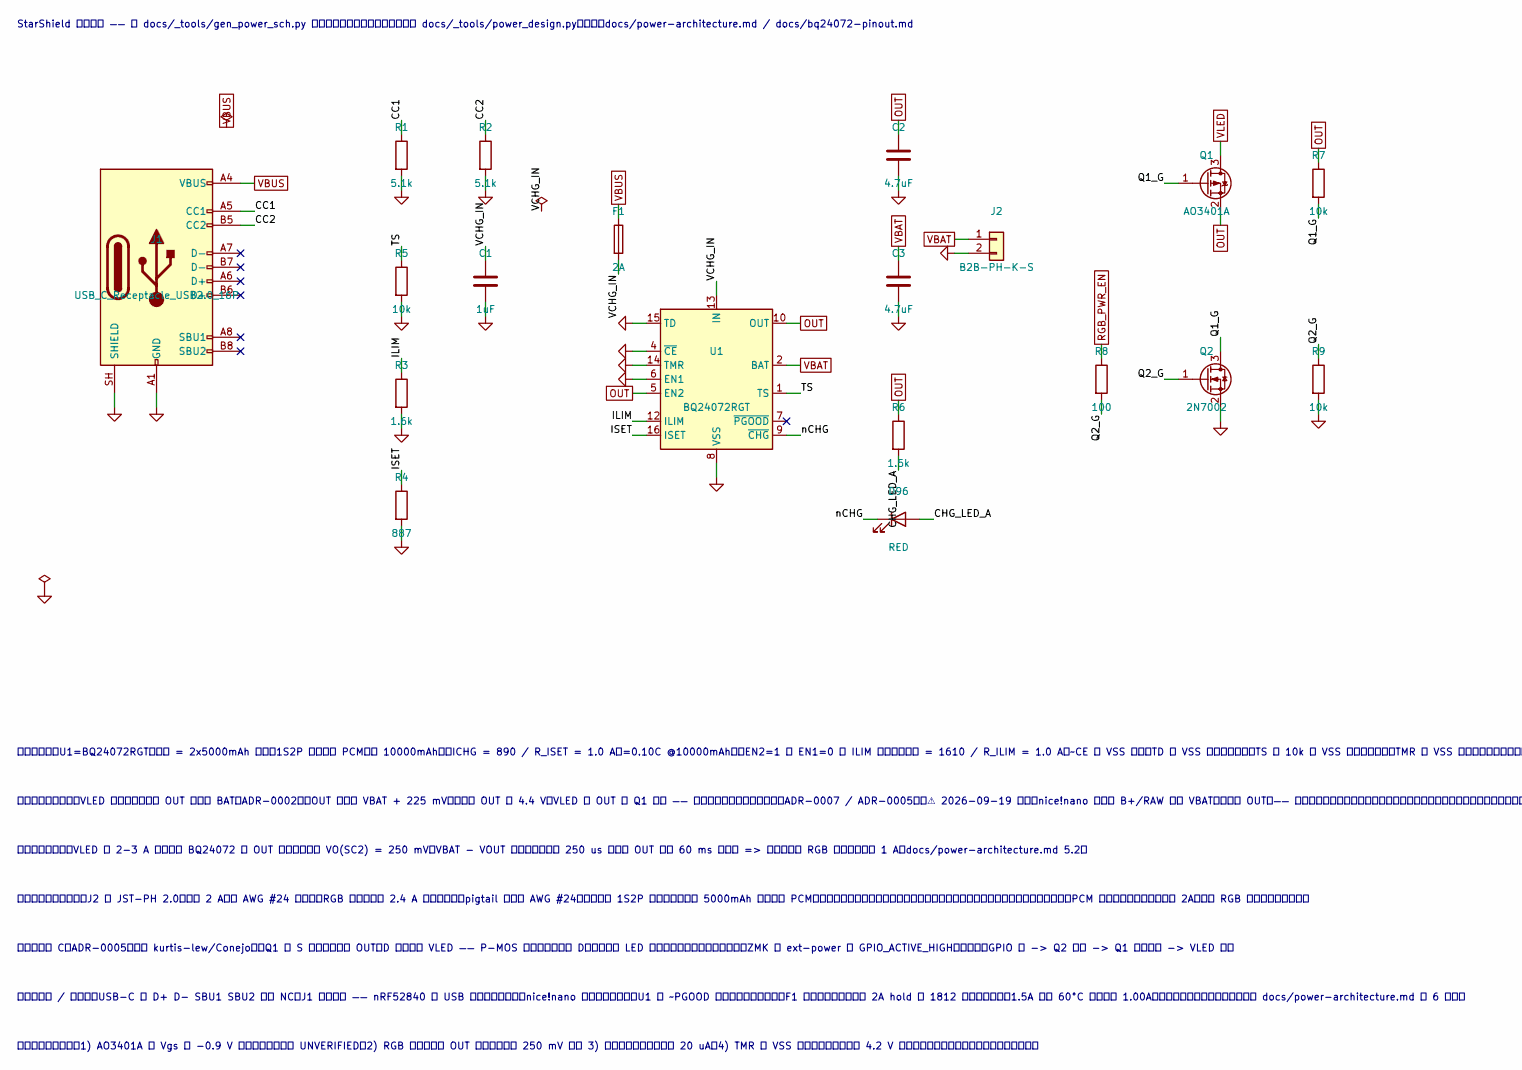
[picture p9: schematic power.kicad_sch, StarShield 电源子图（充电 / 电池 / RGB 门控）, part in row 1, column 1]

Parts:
C1: 1uF; C_0603_1608Metric
C2, C3: 4.7uF; C_0603_1608Metric
D96: RED; LED_0603_1608Metric
F1: 2A; Fuse_1812_4532Metric; MPN MF-MSMF200; LCSC ❓待补（BOM 阶段）
J1: USB_C_Receptacle_USB2.0_16P; USB_C_Receptacle_HRO_TYPE-C-31-M-12; MPN TYPE-C-31-M-12; LCSC C165948
J2: B2B-PH-K-S; JST_PH_B2B-PH-K_1x02_P2.00mm_Vertical; MPN B2B-PH-K-S(LF)(SN); LCSC C131337
Q1: AO3401A; SOT-23; MPN AO3401A
Q2: 2N7002; SOT-23; MPN 2N7002
R1, R2: 5.1k; R_0603_1608Metric
R3: 1.6k; R_0603_1608Metric
R4: 887; R_0603_1608Metric
R5, R7, R9: 10k; R_0603_1608Metric
R6: 1.5k; R_0603_1608Metric
R8: 100; R_0603_1608Metric
U1: BQ24072RGT; VQFN-16-1EP_3x3mm_P0.5mm_EP1.6x1.6mm_ThermalVias; MPN BQ24072RGT

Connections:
GND: C1.2, C2.2, C3.2, J1.A1 (GND), J1.A12 (GND), J1.B1 (GND), J1.B12 (GND), J1.SH (SHIELD), J2.2, Q2.2 (S), R1.2, R2.2, R3.2, R4.2, R5.2, R9.2, U1.4 (~CE), U1.6 (EN1), U1.8 (VSS), U1.14 (TMR), U1.15 (TD), U1.17 (VSS); also elsewhere on the board
OUT: C2.1, Q1.2 (S), R6.1, R7.1, U1.5 (EN2), U1.10 (OUT), U1.11 (OUT)
RGB_PWR_EN: R8.1; also elsewhere on the board
VBAT: C3.1, J2.1, U1.2 (BAT), U1.3 (BAT); also elsewhere on the board
VBUS: F1.1, J1.A4 (VBUS), J1.A9 (VBUS), J1.B4 (VBUS), J1.B9 (VBUS)
VLED: Q1.3 (D); also elsewhere on the board
电源 / 充电 / RGB 门控/CC1: J1.A5 (CC1), R1.1
电源 / 充电 / RGB 门控/CC2: J1.B5 (CC2), R2.1
电源 / 充电 / RGB 门控/CHG_LED_A: D96.2 (A), R6.2
电源 / 充电 / RGB 门控/ILIM: R3.1, U1.12 (ILIM)
电源 / 充电 / RGB 门控/ISET: R4.1, U1.16 (ISET)
电源 / 充电 / RGB 门控/Q1_G: Q1.1 (G), Q2.3 (D), R7.2
电源 / 充电 / RGB 门控/Q2_G: Q2.1 (G), R8.2, R9.1
电源 / 充电 / RGB 门控/TS: R5.1, U1.1 (TS)
电源 / 充电 / RGB 门控/VCHG_IN: C1.1, F1.2, U1.13 (IN)
电源 / 充电 / RGB 门控/nCHG: D96.1 (K), U1.9 (~CHG)

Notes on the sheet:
StarShield 电源子图 —— 由 docs/_tools/gen_power_sch.py 自动生成，请勿手改；改电路请改 docs/_tools/power_design.py。依据：docs/power-architecture.md / docs/bq24072-pinout.md
【取值依据】U1=BQ24072RGT。电池 = 2x5000mAh 并联（1S2P 共用一块 PCM，共 10000mAh）。ICHG = 890 / R_ISET = 1.0 A（=0.10C @10000mAh）；EN2=1 且 EN1=0 选 ILIM 档，输入限流 = 1610 / R_ILIM = 1.0 A；~CE 接 VSS 常开；TD 接 VSS 使能充电终止；TS 经 10k 到 VSS 禁用温度监测；TMR 接 VSS 禁用所有安全定时器（10h 仍超定时器 typ 9.6h）。VBUS 经 F1（2A hold 自恢复保险丝，1812）后进 IN。注意：输入取 1.0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
【电源路径】重载（VLED 灯轨等）必须接 OUT 而不是 BAT（ADR-0002）。OUT 稳压到 VBAT + 225 mV，满电时 OUT 约 4.4 V。VLED 由 OUT 经 Q1 门控 —— 属电池直供，不含任何升压（ADR-0007 / ADR-0005）。⚠️ 2026-09-19 例外：nice!nano 模块的 B+/RAW 改接 VBAT（不再接 OUT）—— 因为模块自带充电器要能把电流送进电池（插模块口即充电）；模块本身电流很小（休眠 20uA 级），不影响电源路径的意义
【走线电流约束】VLED 按 2-3 A 走线。但 BQ24072 的 OUT 短路保护阈值 VO(SC2) = 250 mV，VBAT - VOUT 超过该值并持续 250 us 即切断 OUT 并在 60 ms 后重试 => 固件必须把 RGB 峰值限制在约 1 A（docs/power-architecture.md 5.2）
【电池与连接器约束】J2 为 JST-PH 2.0，额定 2 A（限 AWG #24 条件）。RGB 全亮峰值约 2.4 A 超过该额定，pigtail 请指定 AWG #24。电池须为 1S2P 一体化包（两块 5000mAh 共用一块 PCM），不可用两块各自带保护板的电芯直接并联（会互充，且两块保护板阈值失配）；PCM 的过流保护阈值必须大于 2A，否则 RGB 全亮会触发保护断电
【门控拓扑 C（ADR-0005，照抄 kurtis-lew/Conejo）】Q1 的 S 必须接电源轨 OUT、D 接负载轨 VLED —— P-MOS 体二极管阳极在 D，反接会让 LED 轨经体二极管常通，门控失效。ZMK 侧 ext-power 用 GPIO_ACTIVE_HIGH。控制链：GPIO 高 -> Q2 导通 -> Q1 栅极拉低 -> VLED 得电
【本版留空 / 未决项】USB-C 的 D+ D- SBU1 SBU2 全部 NC（J1 只做充电 —— nRF52840 的 USB 是独立专用引脚，nice!nano 排针上无引出）；U1 的 ~PGOOD 悬空（预留测试点）。F1 已按降额曲线定案为 2A hold 的 1812 自恢复保险丝（1.5A 档在 60°C 降额后仅 1.00A，等于工作电流，会误断）。详见 docs/power-architecture.md 第 6 节待办
【投板后必须实测】1) AO3401A 在 Vgs 约 -0.9 V 时的关断漏电（标 UNVERIFIED）2) RGB 峰值电流下 OUT 压降是否仍在 250 mV 以内 3) 深睡整机电流（目标约 20 uA）4) TMR 接 VSS 后充电能否正常走到 4.2 V 并靠终止电流判据结束（安全定时器已禁用）

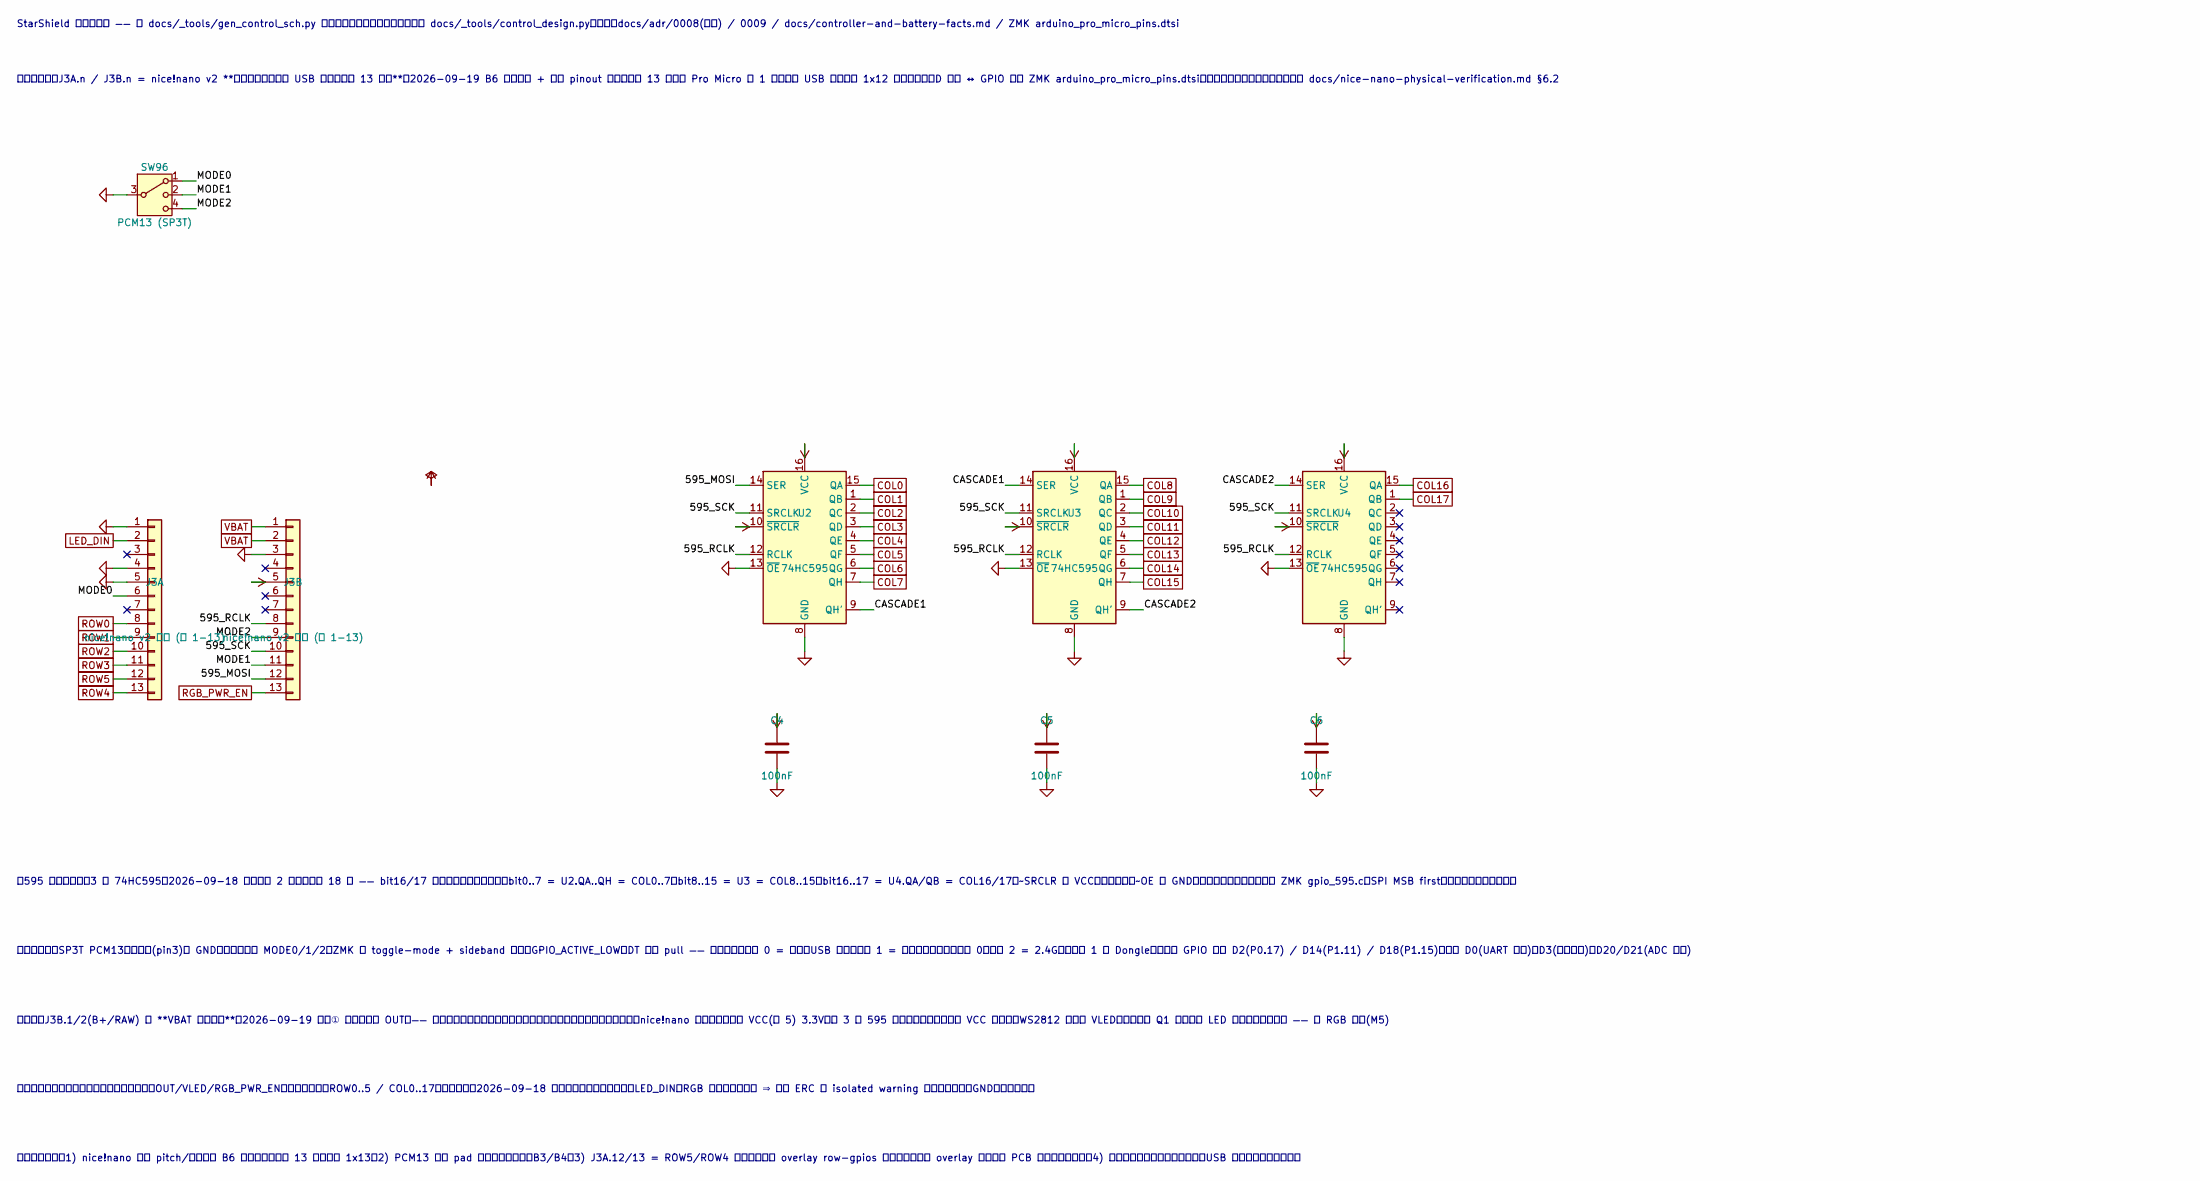
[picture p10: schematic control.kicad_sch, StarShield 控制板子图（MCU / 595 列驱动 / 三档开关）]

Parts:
C4, C5, C6: 100nF; C_0603_1608Metric
J3A: nice!nano v2 左列 (孔 1-13); PinSocket_1x13_P2.54mm_Vertical; MPN Mill-Max 315-43-113-41-001000 ❓待核
J3B: nice!nano v2 右列 (孔 1-13); PinSocket_1x13_P2.54mm_Vertical; MPN Mill-Max 315-43-113-41-001000 ❓待核
SW96: PCM13 (SP3T); SW_SP3T_PCM13; MPN PCM13SMTR; LCSC ❓待补（BOM 阶段）
U2, U3, U4: 74HC595; SOIC-16_3.9x9.9mm_P1.27mm

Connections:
COL0: U2.15 (QA); also elsewhere on the board
COL1: U2.1 (QB); also elsewhere on the board
COL2: U2.2 (QC); also elsewhere on the board
COL3: U2.3 (QD); also elsewhere on the board
COL4: U2.4 (QE); also elsewhere on the board
COL5: U2.5 (QF); also elsewhere on the board
COL6: U2.6 (QG); also elsewhere on the board
COL7: U2.7 (QH); also elsewhere on the board
COL8: U3.15 (QA); also elsewhere on the board
COL9: U3.1 (QB); also elsewhere on the board
COL10: U3.2 (QC); also elsewhere on the board
COL11: U3.3 (QD); also elsewhere on the board
COL12: U3.4 (QE); also elsewhere on the board
COL13: U3.5 (QF); also elsewhere on the board
COL14: U3.6 (QG); also elsewhere on the board
COL15: U3.7 (QH); also elsewhere on the board
COL16: U4.15 (QA); also elsewhere on the board
COL17: U4.1 (QB); also elsewhere on the board
GND: C4.2, C5.2, C6.2, J3A.1, J3A.4, J3A.5, J3B.3, SW96.3, U2.8 (GND), U2.13 (~OE), U3.8 (GND), U3.13 (~OE), U4.8 (GND), U4.13 (~OE); also elsewhere on the board
LED_DIN: J3A.2; also elsewhere on the board
RGB_PWR_EN: J3B.13; also elsewhere on the board
ROW0: J3A.8; also elsewhere on the board
ROW1: J3A.9; also elsewhere on the board
ROW2: J3A.10; also elsewhere on the board
ROW3: J3A.11; also elsewhere on the board
ROW4: J3A.13; also elsewhere on the board
ROW5: J3A.12; also elsewhere on the board
VBAT: J3B.1, J3B.2; also elsewhere on the board
VCC: C4.1, C5.1, C6.1, J3B.5, U2.10 (~SRCLR), U2.16 (VCC), U3.10 (~SRCLR), U3.16 (VCC), U4.10 (~SRCLR), U4.16 (VCC)
控制板 / MCU / 595 / 模式开关/595_MOSI: J3B.12, U2.14 (SER)
控制板 / MCU / 595 / 模式开关/595_RCLK: J3B.8, U2.12 (RCLK), U3.12 (RCLK), U4.12 (RCLK)
控制板 / MCU / 595 / 模式开关/595_SCK: J3B.10, U2.11 (SRCLK), U3.11 (SRCLK), U4.11 (SRCLK)
控制板 / MCU / 595 / 模式开关/CASCADE1: U2.9 (QH'), U3.14 (SER)
控制板 / MCU / 595 / 模式开关/CASCADE2: U3.9 (QH'), U4.14 (SER)
控制板 / MCU / 595 / 模式开关/MODE0: J3A.6, SW96.1
控制板 / MCU / 595 / 模式开关/MODE1: J3B.11, SW96.2
控制板 / MCU / 595 / 模式开关/MODE2: J3B.9, SW96.4

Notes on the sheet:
StarShield 控制板子图 —— 由 docs/_tools/gen_control_sch.py 自动生成，请勿手改；改电路请改 docs/_tools/control_design.py。依据：docs/adr/0008(修订) / 0009 / docs/controller-and-battery-facts.md / ZMK arduino_pro_micro_pins.dtsi
【排针映射】J3A.n / J3B.n = nice!nano v2 **实物孔位序号（自 USB 端起，每排 13 孔）**。2026-09-19 B6 实物核对 + 官方 pinout 图确认每排 13 孔（比 Pro Micro 多 1 孔，多在 USB 端）；原 1x12 映射已作废。D 编号 ↔ GPIO 仍依 ZMK arduino_pro_micro_pins.dtsi，与孔位序号无关。逐孔映射表见 docs/nice-nano-physical-verification.md §6.2
【595 级联与位序】3 颗 74HC595（2026-09-18 修订，原 2 颗无法驱动 18 列 —— bit16/17 会被推出链尾）。位序：bit0..7 = U2.QA..QH = COL0..7；bit8..15 = U3 = COL8..15；bit16..17 = U4.QA/QB = COL16/17。~SRCLR 接 VCC（不复位）、~OE 接 GND（输出常使能）。位序依据 ZMK gpio_595.c：SPI MSB first，先移出的位最终在链尾
【三档开关】SP3T PCM13，公共端(pin3)接 GND，三个掷点接 MODE0/1/2。ZMK 用 toggle-mode + sideband 读取（GPIO_ACTIVE_LOW，DT 不写 pull —— 驱动管理）。档 0 = 有线（USB 输出）；档 1 = 蓝牙直连主机（配对位 0）；档 2 = 2.4G（配对位 1 连 Dongle）。开关 GPIO 定案 D2(P0.17) / D14(P1.11) / D18(P1.15)：保留 D0(UART 语义)、D3(普通余量)、D20/D21(ADC 余量)
【供电】J3B.1/2(B+/RAW) 接 **VBAT 电池节点**（2026-09-19 方案① 改接，原为 OUT）—— 如此插模块口即由模块自带充电器给电池充电（有线模式也充电）。nice!nano 板载稳压后输出 VCC(孔 5) 3.3V，给 3 颗 595 供电（负载轻，远低于 VCC 能力）。WS2812 供电走 VLED（电源子图 Q1 门控后的 LED 轨），不在本子图 —— 见 RGB 子图(M5)
【与其它子图的接口】全局标签同名即相连：OUT/VLED/RGB_PWR_EN（电源子图）、ROW0..5 / COL0..17（矩阵子图，2026-09-18 起矩阵侧也是全局标签）、LED_DIN（RGB 子图，尚未绘制 ⇒ 本图 ERC 的 isolated warning 属已知待办）、GND（电源符号）
【投板前核对】1) nice!nano 排针 pitch/脚数已由 B6 实物核对（每排 13 孔，已改 1x13）2) PCM13 封装 pad 与符号掷点对应（B3/B4）3) J3A.12/13 = ROW5/ROW4 的交错顺序与 overlay row-gpios 一一对应（已按 overlay 核实，但 PCB 布局时仍需复核）4) 排针针径与母座孔径、第五项：USB 口伸出量决定外壳开孔

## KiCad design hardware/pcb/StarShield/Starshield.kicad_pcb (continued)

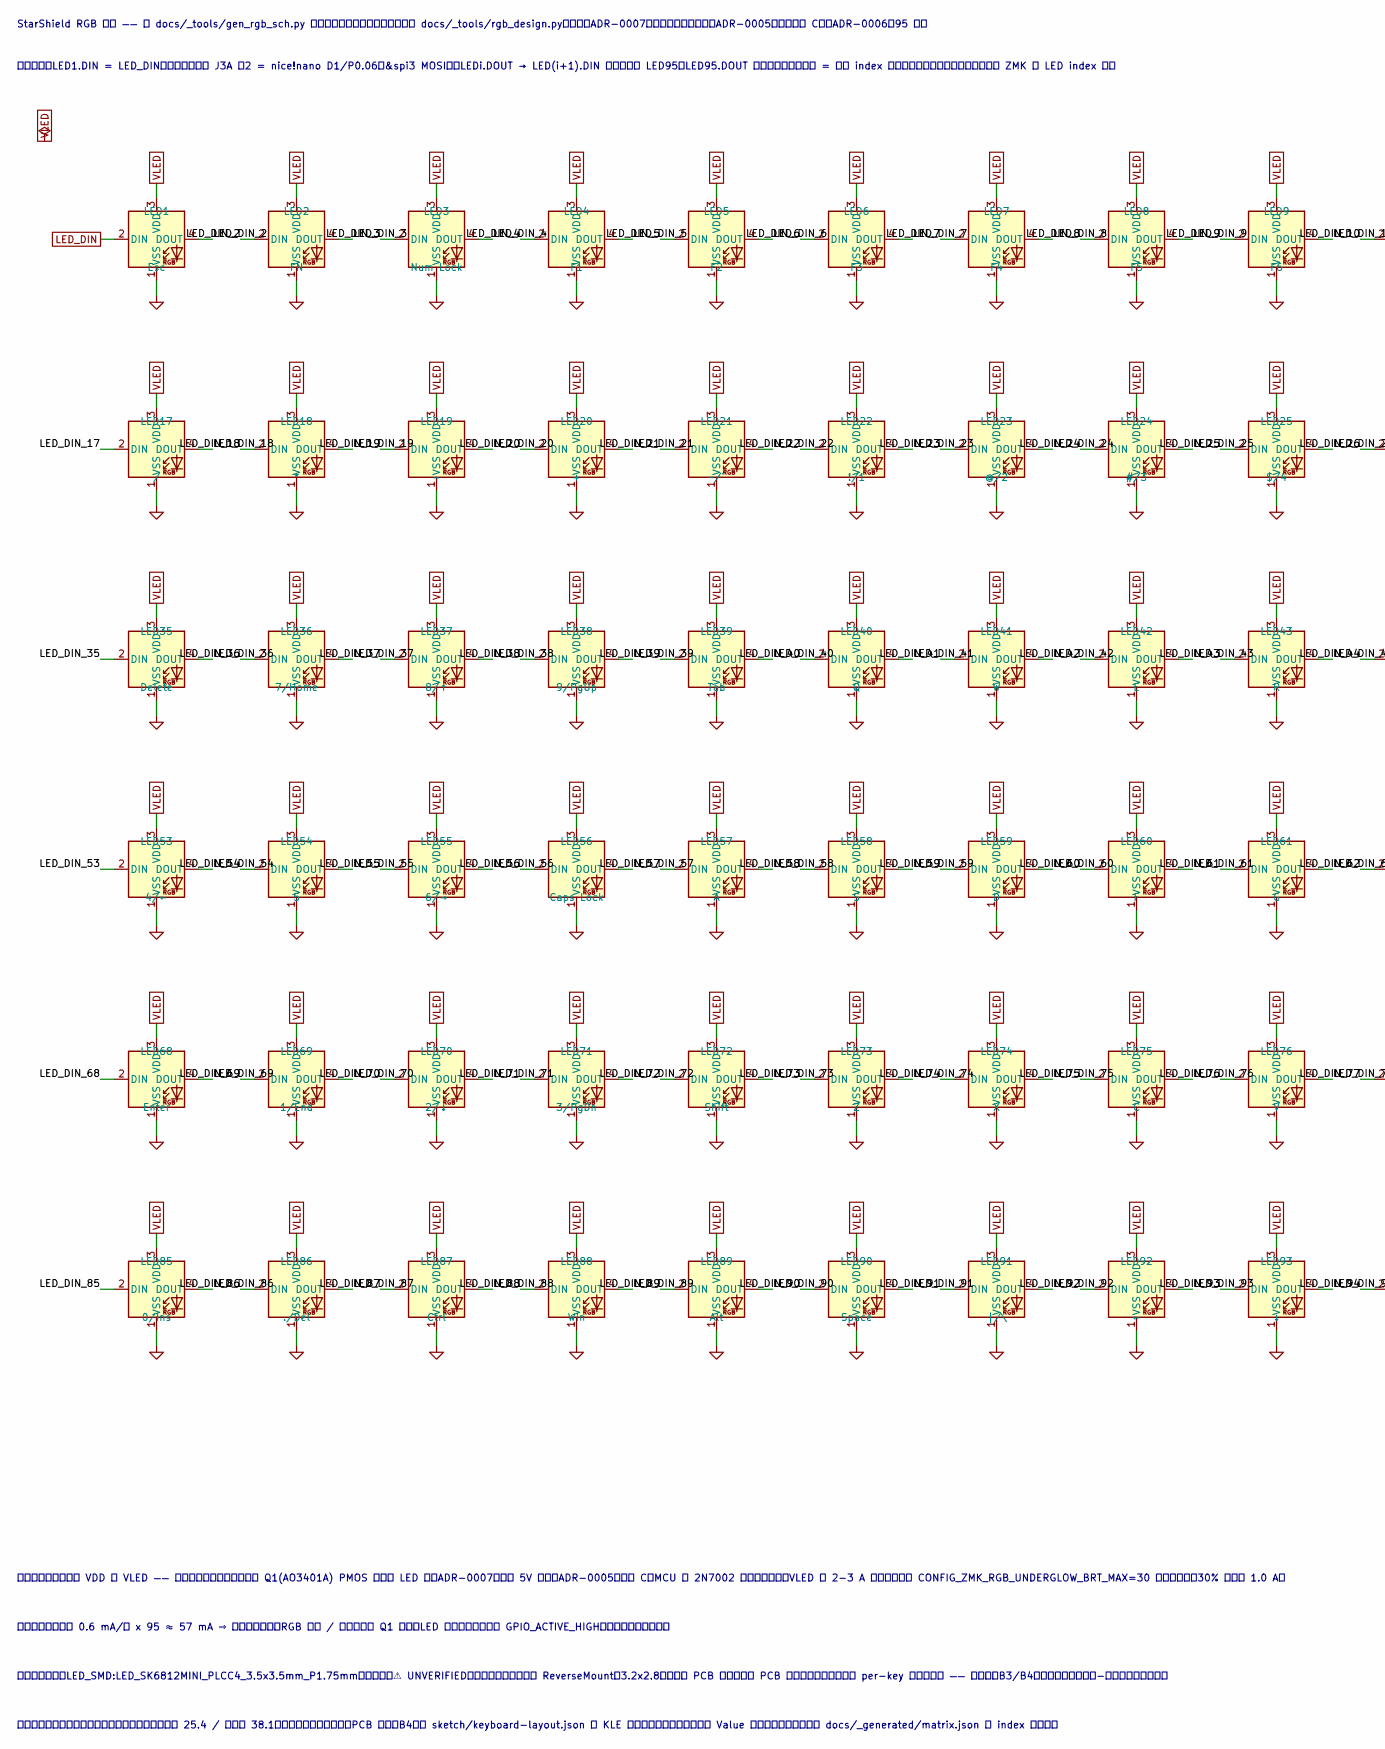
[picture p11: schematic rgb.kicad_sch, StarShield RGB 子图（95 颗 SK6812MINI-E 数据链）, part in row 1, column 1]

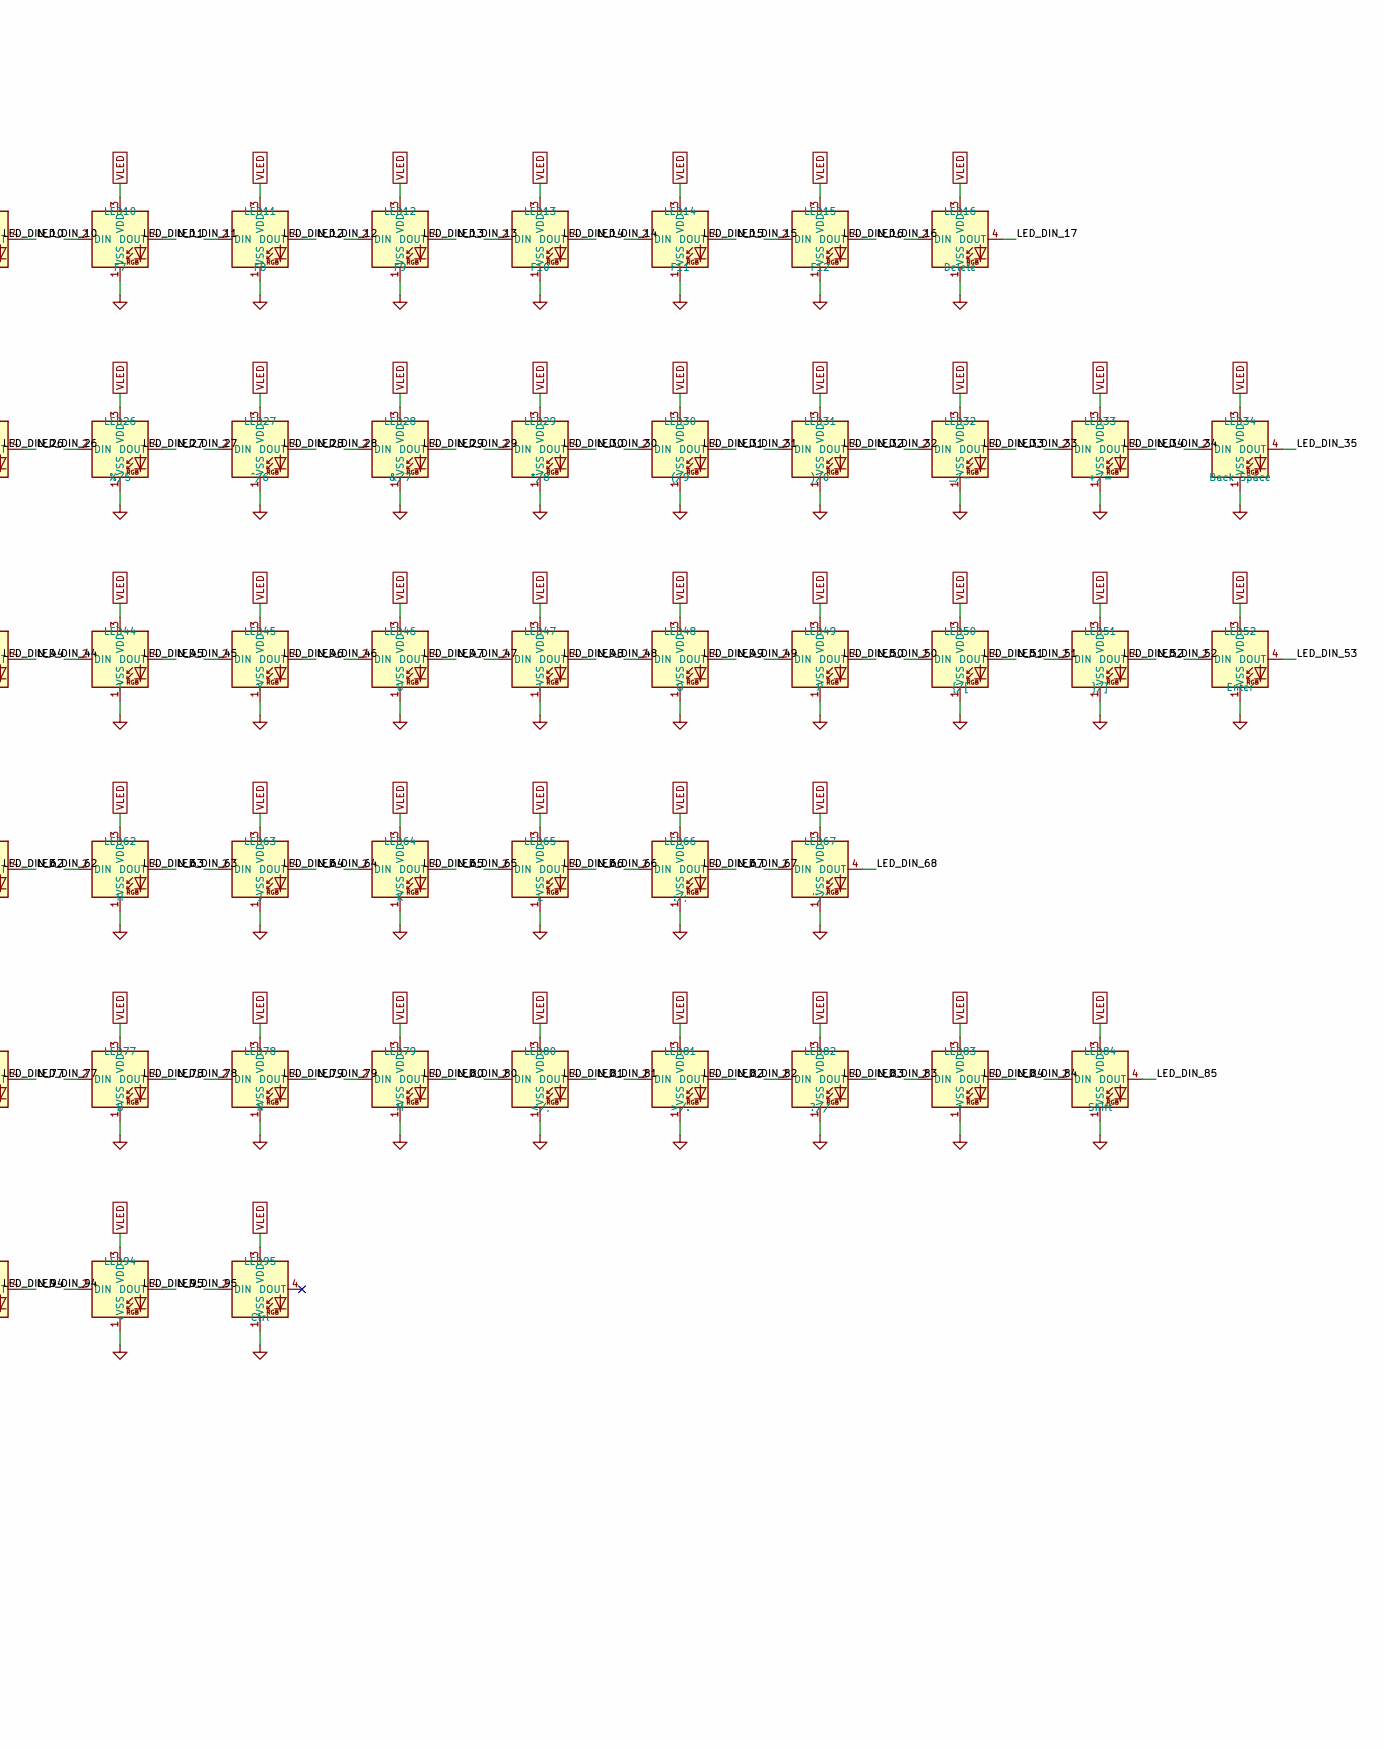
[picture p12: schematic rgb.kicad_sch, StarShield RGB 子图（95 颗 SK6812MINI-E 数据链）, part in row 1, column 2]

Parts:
LED1: Esc; LED_SK6812MINI_PLCC4_3.5x3.5mm_P1.75mm; MPN SK6812MINI-E; LCSC C5149201
LED2: FN; LED_SK6812MINI_PLCC4_3.5x3.5mm_P1.75mm; MPN SK6812MINI-E; LCSC C5149201
LED3: Num Lock; LED_SK6812MINI_PLCC4_3.5x3.5mm_P1.75mm; MPN SK6812MINI-E; LCSC C5149201
LED4: F1; LED_SK6812MINI_PLCC4_3.5x3.5mm_P1.75mm; MPN SK6812MINI-E; LCSC C5149201
LED5: F2; LED_SK6812MINI_PLCC4_3.5x3.5mm_P1.75mm; MPN SK6812MINI-E; LCSC C5149201
LED6: F3; LED_SK6812MINI_PLCC4_3.5x3.5mm_P1.75mm; MPN SK6812MINI-E; LCSC C5149201
LED7: F4; LED_SK6812MINI_PLCC4_3.5x3.5mm_P1.75mm; MPN SK6812MINI-E; LCSC C5149201
LED8: F5; LED_SK6812MINI_PLCC4_3.5x3.5mm_P1.75mm; MPN SK6812MINI-E; LCSC C5149201
LED9: F6; LED_SK6812MINI_PLCC4_3.5x3.5mm_P1.75mm; MPN SK6812MINI-E; LCSC C5149201
LED10: F7; LED_SK6812MINI_PLCC4_3.5x3.5mm_P1.75mm; MPN SK6812MINI-E; LCSC C5149201
LED11: F8; LED_SK6812MINI_PLCC4_3.5x3.5mm_P1.75mm; MPN SK6812MINI-E; LCSC C5149201
LED12: F9; LED_SK6812MINI_PLCC4_3.5x3.5mm_P1.75mm; MPN SK6812MINI-E; LCSC C5149201
LED13: F10; LED_SK6812MINI_PLCC4_3.5x3.5mm_P1.75mm; MPN SK6812MINI-E; LCSC C5149201
LED14: F11; LED_SK6812MINI_PLCC4_3.5x3.5mm_P1.75mm; MPN SK6812MINI-E; LCSC C5149201
LED15: F12; LED_SK6812MINI_PLCC4_3.5x3.5mm_P1.75mm; MPN SK6812MINI-E; LCSC C5149201
LED16, LED35: Delete; LED_SK6812MINI_PLCC4_3.5x3.5mm_P1.75mm; MPN SK6812MINI-E; LCSC C5149201
LED17: /; LED_SK6812MINI_PLCC4_3.5x3.5mm_P1.75mm; MPN SK6812MINI-E; LCSC C5149201
LED18: *; LED_SK6812MINI_PLCC4_3.5x3.5mm_P1.75mm; MPN SK6812MINI-E; LCSC C5149201
LED19: -; LED_SK6812MINI_PLCC4_3.5x3.5mm_P1.75mm; MPN SK6812MINI-E; LCSC C5149201
LED20: +; LED_SK6812MINI_PLCC4_3.5x3.5mm_P1.75mm; MPN SK6812MINI-E; LCSC C5149201
LED21: ~/`; LED_SK6812MINI_PLCC4_3.5x3.5mm_P1.75mm; MPN SK6812MINI-E; LCSC C5149201
LED22: !/1; LED_SK6812MINI_PLCC4_3.5x3.5mm_P1.75mm; MPN SK6812MINI-E; LCSC C5149201
LED23: @/2; LED_SK6812MINI_PLCC4_3.5x3.5mm_P1.75mm; MPN SK6812MINI-E; LCSC C5149201
LED24: #/3; LED_SK6812MINI_PLCC4_3.5x3.5mm_P1.75mm; MPN SK6812MINI-E; LCSC C5149201
LED25: $/4; LED_SK6812MINI_PLCC4_3.5x3.5mm_P1.75mm; MPN SK6812MINI-E; LCSC C5149201
LED26: %/5; LED_SK6812MINI_PLCC4_3.5x3.5mm_P1.75mm; MPN SK6812MINI-E; LCSC C5149201
LED27: ^/6; LED_SK6812MINI_PLCC4_3.5x3.5mm_P1.75mm; MPN SK6812MINI-E; LCSC C5149201
LED28: &/7; LED_SK6812MINI_PLCC4_3.5x3.5mm_P1.75mm; MPN SK6812MINI-E; LCSC C5149201
LED29: */8; LED_SK6812MINI_PLCC4_3.5x3.5mm_P1.75mm; MPN SK6812MINI-E; LCSC C5149201
LED30: (/9; LED_SK6812MINI_PLCC4_3.5x3.5mm_P1.75mm; MPN SK6812MINI-E; LCSC C5149201
LED31: )/0; LED_SK6812MINI_PLCC4_3.5x3.5mm_P1.75mm; MPN SK6812MINI-E; LCSC C5149201
LED32: _/-; LED_SK6812MINI_PLCC4_3.5x3.5mm_P1.75mm; MPN SK6812MINI-E; LCSC C5149201
LED33: +/=; LED_SK6812MINI_PLCC4_3.5x3.5mm_P1.75mm; MPN SK6812MINI-E; LCSC C5149201
LED34: Back Space; LED_SK6812MINI_PLCC4_3.5x3.5mm_P1.75mm; MPN SK6812MINI-E; LCSC C5149201
LED36: 7/Home; LED_SK6812MINI_PLCC4_3.5x3.5mm_P1.75mm; MPN SK6812MINI-E; LCSC C5149201
LED37: 8/↑; LED_SK6812MINI_PLCC4_3.5x3.5mm_P1.75mm; MPN SK6812MINI-E; LCSC C5149201
LED38: 9/PgUp; LED_SK6812MINI_PLCC4_3.5x3.5mm_P1.75mm; MPN SK6812MINI-E; LCSC C5149201
LED39: Tab; LED_SK6812MINI_PLCC4_3.5x3.5mm_P1.75mm; MPN SK6812MINI-E; LCSC C5149201
LED40: Q; LED_SK6812MINI_PLCC4_3.5x3.5mm_P1.75mm; MPN SK6812MINI-E; LCSC C5149201
LED41: W; LED_SK6812MINI_PLCC4_3.5x3.5mm_P1.75mm; MPN SK6812MINI-E; LCSC C5149201
LED42: E; LED_SK6812MINI_PLCC4_3.5x3.5mm_P1.75mm; MPN SK6812MINI-E; LCSC C5149201
LED43: R; LED_SK6812MINI_PLCC4_3.5x3.5mm_P1.75mm; MPN SK6812MINI-E; LCSC C5149201
LED44: T; LED_SK6812MINI_PLCC4_3.5x3.5mm_P1.75mm; MPN SK6812MINI-E; LCSC C5149201
LED45: Y; LED_SK6812MINI_PLCC4_3.5x3.5mm_P1.75mm; MPN SK6812MINI-E; LCSC C5149201
LED46: U; LED_SK6812MINI_PLCC4_3.5x3.5mm_P1.75mm; MPN SK6812MINI-E; LCSC C5149201
LED47: I; LED_SK6812MINI_PLCC4_3.5x3.5mm_P1.75mm; MPN SK6812MINI-E; LCSC C5149201
LED48: O; LED_SK6812MINI_PLCC4_3.5x3.5mm_P1.75mm; MPN SK6812MINI-E; LCSC C5149201
LED49: P; LED_SK6812MINI_PLCC4_3.5x3.5mm_P1.75mm; MPN SK6812MINI-E; LCSC C5149201
LED50: {/[; LED_SK6812MINI_PLCC4_3.5x3.5mm_P1.75mm; MPN SK6812MINI-E; LCSC C5149201
LED51: }/]; LED_SK6812MINI_PLCC4_3.5x3.5mm_P1.75mm; MPN SK6812MINI-E; LCSC C5149201
LED52, LED68: Enter; LED_SK6812MINI_PLCC4_3.5x3.5mm_P1.75mm; MPN SK6812MINI-E; LCSC C5149201
LED53: 4/←; LED_SK6812MINI_PLCC4_3.5x3.5mm_P1.75mm; MPN SK6812MINI-E; LCSC C5149201
LED54: 5; LED_SK6812MINI_PLCC4_3.5x3.5mm_P1.75mm; MPN SK6812MINI-E; LCSC C5149201
LED55: 6/→; LED_SK6812MINI_PLCC4_3.5x3.5mm_P1.75mm; MPN SK6812MINI-E; LCSC C5149201
LED56: Caps Lock; LED_SK6812MINI_PLCC4_3.5x3.5mm_P1.75mm; MPN SK6812MINI-E; LCSC C5149201
LED57: A; LED_SK6812MINI_PLCC4_3.5x3.5mm_P1.75mm; MPN SK6812MINI-E; LCSC C5149201
LED58: S; LED_SK6812MINI_PLCC4_3.5x3.5mm_P1.75mm; MPN SK6812MINI-E; LCSC C5149201
LED59: D; LED_SK6812MINI_PLCC4_3.5x3.5mm_P1.75mm; MPN SK6812MINI-E; LCSC C5149201
LED60: F; LED_SK6812MINI_PLCC4_3.5x3.5mm_P1.75mm; MPN SK6812MINI-E; LCSC C5149201
LED61: G; LED_SK6812MINI_PLCC4_3.5x3.5mm_P1.75mm; MPN SK6812MINI-E; LCSC C5149201
LED62: H; LED_SK6812MINI_PLCC4_3.5x3.5mm_P1.75mm; MPN SK6812MINI-E; LCSC C5149201
LED63: J; LED_SK6812MINI_PLCC4_3.5x3.5mm_P1.75mm; MPN SK6812MINI-E; LCSC C5149201
LED64: K; LED_SK6812MINI_PLCC4_3.5x3.5mm_P1.75mm; MPN SK6812MINI-E; LCSC C5149201
LED65: L; LED_SK6812MINI_PLCC4_3.5x3.5mm_P1.75mm; MPN SK6812MINI-E; LCSC C5149201
LED66: :/;; LED_SK6812MINI_PLCC4_3.5x3.5mm_P1.75mm; MPN SK6812MINI-E; LCSC C5149201
LED67: "/'; LED_SK6812MINI_PLCC4_3.5x3.5mm_P1.75mm; MPN SK6812MINI-E; LCSC C5149201
LED69: 1/End; LED_SK6812MINI_PLCC4_3.5x3.5mm_P1.75mm; MPN SK6812MINI-E; LCSC C5149201
LED70: 2/↓; LED_SK6812MINI_PLCC4_3.5x3.5mm_P1.75mm; MPN SK6812MINI-E; LCSC C5149201
LED71: 3/PgDn; LED_SK6812MINI_PLCC4_3.5x3.5mm_P1.75mm; MPN SK6812MINI-E; LCSC C5149201
LED72, LED84: Shift; LED_SK6812MINI_PLCC4_3.5x3.5mm_P1.75mm; MPN SK6812MINI-E; LCSC C5149201
LED73: Z; LED_SK6812MINI_PLCC4_3.5x3.5mm_P1.75mm; MPN SK6812MINI-E; LCSC C5149201
LED74: X; LED_SK6812MINI_PLCC4_3.5x3.5mm_P1.75mm; MPN SK6812MINI-E; LCSC C5149201
LED75: C; LED_SK6812MINI_PLCC4_3.5x3.5mm_P1.75mm; MPN SK6812MINI-E; LCSC C5149201
LED76: V; LED_SK6812MINI_PLCC4_3.5x3.5mm_P1.75mm; MPN SK6812MINI-E; LCSC C5149201
LED77: B; LED_SK6812MINI_PLCC4_3.5x3.5mm_P1.75mm; MPN SK6812MINI-E; LCSC C5149201
LED78: N; LED_SK6812MINI_PLCC4_3.5x3.5mm_P1.75mm; MPN SK6812MINI-E; LCSC C5149201
LED79: M; LED_SK6812MINI_PLCC4_3.5x3.5mm_P1.75mm; MPN SK6812MINI-E; LCSC C5149201
LED80: </,; LED_SK6812MINI_PLCC4_3.5x3.5mm_P1.75mm; MPN SK6812MINI-E; LCSC C5149201
LED81: >/.; LED_SK6812MINI_PLCC4_3.5x3.5mm_P1.75mm; MPN SK6812MINI-E; LCSC C5149201
LED82: ?//; LED_SK6812MINI_PLCC4_3.5x3.5mm_P1.75mm; MPN SK6812MINI-E; LCSC C5149201
LED83: ↑; LED_SK6812MINI_PLCC4_3.5x3.5mm_P1.75mm; MPN SK6812MINI-E; LCSC C5149201
LED85: 0/Ins; LED_SK6812MINI_PLCC4_3.5x3.5mm_P1.75mm; MPN SK6812MINI-E; LCSC C5149201
LED86: ./Del; LED_SK6812MINI_PLCC4_3.5x3.5mm_P1.75mm; MPN SK6812MINI-E; LCSC C5149201
LED87, LED95: Ctrl; LED_SK6812MINI_PLCC4_3.5x3.5mm_P1.75mm; MPN SK6812MINI-E; LCSC C5149201
LED88: Win; LED_SK6812MINI_PLCC4_3.5x3.5mm_P1.75mm; MPN SK6812MINI-E; LCSC C5149201
LED89: Alt; LED_SK6812MINI_PLCC4_3.5x3.5mm_P1.75mm; MPN SK6812MINI-E; LCSC C5149201
LED90: Space; LED_SK6812MINI_PLCC4_3.5x3.5mm_P1.75mm; MPN SK6812MINI-E; LCSC C5149201
LED91: |/\; LED_SK6812MINI_PLCC4_3.5x3.5mm_P1.75mm; MPN SK6812MINI-E; LCSC C5149201
LED92: ←; LED_SK6812MINI_PLCC4_3.5x3.5mm_P1.75mm; MPN SK6812MINI-E; LCSC C5149201
LED93: ↓; LED_SK6812MINI_PLCC4_3.5x3.5mm_P1.75mm; MPN SK6812MINI-E; LCSC C5149201
LED94: →; LED_SK6812MINI_PLCC4_3.5x3.5mm_P1.75mm; MPN SK6812MINI-E; LCSC C5149201

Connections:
GND: LED1.1 (VSS), LED2.1 (VSS), LED3.1 (VSS), LED4.1 (VSS), LED5.1 (VSS), LED6.1 (VSS), LED7.1 (VSS), LED8.1 (VSS), LED9.1 (VSS), LED10.1 (VSS), LED11.1 (VSS), LED12.1 (VSS), LED13.1 (VSS), LED14.1 (VSS), LED15.1 (VSS), LED16.1 (VSS), LED17.1 (VSS), LED18.1 (VSS), LED19.1 (VSS), LED20.1 (VSS), LED21.1 (VSS), LED22.1 (VSS), LED23.1 (VSS), LED24.1 (VSS), LED25.1 (VSS), LED26.1 (VSS), LED27.1 (VSS), LED28.1 (VSS), LED29.1 (VSS), LED30.1 (VSS), LED31.1 (VSS), LED32.1 (VSS), LED33.1 (VSS), LED34.1 (VSS), LED35.1 (VSS), LED36.1 (VSS), LED37.1 (VSS), LED38.1 (VSS), LED39.1 (VSS), LED40.1 (VSS), LED41.1 (VSS), LED42.1 (VSS), LED43.1 (VSS), LED44.1 (VSS), LED45.1 (VSS), LED46.1 (VSS), LED47.1 (VSS), LED48.1 (VSS), LED49.1 (VSS), LED50.1 (VSS), LED51.1 (VSS), LED52.1 (VSS), LED53.1 (VSS), LED54.1 (VSS), LED55.1 (VSS), LED56.1 (VSS), LED57.1 (VSS), LED58.1 (VSS), LED59.1 (VSS), LED60.1 (VSS), LED61.1 (VSS), LED62.1 (VSS), LED63.1 (VSS), LED64.1 (VSS), LED65.1 (VSS), LED66.1 (VSS), LED67.1 (VSS), LED68.1 (VSS), LED69.1 (VSS), LED70.1 (VSS), LED71.1 (VSS), LED72.1 (VSS), LED73.1 (VSS), LED74.1 (VSS), LED75.1 (VSS), LED76.1 (VSS), LED77.1 (VSS), LED78.1 (VSS), LED79.1 (VSS), LED80.1 (VSS), LED81.1 (VSS), LED82.1 (VSS), LED83.1 (VSS), LED84.1 (VSS), LED85.1 (VSS), LED86.1 (VSS), LED87.1 (VSS), LED88.1 (VSS), LED89.1 (VSS), LED90.1 (VSS), LED91.1 (VSS), LED92.1 (VSS), LED93.1 (VSS), LED94.1 (VSS), LED95.1 (VSS); also elsewhere on the board
LED_DIN: LED1.2 (DIN); also elsewhere on the board
RGB（95 颗 SK6812MINI-E 数据链）/LED_DIN_2: LED1.4 (DOUT), LED2.2 (DIN)
RGB（95 颗 SK6812MINI-E 数据链）/LED_DIN_3: LED2.4 (DOUT), LED3.2 (DIN)
RGB（95 颗 SK6812MINI-E 数据链）/LED_DIN_4: LED3.4 (DOUT), LED4.2 (DIN)
RGB（95 颗 SK6812MINI-E 数据链）/LED_DIN_5: LED4.4 (DOUT), LED5.2 (DIN)
RGB（95 颗 SK6812MINI-E 数据链）/LED_DIN_6: LED5.4 (DOUT), LED6.2 (DIN)
RGB（95 颗 SK6812MINI-E 数据链）/LED_DIN_7: LED6.4 (DOUT), LED7.2 (DIN)
RGB（95 颗 SK6812MINI-E 数据链）/LED_DIN_8: LED7.4 (DOUT), LED8.2 (DIN)
RGB（95 颗 SK6812MINI-E 数据链）/LED_DIN_9: LED8.4 (DOUT), LED9.2 (DIN)
RGB（95 颗 SK6812MINI-E 数据链）/LED_DIN_10: LED9.4 (DOUT), LED10.2 (DIN)
RGB（95 颗 SK6812MINI-E 数据链）/LED_DIN_11: LED10.4 (DOUT), LED11.2 (DIN)
RGB（95 颗 SK6812MINI-E 数据链）/LED_DIN_12: LED11.4 (DOUT), LED12.2 (DIN)
RGB（95 颗 SK6812MINI-E 数据链）/LED_DIN_13: LED12.4 (DOUT), LED13.2 (DIN)
RGB（95 颗 SK6812MINI-E 数据链）/LED_DIN_14: LED13.4 (DOUT), LED14.2 (DIN)
RGB（95 颗 SK6812MINI-E 数据链）/LED_DIN_15: LED14.4 (DOUT), LED15.2 (DIN)
RGB（95 颗 SK6812MINI-E 数据链）/LED_DIN_16: LED15.4 (DOUT), LED16.2 (DIN)
RGB（95 颗 SK6812MINI-E 数据链）/LED_DIN_17: LED16.4 (DOUT), LED17.2 (DIN)
RGB（95 颗 SK6812MINI-E 数据链）/LED_DIN_18: LED17.4 (DOUT), LED18.2 (DIN)
RGB（95 颗 SK6812MINI-E 数据链）/LED_DIN_19: LED18.4 (DOUT), LED19.2 (DIN)
RGB（95 颗 SK6812MINI-E 数据链）/LED_DIN_20: LED19.4 (DOUT), LED20.2 (DIN)
RGB（95 颗 SK6812MINI-E 数据链）/LED_DIN_21: LED20.4 (DOUT), LED21.2 (DIN)
RGB（95 颗 SK6812MINI-E 数据链）/LED_DIN_22: LED21.4 (DOUT), LED22.2 (DIN)
RGB（95 颗 SK6812MINI-E 数据链）/LED_DIN_23: LED22.4 (DOUT), LED23.2 (DIN)
RGB（95 颗 SK6812MINI-E 数据链）/LED_DIN_24: LED23.4 (DOUT), LED24.2 (DIN)
RGB（95 颗 SK6812MINI-E 数据链）/LED_DIN_25: LED24.4 (DOUT), LED25.2 (DIN)
RGB（95 颗 SK6812MINI-E 数据链）/LED_DIN_26: LED25.4 (DOUT), LED26.2 (DIN)
RGB（95 颗 SK6812MINI-E 数据链）/LED_DIN_27: LED26.4 (DOUT), LED27.2 (DIN)
RGB（95 颗 SK6812MINI-E 数据链）/LED_DIN_28: LED27.4 (DOUT), LED28.2 (DIN)
RGB（95 颗 SK6812MINI-E 数据链）/LED_DIN_29: LED28.4 (DOUT), LED29.2 (DIN)
RGB（95 颗 SK6812MINI-E 数据链）/LED_DIN_30: LED29.4 (DOUT), LED30.2 (DIN)
RGB（95 颗 SK6812MINI-E 数据链）/LED_DIN_31: LED30.4 (DOUT), LED31.2 (DIN)
RGB（95 颗 SK6812MINI-E 数据链）/LED_DIN_32: LED31.4 (DOUT), LED32.2 (DIN)
RGB（95 颗 SK6812MINI-E 数据链）/LED_DIN_33: LED32.4 (DOUT), LED33.2 (DIN)
RGB（95 颗 SK6812MINI-E 数据链）/LED_DIN_34: LED33.4 (DOUT), LED34.2 (DIN)
RGB（95 颗 SK6812MINI-E 数据链）/LED_DIN_35: LED34.4 (DOUT), LED35.2 (DIN)
RGB（95 颗 SK6812MINI-E 数据链）/LED_DIN_36: LED35.4 (DOUT), LED36.2 (DIN)
RGB（95 颗 SK6812MINI-E 数据链）/LED_DIN_37: LED36.4 (DOUT), LED37.2 (DIN)
RGB（95 颗 SK6812MINI-E 数据链）/LED_DIN_38: LED37.4 (DOUT), LED38.2 (DIN)
RGB（95 颗 SK6812MINI-E 数据链）/LED_DIN_39: LED38.4 (DOUT), LED39.2 (DIN)
RGB（95 颗 SK6812MINI-E 数据链）/LED_DIN_40: LED39.4 (DOUT), LED40.2 (DIN)
RGB（95 颗 SK6812MINI-E 数据链）/LED_DIN_41: LED40.4 (DOUT), LED41.2 (DIN)
RGB（95 颗 SK6812MINI-E 数据链）/LED_DIN_42: LED41.4 (DOUT), LED42.2 (DIN)
RGB（95 颗 SK6812MINI-E 数据链）/LED_DIN_43: LED42.4 (DOUT), LED43.2 (DIN)
RGB（95 颗 SK6812MINI-E 数据链）/LED_DIN_44: LED43.4 (DOUT), LED44.2 (DIN)
RGB（95 颗 SK6812MINI-E 数据链）/LED_DIN_45: LED44.4 (DOUT), LED45.2 (DIN)
RGB（95 颗 SK6812MINI-E 数据链）/LED_DIN_46: LED45.4 (DOUT), LED46.2 (DIN)
RGB（95 颗 SK6812MINI-E 数据链）/LED_DIN_47: LED46.4 (DOUT), LED47.2 (DIN)
RGB（95 颗 SK6812MINI-E 数据链）/LED_DIN_48: LED47.4 (DOUT), LED48.2 (DIN)
RGB（95 颗 SK6812MINI-E 数据链）/LED_DIN_49: LED48.4 (DOUT), LED49.2 (DIN)
RGB（95 颗 SK6812MINI-E 数据链）/LED_DIN_50: LED49.4 (DOUT), LED50.2 (DIN)
RGB（95 颗 SK6812MINI-E 数据链）/LED_DIN_51: LED50.4 (DOUT), LED51.2 (DIN)
RGB（95 颗 SK6812MINI-E 数据链）/LED_DIN_52: LED51.4 (DOUT), LED52.2 (DIN)
RGB（95 颗 SK6812MINI-E 数据链）/LED_DIN_53: LED52.4 (DOUT), LED53.2 (DIN)
RGB（95 颗 SK6812MINI-E 数据链）/LED_DIN_54: LED53.4 (DOUT), LED54.2 (DIN)
RGB（95 颗 SK6812MINI-E 数据链）/LED_DIN_55: LED54.4 (DOUT), LED55.2 (DIN)
RGB（95 颗 SK6812MINI-E 数据链）/LED_DIN_56: LED55.4 (DOUT), LED56.2 (DIN)
RGB（95 颗 SK6812MINI-E 数据链）/LED_DIN_57: LED56.4 (DOUT), LED57.2 (DIN)
RGB（95 颗 SK6812MINI-E 数据链）/LED_DIN_58: LED57.4 (DOUT), LED58.2 (DIN)
RGB（95 颗 SK6812MINI-E 数据链）/LED_DIN_59: LED58.4 (DOUT), LED59.2 (DIN)
RGB（95 颗 SK6812MINI-E 数据链）/LED_DIN_60: LED59.4 (DOUT), LED60.2 (DIN)
RGB（95 颗 SK6812MINI-E 数据链）/LED_DIN_61: LED60.4 (DOUT), LED61.2 (DIN)
RGB（95 颗 SK6812MINI-E 数据链）/LED_DIN_62: LED61.4 (DOUT), LED62.2 (DIN)
RGB（95 颗 SK6812MINI-E 数据链）/LED_DIN_63: LED62.4 (DOUT), LED63.2 (DIN)
RGB（95 颗 SK6812MINI-E 数据链）/LED_DIN_64: LED63.4 (DOUT), LED64.2 (DIN)
RGB（95 颗 SK6812MINI-E 数据链）/LED_DIN_65: LED64.4 (DOUT), LED65.2 (DIN)
RGB（95 颗 SK6812MINI-E 数据链）/LED_DIN_66: LED65.4 (DOUT), LED66.2 (DIN)
RGB（95 颗 SK6812MINI-E 数据链）/LED_DIN_67: LED66.4 (DOUT), LED67.2 (DIN)
RGB（95 颗 SK6812MINI-E 数据链）/LED_DIN_68: LED67.4 (DOUT), LED68.2 (DIN)
RGB（95 颗 SK6812MINI-E 数据链）/LED_DIN_69: LED68.4 (DOUT), LED69.2 (DIN)
RGB（95 颗 SK6812MINI-E 数据链）/LED_DIN_70: LED69.4 (DOUT), LED70.2 (DIN)
RGB（95 颗 SK6812MINI-E 数据链）/LED_DIN_71: LED70.4 (DOUT), LED71.2 (DIN)
RGB（95 颗 SK6812MINI-E 数据链）/LED_DIN_72: LED71.4 (DOUT), LED72.2 (DIN)
RGB（95 颗 SK6812MINI-E 数据链）/LED_DIN_73: LED72.4 (DOUT), LED73.2 (DIN)
RGB（95 颗 SK6812MINI-E 数据链）/LED_DIN_74: LED73.4 (DOUT), LED74.2 (DIN)
RGB（95 颗 SK6812MINI-E 数据链）/LED_DIN_75: LED74.4 (DOUT), LED75.2 (DIN)
RGB（95 颗 SK6812MINI-E 数据链）/LED_DIN_76: LED75.4 (DOUT), LED76.2 (DIN)
RGB（95 颗 SK6812MINI-E 数据链）/LED_DIN_77: LED76.4 (DOUT), LED77.2 (DIN)
RGB（95 颗 SK6812MINI-E 数据链）/LED_DIN_78: LED77.4 (DOUT), LED78.2 (DIN)
RGB（95 颗 SK6812MINI-E 数据链）/LED_DIN_79: LED78.4 (DOUT), LED79.2 (DIN)
RGB（95 颗 SK6812MINI-E 数据链）/LED_DIN_80: LED79.4 (DOUT), LED80.2 (DIN)
RGB（95 颗 SK6812MINI-E 数据链）/LED_DIN_81: LED80.4 (DOUT), LED81.2 (DIN)
RGB（95 颗 SK6812MINI-E 数据链）/LED_DIN_82: LED81.4 (DOUT), LED82.2 (DIN)
RGB（95 颗 SK6812MINI-E 数据链）/LED_DIN_83: LED82.4 (DOUT), LED83.2 (DIN)
RGB（95 颗 SK6812MINI-E 数据链）/LED_DIN_84: LED83.4 (DOUT), LED84.2 (DIN)
RGB（95 颗 SK6812MINI-E 数据链）/LED_DIN_85: LED84.4 (DOUT), LED85.2 (DIN)
RGB（95 颗 SK6812MINI-E 数据链）/LED_DIN_86: LED85.4 (DOUT), LED86.2 (DIN)
RGB（95 颗 SK6812MINI-E 数据链）/LED_DIN_87: LED86.4 (DOUT), LED87.2 (DIN)
RGB（95 颗 SK6812MINI-E 数据链）/LED_DIN_88: LED87.4 (DOUT), LED88.2 (DIN)
RGB（95 颗 SK6812MINI-E 数据链）/LED_DIN_89: LED88.4 (DOUT), LED89.2 (DIN)
RGB（95 颗 SK6812MINI-E 数据链）/LED_DIN_90: LED89.4 (DOUT), LED90.2 (DIN)
RGB（95 颗 SK6812MINI-E 数据链）/LED_DIN_91: LED90.4 (DOUT), LED91.2 (DIN)
RGB（95 颗 SK6812MINI-E 数据链）/LED_DIN_92: LED91.4 (DOUT), LED92.2 (DIN)
RGB（95 颗 SK6812MINI-E 数据链）/LED_DIN_93: LED92.4 (DOUT), LED93.2 (DIN)
RGB（95 颗 SK6812MINI-E 数据链）/LED_DIN_94: LED93.4 (DOUT), LED94.2 (DIN)
RGB（95 颗 SK6812MINI-E 数据链）/LED_DIN_95: LED94.4 (DOUT), LED95.2 (DIN)
VLED: LED1.3 (VDD), LED2.3 (VDD), LED3.3 (VDD), LED4.3 (VDD), LED5.3 (VDD), LED6.3 (VDD), LED7.3 (VDD), LED8.3 (VDD), LED9.3 (VDD), LED10.3 (VDD), LED11.3 (VDD), LED12.3 (VDD), LED13.3 (VDD), LED14.3 (VDD), LED15.3 (VDD), LED16.3 (VDD), LED17.3 (VDD), LED18.3 (VDD), LED19.3 (VDD), LED20.3 (VDD), LED21.3 (VDD), LED22.3 (VDD), LED23.3 (VDD), LED24.3 (VDD), LED25.3 (VDD), LED26.3 (VDD), LED27.3 (VDD), LED28.3 (VDD), LED29.3 (VDD), LED30.3 (VDD), LED31.3 (VDD), LED32.3 (VDD), LED33.3 (VDD), LED34.3 (VDD), LED35.3 (VDD), LED36.3 (VDD), LED37.3 (VDD), LED38.3 (VDD), LED39.3 (VDD), LED40.3 (VDD), LED41.3 (VDD), LED42.3 (VDD), LED43.3 (VDD), LED44.3 (VDD), LED45.3 (VDD), LED46.3 (VDD), LED47.3 (VDD), LED48.3 (VDD), LED49.3 (VDD), LED50.3 (VDD), LED51.3 (VDD), LED52.3 (VDD), LED53.3 (VDD), LED54.3 (VDD), LED55.3 (VDD), LED56.3 (VDD), LED57.3 (VDD), LED58.3 (VDD), LED59.3 (VDD), LED60.3 (VDD), LED61.3 (VDD), LED62.3 (VDD), LED63.3 (VDD), LED64.3 (VDD), LED65.3 (VDD), LED66.3 (VDD), LED67.3 (VDD), LED68.3 (VDD), LED69.3 (VDD), LED70.3 (VDD), LED71.3 (VDD), LED72.3 (VDD), LED73.3 (VDD), LED74.3 (VDD), LED75.3 (VDD), LED76.3 (VDD), LED77.3 (VDD), LED78.3 (VDD), LED79.3 (VDD), LED80.3 (VDD), LED81.3 (VDD), LED82.3 (VDD), LED83.3 (VDD), LED84.3 (VDD), LED85.3 (VDD), LED86.3 (VDD), LED87.3 (VDD), LED88.3 (VDD), LED89.3 (VDD), LED90.3 (VDD), LED91.3 (VDD), LED92.3 (VDD), LED93.3 (VDD), LED94.3 (VDD), LED95.3 (VDD); also elsewhere on the board

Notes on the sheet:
StarShield RGB 子图 —— 由 docs/_tools/gen_rgb_sch.py 自动生成，请勿手改；改电路请改 docs/_tools/rgb_design.py。依据：ADR-0007（电池直供不升压）、ADR-0005（门控拓扑 C）、ADR-0006（95 键）
【数据链】LED1.DIN = LED_DIN（来自控制子图 J3A 孔2 = nice!nano D1/P0.06，&spi3 MOSI）；LEDi.DOUT → LED(i+1).DIN 依次串联到 LED95；LED95.DOUT 悬空（链尾）。链序 = 键位 index 顺序（行优先、行内从左到右），与 ZMK 侧 LED index 一致
【供电】全部灯珠的 VDD 接 VLED —— 电源子图中由电池直供、经 Q1(AO3401A) PMOS 门控的 LED 轨（ADR-0007：不加 5V 升压；ADR-0005：拓扑 C，MCU 经 2N7002 反相级控制）。VLED 按 2-3 A 走线；固件侧 CONFIG_ZMK_RGB_UNDERGLOW_BRT_MAX=30 是电流护栏（30% 灰阶约 1.0 A）
【静态电流】实测 0.6 mA/颗 x 95 ≈ 57 mA ⇒ 必须物理切断：RGB 关闭 / 深度睡眠时 Q1 关断，LED 轨无电。门控极性 GPIO_ACTIVE_HIGH（经反相级后非反相）
【封装与贴装】LED_SMD:LED_SK6812MINI_PLCC4_3.5x3.5mm_P1.75mm（正装）。⚠️ UNVERIFIED：官方库另一个变体是 ReverseMount（3.2x2.8，灯珠在 PCB 背面、光穿 PCB 开孔），本项目按常规 per-key 做法选正装 —— 投板前（B3/B4）需用实物核对型号-封装对应与贴装方向
【图面说明】本图按「行内顺序」排列灯珠（列间距 25.4 / 行间距 38.1），不是真实物理坐标；PCB 布局（B4）按 sketch/keyboard-layout.json 的 KLE 坐标精确生成。每颗灯珠的 Value 是该键的键帽标签，与 docs/_generated/matrix.json 的 index 一一对应

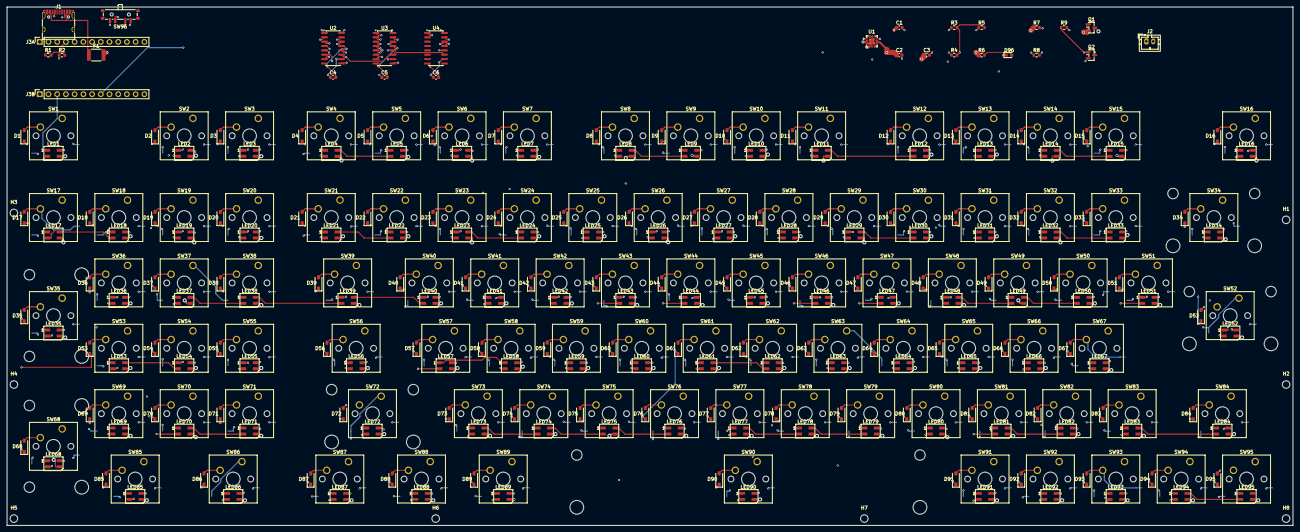
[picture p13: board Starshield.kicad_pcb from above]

Board: 4 copper layers, 374.7 x 151.1 mm, 321 parts (0 on the bottom side), 239 nets.

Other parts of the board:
H1, H2, H3, H4, H5, H6, H7, H8: M2; MountingHole_2.2mm_M2

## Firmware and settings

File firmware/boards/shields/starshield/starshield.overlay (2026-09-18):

/*
 * StarShield — 95 键无线机械键盘，ZMK shield 配置
 *
 * 目标板：nice!nano v2（nRF52840）
 * 矩阵：6 行 × 18 列，95 键，每个键一颗 1N4148W 二极管，col2row
 * 列驱动：3 颗 74HC595 级联（ZMK 官方 zmk,gpio-595 驱动）
 *   ⚠️ 2026-09-18 修订：原「2 颗」是电气错误 —— 2 颗只有 16 个输出位，驱动不了 18 列；
 *      ngpios=24 时驱动每轮移 24 个时钟，bit16/17 被推出链尾丢失 ⇒ COL16/17（小键盘区）失灵。
 *      位序依据 gpio_595.c：bit0..7 = 第 1 颗 QA..QH、bit8..15 = 第 2 颗、bit16..23 = 第 3 颗。
 * RGB：95 颗 SK6812MINI-E，数据链首颗数据线走 spi3（ZMK 官方做法）
 *
 * ⚠️ 引脚分配依据（见 docs/matrix-folding-analysis.md §4 与 docs/power-architecture.md）：
 *   - 官方要求：移位寄存器只能当【输出】，MCU【输入】脚必须直连
 *     （为保留按键唤醒中断）→ col2row 下【列走 595、行直连 MCU】
 *   - 官方要求：595 的 ngpios 只能取 8/16/24/32 → 18 列需 **3 颗**级联（24 位链、用前 18 位）
 *   - 595 与 WS2812 必须用【不同】SPI 外设（两者都是 SPI 从设备）
 *       595   → &spi1（MOSI P0.10 / SCK P1.13；**MISO 已在本 shield 覆盖掉** ——
 *               板级默认把 MISO 放在 P1.11 = D14，与 C1 的三档开关 MODE1 冲突，见下方 &pinctrl）
 *       WS2812 → &spi3（MOSI P0.06）
 *   - P0.13 是 nice!nano 的 VCC 门控脚（置高切断 VCC），官方就是这么省 LED 静态功耗的
 *   - 三档模式开关（C1）：D2(P0.17) / D14(P1.11) / D18(P1.15) = MODE0/MODE1/MODE2
 *
 * ⚠️ 本文件为设计稿：引脚分配已在 DTS 层面自洽，但【投板前必须用实物核对】
 *    （nice!nano 的排针 pitch/每边脚数未能从官方数字确认，仅有 Pro Micro 标准旁证）。
 */

#include <behaviors.dtsi>
#include <dt-bindings/led/led.h>
#include <dt-bindings/zmk/matrix_transform.h>
#include <dt-bindings/zmk/bt.h>
#include <dt-bindings/zmk/outputs.h>

/* 键位映射表（自动生成，内容为 &default_transform { columns/rows/map }） */
#include "starshield_transform.dtsi"

/ {
    chosen {
        zmk,kscan = &kscan0;
        zmk,underglow = &led_strip;
        /* ⚠️ ZMK 已迁移到 physical-layout 模型（官方 docs/hardware-integration/physical-layouts.md）：
           旧式 `zmk,matrix-transform = &default_transform` 不再使用，
           改为指向 physical_layout0（它聚合 kscan + transform + 按键物理位置）。
           physical_layout0 与 default_transform 定义在 starshield_transform.dtsi。 */
        zmk,physical-layout = &physical_layout0;
    };

    kscan0: kscan_0 {
        compatible = "zmk,kscan-gpio-matrix";
        label = "KSCAN";
        diode-direction = "col2row";

        /*
         * 6 个行：直连 MCU（输入，可触发中断）。
         * 用 &pro_micro N 引用 Pro Micro 排针号，而不是裸 gpio 控制器，
         * 这样换了板子（只要兼容 Pro Micro）不用改这里。
         */
        row-gpios
            = <&pro_micro 4  (GPIO_ACTIVE_HIGH | GPIO_PULL_DOWN)>   /* P0.22  D4/A6 */
            , <&pro_micro 5  (GPIO_ACTIVE_HIGH | GPIO_PULL_DOWN)>   /* P0.24  D5    */
            , <&pro_micro 6  (GPIO_ACTIVE_HIGH | GPIO_PULL_DOWN)>   /* P1.00  D6/A7 */
            , <&pro_micro 7  (GPIO_ACTIVE_HIGH | GPIO_PULL_DOWN)>   /* P0.11  D7    */
            , <&pro_micro 9  (GPIO_ACTIVE_HIGH | GPIO_PULL_DOWN)>   /* P1.06  D9/A9 */
            , <&pro_micro 8  (GPIO_ACTIVE_HIGH | GPIO_PULL_DOWN)>   /* P1.04  D8/A8 */
            ;

        /*
         * 18 个列：全部由 3 颗级联的 74HC595 驱动（MCU 输出）。
         * ngpios = 24 → 引脚号 0..17 有效，其中 0..7 在第 1 颗、8..15 在第 2 颗、
         * 16..17 在第 3 颗的 QA/QB（第 3 颗其余输出空闲）。
         */
        col-gpios
            = <&shifter  0 GPIO_ACTIVE_HIGH>
            , <&shifter  1 GPIO_ACTIVE_HIGH>
            , <&shifter  2 GPIO_ACTIVE_HIGH>
            , <&shifter  3 GPIO_ACTIVE_HIGH>
            , <&shifter  4 GPIO_ACTIVE_HIGH>
            , <&shifter  5 GPIO_ACTIVE_HIGH>
            , <&shifter  6 GPIO_ACTIVE_HIGH>
            , <&shifter  7 GPIO_ACTIVE_HIGH>
            , <&shifter  8 GPIO_ACTIVE_HIGH>
            , <&shifter  9 GPIO_ACTIVE_HIGH>
            , <&shifter 10 GPIO_ACTIVE_HIGH>
            , <&shifter 11 GPIO_ACTIVE_HIGH>
            , <&shifter 12 GPIO_ACTIVE_HIGH>
            , <&shifter 13 GPIO_ACTIVE_HIGH>
            , <&shifter 14 GPIO_ACTIVE_HIGH>
            , <&shifter 15 GPIO_ACTIVE_HIGH>
            , <&shifter 16 GPIO_ACTIVE_HIGH>
            , <&shifter 17 GPIO_ACTIVE_HIGH>
            ;
    };

    /*
     * RGB 电源门控（ZMK ext-power）。
     *
     * ⚠️ 节点名必须是 EXT_POWER，否则用户已保存的设置会丢失（ZMK 官方文档明确要求）。
     *
     * nice!nano v2 官方用 P0.13 控制 VCC 通断，极性为 GPIO_ACTIVE_HIGH：
     *   active（高）= 打开外设电源；inactive（低）= 切断
     *
     * ⚠️ 本项目的 LED 由电池直供（ADR-0007），因此【不是】直接拿 P0.13 去开关 VCC，
     *    而是用 P0.13 驱动 §5.4 的 NMOS 反相级（2N7002 + AO3401A）。
     *    反相级之后逻辑非反相，所以这里仍然是 GPIO_ACTIVE_HIGH。
     *    （若改用直接驱动 PMOS 且带栅源上拉的拓扑，则应改为 GPIO_ACTIVE_LOW。）
     */
    EXT_POWER {
        compatible = "zmk,ext-power-generic";
        control-gpios = <&pro_micro 10 GPIO_ACTIVE_HIGH>;   /* P0.09 → 反相级 → LED 轨 */
        init-delay-ms = <50>;
    };

    /*
     * 三档模式开关（C1，ADR-0009）—— SP3T C&K PCM13（原理图位号 SW96，B4 由 SW1 改名）。
     * 原理图连接（control.kicad_sch）：公共端(3) → GND；档 0/1/4 → MODE0/MODE1/MODE2。
     *   档 0（有线）  = MODE0 = D2  (P0.17)
     *   档 1（蓝牙）  = MODE1 = D14 (P1.11)
     *   档 2（2.4G）  = MODE2 = D18 (P1.15)
     *
     * 🔴 **物理档位顺序（用户 2026-09-19 定，外壳侧壁开口、与 USB-C 同一面）**：
     *   拨片**从左往右** = **2.4G / 蓝牙 / 有线**。
     *   依据：C&K PCM 手册 SP3T 连接表 `1-3 / 2-3 / 3-4` ⇒ pin3=公共端，
     *   **POS1→pin1、POS2→pin2、POS3→pin4**；PCB 上 SW96 取 **rot=180**（柄朝后壁）
     *   会把 X 镜像 ⇒ 板坐标自左向右 = POS3/POS2/POS1 = pin4/pin2/pin1
     *   = MODE2/MODE1/MODE0 = **2.4G / 蓝牙 / 有线** ✓
     *   ⚠️ **改 SW96 的 rot 或改这三条接线都会反转顺序** —— 改之前先回看这一段的推算。
     *
     * ⚠️ DT 里【不要】写 pull 标志：驱动按 GPIO_ACTIVE_LOW 自行推导 PULL_UP
     *    （kscan_gpio_direct.c 的 kscan_gpio_get_extra_flags()；ADR-0009 已核对源码；
     *      出货产品 Altar I 写了 PULL_UP 属「冗余但无害」，本项目按官方文档不写）。
     * ⚠️ wakeup-source：拨动开关本身即可把 MCU 从深度睡眠唤醒（Altar I 同款做法）。
     *
     * ⚠️ 若 C7（ESB 端点验证）通过，「2.4G」档改由 zmk-esb-endpoint 的最后 BLE profile
     *    承载 —— 档位读取方式不变，只需换 col2 的绑定。
     */
    kscan_sp3t_toggle: kscan_sp3t_toggle {
        compatible = "zmk,kscan-gpio-direct";
        toggle-mode;
        wakeup-source;

        /* ⚠️ 这里的顺序 = 原理图 MODE0/MODE1/MODE2 的**引脚号顺序**，
           不是外壳上「从左往右」的视觉顺序。
           视觉顺序（左→右 = 2.4G / 蓝牙 / 有线）由 SW96 的 rot=180 决定，
           推算见本文件顶部的「物理档位顺序」注释。 */
        input-gpios
            = <&pro_micro 2  GPIO_ACTIVE_LOW>   /* 档 0：有线  = MODE0 = D2  (P0.17) */
            , <&pro_micro 14 GPIO_ACTIVE_LOW>   /* 档 1：蓝牙  = MODE1 = D14 (P1.11) */
            , <&pro_micro 18 GPIO_ACTIVE_LOW>   /* 档 2：2.4G  = MODE2 = D18 (P1.15) */
            ;
    };

    /*
     * 档位 → 行为映射（sideband 写法，与 keymap 解耦：用户改键 / Studio 改键都不会破坏它）。
     * 照抄上游 zmk_uno.overlay 的参考实现（ADR-0009 已逐行核对 v0.3.0）。
     */
    macros {
        mode_ble_host: mode_ble_host {
            /* 蓝牙档：切到 BLE 输出 + 配对位 0（直连主机） */
            bindings = <&out OUT_BLE &bt BT_SEL 0>;
        };

        mode_dongle: mode_dongle {
            /* 2.4G 档：切到 BLE 输出 + 配对位 1（Dongle 是 BLE HID 主机，ADR-0001） */
            bindings = <&out OUT_BLE &bt BT_SEL 1>;
        };
    };

    endpoint_sideband_behaviors {
        compatible = "zmk,kscan-sideband-behaviors";
        auto-enable;
        wakeup-source;
        kscan = <&kscan_sp3t_toggle>;

        mode_col0: mode_col0 {
            column = <0>;
            bindings = <&out OUT_USB>;          /* 有线 */
        };

        mode_col1: mode_col1 {
            column = <1>;
            bindings = <&mode_ble_host>;        /* 蓝牙 */
        };
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

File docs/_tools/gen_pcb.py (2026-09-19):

#!/usr/bin/env python3
# -*- coding: utf-8 -*-
"""gen_pcb.py —— B4：由 pcb_design.py + 原理图生成 `Starshield.kicad_pcb` 与定位板

链路（改布局只改上游，不要手工改产物）：
    sketch/keyboard-layout.json ─▶ docs/_generated/matrix.json ┐
    docs/_tools/pcb_design.py  （坐标规则 / 控制肩摆放）        ├─▶ 本生成器 ─▶ Starshield.kicad_pcb
    6 张子图 .kicad_sch        （位号 / 封装 / 值 / 网表）      ┘              Starshield-plate.kicad_pcb

⚠️ 产物是「已摆位、已带网、未布线」的初始板。布线在 KiCad 里人工/交互完成；
   **布线后再跑本脚本会覆盖手动成果** —— 之后只跑 verify_pcb.py。
   文件头会写入这条警告。

为什么不用 pcbnew 脚本：KiCad Python 每次生成的 uuid/tstamp 都不同，
破坏本项目「重跑生成器 ⇒ git status 零差异」的确定性判据。
⇒ 本生成器自己拼 s-expression，uuid 由 md5(位号/路径) 派生 ⇒ 可复现。
"""
import hashlib
import os
import re
import subprocess
import sys

try:
    sys.stdout.reconfigure(encoding="utf-8", errors="replace")
    sys.stderr.reconfigure(encoding="utf-8", errors="replace")
except Exception:
    pass

import pcb_design as D

HERE = os.path.dirname(os.path.abspath(__file__))
ROOT = os.path.dirname(os.path.dirname(HERE))
PCB = os.path.join(ROOT, "hardware", "pcb", "StarShield")
TMP = os.path.join(PCB, "_tmp")
MATRIX = os.path.join(ROOT, "docs", "_generated", "matrix.json")

SHEETS = [
    "matrix/matrix_r012.kicad_sch",
    "matrix/matrix_r234.kicad_sch",
    "matrix/matrix_r45.kicad_sch",
    "power/power.kicad_sch",
    "control/control.kicad_sch",
    "rgb/rgb.kicad_sch",
]
ROOT_SHEET = "Starshield.kicad_sch"


# --------------------------------------------------------------------------
# 环境
# --------------------------------------------------------------------------
def find_kicad_cli():
    env = os.environ.get("KICAD_CLI")
    if env and os.path.exists(env):
        return env
    from shutil import which
    found = which("kicad-cli") or which("kicad-cli.exe")
    if found:
        return found
    import glob
    cands = []
    for drive in "CDEFGH":
        cands += glob.glob(rf"{drive}:\KiCad\bin\kicad-cli.exe")
        cands += glob.glob(rf"{drive}:\Kicad\bin\kicad-cli.exe")
        cands += glob.glob(rf"{drive}:\Program Files\KiCad\*\bin\kicad-cli.exe")
    for c in cands:
        if os.path.exists(c):
            return c
    return None


def fp_dirs():
    """先工程自带库（自画封装），再官方库。"""
    import glob
    out = [os.path.join(PCB, "footprints")]
    for drive in "CDEFGH":
        for p in glob.glob(rf"{drive}:\Kicad\share\kicad\footprints") + \
                 glob.glob(rf"{drive}:\KiCad\share\kicad\footprints") + \
                 glob.glob(rf"{drive}:\Program Files\KiCad\*\share\kicad\footprints"):
            if os.path.isdir(p):
                out.append(p)
    return out


_DIRS = fp_dirs()


def find_fp(lib, name):
    for d in _DIRS:
        p = os.path.join(d, f"{lib}.pretty", f"{name}.kicad_mod")
        if os.path.exists(p):
            return p
    return None


def uuid_for(*parts):
    h = hashlib.md5("|".join(parts).encode("utf-8")).hexdigest()
    return f"{h[0:8]}-{h[8:12]}-{h[12:16]}-{h[16:20]}-{h[20:32]}"


def num(v):
    return f"{v:.6f}".rstrip("0").rstrip(".")


# --------------------------------------------------------------------------
# 读原理图（位号 / 封装 / 值）
# --------------------------------------------------------------------------
def collect_comps():
    out = {}
    for rel in SHEETS:
        path = os.path.join(PCB, rel)
        txt = open(path, encoding="utf-8").read()
        for blk in txt.split("\t(symbol (lib_id ")[1:]:
            m_ref = re.search(r'\(property "Reference" "([^"]+)"', blk)
            m_fp = re.search(r'\(property "Footprint" "([^"]+)"', blk)
            # ⚠️ 值可能含转义引号（键帽标签 `"` 在原理图里写作 `\"`）—— 必须按
            #    「非引号或非转义反斜杠」解析，否则会把 `\"` 截断成 `\`，
            #    写回时变成未闭合字符串，KiCad 报「未闭合的分隔字符串」（实测）。
            m_val = re.search(r'\(property "Value" "((?:[^"\\]|\\.)*)"', blk)
            if not (m_ref and m_fp and m_fp.group(1)):
                continue
            out[m_ref.group(1)] = dict(
                fp=m_fp.group(1),
                value=m_val.group(1) if m_val else "",
                sheet=rel.split("/")[0])
    return out


def export_netlist(cli):
    os.makedirs(TMP, exist_ok=True)
    out = os.path.join(TMP, "nl_root.net")
    r = subprocess.run([cli, "sch", "export", "netlist", "--format", "kicadsexpr",
                        "-o", out, os.path.join(PCB, ROOT_SHEET)],
                       capture_output=True, text=True, encoding="utf-8", errors="replace")
    if r.returncode != 0:
        print("❌ 网表导出失败")
        print((r.stderr or "")[-600:])
        sys.exit(1)
    txt = open(out, encoding="utf-8").read()
    nets = {}
    for chunk in txt.split("(net")[1:]:
        nm = re.search(r'\(name\s+"([^"]+)"', chunk)
        if not nm:
            continue
        name = nm.group(1).lstrip("/")
        nodes = set(re.findall(r'\(ref\s+"([^"]+)"\)\s*\(pin\s+"([^"]+)"\)', chunk))
        nets.setdefault(name, set()).update(nodes)
    return nets


# --------------------------------------------------------------------------
# 摆位
# --------------------------------------------------------------------------
def placements(comps, matrix):
    """返回 {ref: (x, y, rot)}。键区由 matrix.json 派生，控制区查 CONTROL 表。"""
    keys = {e["index"]: e for e in matrix["matrix"]}
    place = {}
    for ref in comps:
        m = re.fullmatch(r"SW(\d+)", ref)
        if m and int(m.group(1)) <= 95:
            e = keys[int(m.group(1))]
            x, y = D.switch_origin(e)
            place[ref] = (x, y, 0.0)
            continue
        m = re.fullmatch(r"D(\d+)", ref)
        if m and int(m.group(1)) <= 95:
            e = keys[int(m.group(1))]
            cx, cy = D.key_center(e)
            place[ref] = (cx + D.DIODE_DX, cy + D.DIODE_DY, D.DIODE_ROT)
            continue
        m = re.fullmatch(r"LED(\d+)", ref)
        if m:
            e = keys[int(m.group(1))]
            cx, cy = D.key_center(e)
            place[ref] = (cx + D.LED_DX, cy + D.LED_DY, D.LED_ROT)
            continue
        if ref in D.CONTROL:
            place[ref] = D.CONTROL[ref]
        else:
            raise SystemExit(f"❌ 位号 {ref} 既不在键区也不在 CONTROL 表 —— "
                             f"新增元件请先在 pcb_design.py 登记")
    return place


# --------------------------------------------------------------------------
# 封装实例化（把 .kicad_mod 内联进板文件）
# --------------------------------------------------------------------------
def _pad_blocks(text):
    """生成器：产出 (start, end) 覆盖 `(pad ...)` 块（按括号配平）。

    ⚠️ 必须跳过**字符串里的括号**：键帽标签含 `(`（如 `(/9`），朴素计数会算错
    边界（verify_pcb 一侧实测因此丢掉 SW31 / LED31）。
    """
    i = 0
    n = len(text)
    while True:
        j = text.find("(pad", i)
        if j < 0:
            return
        k = j
        depth = 0
        inq = False
        esc = False
        while k < n:
            ch = text[k]
            if inq:
                if esc:
                    esc = False
                elif ch == "\\":
                    esc = True
                elif ch == '"':
                    inq = False
            else:
                if ch == '"':
                    inq = True
                elif ch == "(":
                    depth += 1
                elif ch == ")":
                    depth -= 1
                    if depth == 0:
                        break
            k += 1
        yield j, k + 1
        i = k + 1


def instantiate(fp_id, ref, value, x, y, rot, netmap):
    lib, name = fp_id.split(":", 1)
    path = find_fp(lib, name)
    if not path:
        raise SystemExit(f"❌ 封装不存在：{fp_id}")
    raw = open(path, encoding="utf-8").read()

    # 去掉外层 (footprint "..." 首行、内层 (layer "...") 行、末尾 )
    head_end = raw.index("\n") + 1
    body = raw[head_end:raw.rindex(")")]
    body = re.sub(r"\n[ \t]*\(layer \"[^\"]*\"\)", "", body, count=1)
    body = "\n".join(("\t" + ln) if ln.strip() else ln for ln in body.split("\n"))

    txt = (f'\t(footprint "{fp_id}"\n'
           f'\t\t(layer "F.Cu")\n'
           f'\t\t(uuid "{uuid_for("fp", ref)}")\n'
           f'\t\t(at {num(x)} {num(y)} {num(rot)})\n'
           f'{body}\n\t)\n')

    txt = txt.replace('(property "Reference" "REF**"', f'(property "Reference" "{ref}"')
    # ⚠️ 值**原样透传**，不做额外转义：原理图里的 Value 已经是 KiCad 的转义形式
    #    （键帽标签 `"` 写作 `\"`、`\` 写作 `\\`，实测两种 KiCad 都认）。
    #    再转一次就会变成 `\\"` 之类的二重转义；且 re.sub 的替换串本身也会
    #    处理反斜杠 ⇒ 必须用 lambda，不能把值直接放进替换模板（实测踩过）。
    txt = re.sub(r'\(property "Value" "(?:[^"\\]|\\.)*"',
                 lambda _m: f'(property "Value" "{value}"', txt, count=1)

    # pad 挂网
    ins = []
    for a, b in _pad_blocks(txt):
        blk = txt[a:b]
        m = re.match(r'\(pad\s+"([^"]*)"', blk)
        if not m:
            continue
        padnum = m.group(1)
        net = netmap.get((ref, padnum))
        if net is None:
            continue
        m_uuid = re.search(r'\(uuid\s+"[^"]+"\)', blk)
        if m_uuid:
            p = a + m_uuid.end()
        else:
            p = b - 1
        ins.append((p, f' (net {net[0]} "{net[1]}")'))
    for p, s in reversed(ins):
        txt = txt[:p] + s + txt[p:]
    return txt


def hole_instance(ref, x, y):
    return instantiate(D.HOLE_FP, ref, "M2", x, y, 0.0, {})


# --------------------------------------------------------------------------
# 板文件骨架
# --------------------------------------------------------------------------
LAYERS = """	(layers
		(0 "F.Cu" signal)
		(4 "In1.Cu" signal)
		(6 "In2.Cu" signal)
		(2 "B.Cu" signal)
		(9 "F.Adhes" user "F.Adhesive")
		(11 "B.Adhes" user "B.Adhesive")
		(13 "F.Paste" user)
		(15 "B.Paste" user)
		(5 "F.SilkS" user)
		(7 "B.SilkS" user)
		(1 "F.Mask" user)
		(3 "B.Mask" user)
		(17 "Dwgs.User" user "User.Drawings")
		(19 "Cmts.User" user "User.Comments")
		(21 "Eco1.User" user "User.Eco1")
		(23 "Eco2.User" user "User.Eco2")
		(25 "Edge.Cuts" user)
		(27 "Margin" user)
		(31 "F.CrtYd" user "F.Courtyard")
		(29 "B.CrtYd" user "B.Courtyard")
		(35 "F.Fab" user)
		(33 "B.Fab" user)
	)"""

# 层叠（2026-09-20 补）：**必须写出来**，否则铜厚只存在于厂家默认值里，
# DRC 的载流相关检查与「内层到底多厚」都无从谈起（见 research/power-trace-width-precedent.md）。
# 参数来源（都是一手样例，不是猜的）：
#   - 结构与写法照抄社区 4 层板 `ScottoModules`（内层 1 oz）与 `Conejo`（JLC 默认内层 0.0152）；
#     两者都实际投过板。
#   - 本板**声明内层 1 oz（0.035）** —— 灯轨峰值 2.4 A 需要它
#     （0.5 oz 内层下 2.4 A 需 3.43 mm 走线，不现实；1 oz 下 1.5 mm 即可 ≈2.24 A）。
#   - ⚠️ 语法（官方文档 file-formats/sexpr-pcb）：**`(stackup)` 必须放在 `(setup)` 段内部**，
#     不能放板级 —— 板级写法是 KiCad 5 的旧格式，KiCad 10 会直接报「未知标记 stackup」并拒绝加载。
#     （社区样本 Conejo / ScottoModules 是老版本文件，不能照抄它们的位置。）
#   - ⚠️ 下单时必须向厂家**明确指定内层 1 oz**；若厂家只给默认的 0.5 oz，
#     加宽后的 1.5 mm 走线仍可覆盖固件护栏电流 1.0 A（0.5 oz 下 ≈1.35 A @ΔT20），但覆盖不了峰值。
STACKUP = """	(stackup
		(layer "F.SilkS" (type "Top Silk Screen"))
		(layer "F.Paste" (type "Top Solder Paste"))
		(layer "F.Mask" (type "Top Solder Mask") (thickness 0.01))
		(layer "F.Cu" (type "copper") (thickness 0.035))
		(layer "dielectric 1" (type "prepreg") (thickness 0.1) (material "FR4") (epsilon_r 4.5) (loss_tangent 0.02))
		(layer "In1.Cu" (type "copper") (thickness 0.0152))
		(layer "dielectric 2" (type "core") (thickness 1.24) (material "FR4") (epsilon_r 4.5) (loss_tangent 0.02))
		(layer "In2.Cu" (type "copper") (thickness 0.0152))
		(layer "dielectric 3" (type "prepreg") (thickness 0.1) (material "FR4") (epsilon_r 4.5) (loss_tangent 0.02))
		(layer "B.Cu" (type "copper") (thickness 0.035))
		(layer "B.Mask" (type "Bottom Solder Mask") (thickness 0.01))
		(layer "B.Paste" (type "Bottom Solder Paste"))
		(layer "B.SilkS" (type "Bottom Silk Screen"))
		(copper_finish "None")
		(dielectric_constraints no)
	)"""
# ⚠️ **4 层板（2026-09-19 用户定）**：
#    - 层号与顺序**照抄 KiCad 自己写出来的形式**（不是按惯例猜）：`B.Cu` 的 id 是 **2**、不是 31；
#      `In1.Cu`=4、`In2.Cu`=6。KiCad 也会把 F.SilkS/B.SilkS 的别名串去掉 —— 一并照抄。
#    - **不要用 MCP `add_layer` 加层**：层数属设计数据，必须由生成器产出，
#      否则下一次 `gen_pcb.py` 会把内层覆盖掉（本轮实测踩过）。
#    - 叠层规划：**In1.Cu = GND 平面、In2.Cu = VLED 平面**，两个外层放信号；
#      VLED 的 2.4 A 靠 In2 平面承载（见 handoff §9 B4）。


def header(title, w, h, note):
    return f"""(kicad_pcb
	(version 20260206)
	(generator "gen_pcb.py")
	(generator_version "1.0")
	(general
		(thickness 1.6)
		(legacy_teardrops no)
	)
	(paper "A4")
	(title_block
		(title "{title}")
		(comment 1 "{note}")
	)
{LAYERS}
	(setup
{STACKUP}
		(pad_to_mask_clearance 0)
		(allow_soldermask_bridges_in_footprints no)
		(tenting front back)
		(aux_axis_origin 0 0)
		(grid_origin 0 0)
		(pcbplotparams
			(layerselection 0x00000000_00000000_00000000_000000a5)
			(usegerberextensions no)
			(usegerberattributes yes)
			(svgprecision 6)
			(plotframeref no)
			(mode 1)
			(useauxorigin no)
		)
	)
"""


def net_class_block(cls_names, all_nets):
    # ⚠️ 语法实测（KiCad 10.0.6，用 kicad-cli pcb drc 逐个变体试出来的）：
    #    ① net_class 是**板级**条目，放 (setup) 里会报「意外 net_class」；
    #    ② 名字后**必须跟一个描述字符串**，否则报「应为 'symbol'」；
    #    ③ 字段名是 via_dia / via_drill / uvia_dia / uvia_drill（**不是**
    #       via_diameter）—— 写错时会明确列出可用字段，本注释即据此修正；
    #    ④ 归属用 (add_net "...") —— 本版本支持，故 VLED 的加宽是**文件内生效**的。
    desc = {
        "Default": "默认类（信号 / 矩阵行列 / LED 数据链）",
        "Power": "电源轨 OUT / VBUS / VCHG_IN / VBAT（≤1.5 A）",
        "VLED": "RGB 灯珠供电：峰值 2.4 A（ADR-0007 电池直供）⇒ 必须宽走线或铺铜",
    }
    special = set(D.POWER_NETS) | {"VLED"}
    out = []
    for name in cls_names:
        c = D.NET_CLASSES[name]
        if name == "VLED":
            members = ["VLED"]
        elif name == "Power":
            members = sorted(D.POWER_NETS)
        else:
            members = [n for n in all_nets if n not in special]
        add = "".join(f'\n\t\t(add_net "{n}")' for n in members)
        out.append(
            f'	(net_class "{name}" "{desc.get(name, name)}"\n'
            f'		(clearance {c["clearance"]})\n'
            f'		(trace_width {c["trace_width"]})\n'
            f'		(via_dia {c["via_diameter"]})\n'
            f'		(via_drill {c["via_drill"]})\n'
            f'		(uvia_dia 0.3)\n'
            f'		(uvia_drill 0.1)\n'
            f'{add}\n'
            f'	)')
    return "\n".join(out) + "\n"


def outline(x0, y0, w, h):
    pts = [(x0, y0), (x0 + w, y0), (x0 + w, y0 + h), (x0, y0 + h), (x0, y0)]
    s = []
    for i in range(4):
        a, b = pts[i], pts[i + 1]
        s.append(f"	(gr_line (start {num(a[0])} {num(a[1])}) (end {num(b[0])} {num(b[1])})"
                 f' (stroke (width 0.1) (type solid)) (layer "Edge.Cuts")'
                 f' (uuid "{uuid_for("edge", str(i), num(a[0]), num(a[1]))}"))')
    return "\n".join(s) + "\n"


def plate_cutout(ref, x, y, size):
    u1 = uuid_for("platecut", ref)
    u2 = uuid_for("platecutpad", ref)
    return (f'	(footprint "StarShield:Plate_Cutout_MX_{num(size)}mm"\n'
            f'		(layer "F.Cu")\n'
            f'		(uuid "{u1}")\n'
            f'		(at {num(x)} {num(y)} 0)\n'
            f'		(property "Reference" "{ref}"\n'
            f'			(at 0 0 0)\n'
            f'			(layer "F.SilkS")\n'
            f'			(hide yes)\n'
            f'			(uuid "{uuid_for("platecutref", ref)}")\n'
            f'			(effects (font (size 1 1) (thickness 0.15)))\n'
            f'		)\n'
            f'		(pad "" np_thru_hole rect\n'
            f'			(at 0 0 0)\n'
            f'			(size {num(size)} {num(size)})\n'
            f'			(drill {num(size)} {num(size)})\n'
            f'			(layers "*.Cu" "*.Mask")\n'
            f'			(uuid "{u2}")\n'
            f'		)\n'
            f'	)\n')


# --------------------------------------------------------------------------
def main():
    cli = find_kicad_cli()
    if not cli:
        print("❌ 找不到 kicad-cli")
        return 2
    matrix = D.load_matrix(ROOT)
    comps = collect_comps()
    nets = export_netlist(cli)

    # 网编号：0 = 未连接，其余按名字排序稳定编号
    names = sorted(n for n in nets if n and not n.startswith("unconnected"))
    net_no = {n: i + 1 for i, n in enumerate(names)}
    netmap = {}
    for n, nodes in nets.items():
        if n.startswith("unconnected"):
            continue
        for ref, pin in nodes:
            netmap[(ref, pin)] = (net_no[n], n)

    place = placements(comps, matrix)

    parts = [header("StarShield 95-key wireless",
                    D.BOARD_W, D.BOARD_H,
                    "由 docs/_tools/gen_pcb.py 生成 —— 布线后请勿重跑（会覆盖手动成果）"),
             net_class_block(["Default", "Power", "VLED"], names),
             '	(net 0 "")\n']
    for n in names:
        parts.append(f'	(net {net_no[n]} "{n}")\n')

    parts.append(outline(0, 0, D.BOARD_W, D.BOARD_H))
    for ref in sorted(comps, key=lambda r: (len(r), r)):
        x, y, rot = place[ref]
        parts.append(instantiate(comps[ref]["fp"], ref, comps[ref]["value"], x, y, rot, netmap))
    for ref, x, y in D.HOLES:
        parts.append(hole_instance(ref, x, y))
    parts.append("	(embedded_fonts no)\n)\n")

    dst = os.path.join(PCB, "Starshield.kicad_pcb")
    open(dst, "w", encoding="utf-8", newline="\n").write("".join(parts))

    # ---- 定位板（G6）-------------------------------------------------------
    keys = {e["index"]: e for e in matrix["matrix"]}
    pl = [header("StarShield plate",
                 D.PLATE_W, D.PLATE_H,
                 "定位板：与 PCB 同源生成，开孔 14x14 mm；PCB-mount 卫星轴 ⇒ 无需卫星轴开孔"),
          net_class_block(["Default"], []),
          outline(D.PLATE_X0, D.PLATE_Y0, D.PLATE_W, D.PLATE_H)]
    for i in sorted(keys):
        cx, cy = D.key_center(keys[i])
        pl.append(plate_cutout(f"P{i}", cx, cy, D.PLATE_CUTOUT))
    for ref, x, y in D.HOLES:
        pl.append(hole_instance(ref, x, y))
    pl.append("	(embedded_fonts no)\n)\n")
    pdst = os.path.join(PCB, "Starshield-plate.kicad_pcb")
    open(pdst, "w", encoding="utf-8", newline="\n").write("".join(pl))

    import shutil
    shutil.rmtree(TMP, ignore_errors=True)

    print(f"  {os.path.relpath(dst, ROOT)}        {os.path.getsize(dst)} 字节")
    print(f"  {os.path.relpath(pdst, ROOT)}  {os.path.getsize(pdst)} 字节")
    print(f"  元件 {len(comps)} 个 + 安装孔 {len(D.HOLES)} 个 + 网 {len(names)} 条")
    print(f"  板框 {num(D.BOARD_W)} × {num(D.BOARD_H)} mm（键区 {num(D.KEY_W)} × {num(D.KEY_H)}"
          f"，顶部控制肩 {num(D.SHELF_H)} mm）")
    return 0


if __name__ == "__main__":
    sys.exit(main())

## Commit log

2026-09-15 StarShield — 开源 95 键无线机械键盘（设计阶段基线）
    一个全自定义、面向新手教程的无线机械键盘：95 键紧凑全尺寸单体，
    经 BLE Dongle 连接主机；硬件设计、固件与教程全部开放。
    许可：CERN-OHL-S-2.0。
    本提交为公开发布基线（仓库重建），内容快照说明：
    已核实并落盘的部分
    - 键位几何：95 键、19.50u × 6.25u（371.5 × 119.1 mm），空格 6.25u
    - 矩阵：6 行 × 18 列（18 列为数学下界），95 只二极管，网表校验 10 项全通过、ERC 0 error
    - 引脚方案：6 行直连 MCU + 2×74HC595 驱动 18 列（ZMK 官方内置 gpio-595 驱动，零自写代码）
    - 固件：ZMK v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
    [Starshield.kicad_sch, TEST1.kicad_pcb, TEST1.kicad_sch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]
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2026-09-15 docs(adr): 三档模式开关 + P7 断电方案，并修订 ADR-0001/0005
    新增 ADR-0009（三档拨片开关，提议）
    用一个 SP3T 拨片切 2.4G（Dongle）/ 蓝牙 / 有线。核心发现：这**不需要自定义固件**，
    是 ZMK 上游原生且文档化的机制：
    - zmk,kscan-gpio-direct 的 toggle-mode
    - zmk,kscan-sideband-behaviors（与 keymap 解耦）
    - 上游自带参考实现 app/boards/shields/zmk_uno（v0.3.0 已核对）
    - 需求由 ZMK 创始人 Pete Johanson 提出（issue #980），PR #1305 实现
    - 量产商品 Kinesis mWave（$119.95）在用同一套机制
    前置约束：开关能选「输出/配对位」，选不了「central/periphera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
2026-09-15 chore: 加提交闸门 check_repo_tree.py —— 防止第三方文件再次误入公开仓库
    ## 事故（真实发生，已修复）
    上一条提交 `2f63482` 用 `git add -A` 时，把调研代理落在**仓库根目录**的产物一起提交并
    推送到了**公开**仓库：
    sanmo61/ 第三方三模键盘工程，257 个文件（WCH CH582M）
    sanmo61.zip 10,052,668 字节
    api.ps1 / mine.ps1 / mine2.ps1 / osh_ch582m.html
    跟踪文件从 74 涨到 336，相当于在公开仓库里分发无许可证的第三方工程 ——
    与当初重建仓库要解决的问题同类。
    **已修复**：`git rm -r --cached` 剔出 + `git commit --amend` 改写该提交 +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
    [check_repo_tree.py]
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2026-09-15 docs(adr): 补入 Dongle 的延迟机制、实现陷阱与验证路径
    在更正后的 ADR-0001 里补入三项新核实的内容。
    1. 低延迟机制（数字均为计算值，非实测）
    ZMK Dongle 官方文档：只多 "about 1ms from the extra USB hop"，
    同时把一条 BLE 跳换成 USB 跳，其余部分平均延迟下降 6.5ms
    ZMK 维护者 Nicell（issue #1265）：Dongle 模式平均约 4.25ms
    （0.5ms USB@1000Hz + 3.75ms BLE@7.5ms）
    roba 的做法更硬：main.c 里 BT_LE_CONN_PARAM_INIT(6,6,0,400) 钉 7.5ms/latency0，
    且 roba_le_param_req() 直接拒绝键盘的变慢请求。
    作者指出键盘自己请求的是 15ms/latency 30
    ⇒ Dongle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
2026-09-15 docs(adr): 三份调研收口 —— 修正延迟主张、补开关选型、更正设计指南归属
    ## 1. 修正「Dongle 更快」的强形式（我此前写得过于肯定）
    对的部分：蓝牙规范把连接间隔决定权给 Central；ZMK 自己的 Dongle 链路钉在 7.5ms。
    错的部分（强形式）：**ZMK 在每一个原版构建里本来就在向主机请求 7.5–15ms** ——
    app/Kconfig 覆盖 Zephyr 默认值：BT_PERIPHERAL_PREF_MIN_INT=6、MAX_INT=12
    （Zephyr 自己 24/40），且 **Linux 会接受外设发起的合法参数请求**
    （l2cap_conn_param_update_req → L2CAP_CONN_PARAM_ACCEPTED → hci_le_conn_update）
    ⇒「直连主机一定慢」不成立。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
2026-09-15 docs(adr): 收口 Q2/Q3 —— 修正「方式 2」分析、补 TI 官方依据、补出货产品先例
    ## 1. 更正 ADR-0010 中我对「方式 2」的分析（两处）
    (a) 隐患是【器件选错】造成的，不是拓扑固有的
    我此前写「非有线档节点被上拉到 3.3V，而晶体管发射极在 4.2V ⇒ Veb=0.9V 会误导通」
    —— 那是 **PNP** 的问题。改用 **NMOS**（栅极=该节点，源极=GND，漏极=SYSOFF）后：
    无线档 节点 3.3V ⇒ Vgs=3.3V > Vth ⇒ 导通 ⇒ SYSOFF 拉低 ⇒ 电池接通
    有线档 节点 0V ⇒ Vgs=0 ⇒ 截止 ⇒ 100k 拉高 ⇒ 电池断开
    而且 datasheet 给出 SYSOFF 输入阈值很宽松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
2026-09-15 docs(adr): 收口 Q3 终稿 —— 修正我上一轮写错的例子，并补入 TI 的「自举悖论」文档
    ## 1. 修正我上一轮引入的错误（由后续取证推翻）
    我上一轮把 `zhiayang/mikoto` 的 `CHARGE_CTRL_1/2` 和 `jncronin/gk` 的 `PWRCTRL1..3`
    写成了 SYSOFF 实现。**两者均被推翻**：
    mikoto 文件里唯一的 SYSOFF 字符串在【内嵌库符号】里（无实际网络），
    其 CHARGE_CTRL 落在 ISET(pin16)
    gk 的 PWRCTRL 在 STPMIC25B 上，且 gk 本身把 SYSOFF 接 GND
    已改为把 gk 归入「直接把 SYSOFF 常接 GND」一类，并保留更正说明。
    另：`slicemk-module` 的 `zmk,behavior-sysoff` 是 nRF52 SYSTEMOFF 深睡（命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
2026-09-17 fix(matrix): 保留 KLE 异形键的第二轮廓，修正主键区 Enter 几何
    matrix-assign.mjs 原先只读 KLE 的 w/h，静默丢弃 x2/y2/w2/h2，
    导致主 Enter 被当成 1.5u×2u 的完整矩形。实际它是阶梯键：
    上半 1.5u @x=18，下半 2.25u @x=17.25，左下的空缺属于 Enter 本体。
    - 生成器：解析并输出 stepped/x2_u/y2_u/w2_u/h2_u/unionX_u/unionW_u，
    并在遇到阶梯键时必须在控制台报出，杜绝再次静默丢弃
    - 轴心仍取主矩形中心 18.75u（列分配按此排序，改动会重排整条矩阵）
    - matrix.json：仅 i=52 新增 7 个字段，行/列分配与其余 94 键零变动
    - hardware-geometry.md：新增 §1.4.1 记录异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
2026-09-17 fix(matrix): 对未识别的 KLE 属性强制报错，禁止静默忽略
    上一次事故的根因是解析时静默丢弃了 x2/y2/w2/h2，
    主 Enter 的异形轮廓因此丢失、被下游当成完整矩形。
    现在对 KLE 属性做白名单校验：
    - 几何属性 x/y/w/h/x2/y2/w2/h2 必须被显式处理
    - a（图例对齐）明确标注为不参与计算
    - 其余任何属性一律抛错并打印行号与对象
    - 顶层若出现非数组元素（元数据对象）同样抛错
    已用注入未识别属性的假 KLE 反测：确实抛错（exit=1）。
    真实 KLE 全链重跑，派生产物零变动。
2026-09-17 fix(matrix): 给下游加 matrix.json 字段白名单，杜绝第二跳的静默忽略
    上一笔修的是「上游解析 KLE 时丢弃 x2/y2/w2/h2」。
    但 gen_matrix_sch / gen_matrix_doc 读的是 matrix.json，属于第二跳：
    上游将来再新增字段，下游若照旧视而不见，事故会重演。
    新增 docs/_tools/matrix_schema.py（单一真相源）：
    - 顶层字段白名单 + 键位记录的必需/可选字段白名单
    - 出现白名单外字段直接报错，并提示去哪儿同步白名单
    - 缺少必需字段同样报错
    两个下游脚本在载入 matrix.json 后立即校验。
    验证：注入 zz_unknown 后两个脚本均 exit=1；原样运行全绿，派生产物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
    [gen_matrix_doc.py, gen_matrix_sch.py, matrix_schema.py]
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2026-09-17 feat(power): 电源子图（BQ24072 电源路径 + 拓扑 C 门控），ERC 0 error
    产物 hardware/pcb/StarShield/power/power.kicad_sch：18 元件 —— USB-C 输入+CC 下拉、BQ24072 充电与电源路径、电池座、充电指示、2N7002+AO3401A 门控。ERC 0 error / 2 warning（warning 是待 B2 接线的跨图标签 VLED 与 RGB_PWR_EN）。
    取值依据 TI SLUS810N 正文（本地抽 PDF 核对）：R_ISET=1.78k -> 0.5A；EN2=GND/EN1=OUT -> USB500 档（EN1 不能接 VBUS，该脚绝对最大额定仅 7V）；~CE 与 TD 接 VSS；TMR 悬空；TS 经 10k 到 VSS 禁用温测。定稿表见 docs/power-architecture.md 3.1。
    画法：每引脚一根 2.54mm 短线 + 同名标签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
    [Starshield.kicad_sch, power.kicad_sch]
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2026-09-17 feat(power): 按社区成熟方案落地五处改动（VBUS 保险丝 / R_ILIM 1.5k / 补装 R_TMR / EP 热过孔 / C 倍率换算）
    1) 新增 F1 = 500mA 保险丝装在 VBUS 侧（VBUS->F1->VCHG_IN->U1.IN），照抄 nightliner 的位置。不可照抄 Conejo：它那颗串在电池路径上，而 RGB 全部放电电流都走那条路 => 必然误断。VCHG_IN 含 U1.IN(power_in) 故需 PWR_FLAG。
    2) R_ILIM 1.6k -> 1.5k（osprey/designguide 值）。3) 补装 R_TMR = 47k，TMR 不再悬空 —— 修正本项目原先的错误结论：内部默认只有 5h，而 ICHG 0.5A x 3000mAh 仅 CC 段就约 6.2h，悬空会在充满前被安全定时器掐断；原先用定时器节流变慢论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
    [power.kicad_sch]
2026-09-17 feat(power): 电池改为 2x5000mAh 并联（10000mAh），TMR 改接 VSS 禁用安全定时器
    【容量】按用户决定，电池由 3000mAh 单节改为 2x5000mAh 并联（1S2P，共用一块 PCM）。串联被电气排除：数据手册 8.1 节 BAT 绝对最大额定仅 -0.3…5V，2S 满电 8.4V 超限 68%。
    【对标】新增 research/keyboard-battery-capacity-precedent.md（商用 10000mAh 键盘做法）：AULA F87S 官方承认不是单体 10000mAh 而是 2x5000 并联，理由与我们独立推出的一致（单体太厚），并指出可分置左右两侧平衡配重；Kzzi K98PRO 10000mAh 配 DC5V/1.4A；Hola87 10000mAh 配 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
    【关键发现】消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
    [power.kicad_sch]
2026-09-17 fix(power): 自查修正五类问题（R_ILIM 旧值 / CC 声明表述 / 定时器口径 / 漏掉的放电能力要求 / 采购路径不一致）
    【1 事实错误】power-architecture.md 3 元件表的 R_ILIM 仍写 1.18 kΩ / USB500 档下留 1.6 kΩ —— 这是上一轮改 R_ILIM 为 1.5 kΩ 时漏改的（只改了 3.1 定稿表）。已改正并注明数据手册 10.2 的 1.18 kΩ 属 ILIM 档场景；同表 R_ISET 也由「可选值」改为实际取值。
    【2 技术表述错误】原文说商用键盘「不做 USB-C 的 CC 声明」—— 不成立：用 Type-C 从充电器取电必须做 CC 下拉，否则端口不给电。准确说法是「按超出 5.1 kΩ 所声明的 500 mA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
    [power.kicad_sch]
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2026-09-17 docs(research): 5000mAh+ 键盘充电电流调研 —— 修正此前「建议维持 0.5A」的样本偏差
    【触发】用户要求补充搜索「5000mAh 以上电池的键盘怎么处理充电电流」，品牌官网 / GitHub 都找。
    【修正】上一轮 zmk-ecosystem-charging-precedent.md 5 建议「维持 0.5A」，样本全是 90-500mAh 小电池 ZMK 板（350mA 对它们 = 0.7-1C）=> 不能用来论证 10000mAh 该用多大电流。已在该报告顶部加修正横幅。
    【同容量段实测】AULA L99 8000mAh / 1300mA（0.163C）；Kzzi K98PRO 10000mAh / 1400mA（0.14C）；EPOMAKER TH87 10000mAh / <=1000mA（<=0.10C）；Hola87 10000mAh / 350mA（0.035C）；本项目 10000mAh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
2026-09-17 feat(power): P13 定案 —— 充电档位切到 ILIM 档 1.0A（含连带修正 F1 保险丝）
    【决策】用户 2026-09-18 选定方案 2：EN2=OUT / EN1=GND（ILIM 档）、R_ILIM 1.6kΩ（输入限流 ≈1.0A）、R_ISET 887Ω（ICHG ≈1.0A = 0.10C）、充满约 10h。
    【依据】商用同容量（≥5000mAh）键盘实测充电区间 0.035-0.163C（AULA L99 8000mAh/1300mA、Kzzi 10000mAh/1400mA、EPOMAKER TH87 10000mAh/<=1000mA、Hola87 10000mAh/350mA）；旧值 485mA = 0.049C 落在下三分之一。另有整机拆解实证：商用无线键盘用 TP4056（线性，最大 1A），且即使第 1 脚支持 TEMP 温测，厂商仍用 2 线电池包。
    【连带修正 F1】原 500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
    [power.kicad_sch]
2026-09-17 docs(power): 修正 F1 保险丝的四处残留旧值（500 mA -> 1.5 A）
    改档位时只更新了 3.1 定稿表与 power_design.py 的 F1 条目，另有三处仍写 500 mA：power-architecture.md 的 3 未验证项表（且理由仍写「与 USB500 档配套」）、3.4 社区对照表的本项目列、P15 待决策条目（还写「可能上到 630-750 mA」，那是 0.5 A 场景下的推算）。
    同时补上一条此前缺失的说明：保险丝的 hold 电流与 trip 电流不是同一个数 —— 1.5 A 额定在 1.0 A 下永远不会动作，它的作用是挡输入短路/过流故障，不是限流。P15 的复核项据此改写为更具体的两条（hold 电流在最高环境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
    [power_design.py]
2026-09-18 feat(power): P15 定案 —— F1 改为 2A hold 自恢复保险丝（1812 封装，MF-MSMF200）
    1.5A 档被降额曲线否决：MF-MSMF150 在 60°C 时 Ihold 仅 1.00A，等于工作电流（零余量），
    70°C 时 0.88A 会误断。2A 档 60°C 仍 1.50A（余量 50%）。压降最大 80mV 不影响充电。
    类型改 PTC（新手免换件），封装 0603 → 1812。LCSC 料号留待 BOM。
    [power.kicad_sch]
2026-09-18 docs(geometry): 修正小键盘键位尺寸表 + 外壳分件几何推翻 + 决策包
    1. §1.4 尺寸表错误修正：小键盘只有一颗 Enter（1u×2u），旧表重复计数且误套主键区宽度；
    小键盘 + 为 1u 非 2u。均按 KLE 权威源核实。
    2. §3.1 推翻「主键区一体+小键盘一体」两件式：主键区 15u=285.75mm 超打印床 256mm，
    旋转也救不回 ⇒ 改等分两件，接缝刚度由整块 PCB 桥接。
    3. 新增决策包 decision-package-2026-09-18.md（P12/P15/G2-G6/C4/C6 逐项分析）。
    4. 补 index（1 起）与 keymap 位置号（0 起）的口径注。
2026-09-18 docs(dongle): ZMK+ESB 生态调研、验证计划与 Dongle 旧值清理
    1. GitHub API 全量检索 ZMK+ESB 生态（ADR-0001 修订段 + ADR-0011 附录 B/D/E）：
    badjeff/zmk-feature-split-esb 55★（仅分体）、Keychron 闭源 blob（不可移植）等四条路线盘点。
    2. 发现 efogdev/zmk-esb-endpoint：单体键盘可用的 ESB 输出端点模块（MIT，按 ZMK v0.3.0 测试）。
    用户拍板「先验证再定」（C7）：新增验证计划 esb-endpoint-validation.md，
    物料 = nice!nano v2（键盘端）+ XIAO nRF52840（dongle 端），核心问题 = 52833→52840 移植。
    3. decisions.md / build.yaml 清理「Dongle 用 XIAO + ZMK central」旧值（ADR-0011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
2026-09-18 fix(schematic): 三处地基修复 —— 矩阵跨图标签、充电 LED 位号冲突、网表校验盲区
    1. 矩阵 ROW/COL 由局部标签改为全局标签：KiCad 局部标签不跨 sheet 相连，
    三张矩阵子图的同名 COL 在真实网表里带各自路径前缀、互不相连；
    该缺陷曾被「单图导出+按名合并」的旧校验掩盖。
    2. verify_netlist.py 改为从根图整体导出网表校验（校验真实连通性）；
    列网节点数断言同步为 95 键 + 18 个 595 驱动端 = 113。
    3. 充电 LED 位号 D1 -> D96：与矩阵二极管 D1 冲突（根图整体网表
    元件数 208 != 209 暴露）；D96 = 矩阵 D1..D95 顺延，避开将来 RGB 子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
    [matrix_r012.kicad_sch, matrix_r234.kicad_sch, matrix_r45.kicad_sch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]
2026-09-18 feat(schematic): B2 控制板子图 —— nice!nano 排针 / 595 列驱动 / 三档开关
    新增第 5 张子图 control/control.kicad_sch（9 元件 / 82 条引脚连接）：
    - J3A/J3B：nice!nano v2 排针 = 两条 Conn_01x12（官方库无 Pro_Micro 符号；
    引脚号 1..12 直接对应 Pro Micro 标号 n / 12+n，映射依据 ZMK v0.3
    arduino_pro_micro_pins.dtsi）。RAW(PM13) 接电源子图 OUT，VCC(PM16) 为 3.3V 轨。
    - U2/U3/U4：3 颗 74HC595 级联驱动 COL0..17（位序 bit0..7/8..15/16..17，
    已按 gpio_595.c 源码核实）；~SRCLR 接 VCC、~OE 接 GND；每颗 100nF 去耦。
    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
    [Starshield.kicad_sch, control.kicad_sch]
2026-09-18 docs(firmware): 595 颗数修订 2 -> 3 颗（电气错误），全文档同步
    2 颗 74HC595 只有 16 个物理输出位，ngpios=24 时 gpio_595.c 每轮移 24 个时钟，
    bit16/17 被推出链尾丢失 => COL16/17（小键盘区 5 键）永远无法驱动；
    CI 构建照常通过 —— 「编译通过 != 电气正确」的又一实例。
    - ADR-0008 新增修订小节（位序核实：bit0..7 第 1 颗、8..15 第 2 颗、16..17 第 3 颗）
    - overlay 注释修正（ngpios=24 数值不变，固件无需重验）；README 引脚表同步
    - matrix-assignment / matrix-folding-analysis / zmk-kscan-alternatives 历史结论加修订标注
    - verify_firmware.py 断言文案同步
    [starshield.overlay, verify_firmware.py]
2026-09-18 feat(schematic): M5 RGB 子图 —— 95 颗 SK6812MINI-E 数据链，原理图四张子图齐
    新增第 6 张子图 rgb/rgb.kicad_sch（A2；95 灯珠 / 380 条引脚连接）：
    - 数据源 rgb_design.py 由 docs/_generated/matrix.json 循环生成（位号 LED1..95 ↔ 键 index），
    链序 = 键位 index 顺序（行优先、行内从左到右），与 ZMK 侧 LED index 一致。
    - LED1.DIN ← 全局 LED_DIN（控制子图 J3A.1 = P0.06 / spi3 MOSI）；LED95.DOUT 链尾 NC。
    - 供电：全部 VDD → 全局 VLED（电源子图 Q1 门控的电池直供轨）；VSS → GND。
    - 符号用官方 LED:SK6812MINI-E（派生符号已展平）；封装选 PLCC4 3.5x3.5 正装，
    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
    [Starshield.kicad_sch, control.kicad_sch, rgb.kicad_sch]
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2026-09-18 feat(b3): 新增封装存在性核查 + 排针封装定案
    - 新增 docs/_tools/verify_footprints.py：扫描 4 张子图的 Footprint 属性，
    逐个去 KiCad 封装库查存在性 —— 「封装存不存在」从此是可复现断言，
    不再靠人工看（95 个热插拔座封装缺失就是这样默默存在的）。
    - 实测：218 / 313 个元件的封装在官方库（13 种）。
    - J3A/J3B 定案 Connector_PinSocket_2.54mm:PinSocket_1x12_P2.54mm_Vertical
    （官方库无 Connector_Mill-Max；排母孔径 1.0 vs Mill-Max 推荐 0.94mm 可焊，
    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
    [control.kicad_sch]
2026-09-18 feat(b3): 自画 MX 热插拔座封装（8 档），313/313 元件封装全部就位
    B3 定案：自画（官方库没有热插拔座；社区库 daprice/keyswitches.pretty 的
    Kailh_socket_MX 是 CC BY-SA 4.0、无官方库的「用于设计不受约束」例外，不可引入）。
    - 新增 gen_footprints.py -> hardware/pcb/StarShield/footprints/StarShield.pretty/
    8 档：1.00 / 1.25 / 1.50 / 1.75 / 2.00 / 2.00u_Vertical / 2.25 / 6.25u。
    - 做法：以官方 SW_Cherry_MX_<宽度>u_PCB 为基底（含轴体机械孔与**卫星轴 stabilizer
    孔位** —— 官方库没有独立 stabilizer 封装，这正是它按宽度分档的原因），
    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
    [matrix_r012.kicad_sch, matrix_r234.kicad_sch, matrix_r45.kicad_sch]
2026-09-18 fix(hw): 三档开关位号 SW1 -> SW96（与矩阵第一个开关重名）
    根图整体网表里两个元件的引脚会并到同一个位号下；PCB 上会出现两个 SW1。
    现有校验假通过：verify_netlist 数的是 SW 前缀的不同名字个数，
    95 个矩阵开关 + 1 个 SP3T 因重名去重后仍是 95 个。
    - control_design.py: ref 与 4 条连接改名 SW96（顺延 D96 的编号习惯）
    - verify_control.py: 4 条开关断言改按 SW96
    - verify_netlist.py: 矩阵开关显式只数 SW1..SW95（不再用前缀计数）
    [control.kicad_sch]
2026-09-18 feat(pcb): B4 PCB 布局 + 定位板（生成器 / 校验器）+ 几何修正
    新增：
    - docs/_tools/pcb_design.py 布局单一真相源（板框 / 键位派生 / 控制肩摆放 / 安装孔 / 网络类）
    - docs/_tools/gen_pcb.py 生成 Starshield.kicad_pcb 与 Starshield-plate.kicad_pcb
    - docs/_tools/verify_pcb.py 九组断言（齐套 / 坐标同源 / 越界 / 重叠 / 挂网 / VLED 类 / DRC / 定位板）
    要点：
    - 板框 374.71 x 151.06 mm = 键区 366.71 x 119.06 + 每边 4mm + 顶部 24mm 控制肩
    （键区铺满、背面净空仅约 11mm < 排针 18.78mm，故走「单板顶部加肩」方案）
    - 坐标全部由 matrix.json 派生；封装原点 = 轴心 + (2.54, -5.08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
    [Starshield-plate.kicad_pcb, Starshield.kicad_pcb]
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2026-09-18 fix(pcb): 工程网络类补齐 VLED（2.0mm），纠正 VLED 被并入 Power 类
    Starshield.kicad_pro 的 netclass_patterns 此前把 VLED 映射到 Power 类
    （track_width 0.5mm），而板子里 VLED 是 2.0mm —— 两边不一致，
    KiCad GUI 里做 DRC/布线时会按 0.5mm 走，2-3A 的护栏静默失效。
    - 新增 VLED 网络类：track 2.0 / clearance 0.25 / via 1.2-0.6
    - netclass_patterns 的 VLED 从 Power 改指 VLED
    用 MCP 的 create_netclass 写入 + 手工改 pattern；已用 export_dsn 复核：
    DSN 里 VLED 类 width=2000 clearance=250。verify_pcb.py 全绿，无回归。
2026-09-18 feat(pcb): USB-C 移左上角 / 三档开关移右上角；改为 4 层板
    用户 2026-09-19 定的两处摆位：
    - J1 (USB-C) 210,5.5 -> 15,5.5（左上角）；**R1/R2（CC 下拉）与 F1 随连接器左移**
    —— CC 走线必须短，否则是 USB-C 坏实践。代价：VBUS 从 F1 到 U1 变成约 230mm 长线
    （0.8mm 宽、1A，电气无碍）。
    - SW96（三档模式开关）75,12 -> 360,6（右上角）。代价：MODE0/1/2 三条线从约 35mm
    变成约 320mm（μA 级信号，无碍）。
    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
    [Starshield-plate.kicad_pcb, Starshield.kicad_pcb]
2026-09-18 fix(pcb): 三档开关按使用体验微调至 (350,11)（原 360,6 太贴角）
    用户反馈「太偏了，考虑实际使用体验」⇒ 往左下各挪 10mm / 5mm。
    新位置外廓 x 344.1..355.9、y 8.55..14.4：离板右缘 18.8mm、离顶肩下沿 9.6mm、
    与 J2 水平间隙 8.0mm，四周均有余量。
    同时把封装姿态的实测结论写进 pcb_design.py 注释（读 KiCad 官方 SW_SP3T_PCM13）：
    本体 9.7 x 2.55mm 沿 X 长；四个信号脚在 -Y 侧（y=-1.43）；
    **操作柄在 +Y 侧伸出**（F.CrtYd 到 y=3.4）⇒ rot=0 时柄指向键区方向；
    若希望柄朝键盘后壁，把 rot 改成 180 即可（一行）。
    八项校验器全绿；DRC 无新增违规。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
    [Starshield.kicad_pcb]
2026-09-18 feat(pcb): 三档开关按侧壁开口定型（rot=180, y=2.5）并锁定档位物理顺序
    用户 2026-09-19 定：「外壳开口开在侧面（和 USB-C 同一面），滑块式，
    从左往右依次是 2.4G / 蓝牙 / 有线」。
    - **rot 0 -> 180**：柄朝后壁（-Y）。侧壁开口要求柄能穿过外壳侧壁
    - **y 11 -> 2.5**：柄尖板坐标 y = y0-3.4 = -0.9 ⇒ **探出板边 0.9mm**，才能伸进侧壁开孔。
    ⚠️ 这与先前「往左下挪」的「下」冲突（侧壁开口物理上要求靠边），按硬约束取舍；
    X 保留用户左移后的 350
    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
    [Starshield.kicad_pcb]
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2026-09-18 feat(pcb): B4 布线（4 层，信号走外层 + 内层平面/铺铜）—— 99.3% 布通，剩 6 条待收
    用 Freerouting 2.4.1（Java 25）自动布线，产物 = 3696 段走线 + 296 个过孔 +
    3 个已填充铺铜区（In1.Cu=GND 平面、In2.Cu=VLED 平面、B.Cu=GND）。
    关键做法与实测：
    - **内层声明为 power 层**（DSN 里 In1.Cu/In2.Cu 的 type 由 signal 改 power）
    ⇒ Freerouting 只用 F.Cu/B.Cu 走信号，内层腾空给平面。
    不加这一步时 4 层跑法反而更差（73 未布且被提前中断）。
    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
    [Starshield.kicad_pcb]
2026-09-18 feat(pcb): 给 VLED 补 43 个过孔，In2 平面成为真正的 2.4A 配电层；未连通 6 -> 5
    问题：布线后 VLED 只有 2 个过孔（都在板子右侧），2.4A 仍主要靠布线器留下的
    0.25mm 细走线承载 —— ADR-0007 的载流要求没落地。
    做法：新增 add_vled_vias.py ——
    候选点取现有 VLED F.Cu 走线的中点（保证落在自己的铜上），按 22mm 抽稀，
    再对其它网络的焊盘/走线/过孔与 NPTH 做间距预筛，通过的写成
    (via size 0.6 drill 0.3 layers F.Cu-B.Cu net VLED)。
    放入 55 个后 DRC 报出 23 处冲突（预筛漏了 B.Cu 上的热插拔座焊盘：
    自画封装同一引脚号有 PTH + B.Cu SMD 两个焊盘，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
    [Starshield.kicad_pcb]
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2026-09-18 feat(pcb): B4 收尾 —— 未连通 5 -> 0，布线清零
    - COL0: D53.1 孤立焊盘经 F.Cu 绕行至 (3.6867,105) 新过孔，搭上 COL0 的 B.Cu 竖线
    - Net-(D36-A) / Net-(D69-A): D36.2 / D69.2 孤立，照抄相邻键 D53 已验证的
    F.Cu 短接线形状（整体平移一个行距 19.05 mm）
    - VBUS: J1 左右两组焊盘互连并接 F1.1（F.Cu 绕 J1 定位孔 + B.Cu 干线 + 3 过孔）
    - 删除 (3.6867,62.8397) 处重合过孔之一，holes_co_located 清零
    - 新增 docs/_tools/refill_zones.py：pcbnew 直连重填铺铜，绕开 MCP 的
    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
    [Starshield.kicad_pcb]
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2026-09-19 docs(b6): 实物到货量测结论 —— 排针实为 2x13，发现 J3A/J3B 孔数设计错误
    - nice!nano v2 实物量测：板 34.0 x 18.0 x 3.3(总高)、pin1 -> USB 口面 5.3、
    口宽 7.1 居中 —— 与预判一致；每排 13 孔，官方 pinout 图确认 2x13 = 26 孔
    （比 Pro Micro 每排多 1 孔、多在 USB 端：左排 GND、右排 B+）。
    - 现设计 J3A/J3B = Conn_01x12 错误：左排整排错位一孔（LED_DIN 会落在 GND 上），
    右排 VCC 会插到 RESET 上。新增投板阻塞任务 B6-1：改 1x13 并按官方孔序重排；
    固件 overlay 不受影响（D 编号映射不变）。
    - 修正后的逐孔映射表 + 修复方案 + 仍待补量测清单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
2026-09-19 fix(b6-1): J3A/J3B 由 1x12 改 1x13（按 nice!nano v2 实物孔序），走线零改动
    背景：2026-09-19 实物核对发现 nice!nano v2 每排 13 孔（官方 pinout 图 + 实物清点），
    原 1x12 设计会把 J3B 的 VCC 插到实物 RESET 上、J3A 整排错位一孔。
    关键洞察：官方孔序去掉第 1 孔后与旧 12 孔的网**逐孔一致** ⇒
    只需在 USB 端左侧（x=37.46）加一个孔（J3A 加 GND、J3B 加 OUT）+ Pad 号整体后移一位，
    **走线一根都不用动**。（反面做法「网络整体后移一孔」实测撞出 8 处 shorting_items +
    2 处 tracks_crossing，已否决。）
    改动：
    - extract_power_symbols.py：符号缓存加 Connector_Gene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
    [Starshield.kicad_pcb, control.kicad_sch, rgb.kicad_sch]
2026-09-19 docs(b6): 插头实测 d1=7/d2=28/w=13x7 —— 修正侧壁开孔判据（握持部必须穿过开口，需约 14x8 孔）
    早先按 d2<=30 判为「线径级开孔」是错的：漏了插入过程中握持部必须穿过开口这一步。正确判据只看 w（13x7）。已给出 A/B 两条路线（维持布局开大孔 / 下代板插座转 90 度）与待 CAD 复核项。
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2026-09-19 docs(b6): 补§6.6 —— 有线模式充电问题：商业一律一口即充（Kisnt/雷柏/CHERRY 官方口径），社区把电池挂模块充电器；我们的偏差是电池接在自研充电器 BAT、模块挂在 OUT；给出最小修法（B+/RAW 改接 VBAT）
    并复核官方 pinout 右列孔序与 B6-1 后的 J3B 映射逐孔一致（B+/RAW/GND/RST/VCC/D21..D10）。
2026-09-19 feat(power): 方案①落地 —— 模块 B+/RAW 由 OUT 改接 VBAT（插模块口即充电）；模块整组左移 + J1 让位
    背景（用户质疑成立）：商业键盘一律「一个口 = 数据 + 充电」（Kisnt KN85 / 雷柏 V700-8A /
    CHERRY KW 9200 官方口径）；社区 nice!nano 方案把电池挂在模块自带充电器输出上，插模块口即充电。
    我们原先把电池接自研 BQ24072 的 BAT、模块挂 OUT ⇒ 模块充电器的电流进不了电池
    （OUT→BAT 不是充电路径）⇒ 有线模式下充不上电。
    - 电路：J3B 孔1/孔2（B+/RAW）网络 OUT -> VBAT；VBAT 由电源子图局部网升为跨子图全局网
    （power_design.py 与 c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
    [Starshield.kicad_pcb, control.kicad_sch, power.kicad_sch]
2026-09-19 refactor(pcb): 左侧接口簇定稿 —— 模块下移 5.78mm 让出左上角；充电口回左上角(x=15)、开关紧邻(x=33)、模块口留左壁(y=17.8)
    用户定稿排布：模块口在左侧壁、充电口在左上角、开关放充电口旁边。空间核算见 docs/nice-nano-physical-verification.md §6.7：左侧壁键区前仅 ~30mm 可用，三者需挤在 y 0-8 ⇒ 模块下移至两排 y=10.16/25.40（距键区仍有 3.8mm）。板框仍 374.71x151.06，未加高额头。pcb_design.py 已同步；板/定位板由 g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
    [Starshield.kicad_pcb]
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2026-09-19 fix(power): 瓶颈分析 —— 层叠改回 0.5 oz，并修两处铺铜缺陷
    ## 依据：「加了铺铜」≠「够用」——沿电流方向逐截面量铜高
    方法：沿电流方向每 2 mm 取一个 x 截面，在截面上以 0.05 mm 步长采样、统计**该网络自己**
    的铜（铺铜填充 + 走线 + 焊盘）在 y 向覆盖的总高度，取路径上的最小值：
    | 路径 | 内层最窄铜高 | 0.5 oz @ΔT20 | 1 oz @ΔT20 | 需求 |
    | --- | --- | --- | --- | --- |
    | VBAT（J2 → 充电 IC） | 3.10 mm | 2.22 A | 3.66 A | 护栏 1.0 A / 峰值 2.4 A |
    | VCHG_IN（F1 → 充电 IC） | 1.95 mm | 1.59 A | 2.62 A | 0.97 A |
    ⇒ **0.5 oz 内层已满足**（VBAT 覆盖护栏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
    [Starshield.kicad_pcb]
2026-09-19 feat(fab): 投板前 DFM 核对（可重跑脚本 + 核对文档）
    DRC 查的是「我们的设计规则」，DFM 查的是「厂家能不能做」——两回事。本板
    min_track_width 0.127 / clearance 0.2 都是我们自己设的；厂家另有自己的下限与建议。
    ## 新增
    - `docs/_tools/dfm_check.py`：量本板极限值并与厂家公开工艺能力逐项对照，
    退出码非 0 表示有「不通过」项。工作目录须在 D:/Kicad/bin（需 pcbnew）。
    - `docs/fab-dfm-check.md`：判据来源 / 核对表 / 下单规格 / 答复话术 / 诚实边界。
    ## 结论：无「不通过」项，可投板
    | 项目 | 本板 | 嘉立创限值（4 层） | 判定 |
    | 最小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
    [dfm_check.py]
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2026-09-20 fix(case): 修正 Fusion 脚本的存放位置与运行前提（实用程序只在设计内出现；脚本须放 API/Scripts）
    [deploy_fusion_addin.py]
2026-09-20 fix(case): 电池压边按 profileLoops 过滤（避免把环内区域填实）+ 新增两道体积自检
2026-09-20 fix(case): 压边改用两个同心矩形（环带才是带孔轮廓）；4 个重叠矩形拼环会被切成单环区域导致过滤失效
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2026-09-20 fix(case): 修正板→模型坐标（y 必须取反，否则整件镜像）+ 新增方向自检/字符俯视图/俯视截图
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
